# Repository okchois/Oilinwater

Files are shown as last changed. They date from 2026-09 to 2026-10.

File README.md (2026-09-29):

# Oilinwater — 오일 내 수분 트랜스미터

오일(유압유·윤활유·절연유·연료) 속 수분을 온라인으로 측정하는 트랜스미터 개발 프로젝트.

**프로젝트: HMT500(260313)** — 회로·PCB·거버 파일명과 PCB 마킹은 **HMT500(260313A)** (결정 #25).

- [결정 기록](docs/decision-log.md) — 확정 사항과 미결 사항 (MCU, DAC 대체 계획 등)
- [조사 보고서](docs/research-report.md) — 측정 원리, 경쟁 제품, 센서 소자, 회로/기구/펌웨어 설계, 교정, 인증, 로드맵
- [시장 조사 종합](docs/market/00-summary.md) — 세계 시장, 경쟁 제품·가격, 국내 시장, 포지셔닝 제안
- [E+E EE364 원문 요약](docs/reference/ee364-summary.md) — 구조 참고 제품의 치수, 사양, 핀맵, Modbus 맵
- [IST MK33 스터디](docs/reference/ist-mk33-study.md) — 데이터시트·응용노트·백서: 이슬점 95 °C 한계, 온도 보정식, DC 없는 교류 구동, 취급·교정 지침
- [HMT500(260313) 기구 설계 Rev F](hardware/mech/README.md) — 제작 도면 PDF(조립도·부품도 4장), 3D STEP, 렌더 (두텍 SUS 오일 필터 캡 390000-001100 + HTX99R 센서 커넥터 + 교체형 센서 프로브, 피드스루 없이 Ø7 관통 + JST SH 하네스, 나사 M28×1 + O링, PCB 1장)
- [HMT500 기구설계 견적 요청서 (PDF)](docs/mech/HMT500_RFQ.pdf) · [도면 HMT500-M-000](docs/mech/HMT500-M-000.pdf)
- [기구 설계안](docs/mech/mechanical-design.md) — EE364형 일체형 구조도, 압력 격벽, 밀봉, 열, 원가
- [KiCad 회로도 HMT500(260313A)](hardware/kicad/README.md) — 계층 시트 6장, 심볼 라이브러리, BOM, PDF
- [회로도 검토 HMT500(260313A)](docs/hw/schematic-review-260313A.md) — 심볼·데이터시트 대조, 최적화 계획 (승인 대기)
- [회로 설계서 (서지·오결선 보호)](docs/hw/circuit-design.md) — 전원 eFuse, 출력 보호, RS-485 ±70 V, 접지, MCU 핀 할당
- [하드웨어 블록 설계](docs/hw/hardware-block-design.md) — 회로 블록도, 부품 선정, 아날로그 2ch + RS-485
- [MCU 선정 검토](docs/hw/mcu-selection.md) — STM32L431 재검토, 후보 비교, 교차 검토 질문지
- [사내 사용 부품 적용 검토](docs/hw/inhouse-parts.md) — MCU·DAC 구매 이력, DAC8760 → DAC7562 + 출력단 비교
- [습도 센서 선정](docs/hw/humidity-sensor-selection.md) — IST MK33-W mini 선정, P14·HYT 계열 비교
- [온도 센서 선정](docs/hw/temperature-sensor-selection.md) — IST MiniSens Pt1000 F0.1 선정, 2선식 검토
- [RS-485 + 부트로더 설계](docs/rs485-bootloader-design.md) — 기본 출력 RS-485 Modbus RTU, 통신으로 펌웨어 업데이트
- [`firmware/`](firmware/) — MCU 비의존 부트로더 코어 + PC 시뮬레이터
- [`tools/fwupdate.py`](tools/fwupdate.py) — 펌웨어 이미지 생성 및 RS-485 업데이트 도구
- [`tools/moisture_calc.py`](tools/moisture_calc.py) — 수분 활동도(aw) ↔ ppm 환산 참조 구현

```bash
python3 tools/moisture_calc.py --temp 20 --aw 0.5     # aw -> ppm
python3 tools/moisture_calc.py --temp 60 --ppm 20     # ppm -> aw
```

```bash
make -C firmware                               # 부트로더 시뮬레이터 빌드
python3 -m unittest discover -s tests          # 통합 테스트
python3 tools/fwupdate.py mkimage app.bin app.oiw --hw-id 1 --version 1.0.0
python3 tools/fwupdate.py flash app.oiw --port /dev/ttyUSB0 --addr 1   # pyserial 필요
```

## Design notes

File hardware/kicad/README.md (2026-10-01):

# HMT500(260313A) KiCad 회로도 v0.8

DOTECH HMT500(260313) 오일 수분 트랜스미터의 KiCad 회로도입니다.

**파일명·프로젝트 번호 = HMT500(260313A)** (결정 #25): 회로도·심볼·BOM·부품리스트·PDF, PCB 파일, 거버(`HMT500(260313A)-F_Cu.gtl` 등, 묶음 `HMT500(260313A).zip`), PCB 실크 마킹(아랫면 가운데) 모두 같은 이름을 씁니다. 거버 출력: `sh hardware/kicad/export_gerbers.sh`.

**v0.8 (결정 #26):** 모든 IC 핀을 제조사 데이터시트 원문으로 대조하고 반영했습니다 — [검토 문서](../../docs/hw/schematic-review-260313A.md).

설계 내용은 [회로 설계서](../../docs/hw/circuit-design.md)를 따릅니다.

| 파일 | 내용 |
|---|---|
| `HMT500(260313A)/HMT500(260313A).kicad_pro` | 프로젝트 (KiCad 7 형식 — KiCad 8/9에서 열면 자동 변환) |
| `HMT500(260313A)/HMT500(260313A).kicad_sch` | 최상위 시트 (하위 시트 6장) |
| `HMT500(260313A)/HMT500(260313A)_connector.kicad_sch` | 커넥터, 입력 서지 보호(TVS 2단, CM 초크), 하우징 접지(1 MΩ, 4.7 nF, GDT) |
| `HMT500(260313A)/HMT500(260313A)_power.kicad_sch` | eFuse TPS2660 (RTN은 GND와 분리, OVP 32.6 V / 복귀 30.1 V → 전원 12–28 V, v0.9), 벅 LMR36006BRNXR(5 V, L 15 µH·CFF 20 pF), LDO TPS7A2033(3.3 V) (v0.8) |
| `HMT500(260313A)/HMT500(260313A)_mcu.kicad_sch` | STM32G0B1CCT3 (LQFP48, −40~125 °C), SWD(TC2030), 리셋, 내부 온도센서. SPI1 = ADS1220, SPI2 = DAC(모드 3), SPI3 = PCAP04 (v0.8) |
| `HMT500(260313A)/HMT500(260313A)_measurement.kicad_sch` | J3 센서 하네스 커넥터(JST SH 1.0 4핀), PCAP04(QFN24 실제 핀, DC 없는 플로팅 모드) + 기준 C, ADS1220(Pt1000 2선) |
| `HMT500(260313A)/HMT500(260313A)_analog_out.kicad_sch` | DAC8760 ×2 (SCLK 게이트 U14, AVDD 10 Ω, ALARM wired-OR) + OPA197 +VSENSE 버퍼 + 외부 ISET-R + TPS26611DDFR 오결선 보호 + TVS3301 (v0.8) |
| `HMT500(260313A)/HMT500(260313A)_rs485.kicad_sch` | THVD2410 (±70 V), DE 10 k 풀다운 (v0.9) |
| `HMT500(260313A)/HMT500(260313A)_aux.kicad_sch` | v0.9 보조: TPS26611 +Vs 27 V 클램프, VIN 전압 감시, PCB에 넣지 못한 선택 사항 메모 |
| `HMT500(260313A)/HMT500(260313A).kicad_sym`, `sym-lib-table` | 프로젝트 심볼 라이브러리 |
| `HMT500(260313A)/HMT500(260313A)_BOM.csv` | 부품표 (값·풋프린트별 묶음) |
| `HMT500(260313A)/HMT500(260313A)_schematic.pdf` | 회로도 PDF (7쪽) |
| `HMT500(260313A)/HMT500(260313A)_parts_list.xlsx`, `.csv` | **구매용 부품리스트**: 회로도 부품 + 제조사·품번·1k 추정 단가·상태, 분류별 요약(환율 입력 시 원화 자동 계산). `make_parts_list.py`로 생성 |
| `HMT500(260313A)/HMT500(260313A).kicad_pcb` | 보드 외곽(57 × 23, 4층), 고정 구멍 2개, 금지 구역(홀더 홈·지지링 홈), **회로도 v0.9 부품 110개 배치·넷 지정 완료 (배선 전, 승인 대기)**. 설계 규칙: 간격·선폭 0.15, 비아 0.45/0.2, 가장자리 0.3, 넷클래스 CHASSIS 간격 1.0·선폭 0.5, J5 둘레 3.3 mm 부품 금지 |
| `HMT500(260313A)/placement.png`, `placement.json` | 배치 그림(윗면/아랫면, 색 = 기능 블록, 숫자 = 부품 높이)과 배치 표(기구 좌표) — 조립 시뮬레이션 입력 |
| `gen_pcb_outline.py` | 외곽·금지 구역 생성기. 치수는 `hardware/mech/hmt500_params.py`에서 읽습니다 |
| `place_pcb.py` | 부품 배치 (pcbnew). 고정 부품 + 큰 부품 자리표 + 작은 부품은 부모 패드 옆 빈 자리 탐색. 보드·금지 구역·하네스 플러그 통로·높이(보어) 조건 검사. `python3 place_pcb.py` |
| `plot_placement.py` | 배치 그림 (matplotlib) |
| `gen_footprints.py`, `lib/HMT500_260313A.pretty` | 프로젝트 풋프린트 (KiCad 7.0.11 복사본 + 자체 3종) |

## 도면 스타일 (v0.2)

- **흐름:** 신호는 왼쪽(입력) → 오른쪽(출력)으로 그리고, 전원은 위쪽 전원 심볼, GND는 아래쪽 GND 심볼로 표시합니다.
- **연결:** 시트 안은 실제 배선이고, 3선 이상 만나는 곳에는 접합점을 찍었습니다. 시트 사이 신호(SPI, 고장 신호, 커넥터 신호 등)만 전역 라벨로 잇습니다.
- **전원 심볼:** GND, +3V3, +3V3A(아날로그 3.3 V), +5V, VIN_P(보호된 입력), CHASSIS
- **구획:** 기능 블록마다 점선 구획, 제목, 설계 메모(설정 공식, 확인 항목)를 넣었습니다.
- **용지:** 커넥터·RS-485 시트는 A4, 나머지는 A3입니다.

## 생성과 검증

회로도는 `gen_hmt500.py`가 생성합니다. 각 부품에 설계 의도 넷(`nets=`)을 적고 배선은 좌표로 그립니다.
- **생성 단계 검사:** 선 중간에 걸친 핀, 연결 안 된 핀, 용지 밖, 표제란 침범이 있으면 생성이 멈춥니다.
- **연결 검사:** `check_netlist.py`가 KiCad 넷리스트와 설계 의도를 핀 단위로 대조합니다. 현재 74넷, 오류 0입니다.
- **자동 테스트:** `tests/test_kicad_gen.py`에 포함되어 있고, kicad-cli가 있으면 넷리스트 대조까지 수행합니다.

```bash
python3 hardware/kicad/gen_hmt500.py                     # 회로도·라이브러리·BOM 생성
kicad-cli sch export netlist -o hmt500.net hardware/kicad/HMT500(260313A)/HMT500(260313A).kicad_sch
python3 hardware/kicad/check_netlist.py hmt500.net       # 넷리스트 = 설계 의도 검사 (현재 74넷, 오류 0)
kicad-cli sch export pdf -o hardware/kicad/HMT500(260313A)/HMT500(260313A)_schematic.pdf hardware/kicad/HMT500(260313A)/HMT500(260313A).kicad_sch
```

KiCad 8 이상에서는 `kicad-cli sch erc`로 ERC도 실행할 수 있습니다(KiCad 7 CLI에는 ERC가 없음).

## 현재 상태와 주의 사항

- **편집 원본:** 스크립트로 다시 생성하면 KiCad에서 손으로 고친 내용이 덮어써집니다. **KiCad에서 편집을 시작하면 그 뒤로는 KiCad 파일을 원본으로 삼으십시오.**
- **핀 번호 확인 필요 (VERIFY=YES):** TPS2660, LMR36006, PCAP04, DAC8760, TPS26611.
  - 이 환경에서 제조사 데이터시트 사이트가 막혀 있어 **핀 번호를 가번호로** 넣었습니다. 핀 이름과 연결(넷)은 설계서대로입니다.
  - 데이터시트를 보고 심볼 핀 번호만 고치면 됩니다.
  - 확인한 부품: STM32G0B1CCT3(LQFP48, KiCad 공식 심볼 STM32G0B1C_B-C-E_Tx 기준), ADS1220(TSSOP-16), THVD2450(SOIC-8), TPS7A2033(SOT-23-5). 이 넷도 데이터시트로 한 번 더 대조하십시오.
- **풋프린트 TBD:** 공통모드 초크, GDT, 벅 인덕터, 가번호 IC 5종. (J3 `Connector_JST:JST_SH_SM04B-SRSS-TB_1x04-1MP_P1.00mm_Horizontal`, J1 `Connector_JST:JST_GH_SM08B-GHS-TB_1x08-1MP_P1.25mm_Horizontal`은 KiCad 표준. J5 샤시 스프링 접점 TBD)
- **확인할 회로 사항:**
  - DAC8760 VOUT/IOUT 결합과 DVDD-EN 극성
  - TPS26611 전압 모드 통과 여부
  - TPS2660 분압 기준전압(1.2 V 가정: UVLO 약 9 V, OVP 약 33 V)과 ILIM 저항값
  - LMR36006 FB 기준전압(1.0 V 가정 → 5.0 V)
  - PCAP04 플로팅 측정 결선(PC0–PC1 기준 C, PC2–PC3 센서)

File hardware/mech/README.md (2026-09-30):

# HMT500(260313) 기구 설계 (Rev H)

**Rev H (2026-09-30, 결정 #30) — 외형을 E+E EE364와 부위별로 같게:** 노출 프로브 Ø12 × **34** (보호캡 끝 쪽 5.5 연장, 옆 구멍 1줄 추가 → 25개), G½ 14, 육각 AF27 × **10**, 몸통 **Ø30**, 씰면 ~ 엔드캡 끝 **77**, M12 15, 전장 **140**.
- 하우징 Ø30/Ø25, 결합 나사 **M26×1** (앞 오른나사, 뒤 왼나사), O링 자리 Ø27, O링 **24 × 1.5** FKM. 엔드캡 플랜지 4 mm, 맞변 AF27 (바디 육각과 같은 스패너), M16×1.5 커넥터 나사는 x 71–77.
- 안쪽(홀더·PCB·링·하네스)은 모양 그대로 x −2. PCB 폭·길이·부품 배치 변경 없음 (KiCad 좌표 동일). 가장 좁은 곳(하우징 나사 골 Ø24.9)에서도 부품 높이 여유 ≥ 0.5.
- 지지링 바깥 Ø24.5 (홈 바깥 벽 0.65). **M12 커넥터 선정 조건: 앞 나사부 ≤ 6 mm** (PCB 뒤 끝과 틈 2).
- 조립 시뮬레이션 23항목 NG 0. 조립 시방서 `out/assembly_procedure/HMT500-A-001_assembly_procedure.pdf` (`python assembly_procedure.py`, 19단계 3D 그림).
- 금속 가공품 합계 약 242 g (바디 96, 캡 16, 하우징 98, 엔드캡 33).

**Rev G 보호캡 보호 (2026-09-30, 결정 #29):** 바디 앞 Ø14 튜브를 없애고, 앞부분 전체(커넥터·캡·프로브)를 뒤로 19.5 mm 옮겼습니다. 보호캡 뿌리 **3.5 mm가 G½ 앞면의 Ø12.3 자리 안**에 들어가, 캡이 상하좌우로 젖혀지면서 HTX99R 플라스틱 커넥터가 깨지는 것을 막습니다(틈 0.15, 벽 ≥ 3 mm). 전장 158 → **138.5 mm**, 노출 프로브 48 → **28.5 mm**, Ø7 통로 14.5 mm, W-1 40 mm. 아래 Rev F의 48 / 158 mm는 이전 값입니다.

**Rev G (2026-09-30, 결정 #27) — 조립 시뮬레이션 반영:** 홀더(M-105)에 W-1 플러그 창 5.6 × 3.2와 링 단자 자리 Ø5.2 × 2.2를 냈습니다. PCB 폭 23 구간은 x 63.4에서 끝납니다. 샤시는 J5 스프링 접점 대신 **샤시 선 ⑳**(AWG 28 25 mm + M2 링 단자 → 홀더 위 축 나사 → 바디)으로 연결합니다. W-2는 40 mm로 줄였고, 조립 공구 **T-001 밀대**(`out/HMT500-T-001_push_tool.step`, 3D 프린트)를 추가했습니다. 조립 순서는 조립도 주기 5이며, 검증은 `python assembly_sim.py`로 합니다(`out/assembly_sim/`, 23항목 NG 0).

**내부 몰딩·턴버클 (2026-09-29, 결정 #20):**
- 하우징 안 **전체**(바디 Ø22 + 하우징 Ø27 + 엔드캡 Ø22, 약 25 cm³)를 **상온경화 에폭시 1종**으로 몰딩합니다. Ø7 통로 1차 몰딩과 같은 재료입니다.
  - 엔드캡에 M3 구멍 2개(90°·270°)를 두어 한쪽으로 진공 주입하고, 다른 쪽으로 공기를 뺍니다. 경화 후 M3×3 무두나사와 실런트로 막습니다.
  - 몰딩 후에는 전자부를 고칠 수 없습니다. SWD 기록, 기능 검사, 1차 교정은 몰딩 전에 하고, 최종 교정은 몰딩 경화 뒤에 합니다.
- 엔드캡 나사를 **M28×1 왼나사**로 바꿔 **턴버클**로 체결합니다. 바디(AF27)와 엔드캡(AF28)을 잡고 하우징만 돌리면 양쪽이 동시에 당겨지므로, PCB·M12·하네스가 돌지 않습니다.
- J3를 홀더 뒤 12.5 mm(x 30.5–34.5)로 옮겨 플러그를 꽂을 공간을 만들었습니다. PCAP04와 ADS1220도 옮겼습니다.
- 조립 순서는 조립도 주기 5에 있습니다.

**Rev F (2026-09-29, 결정 #17):** 앞쪽 보호캡을 두텍 필터로 바꾸고 피드스루를 없앴습니다.
- **필터 캡 ②:** 두텍 기존품 **SUS PROBE 오일 필터 390000-001100** (`ref/SUS_PROBE_Oil_Filter_20200608.dwg`, SUS304)입니다.
  - Ø12 × 32, 끝 C1, 열린 끝 Ø11 × 1입니다.
  - **M10×1.0 암나사(깊이 8.5)** 로 HTX99R 커넥터 위 나사에 체결합니다. 열린 끝이 커넥터 플랜지 앞면을 눌러 줍니다.
  - 센서실 Ø8입니다. 측면 Ø3 구멍 20개(끝에서 6·11·16·21 mm, 줄마다 5개 72°)와 끝단 Ø3 구멍이 있습니다.
  - 센서 프로브 플러그는 Ø8.5 → **Ø7.6**으로 줄였습니다.
  - 노출 프로브는 34 → **48 mm**, 전장은 144 → **158 mm**입니다.
- **피드스루 삭제:** 커넥터 뒤부터 PCB까지는 **Ø7 관통 통로**이고 센서 하네스 W-1만 지나갑니다.
  - 통로는 pass-through(케이블만)이고, 케이블을 넣은 뒤 **전 길이(Ø7 × 34)를 에폭시로 몰딩(⑤, 1차 격벽)** 합니다.
  - 압력 격벽은 **HTX99R O링 + 몰드 핀 + 에폭시 몰딩**입니다. HTX99R 내압·누설과 에폭시 재료 확인이 필요합니다(미결).
- **센서 하네스 W-1 (결정 #16):** HTX99R 뒤 핀 4개 → **JST SH 1.0 mm 4핀 플러그 → PCB J3 (SM04B-SRSS-TB, 옆 삽입·직각, 입구 앞쪽)**. PTFE AWG30, 60 mm입니다.
  - J3는 PCB 윗면, 앞 끝에서 8 mm 뒤(x 22.5–26.5)에 있는 **옆 삽입(직각) 헤더**입니다. 입구가 앞쪽(센서 쪽)이라 홀더 구멍에서 나온 전선이 굽힘 없이 곧게 플러그로 들어갑니다. 높이 2.95이고, PCAP04는 J3 바로 뒤입니다.
  - 조립 순서는 다음과 같습니다.
    1. W-1 전선을 커넥터 뒤 핀에 납땜하고 O링을 끼웁니다.
    2. 플러그를 바디 앞에서 Ø7 통로로 넣어 뒤로 뺍니다.
    3. 커넥터를 체결합니다. 플러그가 자유로워 하네스가 같이 돌므로 꼬이지 않습니다.
    4. 프로브를 아래로 세우고 뒤에서 에폭시를 주입해 Ø7 통로를 채우고 경화합니다.
    5. 플러그를 홀더 Ø6 구멍에 통과시키고 홀더를 체결합니다.
    6. PCB를 장착하고 플러그를 J3에 꽂습니다.
  - JST SH의 정격은 −25 ~ +85 °C이므로 PCB 앞 끝 온도를 시험으로 확인해야 합니다(미결).
- **M12 하네스 W-2 (결정 #18):** M12 8핀 커넥터도 **JST GH 1.25 mm 8핀 옆 삽입(직각) 헤더 J1 (SM08B-GHS-TB)** 에 하네스로 연결합니다.
  - J1은 PCB 윗면, 뒤 끝에서 12.5 mm 앞(x 52.5–58.5)에 있고 입구가 뒤쪽(커넥터 쪽)입니다.
  - 플러그 GHR-08V-S, PTFE AWG28 60 mm, 핀 n = M12 핀 n입니다.
  - 조립: 엔드캡을 빈 상태로 체결 → W-2(M12 핀에 미리 납땜) 플러그를 엔드캡 M16 구멍으로 넣어 축 방향으로 J1에 꽂음 → M12 체결. 체결 회전(약 4바퀴)만큼 미리 반대로 꼬아 둡니다(미결: 회전 없는 고정형 검토).
  - M12 쉘로 잇던 샤시는 **J5 스프링 접점**(PCB 가장자리 → 하우징 내면)으로 바꿨습니다.
  - 출력부 배치: DAC#1은 뒤 끝(x 67.5)으로, 입력 TVS는 MCU 옆(x 48.5)으로, TPS26611은 아랫면으로 옮겼습니다.
- **나사 규격 (Rev G 확정):** HTX99R 위·아래 나사는 모두 **M10×1.0**입니다(두텍 확인). 바디 암나사는 M10×1.0-6H, 필터 캡은 M10×1.0입니다.

아래 Rev E 이전 설명 중 피드스루, 보호캡 M-102(자체 가공품), 22 mm 하네스에 관한 내용은 Rev F에서 바뀌었습니다.

DOTECH HMT500 오일 수분 트랜스미터의 3D CAD와 2D 제작 도면입니다. 모든 치수는 `hmt500_params.py` 한 곳에서 관리하고, 여기서 3D 모델과 도면을 함께 생성합니다.

**Rev E (2026-09-29):** 두텍 확인 결과, HTX99R 커넥터의 Ø10 두 곳은 **M10×0.75 나사**입니다(아래는 하우징 체결, 위는 보호캡 체결). 이에 맞춰 다음을 바꿨습니다.
- **커넥터 체결:** 바디 앞 **M10×0.75-6H 암나사**(깊이 8)에 돌려 박습니다. 맞변 7로 잡고 조입니다.
  - O링(8 × 1.2)은 나사와 플랜지 사이 홈에서 Ø10 H8 밀봉면(길이 1.5)에 닿습니다.
  - 플랜지는 Ø11.2 × 1 자리에 앉습니다.
- **보호캡:** 커넥터 **위 나사 M10×0.75**에 체결합니다. 캡 외경은 **Ø12**로 돌아왔습니다(EE364와 같음). 바디 앞 튜브는 플랜지 자리 때문에 **Ø14**입니다.
- **배선 꼬임 방지:** 커넥터를 돌려 박으면 뒤쪽 배선도 같이 돕니다. 그래서 순서를 다음과 같이 잡았습니다.
  1. 커넥터 핀에 선 4가닥을 먼저 납땜하고 포팅합니다.
  2. 선 끝이 자유로운 상태에서 커넥터를 체결합니다. 선은 Ø7 통로로 뒤쪽까지 나옵니다.
  3. 뒤쪽에서 피드스루에 납땜합니다.
- **피드스루 위치:** 피드스루는 **바디 뒤쪽 Ø22 카운터보어 바닥의 Ø8 H7 자리**로 옮겼습니다. 뒤에서 넣고 뒤에서 레이저 용접하므로 접근이 쉽습니다.

**Rev D (2026-09-29):** 센서 접속을 두텍 기존 부품 **HTX99R 센서 커넥터**(4핀, `ref/` STEP)로 바꿨습니다.
- 교체형 **센서 프로브**(IST MK33-W mini + Pt1000 MiniSens, 4핀)를 커넥터 소켓에 꽂고, 보호캡을 씌웁니다.
- **커넥터 고정:** 커넥터는 바디 앞 **Ø10 H8 구멍**에 O링(8 × 1.2 FKM, 커넥터 홈 Ø8.2, 압축률 25 %)으로 밀봉합니다.
  - 플랜지 Ø11은 바디 턱(Ø11.2 × 1)에 걸려 오일 압력을 받습니다.
  - 보호캡 안쪽 턱(Ø10.2)이 플랜지 앞면을 눌러 빠지지 않게 잡습니다.
- **압력 격벽:** 커넥터 뒤 핀은 납땜·포팅 공간(Ø9 × 6)에서 피드스루(Ø8 H7, 압력 격벽)와 짧은 선으로 잇습니다. 커넥터 O링이 1차 밀봉이고, 피드스루가 최종 압력 격벽입니다.
- **치수 변경:** 커넥터 플랜지 Ø11 때문에 **노출 프로브와 보호캡을 Ø12 → Ø16**으로 키웠습니다.
  - 노출 길이 34, G1/2, 전장 144는 그대로입니다.
  - 캡 나사는 M10×0.75 → M14×1입니다.
  - G1/2 설치 구멍(골지름 18.6)은 통과하지만, EE364의 Ø12 프로브와는 외경이 다릅니다.

**Rev C (2026-09-26):** 전자부를 원형 PCB 2장에서 **축 방향 긴 PCB 1장(57 × 23, 4층)** 으로 바꿨습니다.
- PCB는 축을 지나는 평면에 세웁니다. 앞 끝은 수지 홀더(M-105)의 홈에 끼우고 M2 나사 2개로 고정합니다. 홀더는 바디 카운터보어 바닥에 M2 나사 2개로 고정합니다.
- 뒤쪽은 수지 지지링(M-106)의 홈이 받쳐 줍니다. 지지링은 엔드캡과 연결하지 않으므로 하우징·엔드캡을 돌려 체결해도 PCB가 같이 돌지 않습니다.
- 배치는 앞쪽 측정부 → 가운데 MCU·전원 → 뒤쪽 출력·보호 순입니다. 보드 간 커넥터가 없습니다.
- PCB 외곽, 금지 구역, 부품 높이 한계는 도면 4쪽과 KiCad 보드 파일(`hardware/kicad/HMT500(260313A)/HMT500(260313A).kicad_pcb`)에 같은 값으로 들어 있습니다.

**Rev B (2026-09-26):** 바디–하우징, 하우징–엔드캡 결합을 레이저 용접에서 **M28×1 나사 + 반경 O링(25×2 FKM)** 으로 바꿨습니다.
- 나사와 O링 자리의 벽 두께를 확보하려고 하우징 외경을 Ø30에서 **Ø32**로 키웠습니다.
- 용접은 피드스루 한 곳만 남아서 분해와 수리가 가능합니다.
- 커넥터는 엔드캡을 체결한 뒤 바깥에서 끼우는 전면 장착형입니다. 그래서 엔드캡을 돌려 체결해도 리드선이 꼬이지 않습니다.

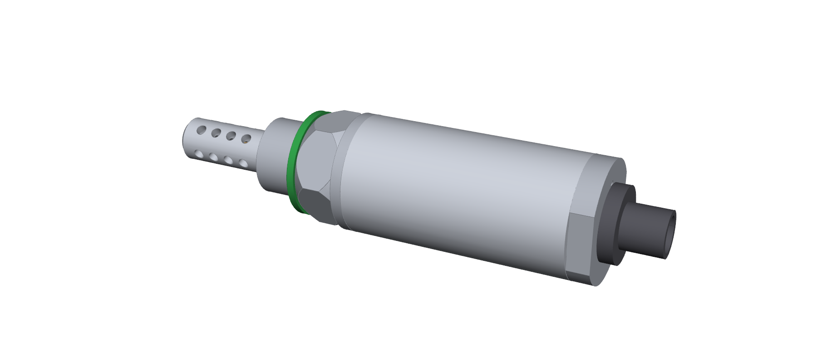
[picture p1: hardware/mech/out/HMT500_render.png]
HMT500 렌더

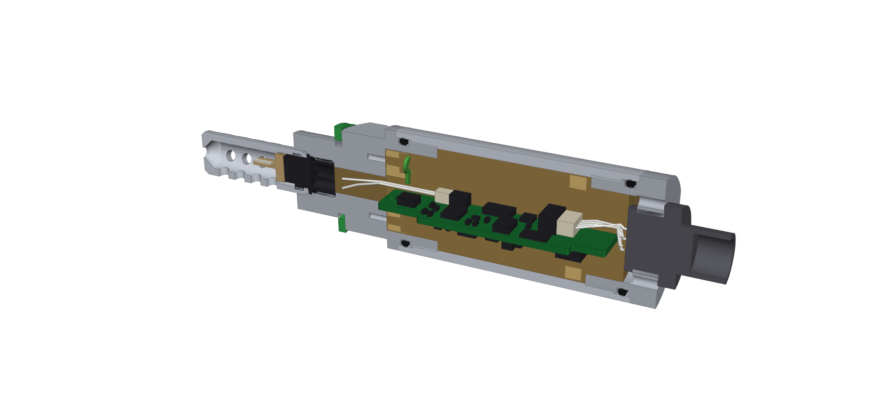
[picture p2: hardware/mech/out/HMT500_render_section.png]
HMT500 단면 렌더


## 제품 시안 (스튜디오 렌더)

`render_studio.py` → `out/studio/HMT500_studio_01~06.png` (외관 시안: 레이저 마킹 문안·커넥터 외형은 가안)

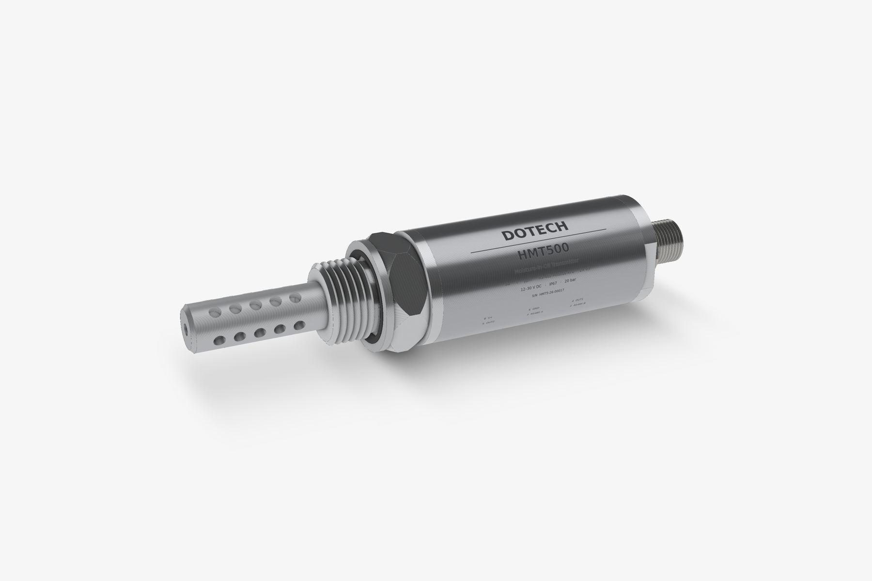
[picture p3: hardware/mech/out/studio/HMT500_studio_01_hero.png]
시안


## 센서 커넥터 HTX99R-SC (두텍 기존 부품)

센서 프로브를 꽂는 커넥터(두텍 HTX99R 모델)의 2D 도면입니다. 원본 STEP은 `ref/HTX99R_Sensor_Probe_Sensor_Connector.STEP`이고, `htx99r_connector_drawing.py`가 모델에서 은선 처리로 투영해 `out/HTX99R-SC_sensor_connector.pdf`를 만듭니다. 도면은 A3 한 장, 5:1이며 정면도·단면 A–A·윗면도·아랫면도·등각도로 되어 있습니다.

- **몸체:** Ø10 × 15, 플랜지 Ø11 × 1, 홈 2개 (Ø8.2 × 1.5, Ø8.1 × 1.5), 양 끝 C0.5.
- **윗면:** 맞변 7 평면 (길이 3). 센서 핀 소켓은 4× Ø1.5, 깊이 7.9, 2.54 격자입니다.
- **아랫면:** Ø7 × 7 오목부가 있고, PCB 핀 4× □0.64가 2.54 격자로 3 mm 돌출합니다.
- **확인 필요:** 재질·공차는 STEP에 없어서 원 도면이나 공급사 사양으로 확인해야 합니다.

## 산출물 (`out/`)

| 파일 | 내용 |
|---|---|
| `HMT500_mechanical_drawings.pdf` | **제작 도면 4장 (A3)**: 조립도 M-000(부품표·주기), 바디 M-101, 보호캡·하우징·엔드캡 M-102~104, PCB 홀더·지지링·PCB 외곽 M-105~106 |
| `HMT500-M-000_assembly.svg` 등 | 도면 원본 SVG |
| `HMT500_assembly.step` | 3D 조립품 (구매품 단순 형상 포함, 색 구분) |
| `HMT500-M-101_body.step` ~ `M-106_ring.step` | 가공 부품별 3D (가공 업체 견적용) |
| `HMT500_render*.png` | 외관 / 절단 렌더 |

## 주요 치수

| 항목 | 값 |
|---|---|
| 전장 | **140 mm** (프로브 끝 ~ 커넥터 끝, Rev H = EE364) |
| 노출 프로브 / 공정 나사 | **34 mm**, 보호캡 **Ø12**만 노출 (캡 뿌리 3.5 mm는 G½ 앞면 Ø12.3 자리 안) / G1/2-A ISO 228-1, 14 mm |
| 육각 / 하우징 | AF27 × 10 / Ø30 × 60 (양끝 M26×1-6H, 뒤 LH, Ø27 H8 O링 보어) |
| 씰면 기준 | 엔드캡 끝 77 mm, 커넥터 끝 92 mm |
| 가공품 질량 (316L) | 바디 96 g, 캡 16 g, 하우징 98 g, 엔드캡 33 g (합계 약 242 g, 전자부·커넥터 제외) |
| 결합부 O링 | 24 × 1.5 FKM 75, 2개. 압축률 20 %, 늘림 2.5 % (Ø27 H8 / 홈 Ø24.6 h9 × 2.1) |

## 구조 요약

1. **바디(M-101):** G½ 앞면의 보호캡 자리 Ø12.3 × 3.5, 센서 커넥터 자리(Ø11.2 / Ø10 H8 / M10×1.0-6H), Ø7 배선 통로, G1/2 나사, 언더컷, 육각 AF27, Ø32 칼라, Ø29 f7 O링 자리, M28×1 수나사까지 한 덩어리로 선삭합니다.
   - Ø7 통로(길이 14.5)는 Ø22 카운터보어까지 관통합니다(Rev F, 피드스루 없음). 센서 하네스만 지나가고, 전 길이를 에폭시로 몰딩합니다(1차 격벽).
2. **보호캡(M-102):** 나사 결합 교체형이며, 측면 Ø2.6 구멍 8개와 끝단 Ø3 구멍이 있습니다.
3. **하우징(M-103):** Ø32/Ø27 튜브이고, 양 끝에 Ø29 H8 O링 보어(깊이 4)와 M28×1-6H 암나사(길이 7)가 있습니다.
   - 바디와 엔드캡을 나사로 체결하고, 중강도 나사 고정제를 씁니다. 토크는 5 N·m로 잡았으며 확정이 필요합니다.
   - 체결할 때는 바디 육각 AF27과 엔드캡 평면 AF28을 잡고 돌립니다.
4. **엔드캡(M-104):** M28×1 수나사, O링 자리, 평면 AF28 플랜지로 되어 있습니다. M Connect 8핀 커넥터는 플랜지의 M16×1.5 구멍에 **바깥에서** 체결합니다.
5. **전자부(E-301):** 57 × 23 PCB 1장입니다. 폭은 바디·엔드캡 안(Ø22)에서 18, 하우징 안(Ø27)에서 23입니다.
   - 한 면의 부품 높이 한계(여유 0.5 포함)는 가장자리 5.0~5.8 mm, 중심 9.7~12.2 mm입니다.
   - HTX99R 뒤 핀 4개에서 하네스 W-1(JST SH 1.0 mm 4핀, 60 mm)을 앞쪽 J3에, M12 커넥터 8핀에서 하네스 W-2(JST GH 1.25 mm 8핀, 60 mm)를 뒤쪽 J1에 꽂습니다.
6. **PCB 홀더(M-105)와 지지링(M-106):** PEEK(또는 PA66-GF30)입니다. 홀더는 Ø21.6 × 5.8이고 Ø6 하네스 구멍과 1.7 홈이 있습니다. 지지링은 Ø26.4 / Ø20 × 4이고 홈 2곳이 있습니다.

## 다시 만들기

```bash
python3 hardware/mech/hmt500_drawings.py && hardware/mech/make_pdf.sh   # 2D 도면 (추가 설치 불필요)
pip install cadquery                                                    # 3D는 CadQuery 필요
python hardware/mech/hmt500_cad.py                                      # STEP
python hardware/mech/render3d.py                                        # 렌더 (OSMesa/EGL 필요)
```

## 확인·확정이 필요한 항목

- **압력 격벽 (Rev F):** 피드스루가 없으므로 HTX99R 커넥터(몰드 핀·O링)와 에폭시 몰딩의 내압·누설·내열을 확인해야 합니다.
- **커넥터:** M Connect 품번(장착 나사 M16×1.5 가정, 돌출 길이, O링)을 확정해야 합니다.
  - 리드가 달린 커넥터를 돌려 체결하면 리드가 약 4바퀴 꼬입니다(M16×1.5, 나사 6 mm). 리드를 반대로 미리 꼬아 두거나, 뒤쪽 너트 고정형 품번을 고르는 방안을 검토해야 합니다.
- **센서 프로브 (Rev D):** HTX99R용 센서 프로브의 STEP(핀 규격·플러그 형상)을 받아 반영해야 합니다. 지금은 Ø1.0 핀 4개와 PEEK 플러그를 가정했습니다.
- **HTX99R 커넥터:** 재질·내열(120 °C)·내유성, 몰드 핀 주위 누설, 체결 토크를 확인해야 합니다. 나사는 위·아래 모두 M10×1.0 (두텍 확인 2026-09-30).
- **체결 토크:** 보호캡 체결 토크, M28×1 결합 토크(5 N·m 가정), G1/2 설치 토크(본디드 씰 규격)를 정해야 합니다.
- **내압 검증:** 200 bar형의 내압 검토(FEA)가 필요하고, 지금 도면은 50 bar 정격 기준입니다.
- **나사 표현:** 3D의 나사는 원통으로만 표현했습니다. 나사 규격은 2D 도면의 표기를 따릅니다.

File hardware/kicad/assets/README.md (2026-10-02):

# DOTECH 전체 실크 로고

사용자 작업 폴더 `Claude/OILWATCH/docs/assets/dotech_logo_navy.png`에서 가져온 두텍 원본.
DOTECH와 SENSING & CONTROL 부제를 함께 사용한다.
`generate_dotech_wordmark.py`는 전체 알파 윤곽을 추출한다(Pillow, numpy, shapely 2.1).
`dotech_wordmark.json`의 외곽/구멍을 KiCad 네이티브 채움 다각형으로 변환하고, `DOTECH full logo` 그룹으로 묶는다. KiCad에서 그룹 이동, 그룹 해제 후 도형 편집이 가능하다. PNG를 PCB에 붙인 것이 아니다.

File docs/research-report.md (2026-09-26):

# 오일 내 수분(Moisture-in-Oil) 트랜스미터 개발 조사 보고서

작성일: 2026-09-26 · 상태: 초기 조사(Discovery)

> 이 문서는 온라인(인라인) 방식의 오일 내 수분 트랜스미터를 개발하기 위해 필요한 기술·시장·규격·설계 정보를 정리한 것입니다.
> 경쟁사 사양은 공개 데이터시트/유통사 페이지 기준이며, 설계 확정 전 최신 데이터시트로 다시 확인해야 합니다.

---

## 목차

1. [요약](#1-요약)
2. [기본 개념: 오일 속 물은 어떤 상태로 존재하나](#2-기본-개념)
3. [적용 시장과 요구 사양](#3-적용-시장과-요구-사양)
4. [측정 원리 비교](#4-측정-원리-비교)
5. [핵심 계산: aw ↔ ppm 환산](#5-핵심-계산-aw--ppm-환산)
6. [경쟁 제품 벤치마크](#6-경쟁-제품-벤치마크)
7. [센서 소자(OEM 부품) 후보](#7-센서-소자-후보)
8. [하드웨어 아키텍처](#8-하드웨어-아키텍처)
9. [기구(프로브) 설계](#9-기구프로브-설계)
10. [펌웨어/알고리즘](#10-펌웨어알고리즘)
11. [교정 및 시험 방법](#11-교정-및-시험-방법)
12. [인증 및 규격](#12-인증-및-규격)
13. [목표 사양(안)](#13-목표-사양안)
14. [개발 로드맵·예산 규모](#14-개발-로드맵예산-규모)
15. [리스크와 대응](#15-리스크와-대응)
16. [차별화 기회](#16-차별화-기회)
17. [참고 자료](#17-참고-자료)

---

## 1. 요약

- **업계 표준 방식은 "박막 고분자 정전용량형 습도 센서로 수분 활동도(aw)를 측정 → 온도 보상 → 용해도 곡선으로 ppm 환산"** 입니다. Vaisala MMT330/MMT162, E+E EE381, HYDAC AS1000 등 주요 제품 모두 이 방식입니다.
- aw(또는 %RS, 상대포화도)는 **오일 종류·열화와 무관하게** "유리수(free water)가 생길 위험"을 직접 알려주므로 1차 측정량으로 쓰고, ppm은 오일별 계수(A, B)가 필요한 **2차 계산값**입니다.
- 개발 난이도의 핵심은 전자회로가 아니라 **①센서 소자의 오일 내 장기 안정성, ②교정/검증 체계(습도 발생기 + 칼피셔 적정), ③고압·고온 프로브 기구 설계, ④현장 인증(EMC, 방폭, HART)** 입니다.
- 추천 전략: **센서 소자는 검증된 OEM 소자를 구매**하고 (→ **확정: IST AG MK 계열을 이미 공급받고 있음**), 자체 역량은 CDC 측정 회로·온도 보상·교정 알고리즘·프로브 기구·통신(4–20 mA/HART/Modbus)에 집중.
- 1차 타깃 시장으로 **유압/윤활유(산업·건설기계)** 는 요구 정확도(±2–3 %RS)와 인증 부담이 낮아 진입이 쉽고, **변압기유**는 ppm 정확도·전력사 인증 요구가 높은 대신 부가가치가 큽니다.
- 참조 코드: [`tools/moisture_calc.py`](../tools/moisture_calc.py) (aw ↔ ppm 환산, 용해도 계수 피팅).

---

## 2. 기본 개념

### 2.1 물의 세 가지 상태

| 상태 | 설명 | 영향 |
|---|---|---|
| **용존수 (dissolved)** | 분자 단위로 오일에 녹아 있음. 포화점 이하 | 눈에 안 보임. 절연유에서는 절연파괴전압(BDV) 저하, 종이 절연 열화 가속 |
| **유화수 (emulsified)** | 포화점을 넘어 미세 물방울로 분산 | 오일 혼탁, 윤활막 파괴, 부식, 첨가제 가수분해 |
| **유리수 (free)** | 분리되어 바닥에 고임 | 부식, 캐비테이션, 미생물 번식, 절연 사고 |

→ 트랜스미터의 1차 목적은 **"포화점(aw = 1)에 얼마나 가까운가"** 를 실시간으로 알려 유화/유리수 발생 전에 경보하는 것입니다.

### 2.2 측정 단위

| 단위 | 정의 | 특징 |
|---|---|---|
| **aw (water activity)** | 0–1. 오일 내 물의 화학 포텐셜을 순수한 물 대비 비율로 표현 | 공기의 상대습도(RH)와 같은 개념. 오일 종류 무관 |
| **%RS (relative saturation)** | aw × 100 | 유압·윤활 업계에서 주로 사용 |
| **ppm (mg/kg, w/w)** | 오일 질량 대비 물의 질량 | 실험실 칼피셔(KF) 결과와 직접 비교. 오일별 용해도 계수 필요 |

**중요:** 같은 20 ppm이라도 20 °C 광유 변압기유에서는 aw≈0.36 이지만 60 °C에서는 aw≈0.08 입니다 (5장 참고). 온도가 떨어지면 ppm이 그대로여도 aw가 올라가 유리수가 생길 수 있습니다.

### 2.3 "Water cut"과의 구분

원유·생산정(油井)의 **water cut (0–100 % 함수율)** 측정은 전혀 다른 제품군입니다 (마이크로파/RF 유전율, 감마선 등; Emerson Roxar, Phase Dynamics, AGAR 등). 이 보고서는 **ppm~포화점 범위의 미량 수분** 측정(윤활유·유압유·절연유·연료)을 대상으로 합니다. 향후 water cut으로 확장하려면 별도 센서 원리가 필요합니다.

---

## 3. 적용 시장과 요구 사양

| 시장 | 대상 오일 | 대표 요구사항 | 비고 |
|---|---|---|---|
| **전력 변압기** | 광유, 합성/천연 에스테르 | ppm 출력, 0–100 ppm 범위에서 ±2~3 ppm급, 동작 −40~+120 °C, 서지/EMC 강함, 드레인 밸브 장착, 활선 교체 | IEC 60422 기준 관리. 신규 >170 kV 급은 통전 전 10 mg/kg 이하 요구. 일반적으로 35 mg/kg 미만 양호, 50 mg/kg 초과 시 건조 권고(IEEE C57.106) |
| **유압 시스템** (산업·건설·해양) | 광유계/합성 유압유 | %RS, ±2–3 %RS, 최대 50 bar 이상, 경보 접점(60 %/80 %) | HYDAC AS1000의 공장 설정값이 SP2 60 %(경고), SP1 80 %(알람) |
| **윤활 (터빈, 기어박스, 풍력, 압축기, 제지)** | 터빈유, 기어유 | %RS, 온도, Modbus/IO-Link | 풍력 기어박스 CMS 연계 수요 |
| **연료 (디젤, 제트유, 선박유)** | 디젤, HVO, 바이오디젤 | aw/ppm, 방폭(Ex) 필수 경우 많음 | FAME 함유 연료는 용해도가 크게 다름 |
| **오일 정제/건조 장비 OEM** | 모든 오일 | 정제기 입·출구 모니터링, 저가·소형 | OEM 모듈 형태 수요 |
| **선박·해양** | 윤활유, 스턴튜브 오일 | 선급 인증(DNV, KR, ABS 등) | |

---

## 4. 측정 원리 비교

| 원리 | 측정량 | 범위/분해능 | 장점 | 단점 | 적합성 |
|---|---|---|---|---|---|
| **박막 고분자 정전용량형 (capacitive polymer)** | aw | 0–1 aw, ±0.01~0.02 | 저가, 소형, 온라인, 오일 종류 무관, 저전력(4–20 mA 루프 전원 가능) | 고온·화학물질에 의한 드리프트, 포화 근처 히스테리시스, ppm 환산에 계수 필요 | ★★★★★ 업계 표준 |
| 산화알루미늄(Al₂O₃) 센서 | 이슬점/aw | 미량 영역 우수 | 저수분 감도 | 드리프트 크고 재교정 잦음, 오염 민감 | ★★ |
| 칼피셔 적정 (KF, 전량/용량법) | ppm | 1 ppm~ | 기준법(ASTM D6304, IEC 60814) | 오프라인·시약·숙련 필요 | 검증용 기준기 |
| 근적외선(NIR) 흡수 (~1.4/1.9 µm O–H 밴드) | ppm/% | 수십 ppm~% | 비접촉, 다성분 분석 가능 | 고가, 오일 매트릭스별 케모메트릭 교정, 창 오염 | ★★ 고가 분석기 |
| 벌크 유전율 / RF·마이크로파 | %(함수율) | 0.1 %~100 % | water cut에 적합 | ppm 미량 영역 감도 부족, 오일 유전율 변동에 민감 | ★ (미량 수분엔 부적합) |
| QCM(수정진동자) + 흡습막 | 질량변화 → aw | 고감도 | 고감도 | 오염·온도 민감, 복잡 | ★ 연구 단계 |
| 광섬유/FBG 코팅 센서 | aw | – | 전기적 절연(변압기 내부) | 상용 성숙도 낮음 | ★ 연구 단계 |

**결론:** 정전용량형 aw 센서 + 정밀 온도센서 조합을 기본 플랫폼으로 채택. 필요 시 향후 모델에서 유전율/전도도 센서를 추가해 오일 열화 지표(산화, 오염)까지 확장.

### 4.1 정전용량형 센서의 동작

- 전극 사이에 흡습성 고분자(폴리이미드 등) 유전막이 있고, 상부 전극은 물 분자가 투과 가능한 다공성 박막.
- 오일 속 물의 활동도와 평형이 되도록 고분자가 수분을 흡수 → 유전율 변화 → 정전용량 변화 (예: 150–300 pF 기저, 0→100 % 범위에서 수십 pF 변화).
- 기체(공기)에서 교정한 RH 곡선이 **오일 내 aw 측정에도 그대로 적용**된다는 것이 이 방식의 핵심 장점 (물의 화학 포텐셜이 평형이므로). 단, 오일 성분이 고분자에 흡착되어 생기는 **오프셋/감도 변화**가 실제 오차의 주원인 → 소자 선택과 오일 내 장기 시험이 중요.

---

## 5. 핵심 계산: aw ↔ ppm 환산

### 5.1 용해도 모델

오일의 포화 수분량(용해도) Ws는 온도에 대해 반 대수 관계:

```
log10( Ws [ppm] ) = A + B / T        (T: 켈빈, B < 0)
ppm = aw × Ws(T)
%RS = aw × 100
```

- 광유계 변압기유 대표값: **A = 7.0895, B = −1567** (log S₀ = 7.0895 − 1567/T)
- 이 계수로 계산한 포화 수분량 (참조 코드 실행 결과):

| 온도 | 20 °C | 40 °C | 60 °C | 80 °C |
|---|---|---|---|---|
| Ws (ppm) | 55.5 | 121.8 | 243.2 | 449.0 |

- 예: 20 ppm 수분 → 20 °C에서 aw 0.361, 60 °C에서 aw 0.082.
- **에스테르유(천연/합성)는 용해도가 광유의 수십 배**(상온에서 약 1,000 ppm 이상 수준)이므로 계수가 완전히 다릅니다. 유압유·윤활유도 첨가제에 따라 크게 달라집니다.
- 오일이 산화·열화되면 극성 물질이 늘어 용해도가 증가 → 같은 오일이라도 **수명 중 계수가 변함**. 그래서 aw를 1차량으로 삼는 것이 안전합니다.

### 5.2 제품에 필요한 기능

1. 오일 라이브러리(광유 변압기유, 에스테르, 대표 유압유 등)의 A, B 계수 내장
2. 사용자 계수 입력 (Modbus/HART/설정 SW)
3. **현장 계수 산출 기능**: 서로 다른 두 온도 이상에서 샘플을 채취해 KF로 ppm 측정 → 트랜스미터의 aw·T와 함께 A, B를 피팅 (`tools/moisture_calc.py`의 `fit_coefficients`)
4. 변압기용: 오일-종이 평형 곡선(Oommen 곡선 등, CIGRE TB 741 참고)을 이용한 **종이 절연 수분(%) 추정**은 부가기능으로 차별화 가능. 단, 온도 과도 상태에서는 평형이 성립하지 않으므로 필터링/평형 판단 로직 필요.

---

## 6. 경쟁 제품 벤치마크

| 제품 | 측정량 | 주요 사양(공개 자료 기준) | 출력/통신 | 비고 |
|---|---|---|---|---|
| **Vaisala MMT330 시리즈** (MMT332/337/338 프로브 변형) | aw, T, ppm | aw 0–1, HUMICAP® 센서, 고온·고압 프로브, 볼밸브 삽입형(MMT338) | 4–20 mA ×2~3, RS-232/485, 디스플레이 옵션 | 업계 레퍼런스. 광유 변압기유 ppm 환산 내장, 기타 오일은 계수 입력 |
| **Vaisala MMT162 / MMP8(Indigo 호환 프로브)** | aw, T, ppm | 소형 일체형 / 교체형 스마트 프로브 | 4–20 mA, Modbus RTU | OEM·소형 시장 |
| **Vaisala MHT410** | 수분+수소+온도 | 변압기 전용 | 4–20 mA, Modbus, DNP3 | 수소(DGA 간이) 결합 |
| **E+E Elektronik EE381** | aw, T, ppm | 오일 온도 최대 120 °C, 압력 20 bar(표준)/100 bar(옵션), G½" ISO 또는 ½" NPT, HC 계열 센서 | 아날로그 출력 2개(자유 설정), LCD·상태 LED 옵션 | 소형 금속 하우징, 설정 SW(EE-PCS) |
| **HYDAC AquaSensor AS1000** | %RS, T | 0–100 %RS, −25~100 °C, −0.5~50 bar, 스위치 포인트 60 %/80 % | 4–20 mA ×2, 스위치 출력 | 유압/모바일 장비 대상 |
| **Parker (Kittiwake 등) / Pall / MP Filtri / Argo-Hytos** | %RS, T | 유압·윤활용 저가형 | 4–20 mA, CAN, IO-Link 등 | 필터 제조사의 콘디션 모니터링 번들 |
| **IST AG Moisture-in-oil probe** | aw, T | 소자 제조사의 모듈 제품 | 디지털 | 소자+모듈 공급 가능성(OEM 파트너 후보) |

**시장 인사이트**
- 고급(변압기·발전) 시장은 Vaisala가 강세 → ppm 정확도, 장기 안정성, 전력사 레퍼런스가 진입장벽.
- 유압/윤활 시장은 필터·유압기기 업체의 번들 판매 구조 → **가격(모듈 원가), IO-Link/CAN 지원, 소형화**가 경쟁 요소.
- 국내에서는 대부분 수입품 사용 → 국산화, 빠른 기술지원, 교정 서비스 번들이 차별점이 될 수 있음.

---

## 7. 센서 소자 후보

| 소자 | 제조사 | 특징 | 비고 |
|---|---|---|---|
| **MK33-W** | IST AG (스위스) | 정전용량형, 기저 약 300 pF, 0–100 %RH, −40~+190 °C, **오일 측정용으로 개발**, 유연/강성 리드 | **채택 (공급 중)**. 오일 내 장기 드리프트·교정 데이터는 자체 시험으로 축적 |
| P14-W / P14 Rapid-W | IST AG | 150 pF ±50 pF, −50~+150 °C, 범용 | 비교 시험용 |
| MK33 mini | IST AG | 200 pF ±40 pF, 소형 | 소형 프로브용 |
| HC 계열 (예: HC1000 등) | E+E Elektronik | 오염 저항성·장기안정성 강조, EE381에 사용 | 소자 단품 판매 조건 문의 필요 |
| HS1101LF 등 | TE Connectivity(구 Humirel) | 저가 범용 | 오일 내 장기 안정성 미검증 → 저가형에서 시험 |
| 디지털 RH 센서 (Sensirion SHT4x/SHT3x 등) | Sensirion 등 | IC 일체형, 교정 내장 | **오일 침지용으로 설계되지 않음**(패키지·보호막). 오일 접촉 적용은 원칙적으로 부적합, 시험 없이 사용 금지 |
| Vaisala HUMICAP® | Vaisala | 최고 수준 성능 | 소자 외판 안 함(자사 제품 전용) |

**소자 평가 항목:** 오일(광유/에스테르/유압유) 150 °C 장기 침지 후 드리프트, 온도 사이클, 고압 내성, 응답시간(오일에서 T63), 히스테리시스, 포화(aw≈1) 복귀 특성, 리드 결선 방식(고온 솔더/용접), 수급 안정성·단종 정책.

---

## 8. 하드웨어 아키텍처

```
 ┌──────────── 프로브 (오일 접액부) ────────────┐        ┌──────────────── 전자부 (하우징) ────────────────────────┐
 │ 소결 필터 → 정전용량 RH 소자 (100~300 pF)     │──차폐──▶│ CDC(정전용량-디지털 변환)                                  │
 │           Pt1000 (Class A/AA) 온도센서        │──4선──▶│ RTD ADC                                                    │
 └───────────────────────────────────────────────┘        │        ▼                                                   │
                                                          │ MCU (저전력, FPU)  ─ 교정 EEPROM/FRAM, 워치독, 진단        │
                                                          │   ├─▶ 4–20 mA 루프 DAC (+ HART 모뎀)  ─┐                   │
                                                          │   ├─▶ RS-485 Modbus RTU (절연)          ├─ 서지/EMC 보호 ──▶ 현장
                                                          │   ├─▶ 릴레이/오픈컬렉터 경보            │                   │
                                                          │   └─▶ LCD/LED, 서비스 포트(USB/UART)   ─┘                   │
                                                          └────────────────────────────────────────────────────────────┘
```

### 8.1 주요 부품 후보

| 블록 | 후보 | 선택 포인트 |
|---|---|---|
| CDC | **ScioSense PCAP04**, ADI AD7745/AD7746, TI FDC1004 | 100–300 pF 기저 + 수십 pF 변화 측정. PCAP04는 기저 용량 대응·저전력·온칩 DSP, AD7746은 24-bit Σ-Δ로 정밀도 높음. 기저 용량 오프셋 보상(CAPDAC) 범위 확인 |
| 온도 | Pt1000 4선 + TI ADS1220/ADS124S08 또는 ADI MAX31865 | 온도 오차 0.1 °C → ppm 환산 오차에 직결 (60 °C 부근에서 1 °C 오차 ≈ 약 3 % ppm 오차) |
| MCU | STM32L4/U5, TI MSP430FR, NXP LPC 등 | 루프 전원(4 mA 미만 전체 소비) 예산 내 동작, FPU로 환산 연산 |
| 4–20 mA | **ADI AD5421/AD5423**, TI DAC161S997, XTR116 | 루프 전원 공급, NAMUR NE43 알람 전류(≤3.6 / ≥21 mA) |
| HART | ADI AD5700/AD5700-1, TI DAC8740H | HART 7 준수, FieldComm 등록 필요 |
| RS-485 | ADI ADM2587E(절연 일체형), TI ISO1410 | 절연 + TVS |
| 전원 | 24 V DC(9–30 V) 절연 DC/DC 또는 루프 전원 | 2선식 루프 전원형 vs 4선식(디스플레이·릴레이 포함) 두 모델 분리 권장 |
| 보호 | TVS, GDT, PTC 퓨즈, 코몬모드 초크 | 변전소 환경: IEC 61000-4-5 서지 강화 |

### 8.2 전력 예산 (2선식 루프 전원형)

- 루프 최소 전류 3.6~3.8 mA 이내에서 전체 회로 동작 필요 → MCU 슬립/주기 측정(1–2 s), CDC·ADC 변환 후 파워다운, LCD는 저전력 반사형.
- HART 모뎀·DAC 소비 포함 **총 3 mA 이하 목표**.

### 8.3 아날로그 설계 유의사항

- 소자-CDC 간 배선은 짧게, 액티브 실드(guard) 사용. 프로브 케이블형(원격 프로브)은 케이블 용량/누설이 오차원 → CDC 채널 차동 측정 또는 케이블 보상.
- 고온 프로브에서 **소자 누설(절연저항 저하)** 이 측정 오차로 나타남 → 여기 주파수/방식 선택.
- 온도센서는 소자와 열적으로 결합(같은 필터 안) → aw와 T의 동일 지점 측정이 ppm 정확도 핵심.

---

## 9. 기구(프로브) 설계

| 항목 | 권장 사항 |
|---|---|
| 접액부 재질 | SUS316L, 소결 스테인리스 필터(오일 흐름 속 오염·와류 보호), 전해연마 |
| 공정 연결 | G½" ISO 228-1, ½" NPT, M18×1.5(유압) / 변압기용 1½" 드레인 밸브 어댑터 |
| 압력 | 기본 20~40 bar, 유압 고압형 100~200 bar (내압 시험: 사용압 1.5배 이상) |
| 온도 | 오일 −40~+120 °C (고온형 180 °C는 전자부 분리 원격 프로브 필요) |
| 씰 | FKM(Viton) 기본, 에스테르/인산에스테르 유압유는 EPDM/FFKM 선택 — 오일 호환성 표 준비 |
| 활선 교체 | **볼밸브 삽입형** 프로브(압력 하에서 인출/삽입) → 변압기·대형 윤활 시스템에서 강력한 요구사항 |
| 설치 위치 | 유속이 있는 곳(정체부 X), 공기 포켓 없는 곳, 가능한 수평 장착. 변압기는 순환 오일이 지나는 배관/밸브 |
| 하우징 | 알루미늄 다이캐스트 또는 SUS, IP66/IP67(IEC 60529), **M 커넥터(M Connect, 원형 M 시리즈) 채택** |
| 열 분리 | 고온 오일에서 전자부 온도 < 85 °C 유지 (넥 길이/방열핀 시뮬레이션) |

---

## 10. 펌웨어/알고리즘

1. **측정 체인**: C_raw → 기저·케이블 보상 → 온도 의존 교정 다항식 `aw = f(C, T)` (2차원 교정 테이블/다항식) → 필터링 → aw, %RS
2. **온도 보상**: 소자의 용량-습도 특성은 온도 의존 → 여러 온도(예: 20/40/60/80 °C)에서 교정해 2D 보정.
3. **ppm 환산**: `ppm = aw × 10^(A + B/T)` + 오일 라이브러리 + 사용자 계수.
4. **포화/응결 처리**: aw ≥ 0.95 근처에서 히스테리시스·복귀 지연 고려, "유리수 위험" 상태 플래그.
5. **평형 판단**: 온도 변화율(dT/dt)이 크면 aw/ppm 값의 신뢰도 낮음 → 이동평균·안정 플래그 제공 (변압기 부하 변화 시 중요).
6. **진단**: 소자 단선/단락, 용량 범위 이탈, 온도센서 이상, 내부 온도 과열, EEPROM CRC → NAMUR **NE43**(전류 알람), **NE107**(상태 분류: Failure/Check/Out of spec/Maintenance).
7. **통신**: Modbus RTU 레지스터 맵(float32, 상태, 계수, 교정일), HART 7 명령(Universal/Common Practice/Device Specific), 향후 IO-Link(유압 시장) 검토.
8. **보안/무결성**: 교정 데이터 서명·CRC, 펌웨어 업데이트 시 교정 보존, 설정 변경 이력.
9. **재교정 지원**: 현장 1점/2점 조정(염포화 용액·기준 프로브 비교), 교정 만료 알림.

---

## 11. 교정 및 시험 방법

### 11.1 1차 교정 (기체 중, aw = RH/100)

- **이압식(two-pressure) 또는 혼합식 습도 발생기** + 냉각식 노점계(기준기, 국가표준 소급) — KRISS(한국표준과학연구원) 또는 KOLAS 인정 교정기관 소급.
- 보조: **포화 염 용액** (25 °C 기준 대략값) — LiCl 약 11 %RH, MgCl₂ 약 33 %RH, NaCl 약 75 %RH, K₂SO₄ 약 97 %RH. 현장/생산 점검용.
- 다온도 교정용 항온조(챔버) 필요.

### 11.2 오일 중 검증

- 오일 순환 루프(히터/칠러, 수분 주입·건조 장치) 구성 → 트랜스미터 aw·T 기록 + 동시 샘플링 KF 적정.
- 기준 시험법: **IEC 60814**(절연유 KF 전량법), **ASTM D6304**(석유제품 KF 전량법), ASTM D1533(절연유).
- 오일별 용해도 계수 결정 실험(여러 온도에서 포화 → KF) → 오일 라이브러리 구축.
- 에스테르·유압유·터빈유 등 대상 오일 확보.

### 11.3 신뢰성·환경 시험

| 시험 | 기준(예) |
|---|---|
| 고온 오일 장기 침지(드리프트) | 사내 기준: 120/150 °C, 1,000–3,000 h |
| 온도 사이클/열충격 | IEC 60068-2-14 |
| 진동/충격 | IEC 60068-2-6/-27 (모바일 유압은 더 강하게) |
| 압력 사이클/내압 | 사용압 1.5배 정적, 수십만 회 압력 사이클(유압) |
| 방진·방수 | IEC 60529 IP66/67 |
| EMC | IEC 61326-1 (산업 환경), 서지/버스트/ESD/RF 내성 |
| 응답시간 | 건조→습윤 오일 스텝, T63/T90 |

---

## 12. 인증 및 규격

| 구분 | 규격/인증 | 적용 |
|---|---|---|
| EMC | IEC/EN 61326-1, IEC 61000-4-2/3/4/5/6/8 | 필수 (CE, KC) |
| 전기 안전 | IEC/EN 61010-1 | 필수(측정기기) |
| 국내 | **KC 적합성평가(전자파, 방송통신기자재)**, 방폭 지역 사용 시 **KCs** | 국내 판매 |
| 유럽 | CE (EMC, RoHS, 필요 시 ATEX/PED 검토) | 수출 |
| 방폭 | IECEx / ATEX / KCs — Ex ia(본질안전) 또는 Ex d(내압방폭) | 연료·석유화학 시장 |
| 기능안전 | IEC 61508 SIL (선택) | 공정 안전 루프에 쓰일 경우 |
| 통신 | FieldComm Group HART 등록, Modbus, IO-Link 적합성 | 해당 시 |
| 선급 | DNV, KR, ABS, LR 등 | 선박 |
| 전력 | IEC 60422(유지관리 지침), IEC 60814, IEEE C57.106, CIGRE TB 741 | 변압기 적용 기술 근거 |
| 품질 | ISO 9001, 교정: ISO/IEC 17025(KOLAS) | 교정 성적서 발행 |

---

## 13. 목표 사양(안)

| 항목 | 표준형 (유압/윤활) | 고급형 (변압기/발전) |
|---|---|---|
| 측정량 | aw(%RS), T | aw, T, ppm, (종이 수분 추정) |
| aw 범위/정확도 | 0–1 / ±0.02 (0–0.9), ±0.03 (0.9–1) | 0–1 / ±0.01 (0–0.9), ±0.02 (0.9–1) |
| 온도 정확도 | ±0.3 °C | ±0.2 °C |
| 오일 온도 | −20~+100 °C | −40~+120 °C (원격형 180 °C) |
| 압력 | 50 bar (옵션 200 bar) | 20 bar, 볼밸브 삽입형 |
| 출력 | **RS-485 Modbus RTU (기본)**, 옵션: 4–20 mA ×2, 스위치 2, IO-Link/CAN | **RS-485 Modbus RTU (기본)**, 옵션: 4–20 mA/HART, 릴레이 2 |
| 펌웨어 업데이트 | RS-485 부트로더 (현장 원격 업데이트) | RS-485 부트로더 |
| 전원 | 9–30 V DC | 루프 전원 또는 24 V DC / 옵션 AC |
| 보호등급 | IP67 | IP66, 서지 강화 |
| 원가 목표 | BOM 약 USD 40–70 | BOM 약 USD 120–250 |

(원가는 개략 추정. 센서 소자·SUS 가공·하우징 수량 견적으로 확정 필요)

---

## 14. 개발 로드맵·예산 규모

| 단계 | 기간(예상) | 주요 산출물 |
|---|---|---|
| 0. 요구사항·시장 검증 | 1–2개월 | 타깃 시장 확정, 고객 인터뷰, 목표 사양서, 소자 샘플 확보 |
| 1. 기술 검증(PoC) | 3–4개월 | CDC+RTD 평가보드, 소자 3~4종 오일 침지 비교, aw↔KF 상관 데이터 |
| 2. 시작품(EVT) | 4–6개월 | 전용 PCB, 프로브 기구 1차, 펌웨어(교정·Modbus/4–20 mA), 교정 설비 구축 |
| 3. 설계검증(DVT) | 4–6개월 | 환경/EMC 사전시험, 장기 드리프트 시험, HART, 현장 파일럿 설치(2~3곳) |
| 4. 인증·양산준비(PVT) | 3–6개월 | KC/CE/(Ex), 생산 교정 지그·자동화, 교정 성적서 체계 |
| **합계** | **약 15–24개월** | 방폭 포함 시 상단 |

**초기 설비 투자 예시:** 습도 발생기·기준 노점계, 항온조, KF 적정기(전량법), 오일 순환 시험 루프, 압력 시험 장비, LCR 미터/정밀 용량 기준, EMC 사전 시험 장비. (KF·습도 교정은 초기에는 외부 기관 활용 가능)

---

## 15. 리스크와 대응

| 리스크 | 영향 | 대응 |
|---|---|---|
| 소자의 오일 내 장기 드리프트 | 정확도 불만, 리콜 | 복수 소자 조기 장기 시험, 공급사 협업, 현장 조정 기능 |
| ppm 환산 오차(오일 열화·종류) | 고객 KF 결과와 불일치 | aw를 1차량으로 교육, 계수 현장 피팅 기능, 오일 라이브러리 |
| 소자 공급 의존(단일 소스) | 단종/리드타임 | 2개 소자 대응 설계(CDC 범위), 장기 공급 계약 |
| 고온·고압 누설 | 안전 사고 | 내압/피로 시험, 용접 인증, 씰 재질 호환성 검증 |
| 변전소 EMC/서지 | 고장 | 서지 강화 설계, 사전 EMC 시험 |
| 인증 기간·비용(방폭, HART) | 일정 지연 | 1차 제품은 비방폭·Modbus/4–20 mA로 출시, 후속 모델에서 확장 |
| 경쟁사 가격/브랜드 | 판매 부진 | 국산화·교정 서비스·IoT 기능 번들, OEM(정제기/필터 업체) 채널 |

---

## 16. 차별화 기회

1. **IoT/클라우드 연계**: Modbus TCP/MQTT 게이트웨이, LoRaWAN/NB-IoT 무선형, 추세 기반 예지정비(드라이어 작동 시점 예측).
2. **변압기 특화 분석**: 오일 aw/온도 → 종이 절연 수분 추정, 기포 발생 온도(bubbling inception) 위험 경고, 동적 평형 판단.
3. **오일 종류 자동 학습**: 여러 온도에서의 aw–T 데이터 + 주기적 KF 입력으로 계수 자동 갱신.
4. **복합 센서**: aw + 유전율/전도도(오일 열화·산화) + 온도를 한 프로브에 → "오일 컨디션 센서"로 확장.
5. **스마트 교체형 프로브**: 교정 데이터를 프로브에 저장(Vaisala Indigo/MMP8 방식) → 현장에서 프로브만 교환·교정 서비스 모델.
6. **IO-Link / CAN(J1939)**: 모바일 유압·건설기계 OEM 대응.

---

## 17. 참고 자료

- Vaisala MMT330 시리즈 데이터시트 — https://docs.vaisala.com/v/u/B210953EN-G/en-US
- Vaisala MMT330 오더폼 — https://www.vaisala.com/sites/default/files/documents/MMT330%20Order%20Form%20Global.pdf
- Vaisala 백서: The Effect of Moisture on the Breakdown Voltage — https://www.vaisala.com/sites/default/files/documents/CEN-TIA-power-whitepaper-Moisture-and-Breakdown-Voltage-B211282EN-A-LOW.pdf
- E+E Elektronik EE381 — https://www.epluse.com/products/moisture-in-oil-instrumentation/oil-measurement-transmitter/ee381/
- E+E EE381 매뉴얼 — https://www.instrumart.com/assets/EE-EE381-moisture-transmitter-manual.pdf
- HYDAC AquaSensor AS1000 — https://www2.hydac.com/_de-en/products/sensors/fluid-monitoring-sensors/as-1000.html
- IST AG MK33-W (오일 측정용 정전용량 소자) — https://www.ist-ag.com/en/products/capacitive-humidity-sensor-mk33-w
- IST AG P14-W — https://www.ist-ag.com/en/products/capacitive-humidity-sensor-p14-w
- IST AG Moisture-in-oil probe — https://www.ist-ag.com/en/products/rht-sensor-module-moisture-oil-monitoring
- Moisture Solubility for Differently Conditioned Transformer Oils (U. Wisconsin) — https://minds.wisconsin.edu/bitstream/handle/1793/10272/file_1.pdf
- Moisture Equilibrium in Transformer Paper-Oil Systems — https://minds.wisconsin.edu/bitstream/handle/1793/10276/file_1.pdf
- Analysis of water solubility in transformer oil using least square fitting (IEEE) — https://ieeexplore.ieee.org/iel5/5624685/5640703/05640858.pdf
- IEC 60422:2024 (광유 절연유 관리 지침) — https://standards.iteh.ai/catalog/standards/iec/3d40aa70-83c0-4000-82e3-61486cb21885/iec-60422-2024
- CIGRE TB 741: Moisture measurement and assessment in transformer insulation
- 변압기 절연 수분 관련 한계값 정리 — https://industrialmonitordirect.com/blogs/knowledgebase/transformer-paper-insulation-moisture-content-specifications
- 표준 시험법: IEC 60814, ASTM D6304, ASTM D1533, IEEE C57.106, IEC 61326-1, IEC 61010-1, IEC 60529, NAMUR NE43/NE107

---

> **결정 (2026-09-26):** RS-485 Modbus RTU를 기본 출력으로 하고, 부트로더로 RS-485 통신을 통해 펌웨어를 업데이트한다. 상세 설계: [rs485-bootloader-design.md](rs485-bootloader-design.md)

## 다음 단계 제안

1. 1차 타깃 시장 결정 (유압/윤활 vs 변압기) 및 목표 가격 확정
2. IST AG, E+E 등에 소자 샘플·데이터시트·OEM 조건 문의
3. CDC(PCAP04 / AD7746) 평가보드로 PoC 회로 구성
4. 소형 오일 시험 루프 + 외부 KF 분석 의뢰로 aw–ppm 상관 데이터 확보
5. 국내 교정기관(KOLAS) 및 인증기관(KC/KCs) 사전 상담

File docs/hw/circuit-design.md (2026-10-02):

# HMT500(260313) 회로 설계서 (서지·오결선 보호 포함) — 회로도 v0.10

> **최신 결정 #57 / 회로 v0.11:** R3=845k, R5=35.7k, R6=82k; UVLO8.734V, OVP32.610V/복귀30.144V, 명목ILIM146.34mA. R1/R4도 재고품 교체. [BOM R2 계산·제약](procurement-bom-r2-261003.md)이 이전 값보다 우선.

> **조달 변경 #56 (2026-10-03):** C41/C51=C153291, R5=C23029로 동일 값·패키지 대체. 회로 값과 PCB A5-R3 유지, BOM R1. [검토 기록](procurement-bom-r1-261003.md).

> **PCB A5 (#47, 2026-10-02):** 6층·신호 비아 0.30/0.15 mm. **미연결 0, DRC 오류 0, 배선 가지 경고 0**. In1 GND 전용, In4 GND 동박/제한된 신호·전원 혼용. 회로 v0.10·기구 Rev I·배치 유지. 거버/BOM/CPL은 제조 검토용이며 DFM·부품 확인 전 발주 보류. [A5 아트워크 결과](artwork-a5-261002.md).

> **회로 최신 결정 #41 (2026-10-01, v0.10):** AO D30/D40 = TVS1401DRBR(±14 V)로 변경. 입력 D2·RS-485 D60/D61은 TVS3301 유지. VAO 16.1 V 유지. AO ±28/30 V 지속 오결선 보장은 제외한다. 아래 과거의 모든 핀 ±30 V 무손상 요구·출력 TVS3301 유지 설명보다 이 결정이 우선한다. [변경 검토](ao-tvs1401-261001.md).

> **v0.9 (2026-09-30, 결정 #32):** 3중 검토([final-review-260313A.md](final-review-260313A.md)) 반영. OVP 32.6 V(R5 36.5 k, 복귀 30.1 V) + TPS26611 +Vs 27 V 제너 클램프, D2 → TVS3301, eFuse 입력 C2 2.2 µF, 벅 입력 220 nF × 2 + C5 벌크를 U2 옆에, U2 핀 3 = SW, RS485_DE 10 k 풀다운, THVD2410, X7R만 사용, R2 고전압 1206, SGOOD → PA0/PA4, CS_CDC → PA15, VIN_SENSE → PB0, LATCH·CS 풀업, OPA197 V+ = DAC AVDD, R31/R41 100 k, 보조 시트(Aux). **입력 절대 최대 33 V DC 연속** (TVS). 아래 본문의 v0.8 이전 값은 이 줄이 우선합니다.
>
> **v0.9 외부 검수 반영 (2026-09-30, 결정 #35, [external-review-response-260930.md](external-review-response-260930.md)):** D2 뒤·U1 앞 **직렬 쇼트키 D3 PMEG10010ELR (100 V)** — 음(−) 서지·역극성은 D3가 받아 eFuse IN–OUT 역전압 없음, U1 입력 넷 = VIN_D. **RS-485 버스 TVS D60/D61 = TVS3301** (A·B–GND). U11 → **THVD2410DGKR (VSSOP-8, 같은 핀)**. +Vs 제너 **BZX84C24** (27 → 24 V, +Vs 최악 ≤ 26.4 V). **C7 삭제** (D3로 VIN_P 유지 필요 없음, 벌크 C5·C43 유지). ADS1220 **IDAC = 250 µA 고정**.
>
> **결정 #37 (2026-10-01, DAC 부분 확정 — VibrationSensor IVS320 AO rev 1.0 방식):** AO 전용 전원 **VAO 16.1 V** (벅 U15 LMR51606YFDBVR + L3 22 µH + C64/C65) → DAC AVDD(10 Ω)·TPS26611 +Vs·OPA197 V+. 제너 폴로워(Q1·R50·D50·C53)·C43 삭제. DAC CMP 보상 4.7 nF(VOUT–CMP) + 100 pF(CMP–GND), DAC 출력 클램프 BAS70-04 (D41/D51). 출력 TVS3301·SGOOD→ADC는 유지. DAC 손실 28 V 단락 0.66 → 0.39 W/채널.
>
> **결정 #38 (2026-10-01, JLC 부품 우선):** 5 V 벅 U2 = **LMR51606YFDBVR** (1.1 MHz, L2 10 µH, C6 22 µF, R8/R9 118k/22.1k → 5.07 V; 아래 본문의 LMR36006 값은 이 줄이 우선). R19 = ERA-3AEB4021V (0.1 %·25 ppm), R1·R30·R40 = CRCW2512 일반형.

작성일: 2026-09-26 · 상태: 상세 회로 설계안 (회로도 CAD 입력 전). 부품값은 초기값이며, 평가보드와 EMC 사전시험으로 확정합니다.

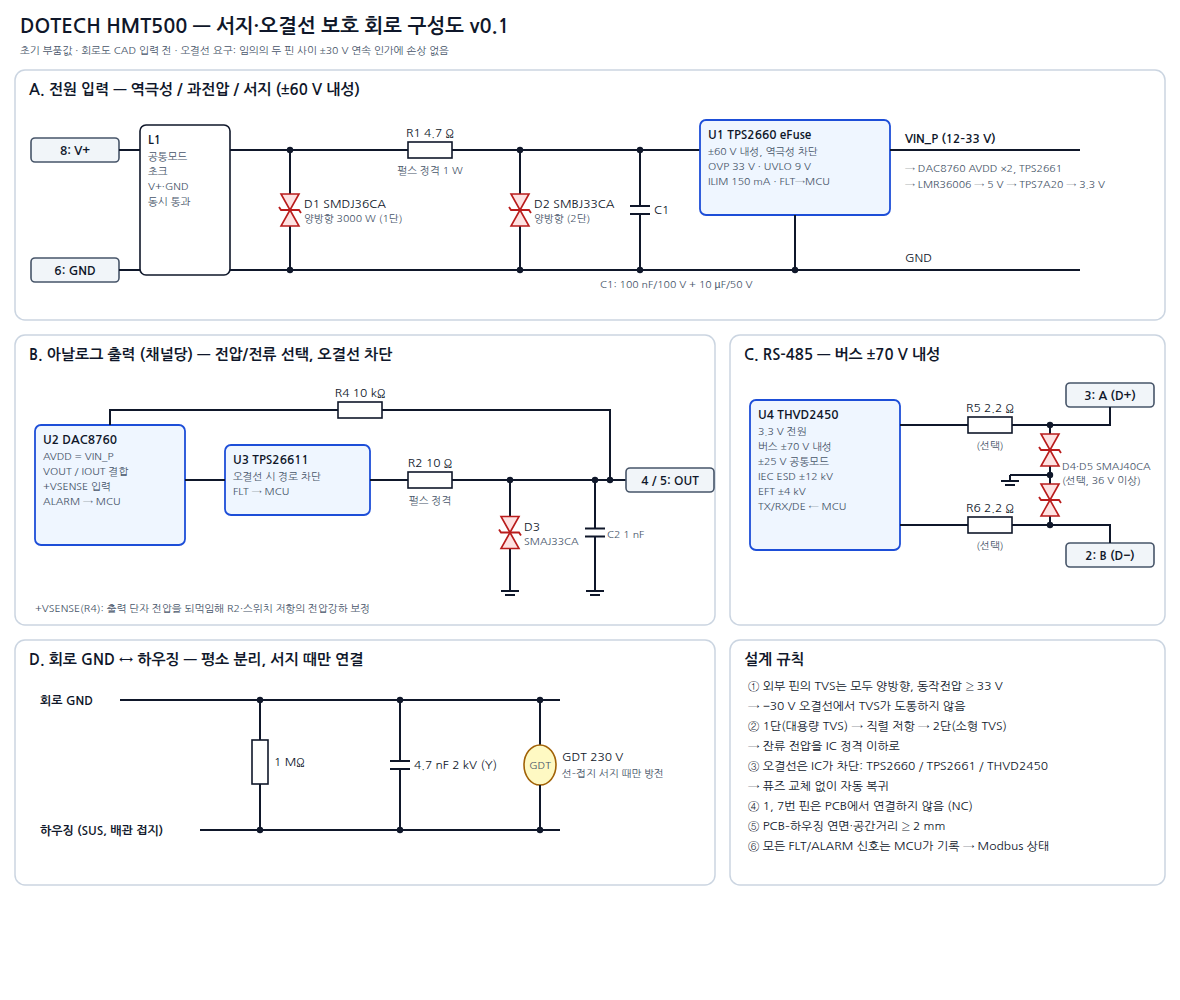
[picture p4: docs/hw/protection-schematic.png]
보호 회로 구성도


원본: [protection-schematic.svg](protection-schematic.svg) · 블록도: [block-diagram.png](block-diagram.png) · 블록 설계: [hardware-block-design.md](hardware-block-design.md)

---

## 1. 보호 요구사항

### 1.1 오결선 (Miswiring)

> **요구:** 커넥터의 **어떤 두 핀 사이에 −30 ~ +30 V DC를 연속으로 걸어도 손상이 없어야** 합니다. 결선을 바로잡으면 자동으로 정상 복귀해야 합니다(퓨즈 교체 없음).

| 오결선 상황 | 보호 수단 | 결과 |
|---|---|---|
| 전원 역극성 (V+ ↔ GND 바뀜) | eFuse **TPS2660** (±60 V, 역극성 차단 내장) + **양방향** TVS | 차단, 복귀 후 정상 |
| 전원 과전압 (연속 최대 33 V — TVS 정격) | TPS2660 과전압 차단 (OVP 32.6 V, 복귀 30.1 V, v0.9) | 차단, 복귀 후 정상. 33 V 초과 연속 인가는 TVS 손상 (60 V 내성 아님) |
| 전원이 아날로그 출력 핀에 연결됨 (±30 V) | 출력 보호 스위치 **TPS2661** (50 V) + 양방향 TVS + 직렬 저항 | DAC와 분리됨, FLT 신호 발생 |
| 아날로그 출력 단락 (GND, 다른 출력) | DAC8760 내장 전류 제한 + 단락/단선 감지 | 출력 제한, ALARM |
| 전원이 RS-485 A/B에 연결됨 (±30 V) | **THVD2410** 버스 ±70 V 내성 (v0.9, 이전 THVD2450) | 통신만 중단, 손상 없음 |
| RS-485와 아날로그 출력이 서로 바뀜 | 위 두 보호의 조합 | 손상 없음 |
| 1, 7번 핀 (예비)에 무엇이 연결되든 | PCB에서 **연결하지 않음(NC)** | 영향 없음 |

> **변경 제안:** 앞서 7번 핀을 아날로그 GND로 쓰자고 했지만, 오결선 요구를 고려해 **7번은 NC로 되돌립니다**. 7번이 GND에 직결되어 있으면 V+를 7번에 잘못 물렸을 때 전원이 단락됩니다. 대신 전압 출력은 DAC8760의 +VSENSE로 PCB 출력단 전압을 보정하고, 케이블 GND 전압강하(3선식)는 오차 예산에 포함합니다(6.1절).

### 1.2 서지·과도 (설계 목표)

IEC 61326-1 산업 환경 요구보다 여유 있게 잡은 설계 목표입니다. 규격의 정확한 적용 레벨은 시험소와 확인이 필요합니다.

| 시험 | 규격 | 전원 포트 | 신호 포트 (RS-485, 아날로그) |
|---|---|---|---|
| 서지 | IEC 61000-4-5 | **±1 kV 선–접지, ±1 kV 선–선** | **±1 kV 선–접지** |
| 버스트(EFT) | IEC 61000-4-4 | ±2 kV | ±2 kV |
| 정전기(ESD) | IEC 61000-4-2 | 접촉 ±8 kV, 기중 ±15 kV (커넥터, 하우징) | 같음 |
| 전도 RF | IEC 61000-4-6 | 10 Vrms | 10 Vrms |

**판정 기준:** 시험 중에는 일시적인 성능 저하를 허용하고, 시험 후에는 자동으로 복귀해야 합니다(기준 B). 손상이나 설정값 손실은 허용하지 않습니다.

## 2. 전원 입력부

```
커넥터 8 (V+) ─┬─[FB1]─┬─[R1 4.7Ω 펄스]─┬──────────── TPS2660 IN ──► VIN_P (≤29 V)
               │       │                │
             [D1]    [C1]             [D2]            TPS2660: OVP 29 V, UVLO 8.6 V, ILIM 149 mA
             양방향   100nF           양방향                    FLT → MCU
               │     100V               │
커넥터 6 (GND) ┴───────┴────────────────┴──────────── GND
```

| 기호 | 부품 | 값 / 품번(안) | 역할 |
|---|---|---|---|
| L1 | 공통모드 초크 | 2×1 mH급, 정격 0.3 A 이상 (예: Würth WE-SL 계열) | EFT, 전도 RF 저감. V+와 GND 동시 통과 |
| D1 | TVS 양방향 (1단) | **SMDJ36CA** (3000 W, Vbr 약 40 V) | 서지 주 흡수. **양방향이어야** 역극성 −30 V에서 도통하지 않음 |
| R1 | 펄스 내성 저항 | 4.7 Ω, 1 W, 펄스 정격 (MELF 또는 CRCW-HP) | 1단·2단 사이 전류 분담. 정상 전류 55 mA에서 전압강하 약 0.26 V |
| D2 | TVS 양방향 (2단) | **TVS3301DRBR** (v0.9, 이전 SMBJ33CA) | 평탄 클램프 약 42.5 V → 음(−) 서지에서 eFuse IN–OUT이 정격(−70 V / 10 ms 이하 펄스) 안에 머묾. U1 옆. **입력 DC 절대 최대 33 V** (TVS3301은 DC 약 34.5 V 이상에서 손상) |
| C1 | 세라믹 | 100 nF / 100 V + 10 µF / 50 V | 입력 안정, EFT |
| U1 | eFuse | **TI TPS26600PWPR** | 역극성(−60 V) 차단, OVP 32.6 V (복귀 30.1 V), UVLO 8.9 V, 전류 제한 149 mA, 돌입 전류 제어. 입력 C2 2.2 µF 100 V (v0.9) |
| FB1 | 페라이트 비드 | 600 Ω @100 MHz | 고주파 |

- **TPS2660 설정:**
  - **v0.9:** R5 **36.5 k** → OVP 상승 **32.6 V** (31.5–34.2), 하강(복귀) **30.1 V** (29.2–31.4), UVLO 8.9 V. v0.8(29 V)은 복귀가 약 27 V라 26–28 V 전원에서 한 번 차단되면 켜지지 않는 문제가 있었습니다(검토 A1). TPS26611 +Vs·DAC AVDD·OPA197 V+ = **VAO 16.1 V 벅** (U15 LMR51606, 결정 #37 — 이전 결정 #35의 24 V 제너 폴로워 대체).
  - 전류 제한 I_OL = 12 / R6[kΩ] → R6 **80.6 k** = 149 mA (12 V 입력 최대 부하 약 90 mA의 약 1.6배, 검토 계산).
  - **RTN (EF_RTN):** 데이터시트 9.3.5.5 — "RTN을 GND에 연결하면 역극성 보호가 꺼지고 역극성 때 영구 손상". R5·R6·C4·MODE와 방열 패드는 **RTN에 연결하고 GND와는 연결하지 않습니다** (v0.7의 R22 0 Ω 링크 삭제). GND 핀(9)만 시스템 GND. IMON은 쓰지 않아 개방(데이터시트 허용, R7 삭제). SHDN 개방 = 켜짐(내부 2.7 V).
  - FLT 출력은 MCU로 연결해 전원 이상 이력을 기록합니다.
- **동작 전원 범위:** **12–28 V DC, 최대 28 V** (v0.8 결정 #26, 확정 #36 — 이전 12–30 V). 전류 출력 부하 RL ≤ 500 Ω (V+ ≥ 18 V), 18 V 미만 RL ≤ (V+ − 6 V)/24 mA. EE364 전원(10–28 V)과 상한이 같습니다.
  - 전류 출력 최대 부하 = (V+ − 3 V) / 24 mA − 25 Ω (DAC 여유 AVDD − 2 V, R34 10 Ω·R1·eFuse 강하 약 1 V, TPS26611 RON 최대 12.5 Ω, R30 10 Ω) → **12 V: 약 350 Ω, 24 V: 약 850 Ω**. 사용 설명서 사양에 기재.
- **VIN_P 레일:** DAC8760 AVDD ×2와 LMR36006 입력에 공급합니다.

### 2.1 내부 전원

| 레일 | 부품 | 부하 |
|---|---|---|
| VIN_P (12–28 V, 최대 29 V) | TPS2660 출력 | DAC8760 AVDD ×2 (각 10 Ω 직렬), TPS26611 +Vs, OPA197, 벅 입력 |
| 5 V | **LMR36006** 벅 (4.2–60 V 입력), 인덕터 15 µH, 입력 220 nF × 2 (핀 옆) + C5 10 µF | LDO 입력 |
| 3.3 V | **TPS7A2033** 저잡음 LDO (입력 C26 1 µF) | MCU, PCAP04, ADS1220, THVD2410, DAC8760 DVDD(외부 공급 모드) |
| 3.3 V_A | 3.3 V + 페라이트 + 10 µF | PCAP04, ADS1220 아날로그 전원 분리 |

## 3. 아날로그 출력부 (채널당, 2채널 동일) — 회로도 v0.8 (결정 #24, #26)

```
               ┌─────────────── +VSENSE ◄── U12 OPA197 (이득 1) ◄── R31 10k ◄───┐
DAC8760  VOUT ─┤                                                                 │
(AVDD=VIN_P    ├── U9 TPS26611 ── R30 10Ω ──┬────┬──────────────────────────────┴──► 커넥터 4 (OUT1) / 5 (OUT2)
  via R34 10Ω) ─┘   (오결선 차단)   펄스     D30  C41
         IOUT ──(VOUT와 합침)                TVS3301
         ISET-R ── R32 15k 0.1% ── GND     TVS  1nF
         ALARM ──► MCU                      │    │
         SPI2: DIN·SDO 공유, SCLK = SCK OR LATCHn (U14)   GND  GND
```

| 기호 (회로도) | 부품 | 값 / 품번(안) | 역할 |
|---|---|---|---|
| U7, U8 | 출력 DAC | **TI DAC8760IPWP** (16-bit, 4–20/0–20/0–24 mA, 0–5/0–10 V), HTSSOP-24 | 출력 생성. 내장 기준전압, 영점·이득 교정 레지스터. 단선·단락·과열 → ALARM. **핀 번호는 데이터시트(SBAS528D) 기준으로 확정** (v0.7, VibrationSensor IVS320과 같은 심볼) |
| U9, U10 | 오결선 보호 스위치 | **TI TPS26611DDFR** (SOT-23-8) | 단자 전압 > +Vs + 0.05–0.3 V 또는 < −0.2–−0.4 V면 5 µs 안에 차단, 정상화 후 21 µs에 자동 복귀. 전류 제한 32 mA(25–40), 65 mA 넘는 급한 과전류는 5 µs 차단. MODE = GND: 100 ms 제한 후 차단, 0.8 s 재시도. RON 7.5 Ω. −Vs = GND, EN 개방(내부 풀업). **SGOOD: Low = 정상** → MCU PC6/PC7 (보호 방식 통일 검토는 보류 — #24) |
| R30, R40 | 펄스 저항 | 10 Ω, 2512, 펄스 정격 | 서지 전류 제한 (전압 모드 오차는 +VSENSE로 보정) |
| D30, D40 | 평탄 클램프 TVS 양방향 | **TI TVS3301DRBR** (SON-8 3×3, 패드 개방) | TPS2661 데이터시트 Fig. 9-14 권장품. 33 V 스탠드오프, **40 V @ 27 A** 클램프 → TPS26611 IN/OUT 절대최대 ±55 V에 여유 (SMAJ33CA는 약 53 V). 누설 ≤ 450 nA(85 °C) |
| C41, C51 | C0G/X7R | 1 nF / 100 V | EFT, RF |
| U12, U13 | **+VSENSE 버퍼** | **TI OPA197IDBVR** (36 V, 레일투레일), SOT-23-5, V+ = VIN_P | 단자 전압(R30 뒤)을 +VSENSE로 전달. 전류 모드에서 +VSENSE 내부 약 60 kΩ로 새는 전류(250 Ω 부하에서 약 0.4 % 오차)를 없앰 (데이터시트 Figure 9-2) |
| R31, R41 | 저항 | 10 kΩ | 버퍼 + 입력 보호 (단자 서지 전류 제한) |
| R32, R42 | **외부 ISET-R** | **15 kΩ 0.1 % 25 ppm/K** | 전류 출력 기준. 내부 저항보다 온도 드리프트가 작음 (펌웨어에서 외부 ISET 선택 비트 설정) |
| C45, C55 | 바이패스 | 100 nF / 50 V | OPA197 V+ |
| R34, R44 | 저항 | 10 Ω | DAC8760 AVDD 직렬 — 데이터시트 10장 CAUTION (전원 상승 1 V/ns 이하). C42·C52 100 nF가 10 Ω 뒤 AVDD 바이패스 |
| C43 | 벌크 | 4.7 µF / 50 V | VIN_P 벌크, 두 채널 공용 (C53 삭제) |

- **DAC8760 미사용 핀 처리:** DVDD-EN = GND (내부 DVDD 레귤레이터 끔, DVDD = +3V3), CLR·CLR-SEL = GND, −VSENSE = GND, BOOST·CMP·HART-IN = 연결 안 함, 방열 패드(EP) = GND.
- **VOUT와 IOUT 결합:** 데이터시트 9.1.1.3처럼 VOUT와 IOUT를 한 출력 단자로 모읍니다 (VibrationSensor IVS320과 같음).
  - 전환 순서: 출력 끄기 → 범위 변경 → 출력 켜기.
- **OPA197 안정도:** 버퍼 출력이 +VSENSE(고임피던스)만 구동하므로 이득 1 안정. 배치 때 +VSENSE 선을 짧게 하고, 필요하면 출력에 작은 직렬 저항 자리를 둡니다 (보드 시험 항목).
- **TPS26611 전압 출력:** 데이터시트 9.1 — TPS26611/12는 전압 출력 보호에도 쓸 수 있음 (확인 완료). RON은 +VSENSE 되먹임 안에 있어 전압 오차로 남지 않음.
- **TPS26611 한계 (시험 항목):** 차단 기준이 "+Vs보다 높은가"이므로, 우리 전원과 같거나 낮은 전압(예: 24 V 전원에 현장 24 V)이 단자에 물리면 차단 대신 32 mA 제한 → 100 ms 뒤 차단 → 0.8 s 재시도로 보호. 그동안 DAC VOUT에 전류가 흐름 → 오결선 매트릭스 시험에서 DAC 온도·복귀 확인.
- **발열 (2채널):** 전류 모드에서 DAC 전원과 부하 전압의 차이가 DAC 안에서 열이 됩니다. 보통(24 V, 20 mA, 250 Ω) 채널당 약 0.38 W, 최악(28 V, 24 mA, 부하 ≈ 0) 채널당 약 0.66 W, 두 채널 약 1.3 W (DAC RθJA 32.9 °C/W → 칩 약 +22 °C). 대책: ① 사양에 최소 부하 250 Ω 권장, ② 쓰지 않는 채널은 출력 끔(OUTEN = 0, 전원 켤 때 기본값), ③ PCB에서 두 DAC를 떨어뜨리고 방열 패드를 바디 쪽 금속으로 방열. 외장 트랜지스터(BOOST)는 시작품 온도 시험 후 판단.

## 4. RS-485부

```
MCU USART2 TX/RX/DE ── THVD2410 (3.3 V, DE 10k 풀다운 R60) ──┬──┬── 커넥터 3 (A, D+)
                        버스 ±70 V 내성                  │  │
                        IEC ESD ±12 kV                 [D4][D5]  양방향 TVS SMAJ40CA ×2 (선택)
                                                         │  │
                                                  ──────┴──┴── 커넥터 2 (B, D−)
```

| 기호 | 부품 | 값 / 품번(안) | 역할 |
|---|---|---|---|
| U11 | RS-485 트랜시버 | **TI THVD2410** (v0.9, THVD2450과 같은 핀·보호, 500 kbps 느린 에지) (±70 V 버스 내성, ±25 V 공통모드, IEC ESD ±12 kV, EFT ±4 kV, 50 Mbps) | 오결선 ±30 V에 손상 없음 |
| D4, D5 | TVS 양방향 (선택) | **SMAJ40CA** (Vc 약 65 V) | 서지 1 kV 대응 보강. **동작 전압이 36 V 이상**이어야 ±30 V 오결선 내성을 해치지 않음 (SM712 같은 저전압 TVS는 쓰지 않음) |
| R5, R6 | 펄스 저항 | 2.2 Ω (선택) | TVS와 트랜시버 사이 전류 분담 |

- 서지 사전시험에서 트랜시버 단독으로 통과하면 D4, D5, R5, R6는 미실장(DNP)으로 원가를 줄입니다.
- 종단 120 Ω은 내장하지 않고, 페일세이프는 트랜시버 내장 기능을 씁니다.
- 기본 통신 설정: 19200 bps 8E1, 주소 1. EE364 호환 모드에서는 9600 8E1, 주소 243.

## 5. 접지와 하우징 (서지 경로)

```
회로 GND ──┬── 1 MΩ ───────┬── 하우징(SUS, 배관을 통해 대지)
           ├── 4.7 nF 2kV ─┤
           └── GDT 230 V ──┘
```

- 하우징은 공정 배관을 통해 대지에 연결됩니다. 회로 GND를 하우징에 직결하면 4–20 mA 수신기와의 접지 루프 문제가 생기므로 **평소에는 분리(플로팅)** 합니다.
- **4.7 nF (2 kV, Y 등급)**: 고주파(EFT, RF)를 하우징으로 흘립니다.
- **1 MΩ**: 정전기 전하를 천천히 방전합니다.
- **GDT 250 V (Bourns 2035-25-SM, 2전극 — LCSC 품번, 이전 2035-23 230 V)**: 선–접지 서지(1 kV) 때만 방전해 회로 전체를 하우징 전위로 묶습니다. 그러면 각 핀의 TVS가 선–선 에너지만 처리합니다.
- **절연 거리:** PCB와 하우징 사이의 연면·공간 거리는 2 mm 이상을 목표로 합니다(GDT 방전 전 1 kV를 견뎌야 함).
- 커넥터 쉘은 하우징에 연결하고, 차폐 케이블 사용을 권장합니다.

## 6. 측정부·MCU (요약)

블록 설계서와 같습니다. 핀 할당(안)은 아래와 같습니다. STM32G0B1CCT3(LQFP48) 기준이며 CubeMX로 확정합니다. 핀 번호는 KiCad 공식 심볼 기준입니다.

| 기능 | MCU 핀 (안) | 상대 부품 |
|---|---|---|
| SPI1 SCK / MISO / MOSI (모드 1) | PA5 / PA6 / PA7 (16/17/18) | ADS1220 |
| **SPI3 SCK / MISO / MOSI** (모드 1) | **PB3 / PB4 / PB5 (42/43/44)** | **PCAP04 전용** (v0.8 — PCAP04 MISO는 PG1 겸용 핀이라 SSN High 때 Hi-Z 보장이 데이터시트에 없음) |
| CS: PCAP04 / ADS1220 | PB0 / PB1 (19/20) | |
| **SPI2 SCK / MISO / MOSI** (AF0, **모드 3**) | **PB13 / PB14 / PB15 (25/26/27)** | DAC8760 ×2 — DIN·SDO 공유, SCLK는 U14 OR 게이트로 DAC별 게이트 (v0.8) |
| **DAC1_LATCH / DAC2_LATCH** | **PB10 / PB11 (22/23)** | U7 / U8 LATCH + U14 SCLK 게이트 |
| ADS1220 DRDY | PB2 (21, EXTI) | |
| PCAP04 INTN | PB12 (24, EXTI) | |
| USART2 TX / RX / DE | PA2 / PA3 / PA1 (13/14/12) | THVD2410 D / R / DE+/RE, DE 10 k 풀다운 (자체 부트로더, 결정 #31) |
| DAC_ALARM (두 채널 wired-OR, R33 10 k 풀업) | PB6 (45) | DAC8760 오픈 드레인 — 채널은 상태 레지스터로 구분 |
| TPS26611 SGOOD ×2 (Low = 정상) | **PA0 / PA4 (11/15)** (v0.9) | High 2.0–3.0 V라 ADC로도 판정 가능, EXTI 0·4 (충돌 없음) |
| PCAP04 CS | **PA15 (37)** (v0.9, 이전 PB0) | 100 k 풀업 R13 |
| VIN_SENSE (VIN_P / 11) | **PB0 (19, ADC_IN8)** (v0.9) | 32.6 V → 2.96 V |
| DAC LATCH 풀업 · ADS1220 CS 풀업 | R10/R11 10 k, R12 100 k | 리셋 중 입력 고정 |
| TPS2660 FLT | PB7 (46, 내부 풀업) | |
| (상태 LED 삭제) | PB5 (44) 미사용 | 몰딩 후 보이지 않아 삭제 (#22). 상태는 Modbus로 |
| SWD | PA13 / PA14 (35/36), NRST = PF2 (10) | 생산 기록용 패드. M0+라 SWO 없음 |
| BOOT0 | PA14와 공유, 풀다운 없음 | 옵션 바이트 nBOOT_SEL=1, nBOOT0=1 → 플래시 부팅 |

### DAC SPI — SCLK 게이트 방식 (결정 #26, 회로도 v0.8)

v0.7의 데이지 체인은 **DAC8760 데이터시트 Rev D(2021-12)에서 기능이 삭제**되어(DCEN 비트 → Reserved) 쓰지 않습니다. 데이터시트 8.5.1.5: "LATCH가 통신을 게이트하지 않으므로 SCLK를 게이트하지 않고 여러 개를 병렬 연결하지 말 것" (Fig. 8-9).

- 배선: DAC_MOSI → U7·U8 DIN (공유), U7·U8 SDO → DAC_MISO (공유 — SDO는 LATCH 상승 뒤 3-state, t20 35 ns), **DACn_SCLK = DAC_SCK OR DACn_LATCH** (U14 SN74LVC2G32).
- **SPI2 모드 3** (CPOL = 1, CPHA = 1): SCK가 High로 쉬므로 LATCH가 내려가고 올라갈 때 OR 출력에 여분의 클록 에지가 생기지 않음. DAC는 SCLK 상승에서 DIN을 읽고, SDO는 하강에서 바뀌어 상승에서 유효 → 모드 3와 맞음.
- 쓰기: LATCHn Low → 24비트 → LATCHn High (그 DAC만 갱신). 두 채널을 거의 동시에 바꾸려면 연달아 두 번 씀.
- ALARM: 오픈 드레인 두 개를 한 선(DAC_ALARM)으로 묶고 R33 10 kΩ 풀업(데이터시트: 외부 10 kΩ 필요). 어느 채널인지는 상태 레지스터를 읽어 확인.
- 펌웨어: 제어 레지스터 REXT = 1 (외부 ISET-R R32/R42 사용), 쓰지 않는 채널 OUTEN = 0.

### 5A. 부품 정리 (결정 #22, 회로도 v0.6) — 91 → 75개

| 삭제 | 이유 |
|---|---|
| R11–R15 풀업 10k ×5 | v0.8: PWR_FLT만 MCU 내부 풀업(PB7). TPS26611 SGOOD는 푸시풀이라 풀업 불필요. DAC ALARM은 데이터시트대로 외부 10 k 1개(R33) |
| D3 LED + R16 | 전체 몰딩 후 보이지 않음. 상태는 Modbus 레지스터 |
| R60·R61, D60·D61 (RS-485) | THVD2450 자체 ±70 V·IEC ESD 보호. 몰딩 후 선택 장착 불가 |
| FB2 + C19 (VREF+ 필터) | MCU ADC는 측정에 안 씀 (내부 온도센서·진단만). VREF+ = +3V3, C20 100 nF |
| C11 (LDO 입력) | 바로 옆 벅 출력 C10 22 µF가 겸함 |
| C2 (eFuse 앞 10 µF), C6 (eFuse 뒤 100 nF) | C1(앞), C5·C7(뒤)과 역할 겹침 |

v0.8 처리: R7 삭제(IMON 개방 허용), R22 삭제(RTN–GND 연결 금지), C53 삭제(C43 공용), C26 삭제(PCAP04 VDD18 1핀), R33 용도 변경(ALARM 풀업). 남은 후보: D2+R1 (서지 시험), R31·R41 (전류 전용 출력 확정 시), 지지링 M-106 (몰딩 전 취급).

### 5B. PCB 내부 온도 측정 (결정 #23) — 부품 추가 없음

| 측정점 | 방법 | 위치 | 용도 |
|---|---|---|---|
| **앞쪽 (측정부)** | **ADS1220 내부 온도센서** (TS 모드, 14비트, 0.03125 °C/LSB, 정확도 데이터시트 확인) | J3·PCAP04·기준저항 R19·기준 C22 옆 | 측정 회로 드리프트 보상: R19(5 ppm/°C), C22(C0G), PCAP04 내부 오프셋, 하네스·커넥터 리드 저항 온도 변화 |
| **가운데 (MCU·전원·출력)** | **STM32G0 내부 온도센서** (ADC TS 채널, 공장 교정값 TS_CAL1/TS_CAL2, 주소는 RM0444 확인) | MCU (x 41) — 벅·DAC 사이 | DAC 출력 드리프트 보상, 전자부 과열 경보 (예: 85 °C 경고, 105 °C 알람), 수명 기록 |

- **측정 순서 (펌웨어):** ADS1220은 Pt1000 변환 사이에 1초마다 한 번 TS 모드로 바꿔 읽습니다. MCU 온도는 ADC로 1초마다 읽고 이동 평균합니다.
- **보상 방법:** 교정 때 전자부만 온도 챔버에서 2~3점(예: 25·60·85 °C)으로 돌려, "보드 온도 → aw·온도·출력 오차" 계수를 구해 EEPROM(플래시)에 저장합니다. 몰딩 경화 후에 교정합니다.
- **Modbus:** 보드 온도 2개를 입력 레지스터로 공개하고, 과열 상태 비트를 둡니다.
- 정밀도가 더 필요하면(±0.1 °C) 디지털 센서(예: TMP117) 1개를 추가할 수 있습니다. 지금은 부품 추가 없이 두 내부 센서로 충분하다고 판단합니다.

### 6.0 센서 접속 J3 (결정 #16)

| J3 핀 | 넷 | 상대 | 비고 |
|---|---|---|---|
| 1 | SENS_C1 | PCAP04 PC2 | MK33 전극 |
| 2 | SENS_C2 | PCAP04 PC3 | MK33 전극 |
| 3 | PT_P | ADS1220 AIN0 (IDAC) + R17 → AIN1 | Pt1000 +, 힘/감지 분기점 = J3 패드 |
| 4 | PT_N | R18 → AIN2 + 기준저항 R19 (REFP0) | Pt1000 −, 전류 귀환 |

- 커넥터: **JST SH 1.0 mm 4핀 SM04B-SRSS-TB** (옆 삽입·직각 SMD, 입구 앞쪽), 하네스 W-1 (SHR-04V-S, PTFE AWG30 60 mm)로 HTX99R 커넥터 뒤 핀 4개와 직결 (기구 Rev F: 피드스루 없음, Ø7 관통 통로).
- 배치: J3는 PCB 앞 끝(홀더 뒤, 앞 끝에서 5 mm), **PCAP04는 J3 바로 뒤**에 두어 정전용량 선을 최단으로 합니다. SENS_C1/C2 좌우는 GND 가드 배선.
- 온도 정격: JST SH는 −25 ~ +85 °C → PCB 앞 끝 온도 시험으로 확인 (미결 사항).

### 6.0B 측정부 데이터시트 확인 (결정 #26, v0.8)

- **PCAP04 (ScioSense DS-6):** 실제 QFN24 핀으로 교체. 단일 플로팅 모드(기준 C22 = PC0/PC1, MK33 = PC2/PC3)는 **DC 없는 구동** ("other modes are DC free", 7.2) → MK33 DC 없는 구동 미결 해소. 전원 버퍼 VDD18 **≥ 4.7 µF** (C25), VDD33 **≥ 10 µF** (C24), IIC_EN = GND(SPI), INTN은 레지스터로 PG5(11번)에 연결 → CDC_INT. 미사용 PC4·PC5·PCAUX·PT·PG2–4 개방. 중앙 패드는 GND만(권장: 솔더 적게). **전용 SPI3** (모드 1, 최대 17 MHz @3.0 V).
- **ADS1220 설정 한계:** IDAC 여유 = AVDD − 0.9 V (2.4 V) → **IDAC ≤ 250 µA** (AIN0 노드 = R20 0.25 V + R19 1.005 V + Pt1000 120 °C 0.365 V ≈ 1.62 V). 기준 = 250 µA × R19 4.02 k = 1.005 V (최소 0.75 V 이상). **PGA 이득 ≤ 2** (120 °C Pt1000 0.365 V × 2 = 0.73 V < 1.005 V). SPI 모드 1.

### 6.0A 현장 커넥터 J1 · 샤시 J5 (결정 #18)

- **J1 = JST GH 1.25 mm 8핀 옆 삽입(직각) SM08B-GHS-TB.** 하네스 W-2(GHR-08V-S, PTFE AWG28 60 mm)로 M12 8핀 커넥터와 연결합니다. **J1 핀 n = M12 핀 n**이라 EE364 호환 핀맵(8 V+, 6 GND, 4 OUT1, 5 OUT2, 3 A, 2 B, 1·7 NC)을 그대로 씁니다.
- **J5 샤시 접점:** 전에는 M12 쉘 핀으로 CHASSIS를 받았습니다. 이제 PCB 가장자리 SMD 스프링 접점이 하우징 Ø27 내면에 닿습니다. R2 1 MΩ ∥ C3 4.7 nF Y2 ∥ GDT1은 그대로입니다.
- GH 정격도 −25 ~ +85 °C입니다(SH와 같음). 전자부 온도 확인 항목에 포함합니다.

### 6.1 전압 출력 오차 예산 (3선식, 참고)

| 오차원 | 크기 (0–10 V 기준) |
|---|---|
| DAC8760 총 오차 | 약 0.1 % FS (데이터시트 확인) |
| 보호 소자 직렬 저항 | +VSENSE로 보정 → 무시 |
| 케이블 GND 전압강하 (공급전류 약 20 mA, 10 m, 0.25 mm² 왕복 GND 약 0.7 Ω) | 약 14 mV = 0.14 % FS |
| **다른 채널 부하 전류의 GND 공유분** (전압 모드 10 V / 1 kΩ = 10 mA × 0.7 Ω; 다른 채널이 전류 모드면 최대 24 mA × 0.7 Ω) | 약 7–17 mV = 0.07–0.17 % FS |
| **합계** | **약 0.3–0.4 % FS** (aw 0–1 스케일에서 약 0.004 aw — 센서 정확도 ±0.02 대비 충분히 작음). 전류 모드는 GND 강하 영향 없음 |

## 7. 서지·오결선 시험 계획 (사전시험)

| 시험 | 방법 | 합격 기준 |
|---|---|---|
| 오결선 매트릭스 | 8핀 중 모든 핀 쌍(28조합)에 +30 V와 −30 V를 각각 10분 인가 | 손상 없음, 결선을 바로잡은 뒤 정상 측정·통신·출력 |
| 역극성 | V+ ↔ GND −30 V, 1시간 | 손상 없음 |
| 과전압 | V+ 33 V, 1분 (TVS 정격 이내) | 차단 후 정상 복귀 (OVP 32.6 V 부근 개체는 동작 유지 가능) |
| 서지 | 전원 ±1 kV 선–선·선–접지, 신호 ±1 kV 선–접지, 각 5회 | 기준 B |
| EFT / ESD | ±2 kV / 접촉 ±8 kV | 기준 B |
| 출력 단락·단선 | 각 출력 GND 단락, 개방 | ALARM, 복귀 |

## 8. 보호 부품 추가에 따른 원가 변화 (1k, 추정)

| 항목 | 이전 (블록 설계) | 변경 | 증가분 |
|---|---|---|---|
| 전원 보호 | TVS, P-FET, PTC 약 $0.5–1 | TVS 2단 + CM 초크 + TPS2660 | +$2–4 |
| 아날로그 출력 보호 | TVS, PTC | TPS26611 ×2 + TVS + 펄스 저항 | +$2.5–5 |
| RS-485 | THVD1450 $0.6–1.2 | THVD2450 (+ 선택 TVS) | +$1–2 |
| 접지 | RC | + GDT | +$0.3–0.8 |
| **합계** | | | **약 +$6–12** |

→ 전자부 합계는 **약 $36–64**로 올라갑니다([bom-cost.md](bom-cost.md) 갱신).

## 9. 남은 확인 사항

1. ~~TPS26611이 0–10 V 전압 출력을 통과시키는지~~ → 데이터시트 9.1로 확인 (v0.8). DAC8760 VOUT/IOUT 결합은 데이터시트 9.1.1.3으로 확정 (v0.7)
2. TPS2660의 정확한 절대최대정격과 SMBJ33CA 클램프 전압 사이의 여유 (서지 시뮬레이션)
3. THVD2450 단독 서지 내성 → 외부 TVS(D4, D5) 실장 여부
4. 7번 핀을 NC로 되돌리는 것 (위 1.1절 제안)
5. ~~회로도 CAD 도구~~ → **KiCad로 결정**, [hardware/kicad](../../hardware/kicad/README.md)에 v0.1 회로도 작성

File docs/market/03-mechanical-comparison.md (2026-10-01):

# 외형·장착 방식 비교 — HMT500(260313) vs Vaisala · E+E

작성 2026-09-30 · 우리 제품 = 기구 Rev H (`hardware/mech/hmt500_params.py`에서 계산)

> **자료 출처와 신뢰도:** E+E EE364는 사용자가 준 원문 데이터시트 v1.13(`docs/reference/ee364-summary.md`)입니다. Vaisala MMT162·MMP8과 E+E EE381은 웹 검색으로 본 데이터시트 요약이며, 제조사 PDF 원문은 이 작업 환경에서 열리지 않았습니다. **(확인 필요)** 값은 원문으로 다시 확인해야 합니다. 찾지 못한 값은 "–"로 두었습니다.

## 0. 외형 비교 도면

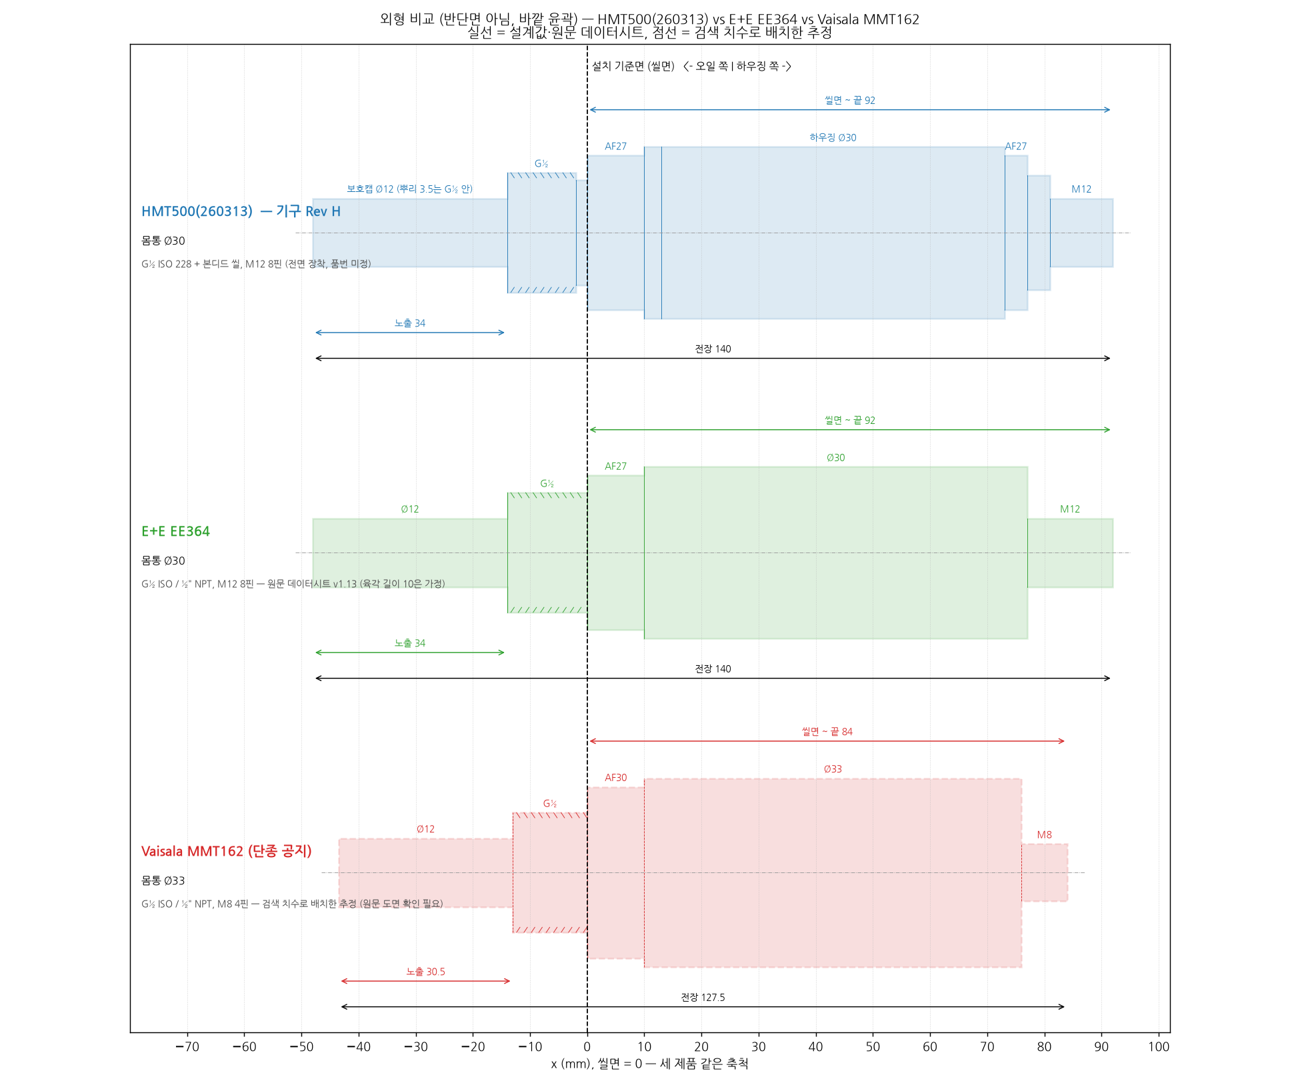
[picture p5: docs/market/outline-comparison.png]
외형 비교


같은 축척, 설치 기준면(씰면) 정렬. 실선은 설계값·원문 데이터시트, 점선(MMT162)은 검색 치수로 배치한 추정입니다. EE364·MMT162의 육각 길이는 10으로 가정했습니다. 생성: `python docs/market/make_outline_comparison.py`

## 1. 한 줄 비교

| | **HMT500(260313)** | E+E **EE364** | Vaisala **MMT162** | Vaisala **MMP8** | E+E **EE381** |
|---|---|---|---|---|---|
| 형태 | 일체형 봉 모양 트랜스미터 | 일체형 봉 모양 트랜스미터 | 일체형 소형 트랜스미터 (OEM) | 삽입 깊이 조절형 프로브 + 케이블 | 다이캐스트 하우징 트랜스미터 |
| 상태 | 개발 중 | 판매 중 | **단종 공지** (확인 필요) | 판매 중 (MMT162 후속 계열) | 판매 중 |

## 2. 외형 치수 (mm)

| 항목 | **HMT500** | **EE364** (G½) | **MMT162** (G½) | **MMP8** | **EE381** |
|---|---|---|---|---|---|
| 전장 | **140** | 140 | 127.5 (확인 필요) | 프로브 262 / 448 + 케이블 | – |
| 몸통 외경 | **Ø30** (하우징) | Ø30 | Ø33 (확인 필요) | Ø12 프로브 | 사각 다이캐스트 |
| 프로브 외경 | **Ø12** (보호캡, 뿌리 3.5 mm는 G½ 안에 묻힘) | Ø12 | – | Ø12 | Ø12 |
| 노출 프로브 (끝 ~ 나사 시작) | **34** | 34 | – | 삽입 깊이 35–193 / 35–379 조절 | – |
| 씰면 ~ 커넥터 끝 | **92** (엔드캡 끝 77 + 커넥터 15) | 92 (하우징 끝 77 + 커넥터 15) | – | – (케이블) | – |
| 설치 육각 | **AF27 × 10** (+ 엔드캡 맞변 AF27) | AF27 | AF30 (확인 필요) | 피팅 바디 | AF27 또는 AF24 |
| 무게 | 약 **285 g** 추정 (금속 242 g + 몰딩·전자부) | – | 200 g | 510 g / 610 g (케이블 2 m 포함) | – |

## 3. 장착·연결

| 항목 | **HMT500** | **EE364** | **MMT162** | **MMP8** | **EE381** |
|---|---|---|---|---|---|
| 공정 연결 | **G½-A (ISO 228-1)** + 본디드 씰 | G½ ISO / ½" NPT | G½ ISO / ½" NPT | ISO ½" / NPT ½" 피팅 (볼밸브 설치 가능) | G½ ISO / ½" NPT |
| 장착 방식 | 나사 체결, 육각 AF27로 조임. 프로브 고정 깊이 | 나사 체결, 고정 깊이 | 나사 체결, 고정 깊이 | 피팅에서 **삽입 깊이 조절**. 공정 중 탈착 가능 (볼밸브) | 나사 체결, **앞부분 회전** 가능 |
| 전기 연결 | **M12 8핀** (수컷, 전면 장착 — 품번 확정 전) | M12×1 8핀 | **M8 4핀** | M12 5핀 A-코딩 (케이블 일체) | 케이블 글랜드 / 단자 (확인 필요) |
| 커넥터 방향 | 축 방향 (뒤) | 축 방향 (뒤) | 축 방향 (뒤) | 케이블 끝 | 하우징 측면 |
| 하우징 재질 | **SUS316L** (시제품 SUS304) | SUS 1.4404 (316L) | 316L (금속형) / 플라스틱형 있음 | 316L, 케이블 FEP | 알루미늄 다이캐스트 |
| 보호 등급 | IP67 목표 (내부 전체 에폭시 몰딩, 시험 전) | IP65 | IP66 | IP66 | IP65 |
| 센서 교체 | **센서 프로브 교체형** (HTX99R 소켓에 꽂음, 필터 캡만 풀면 됨) | 교체 불가 (필터만 교체) | 교체 불가 | 프로브 단위 교체 | 교체 불가 |

## 4. 사용 조건·전기

| 항목 | **HMT500** | **EE364** | **MMT162** | **MMP8** | **EE381** |
|---|---|---|---|---|---|
| 압력 | 정격 **50 bar** (시험 75 bar), 200 bar형 별도 검토 | 0–20 bar | 최대 200 bar (금속형) | 0–40 bar abs | 20 bar / 100 bar |
| 오일 온도 | −40~120 °C 목표 (JST 커넥터 온도 시험 필요) | −40~80 °C (옵션 100) | −40~80 °C | 헤드 −40~180 °C, 몸체 −40~80 °C | −40~120 °C |
| 전원 | **12–28 V DC (최대 28 V)** | 10–28 V DC | 14–28 V (RS-485), 22–28 V (전류 출력) | 15–30 V DC | – |
| 출력 | **4–20 mA × 2 + RS-485 Modbus RTU**, RL ≤ 500 Ω (V+ ≥ 18 V) | 4–20 mA × 2 (3선) + RS-485 Modbus RTU | 아날로그 × 2 + RS-485 | RS-485 Modbus RTU만 (아날로그는 Indigo 변환기로) | 아날로그 × 2, 스위치, LCD 옵션 |
| 측정량 | aw, T, ppm | aw, T, ppm | aw, T, ppm (변압기유) | aw, %RS, T, ppm | aw, T, ppm |

## 5. 차이 요약

1. **설치 호환성:** 공정 연결(G½)과 육각(AF27), 프로브 Ø12는 EE364와 같습니다. 같은 자리에 그대로 달 수 있습니다. MMT162와도 G½로 호환되지만, MMT162는 M8 4핀이라 배선을 바꿔야 합니다.
2. **크기 (기구 Rev H):** 부위별로 EE364와 **같은 치수**입니다 — 노출 프로브 Ø12 × 34, G½ 14, 육각 AF27 × 10, 몸통 Ø30, 씰면 ~ 하우징 끝 77, M12 15, 전장 140. 보호캡 뿌리 3.5 mm는 G½ 앞면 안에 묻혀 캡이 옆으로 젖혀져도 HTX99R 커넥터가 깨지지 않습니다.
3. **내압·온도:** 50 bar, 120 °C는 EE364(20 bar, 80 °C)보다 높고, MMT162(200 bar)와 MMP8(180 °C 헤드)보다는 낮습니다.
4. **차별점:** 센서 프로브를 현장에서 교체할 수 있습니다(필터 캡 → 프로브). 턴버클 구조라 조립할 때 커넥터 방향이 돌아가지 않고, 내부 전체를 몰딩해 진동·습기에 강합니다.
5. **약점·확인할 것:** 무게(추정), IP67은 시험 전, M12 커넥터 품번 미정.

## 출처

- E+E EE364 원문 데이터시트 v1.13 요약: `docs/reference/ee364-summary.md`
- Vaisala MMT162: [datasheet (Vaisala docs)](https://docs.vaisala.com/api/khub/documents/YSymU_tZFpXIeT7iCO4lPQ/content), [datasheet B210755EN](https://www.enr.com/ext/resources/custom-content/Infocenter/2017/Vaisala/CEN-G-MMT162-Datasheet-B210755EN-1.pdf), [iag.co.at MMT162 2022](https://www.iag.co.at/fileadmin/user_upload/MMT162.en_2022.pdf)
- Vaisala MMP8: [datasheet B211795EN-E](https://docs.vaisala.com/api/khub/documents/xqzpNv8Ulq2jC17re2vk1Q/content), [product page](https://www.vaisala.com/en/products/instruments-sensors-and-other-measurement-devices/instruments-industrial-measurements/mmp8), [spec sheet (Kenelec)](https://www.kenelec.com.au/wp-content/uploads/2022/05/Vaisala-MMP8-Moisture-in-Oil-Probe-SpecSheet-revB-2021.pdf)
- E+E EE381: [datasheet](https://www.epluse.com/fileadmin/data/product/ee381/datasheet_EE381.pdf), [DirectIndustry](https://www.directindustry.com/prod/e-e-elektronik/product-13965-1251115.html)
- 경쟁 제품 조사: `docs/market/02-competitors.md`

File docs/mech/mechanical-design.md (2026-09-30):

# 기구 설계안 v0.2 — HMT500 (EE364형 일체형)

작성일: 2026-09-26 · 상태: 개념 설계 (시제품 전, 치수는 설계안)

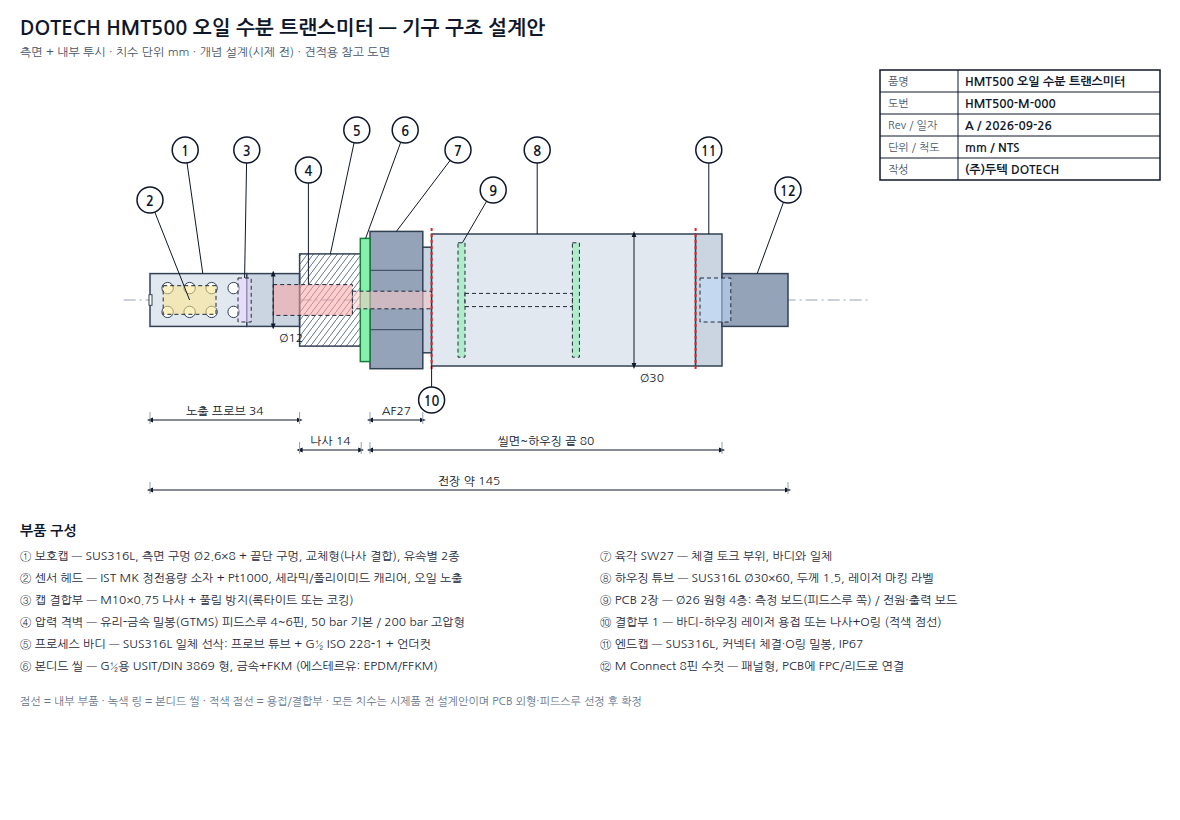
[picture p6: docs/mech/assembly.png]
기구 구조도


> **Rev E 제작 도면·3D CAD (2026-09-29):** [hardware/mech](../../hardware/mech/README.md)
> — 조립도·부품도 PDF(A3 4장), STEP(조립품·가공부품 6종), 렌더.
> 이 개념안(v0.2)에서 달라진 점:
> - 바디–하우징, 하우징–엔드캡은 **M28×1 나사 + 반경 O링(25×2 FKM)** 으로 결합합니다. 4.6절의 "양산 레이저 용접"은 쓰지 않고, 용접은 피드스루 한 곳만 남깁니다.
> - 하우징 외경은 **Ø32**입니다. Ø30이면 나사와 O링 자리의 벽 두께가 부족합니다.
> - 전장 144 mm로, 씰면에서 엔드캡 끝까지 81 mm, 커넥터 끝까지 96 mm입니다.
> - 커넥터는 엔드캡 M16×1.5 구멍에 **바깥에서** 장착해 리드선이 꼬이지 않게 합니다. 엔드캡은 평면 AF28로 잡고 체결합니다.
> - 보호캡 나사는 M10×0.75입니다.
> - **Rev D/E:** 센서 접속은 두텍 HTX99R 센서 커넥터(4핀, M10×0.75 나사 2곳)입니다. 교체형 센서 프로브를 꽂고, 커넥터는 바디 암나사에 체결합니다. 보호캡(**Ø12**)은 커넥터 위 나사에 체결하고, 바디 튜브는 Ø14입니다. 피드스루는 바디 뒤쪽으로 옮겼습니다.
> - **센서–PCB 연결:** HTX99R 뒤 핀에서 PCB까지 **하네스 W-1 + JST SH 1.0 mm 4핀**(J3 SM04B-SRSS-TB, 옆 삽입)으로 직결합니다. PCB를 플러그만 뽑아 분리할 수 있습니다(결정 #16).
> - **내부 몰딩·턴버클 (결정 #20):** 하우징 안 전체를 상온경화 에폭시 1종으로 몰딩하고(엔드캡 M3 주입·공기 구멍), 엔드캡은 M28×1 왼나사로 바꿔 하우징만 돌려 체결합니다(턴버클). 하네스가 꼬이지 않습니다.
> - **Rev F (결정 #17):** 보호캡은 두텍 **SUS 오일 필터 390000-001100**(Ø12 × 32, M10×1.0)을 씁니다. **피드스루를 없앴습니다.** 바디 Ø7 통로는 관통이고 하네스만 지나가며, 통로(pass-through)는 케이블을 넣은 뒤 에폭시로 몰딩(1차 격벽)하고, 압력 격벽은 HTX99R 커넥터(O링 + 몰드 핀) + 에폭시입니다. M12 커넥터도 하네스 W-2 + JST GH 8핀(J1)으로 PCB에 연결합니다(결정 #18). 노출 프로브 48 mm, 전장 158 mm. 아래 3~5절의 피드스루 관련 내용은 초기 검토안입니다.
> - 전자부는 원형 PCB 2장 대신 **축 방향 긴 PCB 1장(57 × 23)** 입니다. 앞쪽은 바디에 나사로 고정한 수지 홀더에, 뒤쪽은 지지링에 끼웁니다(Rev C).

**견적용 자료:** [HMT500 기구설계 견적 요청서 (PDF)](HMT500_RFQ.pdf) · [도면 HMT500-M-000 (PDF)](HMT500-M-000.pdf)

원본: [assembly.svg](assembly.svg) · 생성 스크립트: [make_drawing.py](make_drawing.py) (치수를 바꾸면 다시 실행)

---

## 1. 목표와 전제

| 항목 | 목표 | 근거 |
|---|---|---|
| 형태 | 보호캡 → 프로브 → G½ 나사 → 본디드 씰 → 육각 → 원통 하우징 → 커넥터 일체형 | 구조 참고: E+E EE364 (두텍 제품 아님) |
| 공정 연결 | **G½ ISO 228-1** + 본디드 씰 (옵션: ½" NPT) | EE364, 경쟁 제품 공통 |
| 압력 | **50 bar 기본 / 200 bar 고압형** | 경쟁 조사: EE364 20 bar는 약함, HYDAC·ifm 50 bar, Vaisala 200 bar |
| 오일 온도 | **−40 ~ +120 °C** | EE364 80 °C보다 높게 |
| 보호 등급 | IP67 (커넥터 체결 상태) | |
| 접액부 재질 | SUS316L | |
| 센서 | IST MK 계열 + Pt1000 | 공급 중 |
| 커넥터 | M Connect 8핀 | 결정 사항 |
| 전자부 | 원형 PCB 2장(Ø26) | [하드웨어 설계](../hw/hardware-block-design.md) |

## 2. EE364 원문 치수 (데이터시트 v1.13)

사용자가 제공한 데이터시트 원문 치수입니다. 상세 내용은 [EE364 원문 요약](../reference/ee364-summary.md)에 있습니다.

| 부위 | EE364 (G½ ISO형) | 우리 설계안 v0.2 | 비고 |
|---|---|---|---|
| 노출 프로브 (끝 ~ 나사 시작) | 34, Ø12 | **34, Ø12** | 같은 삽입 깊이로 교체 설치 가능 |
| 나사 | G½, 14 | **G½ ISO 228-1, 14** | |
| 육각 | AF27 | **AF27 × 12** | 같은 공구 |
| 씰면 ~ 하우징 끝 | 77 | **80** | 압력 격벽(GTMS)과 PCB 2장 공간 확보 |
| 씰면 ~ 커넥터 끝 | 92 | **95** | |
| 하우징 외경 | Ø30 | **Ø30** | |
| 전장 | 140 | **약 145** | |
| 압력 / 오일 온도 / IP | 20 bar / 100 °C(옵션) / IP65 | **50·200 bar / 120 °C / IP67** | 사양 우위 |
| 재질 | 316L (1.4404) | 316L | |

→ **설치 치수(삽입 깊이, 나사, 육각, 외경)를 EE364와 같게** 두어 기존 설치 위치에 그대로 교체할 수 있게 했습니다. 뒤쪽 길이는 약 3 mm 더 깁니다.

## 3. 설계안 치수 (구조도 기준)

| 번호 | 부품 | 치수 / 사양 |
|---|---|---|
| ① | 보호캡 | Ø12 × 22, 측면 구멍 Ø2.6 × 8 + 끝단 구멍. **나사로 결합하는 교체형**. EE364처럼 유속별 2종(< 1 m/s, > 1 m/s), 옵션으로 소결 필터 |
| ② | 센서 헤드 | MK 소자 + Pt1000을 한 캐리어에 실장 (약 12 × Ø6.5 공간). 오일에 직접 노출 |
| ③ | 캡 결합부 | M10×1.0 (가는 나사) + 풀림 방지 — Rev G 확정 |
| ④ | 압력 격벽 | 프로브 튜브에서 나사 구간까지. 4~6핀 피드스루 |
| ⑤ | 프로세스 바디 | SUS316L 일체 선삭: 프로브 튜브(Ø12) + G½ 나사(14) + 언더컷 |
| ⑥ | 본디드 씰 | G½용 (내경 약 21.5, 외경 약 28.7) |
| ⑦ | 육각 | AF27 × 12, 바디와 일체 |
| ⑧ | 하우징 | Ø30 × 60, 두께 1.5 → 내경 27. PCB Ø26 수납 |
| ⑨ | PCB | Ø26 원형 4층 2장, 간격 약 25 |
| ⑩ | 바디–하우징 결합 | 4.6절 참고 |
| ⑪ | 엔드캡 | Ø30 × 6, 커넥터 체결, O링 |
| ⑫ | M Connect 8핀 | 패널형 수컷, 돌출 약 15. 핀맵은 EE364와 동일(원문 확인) |
| | **전장** | **약 145** |

## 4. 핵심 설계 이슈

### 4.1 압력 격벽 — 가장 중요

오일 압력(50~200 bar)을 받는 쪽(센서 헤드)과 전자부를 **완전히 분리하는 격벽**이 있어야 합니다. 격벽이 새면 오일이 하우징 안으로 들어가 전자부가 고장 납니다.

| 방식 | 장점 | 단점 | 판단 |
|---|---|---|---|
| **유리-금속 밀봉(GTMS) 피드스루** | 200 bar 이상, 고온, 헬륨 리크 수준 기밀. 산업 표준 | 부품 단가가 높고(수~십수 달러), 리드타임과 용접이 필요 | **기본안** (특히 200 bar형) |
| 에폭시 포팅 + 백업 링 | 저렴하고 공정이 단순 | 온도 사이클에서 박리 위험, 장기 기밀 불확실 | 50 bar 저가형에 한해 검토, 반드시 시험 검증 |
| 세라믹 기판 브레이징 | 소형, 고신뢰 | 전문 협력사 필요 | 대안 |

- 피드스루는 바디에 **레이저 용접 또는 압입 + 용접**으로 고정합니다.
- 핀 수: MK 소자 2 + Pt1000 4선 = 6핀. 3선으로 줄이면 5핀. 가드 차폐를 쓰면 +1핀.
- 피드스루 바로 뒤에 측정 보드(PCAP04)를 두어 배선을 최단으로 합니다.

### 4.2 센서 헤드 고정

- MK 소자와 Pt1000을 작은 캐리어(세라믹 또는 폴리이미드 FPC)에 붙이고, 피드스루 핀에 용접이나 납땜으로 연결합니다.
- 오일 흐름과 진동에 견디도록 캐리어를 고정합니다. 소자 표면(감지막)은 막지 않습니다.
- 소자 사이의 열결합을 위해 Pt1000을 MK 소자 바로 옆에 둡니다(ppm 환산 정확도).
- **필요 자료: 공급받는 MK 소자의 외형 도면과 리드 형태.**

### 4.3 보호캡

- 역할: 유속과 이물질로부터 소자를 보호하되, 오일은 원활하게 교환되게 합니다(응답시간).
- 구멍 총면적과 응답시간 T63을 시험해서 정합니다. 기본안은 Ø2.6 × 8개 + 끝단 구멍입니다.
- 교체형 캡 옵션: 소결 필터(40 µm급)를 넣은 캡은 오염이 심한 유압유용입니다.

### 4.4 밀봉과 씰 재질

| 위치 | 씰 | 재질 |
|---|---|---|
| 공정 연결 (G½) | 본디드 씰 | 금속 + **FKM** (기본), 에스테르유·인산에스테르 유압유는 EPDM 또는 FFKM |
| 하우징 결합부 (나사식일 때) | O링 | FKM 또는 NBR (오일 비접촉) |
| 엔드캡 / 커넥터 | O링, 커넥터 자체 씰 | FKM 또는 NBR |

- 씰 재질은 **대상 오일과의 호환성 표**를 만들어 주문 옵션으로 둡니다.

### 4.5 열 관리

- 오일 120 °C에서 전자부는 85 °C 이하로 유지해야 합니다(부품 정격).
- 열 경로: 오일 → 바디(나사, 육각) → 넥 → 하우징 → 주위 공기.
- 넥(육각과 하우징 사이 얇은 부분)과 하우징 표면적으로 열을 뺍니다. 필요하면 **확장 넥 옵션**(+30~50 mm)을 둡니다.
- 전자부 발열(아날로그 출력 최대 약 1.4 W)도 더해지므로 **열해석 또는 열시험이 필요**합니다.

### 4.6 바디–하우징 결합 (⑩)

| 방식 | 장점 | 단점 |
|---|---|---|
| 나사 + O링 | 분해·수리가 가능하고 시제에 유리 | 풀림 방지 필요, 부피 약간 증가 |
| **레이저 용접** | 밀봉·강성 우수, 외관이 깔끔(EE364와 비슷) | 분해 불가, 용접 설비·협력사 필요 |

→ ~~시제품은 나사 + O링, 양산은 레이저 용접~~ → **Rev B: 시제품과 양산 모두 나사(M28×1) + 반경 O링**으로 확정했습니다. 수리할 수 있고 용접 설비가 필요 없습니다.

### 4.7 EMC와 접지

- 하우징(SUS)을 커넥터 쉘과 연결하고, 차폐 케이블로 현장 접지에 연결합니다.
- PCB GND와 하우징은 RC(1 MΩ ∥ 4.7 nF)로 결합합니다(하드웨어 설계 1.7절).

## 5. 조립 순서 (안)

1. 바디(⑤)에 피드스루(④)를 레이저 용접한 뒤, **헬륨 리크 시험과 내압 시험**을 합니다.
2. 센서 헤드(②)를 피드스루 핀에 연결하고 고정합니다.
3. 보호캡(①)을 체결합니다(나사, 풀림 방지).
4. (Rev F) W-1 플러그를 PCB 홀더 Ø6 구멍에 통과시키고 홀더를 바디에 고정합니다. PCB(⑨)를 홀더에 끼워 고정하고 W-1 플러그를 J3(JST SH 4핀)에 꽂습니다. 뒤쪽에 지지링을 끼웁니다.
5. 하우징(⑧)을 나사로 결합합니다(M28×1 + O링, 나사 고정제).
6. 리드선을 엔드캡(⑪) 구멍에 통과시켜 엔드캡을 체결하고, 커넥터(⑫)를 바깥에서 체결합니다.
7. RS-485로 펌웨어를 기록하고 교정합니다(습도 교정 → 아날로그 출력 교정).
8. 기능 시험, IP67 시험(샘플), 라벨 레이저 마킹을 합니다.

## 6. 시험 항목 (기구)

| 시험 | 조건 (안) |
|---|---|
| 내압 | 정격의 1.5배: 50 bar형 75 bar, 200 bar형 300 bar, 유지 후 누설 없음 |
| 파열 | 정격의 4배 이상 목표 (샘플) |
| 기밀 | 피드스루 헬륨 리크 ≤ 1×10⁻⁸ mbar·l/s (GTMS 기준, 협력사 사양 확인) |
| 압력 사이클 | 유압용: 0 ↔ 정격, 10⁵~10⁶ 회 |
| 방진·방수 | IP67 (IEC 60529) |
| 진동·충격 | IEC 60068-2-6 / -27 |
| 열충격·온도 사이클 | 오일 −40 ↔ 120 °C, 전자부 온도 측정 포함 |
| 체결 | G½ 체결 토크 시험, 씰 재사용성 |

## 7. 기구 원가 개략 (1,000대, 추정)

| 부품 | 추정 단가 |
|---|---|
| 프로세스 바디 (SUS316L 선삭, 나사, 육각) | $8 ~ 15 |
| 하우징 튜브 | $3 ~ 6 |
| 엔드캡 | $2 ~ 4 |
| 보호캡 | $2 ~ 4 |
| 피드스루 (GTMS 5~6핀) | $5 ~ 15 |
| 본디드 씰, O링 | $0.5 ~ 1.5 |
| 레이저 용접, 마킹, 리크 시험 공수 | $3 ~ 8 |
| **기구 합계** | **약 $24 ~ 54** |

전자부(약 $36~64, [bom-cost.md](../hw/bom-cost.md))와 합하면, 센서와 커넥터를 뺀 재료·가공비는 **약 $60~118**입니다. 모두 추정이며, 가공 협력사 견적으로 확정해야 합니다.

## 8. 주의: 지식재산권

- 외형을 EE364와 똑같이 만들면 **디자인권 침해 위험**이 있습니다. E+E의 한국·유럽 디자인 등록 여부를 확인해야 합니다(KIPRIS, EUIPO).
- 설계안에는 차별 요소를 넣었습니다: 교체형 보호캡, 50/200 bar, 120 °C, 하우징 비율과 표면 처리. 하우징에 평면 가공(렌치 면이나 라벨 면)이나 두텍 고유의 외관 요소를 추가하는 것을 권장합니다.
- 기능이 같은 구조(G½, 육각, 원통 하우징, M12)는 업계 공통 형태라 문제가 되지 않을 가능성이 높습니다. 다만 최종 판단은 변리사 확인이 필요합니다.

## 9. 확정에 필요한 자료

1. **IST MK 소자 외형 도면**(리드 형태, 치수, 권장 실장 방법)
2. **M Connect 8핀 품번**(패널 체결 나사, 설치 깊이, PCB 연결 방식)
3. 압력 등급: 50 bar 한 가지로 할지, 50/200 bar 두 가지로 할지
4. 최대 오일 온도: 120 °C로 확정할지, 확장 넥 옵션을 둘지
5. 프로브 길이 옵션: 표준형만 할지, 긴 프로브(예: 100/200 mm, 변압기·탱크용)도 둘지
6. 가능하면 EE364 실물 1대(분해해서 내부 격벽·센서 고정 방식 확인용)

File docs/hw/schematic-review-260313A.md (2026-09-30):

# HMT500(260313A) 회로도 검토 — 데이터시트 대조 · 최적화 계획

**상태: A–O 전부 실시 완료 (2026-09-30, 회로도 v0.8, 결정 #26).** 전원 범위 12–28 V 승인.

작성 2026-09-30 · 대상 회로도 v0.7 (82 부품, 70 넷)

## 1. 대조 자료

제조사 데이터시트 원문 (다운로드해 대조, 저장소에는 넣지 않음):

| 부품 | 문서 |
|---|---|
| LMR36006 | TI SNVSB48C (2019-10) |
| TPS2660 | TI SLVSDG2G (2019-12) |
| TPS2661x | TI SLVSFE3C (2021-12) |
| DAC8760 | TI SBAS528D (2021-12) |
| ADS1220 | TI SBAS501D |
| THVD2450 | TI SLLSF20B |
| TPS7A20 | TI 데이터시트 |
| OPA197 | TI SBOS737C |
| PCAP04 | ScioSense SC-001050-DS-6 (2023-09) |
| STM32G0B1 | st.com 접속 불가 → KiCad 공식 심볼 STM32G0B1C_B-C-E_Tx로 대조 |

## 2. 핀 대조 결과

| 부품 | 결과 |
|---|---|
| STM32G0B1CCT3, ADS1220, TPS7A2033, OPA197, THVD2450, DAC8760 | ✅ 일치 |
| TPS2660 | ⚠ 핀 번호 일치. 17번 = PowerPAD → **RTN 면에 연결** (이름 EP → RTN) |
| LMR36006 | ❌ 임시 핀 → 실제 VQFN-HR 12핀: 1 PGND, 2 VIN, 3 NC, 4 BOOT, 5 VCC, 6 AGND, 7 FB, 8 PG, 9 EN, 10 VIN, 11 PGND, 12 SW |
| TPS26611 | ❌ 임시 핀 → 실제 SOT-23-8: 1 GND, 2 MODE, 3 −Vs, 4 IN, 5 OUT, 6 +Vs, 7 EN, 8 SGOOD |
| PCAP04 | ❌ 임시 핀 → 실제 QFN24: 1 PC3, 2 GND, 3 VDD18, 4 VDD33, 5 PT1, 6 PT0REF, 7 PTOUT, 8 GND, 9 SSN, 10 MISO, 11 PG5, 12 PG2, 13 IIC_EN, 14 VDD33, 15 MOSI, 16 SCK, 17 PG3, 18 PG4, 19 PCAUX, 20 PC4, 21 PC5, 22 PC0, 23 PC1, 24 PC2 |

## 3. 데이터시트로 새로 드러난 문제

| # | 부품 | 데이터시트 내용 | 현재 회로 | 판정 |
|---|---|---|---|---|
| 1 | **TPS2660** | "RTN을 GND에 연결하면 역극성 보호가 꺼지고, 역극성 때 **영구 손상**" (9.3.5.5). R3–R5·ILIM·dVdT·IMON·MODE는 **RTN 기준** | R22 0 Ω으로 RTN–GND 연결. R5·R6·R7·C4·MODE를 GND에 연결 | **치명** |
| 2 | **TPS26611** | +Vs 권장 **최대 30 V**, 절대최대 32 V | +Vs = VIN_P. OVP 32.6 V(기준 1.19 V로 재계산)까지 올라감 | **정격 초과** |
| 3 | **DAC8760** | Rev D에서 **데이지 체인 기능 삭제**. 여러 개를 한 버스에 쓰려면 **SCLK 게이트** 필요 (8.5.1.5, Fig. 8-9) | v0.7 데이지 체인 | **지원 안 됨** |
| 4 | DAC8760 | AVDD 상승 속도 1 V/ns 이하 → **AVDD에 10 Ω 직렬** 권장 (10장 CAUTION) | 없음 | 추가 |
| 5 | DAC8760 | ALARM은 오픈 드레인, **외부 10 kΩ 풀업 필요** | MCU 내부 풀업 | 추가 |
| 6 | PCAP04 | VDD18 **≥ 4.7 µF**, VDD33 **≥ 10 µF**. VDD18은 1핀 | 1 µF 두 개 (VDD18_D/A 가정) | 수정 |
| 7 | LMR36006 | 5 V·1 MHz 권장값: L = **15 µH**, COUT = 2 × 15 µF, CFF = **20 pF** | L2 22 µH, C10 22 µF 0805 1개, CFF 없음 | 수정 |
| 8 | TPS2660 | I_OL = 12 / R_ILIM(kΩ) → 150 mA = **80.6 kΩ**. IMON은 쓰지 않으면 개방 가능 | R6 값 미정, R7 10 k | 확정·삭제 |
| 9 | PCAP04 | 단일 플로팅·접지 모드는 **DC 없음** ("other modes are DC free") | — | MK33 DC 없는 구동 **미결 해소** |

## 4. 최적화 계획

| # | 내용 | 부품 수 |
|---|---|---|
| A | LMR36006·TPS26611·PCAP04 실제 핀·풋프린트로 교체. LMR36006 = **LMR36006BRNXR** (1 MHz, 조정형 — 고정 출력형 없음). TPS2660 17번 = RTN | 0 |
| B | **TPS2660 RTN 정정:** R22 삭제, R5·R6·C4·MODE → RTN, R7 삭제(IMON 개방), R6 = 80.6 k 1 % (150 mA) | −2 |
| C | **전원 범위 12–28 V로 조정:** R5 36.5 k → 41.2 k → OVP 29.0 V (28.5–29.9 V), UVLO 8.6 V. TPS26611 +Vs 30 V 이내, EE364 전원(10–28 V)과도 맞음 | 0 |
| D | **DAC SPI를 SCLK 게이트 방식으로** (TI Fig. 8-9, IVS320과 같음): 74LVC2G32 1개 + 100 nF, LATCH1 = PB10, LATCH2 = PB11, DIN·SDO 공유(SDO는 LATCH 뒤 3-state). R33·DCEN 삭제 | +1 |
| E | DAC AVDD 10 Ω 직렬 ×2 | +2 |
| F | ALARM 두 개를 한 선으로 묶고 10 kΩ 풀업 1개 → PB3. 어느 채널인지는 상태 레지스터로 확인 | +1 |
| G | TPS26611: −Vs = GND, EN 개방(내부 풀업), MODE = GND (32 mA 제한, 100 ms 후 차단, 800 ms 재시도), SGOOD(0–3 V 출력, **Low = 정상**) → MCU. 넷 이름 OUTn_SGOOD | 0 |
| H | PCAP04: VDD18 4.7 µF 1개 (C26 삭제), VDD33 10 µF, IIC_EN = GND, INTN → PG5(11번, 레지스터로 설정), PTOUT·PT·PCAUX 미사용 개방. 중앙 패드는 GND 외 연결 금지 | −1 |
| I | 벅: L2 15 µH, C10 → 22 µF ×2 (1206 25 V), CFF 20 pF 추가 | +2 |
| J | VIN_P 벌크 4.7 µF 두 개(C43·C53) → 하나 | −1 |
| K | 문서: 전압 모드 오차 예산에 채널 간 GND 공유분 추가, 발열 대책(최소 부하 250 Ω 권장, 미사용 채널 출력 끔, DAC 간격·방열) | 0 |
| L | **출력 TVS 교체:** D30·D40 SMAJ33CA → **TI TVS3301** (TPS2661 데이터시트 Fig. 9-14 권장품). 클램프 40 V(27 A) vs SMAJ33CA 약 53 V — TPS2661 IN/OUT 절대최대 ±55 V에 여유. 누설 450 nA(85 °C)로 4–20 mA 오차도 작음, SON-8 3×3 | 0 |
| M | **PCAP04 전용 SPI3 (PB3/PB4/PB5):** PCAP04 MISO는 PG1 겸용 핀이고, SSN High일 때 Hi-Z라는 기재가 데이터시트에 없음 → ADS1220과 SPI1 공유 시 충돌 위험. ALARM → PB6, PWR_FLT → PB7로 이동. (두 칩 모두 SPI 모드 1이라 공유 자체는 가능하나, 확인 전에는 분리가 안전) | 0 |
| N | 문서: ADS1220 설정 한계 — IDAC ≤ 250 µA (IDAC 여유 AVDD − 0.9 V), R19 4.02 k로 기준 1.005 V (최소 0.75 V 이상), PGA 이득 ≤ 2 (120 °C Pt1000 0.365 V) | 0 |
| O | 문서: 전류 출력 최대 부하 = (전원 − 3 V) / 24 mA − 25 Ω (DAC 여유 AVDD − 2 V, TPS2661 RON 최대 12.5 Ω, R30 10 Ω) → 12 V: 약 350 Ω, 24 V: 약 850 Ω | 0 |

합계 (L–O 포함): 82 → 84개 (안전·정격 문제 수정으로 부품이 약간 늘어남).

유지: 입력 2단 TVS, ADS1220 (Pt1000 정확도), TPS26611 보호 방식 (#24 ⑤ 보류).

데이터시트로 문제없음을 확인한 것: TPS2660 SHDN 개방 가능(내부 2.7 V), dVdT 22 nF → 상승 4.2 ms, OVP 기준 1.19 V; LMR36006 EN–VIN 직결·PG 개방 허용, VCC 1 µF·BOOT 100 nF; TPS7A20 EN–IN 직결(내부 500 k 풀다운이라 필수); THVD2450 DE·/RE 묶음; DAC8760 방열 패드 GND, AVDD 10–36 V, REXT 비트로 외부 ISET 선택; OPA197 36 V·입력 레일투레일; ADS1220·PCAP04 모두 SPI 모드 1.

남은 확인:
- HART-IN 미사용 처리: 데이터시트에 지시 없음. 내부 35 kΩ이고 AC 결합 입력이라 개방 유지 (IVS320과 같음).
- STM32 데이터시트 원문 대조 (st.com 허용 필요. KiCad 심볼로는 확인됨).

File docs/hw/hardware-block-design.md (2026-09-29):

# 하드웨어 블록 설계 v0.2

> **상세 회로(서지·오결선 보호 포함)는 [회로 설계서 v0.1](circuit-design.md)** 에 있습니다. 보호 설계로 RS-485는 THVD2450, 전원 입력은 TPS2660 eFuse, 아날로그 출력은 TPS2661 보호 스위치로 바뀌었고, 전원 범위는 12–30 V입니다.

작성일: 2026-09-26 · 상태: 1차 부품 선정안 (평가보드 검증 전)

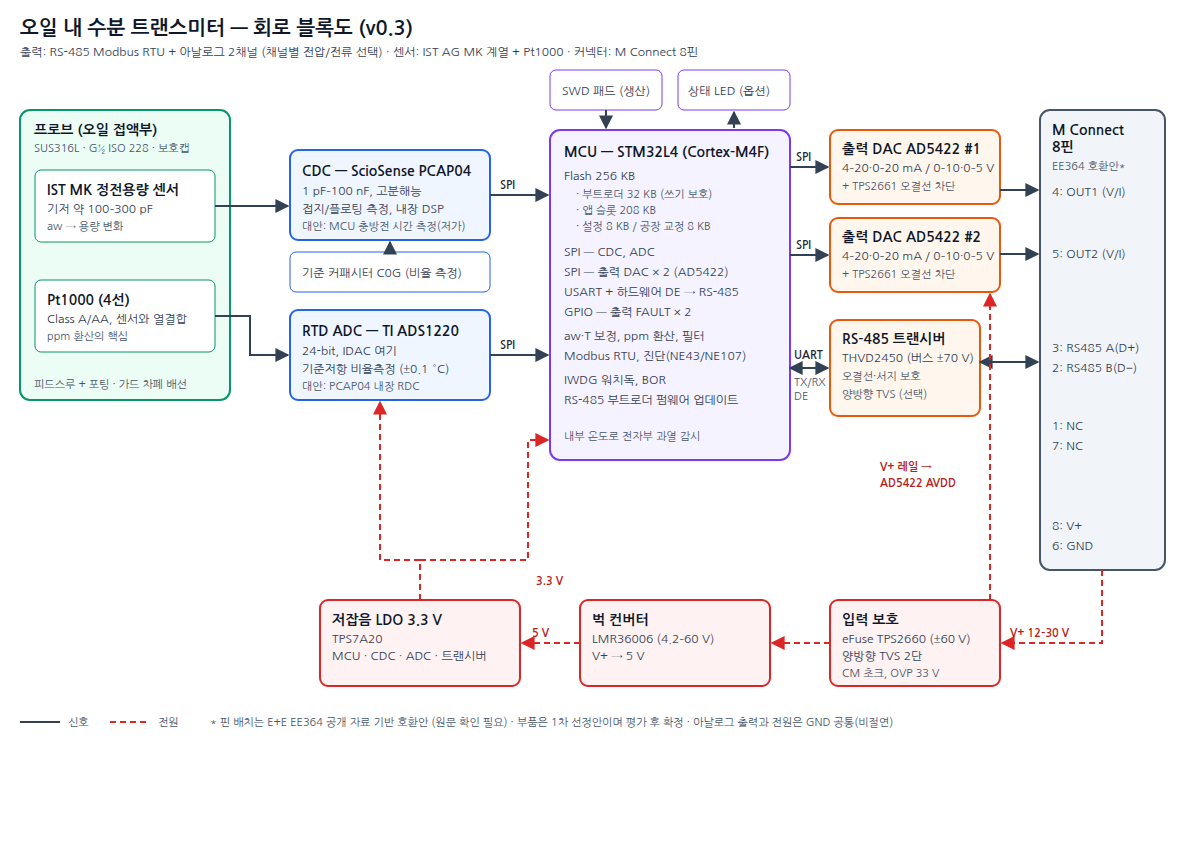
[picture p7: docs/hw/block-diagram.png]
회로 블록도


원본: [block-diagram.svg](block-diagram.svg)

## 0. 확정 사항

| 항목 | 내용 |
|---|---|
| 출력 | **RS-485 Modbus RTU + 아날로그 2채널** (둘 다 기본 탑재). **채널마다 전압/전류를 설정으로 선택** (2026-09-26 확정) |
| 센서 | IST AG MK 계열 정전용량 소자 (공급 중) + Pt1000 |
| 커넥터 | M Connect 8핀 (핀 배치는 EE364 호환안, 3절) |
| 펌웨어 업데이트 | RS-485 부트로더 ([설계 문서](../rs485-bootloader-design.md)) |
| 전원 | 15–30 V DC, 4선식(전원과 출력 GND 공통, 비절연) |

## 1. 블록별 설계

### 1.1 센서 측정 — 정전용량

| 후보 | 판단 |
|---|---|
| **ScioSense PCAP04 (1순위)** | 1 pF–100 nF 범위를 직접 측정하므로 기저 100–300 pF 소자에 그대로 연결됩니다. 여러 포트가 있어 **C0G 기준 커패시터와 비율 측정**을 할 수 있고, 이 방식으로 온도·전원 드리프트를 제거합니다. 내장 DSP와 저전력도 장점입니다 |
| ADI AD7745/AD7746 | **부적합.** 입력 범위가 ±4 pF이고 오프셋 보상(CAPDAC)도 약 17 pF까지라 수백 pF 소자를 직접 잴 수 없습니다 |
| TI FDC1004/FDC2214 | FDC1004는 오프셋 보상 한계가 있고, FDC2214는 LC 공진 방식이라 인덕터와 온도 특성 관리가 추가로 필요합니다 |
| MCU 충방전 시간 측정 | 원가는 가장 낮지만 분해능과 온도 안정성 확보에 개발 공수가 큽니다. 저가 파생 모델용으로 검토합니다 |

- 배선: 소자 → HTX99R → 하네스 W-1 (Ø7 관통 통로, 피드스루 없음) → PCB J3(JST SH 1.0 mm 4핀)로 연결하고 가드(차폐) 배선을 씁니다. PCAP04는 J3 바로 옆에 둡니다(결정 #16).
- 기준 커패시터: C0G/NP0 계열, 소자 기저 용량과 비슷한 값(예: 220 pF, 1%)을 씁니다.

### 1.2 온도 측정 — Pt1000

- **TI ADS1220**: 24-bit ADC이고, 내장 IDAC로 여기 전류를 흘립니다. 기준저항에 대한 비율로 측정하는 4선 결선입니다.
- 목표 정확도는 ±0.1 °C입니다. 60 °C에서 1 °C 오차가 나면 ppm 환산이 약 3% 틀어지므로, **ppm 정확도를 좌우하는 부분**입니다.
- 기준저항은 0.01% / 5 ppm/K 급 정밀 저항을 씁니다.
- 원가 절감안: PCAP04에 내장된 저항 측정 기능(RDC)으로 Pt1000도 측정하면 ADS1220을 뺄 수 있습니다. 정확도를 평가한 뒤 결정합니다.

### 1.3 MCU

- **STM32G0B1CCT3** (Cortex-M0+ 64 MHz, Flash 256 KB, RAM 144 KB, LQFP48, −40~125 °C). 선정 근거는 [MCU 선정 검토](mcu-selection.md)에 있습니다.
  - 두텍이 DP2000에 쓰는 G0B1CCT6과 같은 칩의 고온 등급이라, 개발 도구·드라이버·생산 지그를 함께 씁니다.
  - ppm 환산(지수 연산)은 1 Hz라서 FPU 없이 소프트웨어 실수 연산으로 충분합니다.
  - SPI로 CDC, RTD ADC, 출력 DAC(AD5422) 2개를 칩 선택(CS)만 달리해 한 버스에서 제어합니다.
  - USART의 하드웨어 DE 출력으로 RS-485 송수신 전환을 정확하게 처리합니다.
- 플래시 구성: 부트로더 32 KB, 앱 208 KB, 설정 8 KB, 교정 8 KB (부트로더 설계 문서와 동일).
- 워치독(IWDG), 저전압 리셋(BOR)을 쓰고, 내장 온도센서로 전자부 과열을 감시합니다.
- 생산용 SWD 패드를 둡니다. 교정과 펌웨어 기록은 RS-485로도 할 수 있습니다.

### 1.4 아날로그 출력 2채널 (전압/전류 선택형)

**목표:** 채널마다 Modbus 설정으로 전류 또는 전압 범위를 고릅니다. 커넥터 핀은 채널당 1개입니다.

| 모드 | 범위 | 구현 |
|---|---|---|
| 전류 | **4–20 mA**, 0–20 mA | DAC 전류 범위 (알람용으로 0–24 mA 범위를 내부 사용) |
| 전압 | **0–10 V**, 0–5 V | DAC 전압 범위 (10% 초과 범위 지원) |
| 전압 (파생) | 2–10 V, 1–5 V, 0–1 V | 0–10 V / 0–5 V 범위에서 디지털 스케일링 (16-bit라 분해능 충분) |

**부품 선정**

| 후보 | 내용 | 판단 |
|---|---|---|
| **ADI AD5422 (1순위)** / AD5412(12-bit판) | 16-bit 단일 채널. 전류 4–20/0–20/0–24 mA, 전압 0–5/0–10/±5/±10 V(10% 초과 범위). 내장 기준전압 5 ppm/°C, 총 오차(TUE) 0.1% 수준. 단일 전원 동작. **AN-1313에 전압·전류 출력을 한 핀으로 합치는 방법이 문서화**되어 있음 | 8핀 커넥터에서 채널당 핀 1개로 V/I 겸용이 가능하므로 채택 |
| TI DAC8760 / DAC7760 | 16/12-bit 단일 채널, 같은 범위, 단일 10–36 V 전원, 영점·이득 교정 레지스터 내장 | **2nd source.** 단일 핀 결합 방법은 데이터시트로 확인 필요 |
| MCU DAC + TI XTR300 | 핀으로 V/I 선택하는 출력 드라이버(최대 40 V), 전류 제한과 열 보호 내장 | 원가 절감안. 외장 저항 정밀도와 교정 부담이 큼 |

※ AD5422 공급전압 범위(검색 자료에는 12–48 V로 나옴)는 데이터시트로 확인해야 합니다. 입력 서지 시 AVDD 절대최대정격을 넘지 않도록 입력 보호(1.6절)를 설계합니다.

**설계 포인트**

- **단일 핀 결합:** AD5422의 VOUT와 IOUT를 AN-1313 방식으로 한 단자에 연결합니다. 모드를 바꿀 때는 출력을 먼저 끄고, 범위를 바꾼 다음 다시 켭니다(글리치 방지).
- **부하 조건 (데이터시트 확인 필요)**
  - 전류 모드: 전원 15 V 이상에서 **≤500 Ω**
  - 전압 모드: **≥1 kΩ**, 단락 시 전류 제한
- **알람 출력**
  - 전류 모드: NAMUR NE43 기준으로 센서 이상 시 ≤3.6 mA 또는 ≥21 mA
  - 전압 모드: 이상 시 0 V 또는 +10% 초과(예: 11 V) 중 설정
- **진단:** AD5422의 FAULT 출력과 상태 레지스터로 전류 모드 단선, 과열, 전압 모드 과부하를 감지하고 Modbus 상태로 보고합니다.
- **전압 모드 정확도와 GND:** 전원 전류가 흐르는 GND 선의 전압강하가 전압 출력 오차가 됩니다(예: 케이블 10 m, 50 mA에서 수 mV). 이를 피하려고 **7번 핀을 아날로그 전용 GND(AGND)로 쓰는 것을 제안**합니다.
  - EE364에서 7번 핀은 NC이므로, 7번이 연결되지 않은 기존 케이블에서도 동작합니다. 내부에서 GND와 한 점으로 연결하기 때문입니다.
- **교정:** 생산 공정에서 채널마다 **4–20 mA와 0–10 V 두 범위를 각각 2점 교정**하고, 교정 영역에 저장합니다. 나머지 범위는 같은 하드웨어 범위의 교정값을 씁니다.
- **보호:** 오결선으로 30 V가 들어오는 경우에 대비해 출력마다 TVS, 직렬 PTC, 역전류 차단을 둡니다. 보호 소자의 누설과 직렬저항은 전압 모드 정확도 예산에 포함합니다.
- 출력 설정용 Modbus 레지스터는 [부트로더 설계 문서](../rs485-bootloader-design.md) 7절에 있습니다.

### 1.5 RS-485

- 기본: **TI THVD1450** (3.3 V, ±12 kV ESD, 페일세이프 내장). 버스 TVS는 SM712(비대칭 −7/+12 V용), 직렬로 PTC를 둡니다.
- 옵션: 절연형 **ISO1410** + 절연 DC/DC. 접지 전위차가 큰 현장(변전소 등)용입니다.
- 종단저항 120 Ω은 **내장하지 않습니다**. 버스 끝단에 외부로 설치합니다.
- 방향 전환은 USART의 하드웨어 DE 출력으로 합니다. 기본값 19200 bps 8E1, 주소 1.

### 1.6 전원

```
V+ (15–30 V) → 입력 보호 → ┬→ V+ 레일 → AD5422 ×2 AVDD (출력 전원)
                           └→ 벅 컨버터 LMR36006 → 5 V → 저잡음 LDO TPS7A20 → 3.3 V
```

- 입력 보호: 역극성 차단 P-MOSFET, TVS SMBJ33A, PTC, EMI 필터(코몬모드 초크 + 커패시터).
- 벅 컨버터를 거쳐 LDO를 쓰는 이유: 스위칭 잡음이 CDC와 ADC로 들어가지 않게 하기 위해서입니다.
- 측정하는 순간에는 벅 컨버터를 PFM 모드로 두거나, 측정 타이밍을 동기화하는 방안을 검토합니다.

**소비전력 추정 (24 V 기준, 평가 전 추정)**

| 부분 | 전류 |
|---|---|
| 3.3 V 계통 (MCU, CDC, ADC, 트랜시버 대기, REF) | 약 10 mA → 24 V 환산 약 2 mA |
| RS-485 송신 중 (54 Ω 버스) | 순간 약 60 mA @3.3 V (짧은 구간) |
| 아날로그 출력 2채널 | 최대 2 × 24 mA + AD5422 대기 전류 (데이터시트 확인) |
| **합계** | **최대 약 55 mA @24 V (약 1.3 W)** |

### 1.7 보호와 EMC

- 모든 외부 핀에 TVS와 직렬 PTC 또는 저항을 둡니다.
- 커넥터 쉘과 하우징(SUS)은 차폐 케이블을 거쳐 접지합니다. 하우징과 회로 GND 사이에는 RC(1 MΩ ∥ 4.7 nF) 결합을 둡니다.
- 목표 규격: IEC 61326-1 산업 환경. ESD ±8 kV 접촉, 서지 ±1 kV(라인-접지), 버스트 ±2 kV.

## 2. PCB 구성 (원통 하우징)

- **축 방향 긴 보드 1장(57 × 23 mm, 4층)** 을 씁니다(기구 Rev C). 처음 안이었던 원형 2장은 쓰지 않습니다.
  - 외곽선, 금지 구역, 부품 높이 한계는 [기구 도면 HMT500-M-105~106](../../hardware/mech/README.md)과 `hardware/kicad/HMT500(260313A)/HMT500(260313A).kicad_pcb`에 있습니다.
  - 앞쪽(피드스루 쪽): 측정부(PCAP04, ADS1220, 기준소자). 피드스루까지 선이 짧아야 합니다.
  - 가운데: MCU, eFuse, 벅, LDO.
  - 뒤쪽(커넥터 쪽): 아날로그 출력(DAC ×2, TPS26611), RS-485, TVS 등 입력 보호.
  - 서지가 들어오는 커넥터와 민감한 측정부가 보드 양 끝으로 가장 멀리 떨어지고, 보드 간 커넥터가 필요 없습니다.
- 아날로그 GND와 출력 전류 경로를 분리하고 한 점에서 연결합니다. 출력 전류가 측정 GND를 흐르지 않게 하기 위해서입니다.
- 열: 전류 모드에서 부하가 작을 때 AD5422 발열이 커집니다(최대 약 30 V × 24 mA ≈ 0.7 W/채널). 측정부에 전달되지 않게 보드 뒤쪽에 두고, 필요하면 갭필러로 하우징에 열을 뺍니다. 필요하면 외장 방열 트랜지스터 구성(데이터시트 참고)을 씁니다.

## 3. 커넥터 핀 배치 (EE364 호환안)

| 핀 | 신호 | 비고 |
|---|---|---|
| 1 | NC | |
| 2 | RS485 B (D−) | E+E 표기 기준 |
| 3 | RS485 A (D+) | E+E 표기 기준 |
| 4 | OUT1 (전압/전류 선택) | |
| 5 | OUT2 (전압/전류 선택) | |
| 6 | GND | 전원, 아날로그 출력, RS-485 공통 |
| 7 | NC | 오결선 보호를 위해 PCB에서 연결하지 않음 (AGND 제안 철회, [회로 설계서](circuit-design.md) 1.1절) |
| 8 | V+ (15–30 V DC) | |

> EE364 핀맵은 Quick Guide 원문으로 **일치를 확인**했습니다([요약](../reference/ee364-summary.md)). 남은 확인 사항은 M Connect 품번(코딩, 핀 번호 규칙)입니다. 참고로 EE364 전원은 10–28 V이므로, 교체 호환을 위해 최소 전원 전압을 12 V 수준으로 낮출 수 있는지 검토합니다. **RS-485의 A/B는 이름이 아니라 +/− 극성으로 표기**합니다.

## 4. 전자부 BOM 원가

유통사 가격 조사 결과는 [bom-cost.md](bom-cost.md)에 정리했습니다. 1k 기준 전자부 합계는 **약 $36~64**(보호 회로 포함, 커넥터·센서·조립 제외)입니다.

## 5. 다음 단계

1. 평가보드 제작: PCAP04와 ADS1220 평가 킷에 MK 센서와 Pt1000을 연결해 분해능과 온도 드리프트를 확인하고, aw 교정 곡선을 확보합니다.
2. AD5422 평가보드(EVAL-AD5422)로 V/I 단일 핀 결합, 모드 전환 글리치, 부하 범위, 알람 출력, 단선 검출을 검증합니다. 원가가 중요하면 DAC7760(12-bit)이나 XTR300 방식과 비교합니다.
3. M Connect 품번과 핀 배치를 확정하고, EE364 호환 여부를 결정합니다.
4. 1차 회로도를 작성하고, 원형 PCB 외형과 하우징 치수를 기구 설계와 맞춥니다.
5. EMC 사전 시험 계획을 세웁니다(IEC 61326-1).

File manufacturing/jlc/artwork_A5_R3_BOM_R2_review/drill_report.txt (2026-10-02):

Drill report for HMT500(ED260313A).kicad_pcb
Created on 2026-10-03T08:50:13

Copper Layer Stackup:
    =============================================================
    L1 :  F.Cu                      front
    L2 :  In1.Cu                    in1
    L3 :  In2.Cu                    in2
    L4 :  In3.Cu                    in3
    L5 :  In4.Cu                    in4
    L6 :  B.Cu                      back

Drill file 'HMT500(ED260313A)-PTH.drl' contains
    plated through holes:
    =============================================================
    T1  0.150mm  0.0059"  (82 holes))
    T2  0.200mm  0.0079"  (153 holes))
    T3  0.200mm  0.0079"  (6 holes))
    T4  0.400mm  0.0157"  (2 holes))
    T5  0.600mm  0.0236"  (1 hole)

    Total plated holes count 244

Drill file 'HMT500(ED260313A)-NPTH.drl' contains
    unplated through holes:
    =============================================================
    T1  0.991mm  0.0390"  (3 holes))

    Total unplated holes count 3

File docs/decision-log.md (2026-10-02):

# HMT500(260313) 결정 기록

개발 대화에서 확정한 사항을 날짜순으로 적습니다. 새 결정이 이전 결정을 바꾸면 이전 항목에 "→ 변경"을 표시합니다.

| # | 날짜 | 항목 | 결정 | 근거·비고 | 반영 위치 |
|---|---|---|---|---|---|
| 1 | 2026-09-26 | 통신·업데이트 | RS-485 Modbus RTU 기본, 같은 버스로 부트로더 펌웨어 업데이트 | 현장 교체 없이 업데이트 | `docs/rs485-bootloader-design.md`, `firmware/` |
| 2 | 2026-09-26 | 센서·커넥터 | 습도 소자 IST MK (사내 공급), 커넥터 M Connect 8핀 | 사내 공급·사용품 | 회로도 J1, 기구 P-204 |
| 3 | 2026-09-26 | 출력 구성 | 아날로그 2채널 + RS-485, 핀맵 EE364 호환 (8 V+, 6 GND, 4 OUT1, 5 OUT2, 3 A, 2 B) | EE364 교체 호환 | `docs/reference/ee364-summary.md` |
| 4 | 2026-09-26 | 보호 | 서지·오결선 보호 필수 (입력 TVS 2단·eFuse, 출력 TPS26611, RS-485 ±70 V) | 현장 오결선 대응 | `docs/hw/circuit-design.md` |
| 5 | 2026-09-26 | 기구 모델명 | 두텍 HMT500 | 견적용 도면 | `hardware/mech/` |
| 6 | 2026-09-26 | 기구 결합 | 바디–하우징–엔드캡 **M28×1 나사 + 반경 O링** (Rev B), 하우징 Ø32 | 분해·수리 가능, 용접은 피드스루만 | 기구 Rev B |
| 7 | 2026-09-26 | PCB 구성 | 원형 2장 → **축 방향 긴 PCB 1장 57×23** (Rev C), 홀더·지지링 고정 | 면적 증가, 보드 간 커넥터 없음 | 기구 Rev C, `HMT500(260313A).kicad_pcb` |
| 8 | 2026-09-26 | 부품 방침 | **사내에서 구매·사용 중인 부품을 우선 사용** | 개발 도구·재고·구매 경로 공유 | `docs/hw/inhouse-parts.md` |
| 9 | 2026-09-26 | MCU | **STM32G0B1CCT3** (LQFP48, −40~125 °C) → 샘플은 CCT6 (#39) — DP2000 사용 G0B1CCT6과 같은 칩 | 사내 사용품, 부트로더 맵 그대로. T3 국내 견적 확인 필요 (85 °C 이하 확정 시 T6 가능) | 회로도 U4, `docs/hw/mcu-selection.md` |
| 10 | 2026-09-26 | **아날로그 출력 DAC** | **현재 DAC8760 ×2 장착 유지.** 출력 사양 확정 후 같은 핀 계열로 교체: **DAC7760** (12-bit, 전압+전류), **DAC8750** (16-bit, 전류 전용), **DAC7750** (12-bit, 전류 전용) | EE364는 4–20 mA 전류 전용(3선식, 2 µA 분해능). 전압 출력 유지 여부는 영업 판단. 기판 변경 없이 교체 가능 (전류 전용 칩의 전압 관련 핀 처리는 데이터시트 확인) | 회로도 아날로그 출력 시트 "DAC SELECTION", 부품리스트 U7/U8 |
| 11 | 2026-09-29 | 센서 접속 | 센서 프로브는 두텍 기존 부품 **HTX99R 센서 커넥터**(4핀, 2.54 격자 소켓)에 꽂는 방식으로 우선 검토 | 사내 부품 우선 방침. 도면 HTX99R-SC 작성 | `hardware/mech/ref/`, `out/HTX99R-SC_sensor_connector.pdf` |
| 12 | 2026-09-29 | 습도 센서 | **IST MK33-W mini (200 pF, −40~190 °C, 5.0×3.81 mm)** 1순위. 대안: HYT 271 MK33 디지털 모듈 (오일 ≤ 100 °C일 때 원가 절감안) | IST 오일용 권장 센서, 캐리어 크기·PCAP04 기준 C(220 pF)와 맞음 | `docs/hw/humidity-sensor-selection.md` |
| 13 | 2026-09-29 | 온도 센서 | **IST MiniSens Pt1000 class F0.1 (1.6×1.2 mm, 선 10 mm)** — 원가 절감 시 같은 크기 F0.15. HTX99R 4핀이면 Pt1000 **2선식** (리드 오차 0.026 °C/0.1 Ω, 교정으로 제거) | Pt1000 선호(두텍), 캐리어에 MK33-W mini와 함께 배치 | `docs/hw/temperature-sensor-selection.md` |
| 14 | 2026-09-29 | 기구 Rev D | **HTX99R 센서 커넥터를 센서 연결부로 사용.** 교체형 센서 프로브(4핀)를 꽂고, 커넥터는 바디 Ø10 H8에 O링 밀봉·플랜지 턱 지지·보호캡 턱 고정. 피드스루는 압력 격벽으로 유지. 노출 프로브 Ø12 → **Ø16** | 사내 부품 우선(#8, #11). 플랜지 Ø11 수용 | 기구 Rev D 도면·STEP |
| 15 | 2026-09-29 | 기구 Rev E | HTX99R 커넥터 Ø10 두 곳 = **M10×0.75** (두텍 확인). 아래 나사 → 바디 암나사 체결 (O링 Ø10 H8 면), 위 나사 → **보호캡 체결 (Ø12 복귀)**. 바디 튜브 Ø14. 피드스루는 **바디 뒤쪽**에서 삽입·용접 (배선 꼬임 방지 순서) | #14 보완 | 기구 Rev E, HTX99R-SC 도면 |
| 16 | 2026-09-29 | **센서–PCB 연결** (경로 → #17, 헤더 → #19에서 변경) | 센서 커넥터 쪽과 PCB를 **와이어 하네스 W-1 + JST SH 1.0 mm 4핀**으로 연결. PCB J3 = **BM04B-SRSS-TB** (윗면 삽입 SMD), 플러그 **SHR-04V-S + SSH-003T-P0.2-H ×4**, 전선 PTFE AWG30 22 mm. 경로: HTX99R 핀 → 선 → 피드스루(압력 격벽 유지) 앞 핀 / **뒤 핀 1–4 → W-1 → J3**. 핀: 1·2 MK33, 3·4 Pt1000 (**2선식**, J3 패드에서 켈빈 분기). 피드스루 핀 5·6 예비 | 요청은 "JST 1.27 또는 1.0 mm". JST에는 1.27 mm 전선-기판 계열이 없음 (GH가 1.25 mm) → **SH 1.0 mm** 선택, GH 1.25 mm는 더 튼튼한 대안(같은 4핀 배정). 윗면 삽입형: 하우징 조립 전 PCB가 드러난 상태에서 위에서 꽂기 쉬움. 헤더 높이 4.25 < 한계 9.7 | 회로도 J3 (측정 시트), 부품리스트, 기구 params·도면 ⑰, `HMT500(260313A).kicad_pcb` |
| 17 | 2026-09-29 | **기구 Rev F** | ① 프로브 앞쪽 보호캡 → 두텍 기존품 **SUS PROBE 오일 필터 390000-001100** (도면 2020-06-08, SUS304, Ø12 × 32, **M10×1.0** 암나사 8.5, 측면 Ø3 × 20 = 4줄 × 5개, 끝 Ø3). 노출 프로브 34 → **48**, 전장 144 → **158**. ② **피드스루 삭제:** 커넥터 뒤 ~ PCB 구간은 Ø7 **관통**, 센서 하네스 W-1만 지나감 (HTX99R 뒤 핀 → J3 직결, 60 mm). 통로는 pass-through(케이블만)이고, 케이블을 넣은 뒤 **전 길이(Ø7 × 34)를 에폭시로 몰딩 = 1차 격벽** (⑤ P-209, 두텍 지시). 압력 격벽 = HTX99R O링 + 몰드 핀 + 에폭시 몰딩 | 두텍 지시 (필터 DWG 제공, 관통 구간 표시 사진). 사내 부품 우선(#8). 조립: W-1 납땜 → 플러그를 Ø7 통로로 빼고 커넥터 체결 (플러그 자유 → 꼬임 없음) → 에폭시 몰딩 → J3 | 기구 Rev F 도면·STEP, `ref/SUS_PROBE_Oil_Filter_20200608.dwg`, 부품리스트 |
| 18 | 2026-09-29 | **M12–PCB 연결** | M12 8핀 커넥터(P-204)도 **와이어 하네스 W-2 + JST GH 1.25 mm 8핀 옆 삽입(직각)** 으로 연결. PCB J1 = **SM08B-GHS-TB** (윗면, 입구 뒤쪽 +x, PCB 뒤에서 12.5 mm 앞), 플러그 GHR-08V-S + SSHL-002T-P0.2 ×8, PTFE AWG28 60 mm, 핀 n = M12 핀 n. M12 쉘 핀(샤시)은 **J5 스프링 접점**(PCB 가장자리 → 하우징 Ø27 내면)으로 대체 | 두텍 지시. 조립: 엔드캡을 빈 상태로 체결 → W-2 플러그를 엔드캡 M16 구멍으로 넣어 J1에 꽂음 → M12 체결. 출력부 부품 재배치 (DAC#1 뒤로, TVS MCU 옆, TPS26611 아랫면) | 회로도 v0.5 J1·J5, 부품리스트, 기구 ⑱·주기 10 |
| 19 | 2026-09-29 | **J3 헤더 형식** | 센서 J3도 **옆 삽입(직각) 타입 JST SH SM04B-SRSS-TB**로 변경 (윗면 삽입 BM04B → 옆 삽입). 입구 = 앞쪽(-x, 센서 쪽), PCB x 22.5–26.5, 높이 2.95. 플러그는 x 18.5–22.5 (홀더 바로 뒤) | 두텍 지시 (J1과 같은 직각 형식). 홀더 Ø6 구멍에서 나온 W-1 전선이 굽힘 없이 곧게 들어감, 헤더 높이 4.25 → 2.95. PCAP04 x 29, ADS1220 x 30.5 / y −6으로 재배치 | 회로도 J3, 부품리스트, 기구 params·도면·3D |
| 20 | 2026-09-29 | **내부 몰딩·턴버클 체결** | ① 하우징 안 **전체**(바디 Ø22 + 하우징 Ø27 + 엔드캡 Ø22, M12 뒤면까지, 약 25 cm³)를 **상온경화 에폭시 1종**으로 몰딩 (통로 1차 몰딩과 같은 재료). 엔드캡에 주입·공기 빠짐 M3 구멍 2개 → 경화 후 M3×3 무두나사로 막음 (⑲). ② 엔드캡 나사를 **M28×1 왼나사**로 바꿔 **턴버클** 체결: 하우징만 돌리면 바디·엔드캡(과 PCB·M12·하네스)은 돌지 않음 → W-1/W-2 꼬임 없음. ③ J3를 홀더 뒤 12.5 mm(x 30.5–34.5)로 옮겨 꽂을 공간 확보, PCAP04·ADS1220 재배치 | 두텍 결정 (몰딩 범위 = 하우징 안 전체, 재료 1종). 유니언 너트는 하우징 벽(1.5 mm) 때문에 불가 → 부품 추가 없는 왼나사 턴버클 선택. 몰딩 후 전자부 수리 불가 (센서 프로브·필터만 교체) | 기구 도면 1·3쪽, 3D, 부품표 ⑤·⑲ |
| 21 | 2026-09-29 | **회로도 작도 규칙** | 부품번호·부품값 글자는 생성기가 몸체·핀·선·라벨·메모·박스와 겹치지 않는 자리에 자동 배치, 겹치면 생성 실패. 부품번호 = 굵게, 부품값 = 보통, 전원 네트 = 기울임, 신호 네트 = 테두리 라벨. 네트 이름은 부품번호·부품명·심볼명과 겹치지 않게 (LED → STAT_LED 등). 한글은 NanumGothic 트루타입 (KiCad 기본 글꼴에 한글 없음) | 두텍 지시 | `gen_hmt500.py`, `tests/test_kicad_gen.py`, `HMT500(260313A)_schematic.pdf` |
| 22 | 2026-09-29 | **부품 정리 1단계** | 회로도 v0.6: 91 → 75개. 삭제: R11–R15(→ MCU 내부 풀업), D3·R16(몰딩 후 LED 안 보임), R60·R61·D60·D61(THVD2450 자체 보호), FB2·C19(MCU ADC 측정 미사용, VREF+ = +3V3), C11·C2·C6(다른 콘덴서와 역할 겹침) | 두텍 제안 "겹치거나 꼭 필요하지 않은 부품 정리". 2단계 후보는 확인 후 삭제 (`docs/hw/circuit-design.md` 5A) | 회로도, 부품리스트 |
| 23 | 2026-09-29 | **PCB 내부 온도 측정** | 부품 추가 없이 2점: 앞쪽 = ADS1220 내부 온도센서(측정부), 가운데 = STM32G0 내부 온도센서(MCU·출력부). 측정 회로·DAC 드리프트 온도 보상, 과열 경보, Modbus 공개 | 두텍 요청 (온도 보상용). 더 정밀하게 필요하면 TMP117 추가 가능 | 회로도 메모, `docs/hw/circuit-design.md` 5B |
| 24 | 2026-09-29 | **아날로그 출력 정비** (VibrationSensor IVS320 비교) | 회로도 v0.7: ① DAC8760 **데이터시트 핀 번호**(SBAS528D, HTSSOP-24 PWP, IVS320과 같은 심볼)로 교체 — 없는 CAP1/CAP2 핀 삭제, EP 추가. ② **+VSENSE = OPA197 버퍼(U12/U13, 이득 1)** 로 단자 전압 감지 (R31/R41 10k는 버퍼 입력 보호로 유지). ③ **외부 ISET-R 15 kΩ 0.1 %** (R32/R42). ④ DAC는 **전용 SPI2(PB13/14/15) 데이지 체인** + **공통 DAC_LATCH(PB10)**, R33 100k 풀다운(DAC_DAISY). ALARM → PB11/PB3, PWR_FLT → PB4. ⑤ 출력 보호를 IVS320식 수동 보호로 통일하는 안은 **보류** (TPS26611 유지) | ② 전류 모드에서 +VSENSE 내부 약 60 kΩ 누설로 250 Ω 부하 약 0.4 % 오차 → 버퍼로 0. ③ 온도 드리프트 감소. ④ SPI1 공유 시 DAC가 LATCH와 무관하게 SCLK를 세는 문제(8.5.1.5)를 게이트 IC 없이 해결, 두 채널 동시 갱신. 부품 +8 (82개) | `docs/hw/circuit-design.md` 3절·6절, 회로도 analog_out·mcu |
| 25 | 2026-09-29 | **프로젝트 명칭·번호** | 제품(프로젝트) 이름 **HMT500 → HMT500(260313)**. 회로 관련 파일명·프로젝트 번호, PCB 마킹, 거버 파일명 = **HMT500(260313A)** (A = 회로·PCB 판). KiCad 폴더·파일 `hardware/kicad/HMT500(260313A)/HMT500(260313A).*`, 하위 시트 `HMT500(260313A)_<시트>.kicad_sch`, 심볼 라이브러리 별칭 `HMT500_260313A`(lib_id에 괄호 회피), PCB 아랫면 실크 `HMT500(260313A)`, 거버 `HMT500(260313A)-<층>.g*` + `HMT500(260313A).zip`. 기구 도면 번호(HMT500-M-xxx)·코드 파일명은 유지 | 사내 프로젝트 번호 체계 | `hardware/kicad/`, `export_gerbers.sh` |
| 26 | 2026-09-30 | **회로도 v0.8 — 데이터시트 대조 반영** | TI·ScioSense 데이터시트 원문 대조(`docs/hw/schematic-review-260313A.md`), A–O 전부 실시: ① LMR36006(BRNXR, RNX-12)·TPS26611(DDFR, SOT-23-8)·PCAP04(QFN24) 실제 핀. ② **TPS2660 RTN을 GND와 분리** (R22·R7 삭제, R5·R6·C4·MODE·방열 패드 → EF_RTN), R6 80.6 k = 149 mA. ③ **전원 12–28 V**, R5 41.2 k → OVP 29 V (TPS26611 +Vs ≤ 30 V). ④ **DAC SPI = SCLK 게이트** (U14 74LVC2G32, SPI2 모드 3, LATCH1/2 = PB10/PB11; 데이지 체인은 DAC8760 Rev D에서 삭제됨). ⑤ DAC AVDD 10 Ω (R34/R44), ALARM wired-OR + R33 10 k → PB6. ⑥ 출력 TVS → TVS3301. ⑦ PCAP04 전용 SPI3 (PB3/4/5), VDD18 4.7 µF·VDD33 10 µF. ⑧ 벅 L 15 µH, COUT 22 µF × 2, CFF 20 pF. ⑨ C53·C26 삭제. PWR_FLT → PB7, SGOOD(Low = 정상) → PC6/PC7 | 데이터시트 원문에서 치명(RTN)·정격 초과(+Vs)·지원 중단(데이지 체인) 발견. 82 → 84 부품, 넷리스트 74 / 74 일치 | 회로도 v0.8, `docs/hw/circuit-design.md` |
| 27 | 2026-09-30 | **조립 시뮬레이션 반영 (개선안 A–F)** | 실제 형상·PCB 배치로 조립 순서를 따라 간 결과(NG 6) 반영: **A** 홀더 창 5.6 × 3.2 — 홀더+PCB 벤치 조립(가로 나사) 후 W-1 플러그를 창으로 꿰고 축 나사는 뒤에서. **B** PCB 폭 23 구간 끝 x 64 → 63.4 (엔드캡과 틈 0.6). **C** 링 뒤(x ≥ 59) 부품 높이 한계 Ø20. **D** J5 스프링 접점(하우징까지 3.6 mm 모자람) 삭제 → **샤시 선** AWG 28 25 mm + M2 링 단자 → 홀더 위 축 나사(M2×8, 카운터보어 Ø5.2 × 2.2) → 금속 바디. J5 = 납땜 구멍. **E** W-2 60 → 40 mm, J1 뒤 윗면 부품 금지. **F** 조립 공구 T-001 밀대(3D 프린트) | 조립 불가(나사 공구·플러그 통로 상충), 턴버클 끝 간섭(틈 0), 샤시 미접촉을 형상 계산으로 확인. 재시뮬레이션 23항목 NG 0. 기구 도면 Rev G | `docs/hw/assembly-simulation-260313.md`, `hardware/mech/assembly_sim.py` |
| 28 | 2026-09-30 | **HTX99R 나사 = 위·아래 M10×1.0** | 두텍 확인: 센서 커넥터 두 나사 모두 M10×1.0. 바디 암나사 M10×0.75-6H → **M10×1.0-6H** (골지름 9.188 → 8.917, 나사 길이 5.5 유지). 필터 캡 M10×1.0 그대로. 센서 보호캡 M-102를 JLCCNC 가공품에 포함 (SUS304) | #15의 M10×0.75 기록 정정 | 기구 Rev G, `manufacturing/jlc/jlccnc/` |
| 29 | 2026-09-30 | **보호캡 뿌리를 G½ 안에 묻음 (Ø14 튜브 삭제)** | 바디 앞 Ø14 튜브 삭제, 커넥터·캡·프로브를 19.5 mm 뒤로. G½ 앞면에 Ø12.3 (+0.1/0) × 3.5 자리를 파서 캡 뿌리 3.5 mm를 덮음 (캡 Ø12와 틈 0.15, G½ 골지름까지 벽 ≥ 3). 커넥터 자리(Ø11.2 × 1 / Ø10 H8 × 1.5 / M10×1.0-6H × 5.5)는 그 뒤, Ø7 통로 14.5 mm, W-1 40 mm. 전장 158 → 138.5 mm, 노출 프로브 48 → 28.5 mm | 두텍 요청: 보호캡이 옆으로 젖혀지면 HTX99R 플라스틱 커넥터가 깨짐 → 약 3 mm 덮기, Ø14 부분 없애기. EE364(140 / 34)보다 짧아짐. 바디 금속 113 g | 기구 Rev G, JLCCNC M-101·M-102 STEP 교체 |
| 30 | 2026-09-30 | **기구 Rev H — 외형을 EE364와 부위별로 같게 + 조립 시방서** | 노출 프로브 Ø12 × 34 (보호캡 끝 쪽 5.5 연장), G½ 14, 육각 AF27 × 10, 몸통 Ø30, 씰면 ~ 엔드캡 끝 77, M12 15, 전장 140. 하우징 Ø30/Ø25 + M26×1 (R/LH 턴버클), O링 24 × 1.5 (Ø27), 엔드캡 플랜지 4 mm·맞변 AF27, M16 나사 x 71–77. 안쪽은 x −2 (PCB 모양·배치 그대로). 조립 시방서 HMT500-A-001 (19단계, 3D 그림) | 두텍 요청 (EE364와 동일 치수로 기존 설치 자리·액세서리 호환). 부품 높이는 가장 좁은 Ø24.9에서도 여유 ≥ 0.5, 조립 시뮬레이션 23항목 NG 0. M12 커넥터는 앞 나사부 ≤ 6 mm 품번으로 선정 | 기구 Rev H 전체, JLCCNC M-101~106 다시 견적, `hardware/mech/assembly_procedure.py` |
| 31 | 2026-09-30 | **펌웨어 업데이트 = 자체 상주 부트로더 (RS-485 Modbus)** | 플래시 앞 32 KB 자체 부트로더(`firmware/bootloader/`, `docs/rs485-bootloader-design.md` v0.2). ST 내장(ROM) 부트로더·OpenBLT·MCUboot는 쓰지 않음. 회로: RS485_DE 10 kΩ 풀다운(v0.9). 펌웨어 필수: 전원 투입 복구 창 약 1 s, 부팅 확인 카운터(3회), 하드웨어 워치독(IWDG_SW = 0), 업데이트 중 4–20 mA 고장 전류, 옵션 바이트(플래시 부팅·WRP 부트로더·RDP 1) | 몰딩 후 접근은 M12(전원 + RS-485)뿐. ROM 부트로더는 DE를 켜지 못해 응답 불가·BOOT0 진입 불가·RDP 1과 충돌(교정값 소실). 자체 부트로더는 같은 Modbus 주소로 버스 공유 업데이트, 전원 재투입으로 항상 복구, 교정값 보존 (`docs/hw/final-review-260313A.md` F) | 회로 v0.9 (A5), 부트로더 STM32G0B1 포팅, PC 도구 |
| 32 | 2026-09-30 | **회로도 v0.9 + 배치 rev 4 — 3중 검토 반영** | A1 OVP 32.6 V (R5 36.5 k, 복귀 30.1 V) + TPS26611 +Vs 이미터 폴로워 클램프 (Q1 MMBTA06 + R50 10 k + D50 27 V 제너, ≈ 26.3 V 이하; C53·C46·C56). A2 D2 → TVS3301. A3 eFuse 입력 C2 2.2 µF. A4 벅 입력 220 nF × 2 + C5를 U2 옆, U2 핀 3 = SW. A5 RS485_DE 10 k (R60). A6 R2 고전압 1206. A7 X5R 전부 X7R. A9 SWD no-connect 제거 + 검사기 강화. B1 SGOOD → PA0/PA4, CS_CDC → PA15. B2 LATCH·CS 풀업. B3 THVD2410. B4 R31/R41 100 k. B5 OPA197 V+ = DAC AVDD. B6 국부 C. B7 C25 10 µ / C24 22 µ. B8 C27 C0G. B9 VIN_SENSE (PB0). 배치: J5 금지 3.3 mm, CHASSIS 간격·샤시 부품 앞 구역, DAC를 측정부에서 떼어냄, 디커플링 핀 지정 배치 (MCU C는 U4 아래 아랫면). **넣지 않은 것: DAC 부스트(A8)·HSE(B10)·센서선 ESD(B11) 자리** | 두텍 결정: 전원 12–28 V 유지, DAC 발열은 자리 추가 + 재배치, A·B 전부. 그러나 57 × 23 기판에서 부스트·크리스털·ESD 자리를 DAC·MCU·J3 옆에 두면 ISET-R·REF C·디커플링이 10–20 mm 밀려나 더 나빠짐 → 넣지 않고 대안: DAC 발열은 몰딩 시제품 시험 후 사양 제한 또는 다음 PCB, 클럭은 HSI 공장 트림 + 펌웨어 보정, ESD는 프로브 시험 후. A10 JST −40 °C는 JST 확인 대기. 입력 DC 절대 최대 33 V (TVS3301). 부품 84 → 102, 넷 77/77, 조립 시뮬레이션 23항목 NG 0 | 회로도 v0.9, 배치 rev 4, `docs/hw/final-review-260313A.md`, 부품리스트 |
| 33 | 2026-09-30 | **배선 전 확정 사항** | ① 출력 보호 = **TPS26611 유지** (IVS320식 수동 보호로 바꾸지 않음). ② 하네스 커넥터 = **JST SH/GH로 진행** (−40 °C 확인은 시제품 시험으로). ③ 습도 센서 = **IST MK33-W (300 pF)** → C22 = 330 pF C0G 1%. ④ 부품 = **JLCPCB(LCSC)에서 구할 수 있는 품번으로 전부 맞춤** (같은 사양 대체품, 수동 부품은 Basic 우선). ⑤ 에폭시는 나중에 | 두텍 결정 | 회로도 v0.9 (C22), 부품리스트, `manufacturing/jlc/jlcpcb/jlc_parts_map.csv` |
| 34 | 2026-09-30 | **JLCPCB 부품 매핑** | 부품리스트 55줄 중 50줄 LCSC 번호 지정 (Basic 11줄). **핵심 4종은 원래 부품 유지 → JLC 글로벌 소싱**: MCU STM32G0B1CCT3 (125 °C), 벅 LMR36006BRNXR, 기준저항 R19 PLTT 0.02 %·5 ppm, 펄스 저항 R1·R30·R40 CRCW-HP. **크기 바뀌는 대체품 적용 + 재배치**: C6·C10 → 1210, C16·C17 → 0805, R1 MELF → 2512, L2 XGL4040 (높이 4.0), L1 Bourns SRF0905-102Y (WE-SL2 풋프린트, 대조 필요), C3 2 kV X7R 1812, GDT 2035-25 (250 V), D1 5.0SMDJ36CA, R2 KTR18 500 V, C22 ±2 % | 두텍 결정 (핵심 부품 = 원래 부품 유지, 크기 변경 = 대체품 + 재배치). LCSC·JLC 사이트는 이 환경에서 막혀 웹 검색 결과로 대조 → 재고·Basic 여부는 주문 화면에서 최종 확인. 102개 전부 재배치, 넷 77/77, 조립 시뮬레이션 NG 0 | `make_parts_list.py` LCSC 표, `manufacturing/jlc/`, 부품리스트 |
| 35 | 2026-09-30 | **외부 회로 검수(H01–H11) 반영** | 동의 항목 반영: H01 직렬 쇼트키 **D3 PMEG10010ELR** (eFuse 앞, 음 서지·역극성 차단, U1 입력 = VIN_D). H02 RS-485 버스 **TVS3301 D60/D61**, U11 → **THVD2410DGKR** (VSSOP-8, 같은 핀). H04 제너 **27 → 24 V** (BZX84C24LT1G). H08 IDAC = 250 µA 고정. **C7 삭제** (자리 확보, D3로 VIN_P 유지 불필요). **자리 확보: 저전압 R·C 37개 0603 → 0402** (3.3·5 V 디커플링 100 nF, 1 µF, 풀업·분압 저항 등, 모두 LCSC Basic/Extended — 50 V 이상 넷 부품과 정밀 부품은 0603 유지). 104개 전부 배치, 넷 78/78, pcbnew DRC 간격 오류 0. H03·H06·H07·H09–H11은 사양 표·전류 예산·펌웨어 요구 F1–F6·시험 T1–T7로 | 두텍: "맞는 것·동의하는 것을 업데이트". 검수 대응 문서 `docs/hw/external-review-response-260930.md`. 남은 결정: 제품 온도 사양(GDT 85 °C 등급) | 회로도 v0.9, 배치, 부품리스트 |
| 36 | 2026-10-01 | **전원·출력 부하 사양 확정** | 전원 **12–28 V DC, 최대 28 V** (입력 DC 절대 최대 33 V는 손상 한계로 유지). 전류 출력 부하 **RL ≤ 500 Ω** (전원 ≥ 18 V), 18 V 미만 RL ≤ (V+ − 6 V)/24 mA | 두텍 결정 — 경쟁사(EE364 RL < 500 Ω·10–28 V, MMT162 500 Ω·22–28 V, MMT330 RL < 500 Ω)와 같은 표기. 계산 한계(24 V 약 790 Ω) 대비 여유 | 제품 사양, `docs/hw/external-review-response-260930.md` 2절 |
| 37 | 2026-10-01 | **DAC 부분 확정 — IVS320 AO rev 1.0 방식** | ① **AO 전용 전원 VAO 16.1 V**: 벅 U15 LMR51606YFDBVR (4–65 V, 1.1 MHz FPWM, SOT-23-6) + L3 22 µH + C64/C65 10 µF 50 V, 422k/22.1k → 16.08 V. DAC AVDD(R34/R44 10 Ω 경유)·TPS26611 +Vs·OPA197 V+ 공용. ② **+Vs 제너 폴로워(Q1·R50·D50·C53)와 C43 삭제** (H04 해소). ③ **DAC CMP 보상** VOUT–CMP 4.7 nF + CMP–GND 100 pF (C47/C48, C57/C58, SBAS528D 8.3.2). ④ **DAC 출력 클램프** BAS70-04 (D41/D51, H03). ⑤ 출력 TVS는 TVS3301 유지 (±30 V 오결선 요구 — IVS320은 TVS1401 ±14 V로 ±28 V 지속 오결선을 보장하지 않음). ⑥ SGOOD는 MCU ADC 유지 (IVS320은 BSS138 → ALARM) | DAC 발열 미결(A8) 해소: 28 V·24 mA 단락 때 DAC 손실 약 0.66 → 0.39 W/채널. +Vs가 16.1 V로 고정돼 공차 문제 없음. 같은 회사 VibrationSensor(IVS320 AO rev 1.0, 2026-10-01 회로 확정)와 같은 회로라 부품·검증 공유. 대가: 부품 +10 (104 → 114), 12 V 입력에서 AVDD ≈ 10.5 V (0–10 V 전압 출력은 전원 ≥ 13 V 권장) | 회로도 v0.9 (Aux·Analog), 배치, 부품리스트, `docs/hw/external-review-response-260930.md` |
| 38 | 2026-10-01 | **부품 = JLCPCB(LCSC) 품번 우선** | 원칙: JLC에서 구할 수 있는 부품을 먼저 적용. 이번 변경: ① **U2 5 V 벅 LMR36006BRNXR → LMR51606YFDBVR** (LCSC C22439294, U15와 같은 IC) — SLUSEY1B 표 8-1: L2 10 µH (SMNR4020-10UH C135263), C6 22 µF 25 V, R8/R9 118k/22.1k → 5.07 V. C9(VCC)·C10·C11(CFF)·C17 삭제. ② **R19 → ERA-3AEB4021V** (0.1 %·25 ppm, C491130; 이전 PLTT 0.02 %·5 ppm). ③ **R1·R30·R40 → CRCW2512 일반형** (C242563, C844885; 이전 HP 펄스 내성형). ④ 422k → RC0402FR-07422KL (C477738), 118k AC0402FR-07118KL (C144804). MCU는 보류 (질문 중) | 두텍 지시. 대가: R19 온도 드리프트 약 5배 (Pt1000 정확도 → ADS1220 내부 온도로 보정 검토), R1·R30·R40 서지 에너지는 시험 T1·T3로 확인. 부품 114 → 110, 넷 81/81, JLC BOM 60줄 중 57줄 LCSC | 회로도 v0.9, 부품리스트, 배치 |
| 39 | 2026-10-01 | **샘플 단계 = JLCPCB 부품 우선 (MCU 포함)** | 샘플(시제품)은 JLC에서 구할 수 있는 부품을 우선. **MCU U4 → STM32G0B1CCT6** (LCSC C5270241, −40~85 °C; 사내 DP2000과 같은 품번, CCT3와 같은 칩·핀이라 회로·펌웨어 변경 없음). **양산 전 재검토:** 전자부(몰딩 안) 최고 온도 사양 확정 후 85 °C를 넘으면 CCT3(125 °C)로 — 같은 판단 대상: GDT1(85 °C), JST 커넥터(85 °C), R19 정밀도, R1·R30·R40 펄스 내성 | 두텍 지시: 샘플 단계에서는 JLC 부품 우선. 남은 비LCSC: 2.2 µF 50 V 0805 (C61), 22.1k 0402 (R9·R52) — 흔한 값, JLC 화면에서 선택 | 회로도 v0.9, 부품리스트, JLC BOM 60줄 중 58줄 LCSC |

| 40 | 2026-10-01 | **기구 Rev I — 검토 지적 직접 반영** | 설치 외형 140 / Ø30 / Ø12×34 유지. 300 pF Au/Cu 센서 외형 10.8×3.81×0.8 기준 캐리어 13.5 mm, PCB 홈 최소 1.9 mm. M3 몰딩 입구 r11.8, 축에서 안쪽으로 20° 경사(탭 깊이 4, Ø2.5 관통)로 M12 공구 접근과 O링 홈 분리. JLC STEP 임의 치수 보정 삭제, 도면과 공통 파라미터 사용. | 두텍 지시 “너가 직접 해줘.”에 따른 기구 개선. #36–39 전기 사양 불변. 실제 센서/M12 품번·노즐·가공성·에폭시·압력·온도는 확인 필요, 주문 승인 아님. | `docs/mech/rev-i-implementation-261001.md`, 기구 생성기·도면·STEP·조립 시방서 |

| 41 | 2026-10-01 | **AO TVS 14 V로 변경** | D30/D40만 TVS1401DRBR로 변경. D2/D60/D61 TVS3301 유지. VAO 16.1 V·TPS26611·24 mA/RL≤500 Ω 유지. AO에 외부 ±28/30 V를 지속 인가하는 무손상 보장은 제외하며, #37의 출력 TVS3301 유지 결정을 대체. | 두텍 지시: IVS320처럼 14 V로 낮춤. 14 V는 스탠드오프, 최대 클램프 23.55 V(30 A, 8/20 µs, 125°C). 펄스·배선 오버슈트·출력 개방 발열은 시험 필요. | 회로도 v0.10, D30/D40 BOM, `docs/hw/ao-tvs1401-261001.md` |

| 42 | 2026-10-01 | **인덕터 랜드·정격 표기 수정** | L2/L3 SMNR4020 전용 풋프린트: 패드 0.95×3.3 mm, 패드 안쪽 간격 2.1 mm, 중심 ±1.525 mm. 최대 높이 2.2 mm. 10 µH 정격 DC 전류 1.60 A·DCR 0.165 Ω ±30%, 22 µH 1.05 A·0.350 Ω ±30%로 정정. 포화 전류 정의는 확인 필요. | 제조사 SMNR 시리즈 치수표/전기 특성 대조. 이전 Taiyo NR-40xx 랜드와 다름. 회로 값/선정 품번은 유지. | `gen_artwork_footprints.py`, `make_parts_list.py`, `place_pcb.py` |

| 43 | 2026-10-01 | **PCB A1 배선 초안** | 4층·기구 Rev I·회로 v0.10 유지. In1은 GND 기준면, F/In2/B에 배선. U1 RTN 전용 구리와 내층 분리 영역, GND 간격 0.3 mm. MCU/DAC 반대면 배치의 비아 접근 문제로 미연결이 남아 제작 미승인. 거버/제작 주문 ZIP은 만들지 않음. | 두텍의 직접 아트워크 요청. 원본 생성기 + 배선 스냅샷으로 재현. 배선 완료 및 전원/측정 경로 재검토 전 주문 불가. | `docs/hw/artwork-a1-261001.md`, `rebuild_artwork.sh` |

| 44 | 2026-10-02 | **PCB A2 재배치·배선 초안 — 제작 미승인** | 4층·기구 Rev I·회로 v0.10 유지. CREF, 벅 SW/FB, DAC CMP 경로를 줄이고 CHASSIS 전용 연결을 확보. 배치 원본 `placement/artwork_A2.json`과 A2 배선 스냅샷으로 재현한다. DAC 방열 비아 12개 추가. 미연결이 남아 거버·제작 주문 패키지는 발행하지 않는다. | 두텍의 직접 처리 요청. 일반 DRC 오류 0과 배선 완료를 구분한다. 별도 6층 비교 실험은 미채택이며 확정 사양 변경이 아니다. 수치·남은 문제는 A2 보고서에 기록. | `docs/hw/artwork-a2-261002.md`, `placement_a2.py`, `rebuild_artwork.sh` |

| 45 | 2026-10-02 | **PCB A3 — 6층·신호 비아 축소 승인** | 두텍 지시 “6층. 비아홀 축소.”를 반영. F/In2/In3/B 배선, In1/In4 GND 기준면. nominal 1.6 mm·기구 Rev I·회로 v0.10 유지. 신호 비아 패드 0.30/홀 0.15 mm, 혼잡 디지털 선폭·간격 0.10 mm. 전원·서지·방열 비아는 유지. #44의 6층 미채택 결정을 대체. | 미연결 해소와 제조 DFM은 별도이며 제작 승인 아님. JLC06161H-2116A 적층을 기준으로 작성하되 실제 두께·공정 확인 필요. | `docs/hw/artwork-a3-261002.md`, `artwork_a3.py`, A3 배치·배선 스냅샷 |

| 46 | 2026-10-02 | **PCB A4 — 6층 후속 배선** | 두텍 “실시!!!”에 따라 A3를 보존하고 후속 배선. R42 및 C6를 재배치하고 eFuse UV/OV·RTN, GND, 3.3 V 및 ADC 인출을 수정했다. 회로 v0.10, 기구 Rev I 및 6층/신호 비아 0.30/0.15 mm 유지. A4 입력은 별도 배치·배선 스냅샷. | 미연결이 남아 제작/주문 불가. 검사 수치·구체적인 배치 변경·POFV 조건은 A4 보고서 참조. | `docs/hw/artwork-a4-261002.md`, `placement/artwork_A4.json`, `routing/artwork_A4_draft.json` |

| 47 | 2026-10-02 | **PCB A5 — 배선 연결 완료, 제조 검토** | 두텍 “더 진행하여 주세요”에 따라 6층/0.15 mm 신호 드릴을 유지하고 남은 5건을 연결했다. In1은 GND 전용으로 유지, In4는 GND 동박과 7개 넷을 혼용하도록 배선층 구성을 조정했다. 부품·배치·기구·전기 사양은 유지. GND 연결/귀환 비아 보완과 가지 배선 정리. | 전체 재생성 후 DRC 오류 0, 미연결 0, dangling 경고 0, 테스트 33개 통과. C44/D1 라이브러리 차이 경고 2개는 명시. 거버·드릴·BOM/CPL은 제조 검토용으로 생성하며 DFM/미확정 부품/온도·EMC 검증 전 발주 보류. | `docs/hw/artwork-a5-261002.md`, A5 스냅샷, `manufacturing/jlc/artwork_A5_review/` |

| 48 | 2026-10-02 | **A5-R1 실제 거버 실크 수정** | PDF 덧글 방식 대신 PCB 생성기의 실크 레퍼런스를 수정. 글자 폭/높이 0.6/0.8 mm, 선폭 0.12 mm. 근접 배치와 90° 회전, 공간이 허용되는 경우 짧은 지시선 적용. 배선·부품·회로·기구 사양 유지. | 두텍 지시 “거버에서 수정해야죠”. 인쇄 공간이 없는 번호는 숨김 목록으로 명시. 제조 인쇄성은 DFM 확인 필요. | `docs/hw/artwork-a5-r1-silk-261002.md`, `artwork_finish.py`, A5-R1 거버 |

| 49 | 2026-10-02 | **기구도면 발행 시 하네스 길이 반영** | W-1(센서–J3), W-2(M12–J1), W-3(J5–샤시 링 단자)의 길이를 실제 조립 경로와 여유선 수납에 맞춰 검토하고 기구 조립도·하네스 제작도·조립 시방서·구매 목록에 일치시킨다. 현 설계값 W-1 40±2 mm, W-2 40±2 mm, W-3 25 mm는 유지하며 최종 제조 길이 확정은 아니다. | 두텍 요청. 길이 측정 기준(절단/완성 길이), 공차, 탈피·압착·납땜 길이, 핀맵·선색, 굽힘/수납 경로와 조립 여유를 명시. 실제 M12 단자 형상 확인 후 확정. | AGENTS.md 하네스 도면 발행 인계, hmt500_params.py 공통 파라미터 |

| 50 | 2026-10-02 | **하네스 검토도 Rev A 발행** | W-1/W-2/W-3 A3 3장. 공통 파라미터의 현재 길이와 PCB 핀맵을 반영. 핀 위치도 대신 전기 연결 개략도로 명시. 실제 구매품 방향·길이 기준·탈피·압착 조건은 확인 필요이며 제조 승인 아님. | 두텍 “하네스 도면” 요청. 전기/기구 형상 변경 없음. | `hardware/mech/harness_drawings.py`, `hardware/mech/out/harness/` |

| 51 | 2026-10-02 | **M12 외형 포함 선정 사양서 Rev A** | HMT500-P-204 접속부 M12×1 A-coded 8핀 Male, 장착부 M16×1.5, 어깨 Ø20 이하·안쪽 나사부 6 mm 이하의 현 모델 조건을 외형도와 핀표에 정리. 실제 구매품 품번·씰·단자 돌출·외부 치수는 미확정. | 두텍 사양서 요청. 제조사 참고품과 프로젝트 외형 조건을 구분; 품번 채택·기구 변경 없음. | `hardware/mech/m12_specification.py`, `hardware/mech/out/m12/` |

| 52 | 2026-10-02 | **M12 외형도 Rev B 작도 형식 변경** | 사용자 TURCK 그림을 참고하여 흑백 외형선·누적 치수선·나사 호칭·8심 리드선 형식으로 다시 작성. 치수와 핀 수는 HMT500 모델을 유지하고 구매품 미확정 조건을 명시. | 두텍 “이런 스타일로 도면”. TURCK 4핀 T코딩 제품의 치수·탈피 길이를 채택한 것이 아님. 기구 형상 변경 없음. | `hardware/mech/m12_outline_drawing.py`, `hardware/mech/out/m12/HMT500_M12_외형도_RevB.pdf` |

| 53 | 2026-10-03 | **LCSC–BOM 매칭 보완** | C4 삼성 CL05B223KO5NNNC의 번호를 C1532(FH 다른 품번)에서 C318579로 정정. R9/R52=C43473. C61을 같은 2.2 µF/50 V/X7R/±10%/0805인 YAGEO CC0805KKX7R9BB225=C125847로 선정; 최대 높이 1.45 mm 반영, 현재 배치 허용 3.58 mm. C22 ±2%, R19 0.1%·25ppm 표시를 기결정 #34/#38에 동기화. | 두텍 LCSC/BOM 매칭 요청, #33 동일 사양 대체와 #38/#39 JLC 우선 지시. 카탈로그 61행/108개 대조; DC 바이어스·JLC 재고/실장 확인은 남음. 배선/배치 유지, DRC 오류/미연결 0, 33 tests 통과. | `docs/hw/lcsc-bom-match-261003.md`, `manufacturing/jlc/bom_match_20261003/` |

| 54 | 2026-10-03 | **A5-R2 실크 레퍼런스 재배치·두텍 로고** | 레퍼런스 기본 0.5×0.8 mm, 혼잡 구역 0.4×0.6 mm, 선폭 0.1 mm. 몸체 밖의 가까운 위치와 짧은 지시선으로 배치. 탑면 J1 뒤 빈 공간에 원본 DOTECH 워드마크 폭 8 mm. | 두텍 요청. 0.6 mm 글자의 인쇄성은 제조사 확인 필요. 공간 없는 번호는 누락 목록으로 공개. 회로·배선·부품 위치 불변, 제조 승인 아님. | `silk_layout.py`, `docs/hw/artwork-a5-r2-silk-logo-261003.md`, A5-R2 제조 검토 패키지 |

| 55 | 2026-10-03 | **정식 PCB 명칭·전체 두텍 로고** | 사용자 확인: HMT500(ED260313A). 현재 KiCad 프로젝트/회로도 표제/PCB 실크 및 새 거버·BOM/CPL 파일명 통일. DOTECH + SENSING & CONTROL 전체 로고를 탑면 11.5×3.20 mm로 배치하고 네이티브 벡터 그룹으로 묶음. 레퍼런스/PCB 명칭은 네이티브 텍스트. | 두텍 지시와 ED26의 중간 번호 0313 확인. 회로·배치·배선 유지. 과거 릴리스 파일명과 기술용 라이브러리 별칭은 이력/호환성 때문에 보존. | `docs/hw/artwork-a5-r3-identity-logo-261003.md`, `manufacturing/jlc/artwork_A5_R3_review/` |

| 56 | 2026-10-03 | **BOM R1 구매 불가 부품 교체** | C41/C51 → 삼성 CL10B102KC8NNNC(C153291), R5 → UNI-ROYAL 0603WAF3652T5E(C23029). 동일 값·공차·패키지 재고품, PCB A5-R3/회로 유지. | 두텍 구매 가능/JLC 보유 부품 전환 요청. 근사 저항값 변경 불필요. 사전 구매 필요 부품의 재고 배정과 DFM은 미완료. | `docs/hw/procurement-bom-r1-261003.md` |

| 57 | 2026-10-03 | **프리오더 회피 저항 BOM R2** | R1=C878295(4.7Ω5%), R3=C246013(845k), R4=C861608(97.6k0.1%), R5=C23027(35.7k), R6=C23254(82k). 회로v0.11, PCB A5-R3 유지. | 두텍 근사값 조정 승인. UVLO8.734V/OVP32.610V/복귀30.144V, 명목ILIM146.34mA. 공차·누설·TCR 계산, 서지/기동 시험은 필요. | `docs/hw/procurement-bom-r2-261003.md` |

| 58 | 2026-10-03 | **기구 Rev J 시제품 1세트** | 사용자1세트/내부3D 지시. M-101~104 SUS304 CNC 각1, M-105/106 MJF PA12-HP 각1, T-001 공구1. 명목형상 유지; 출력 후 치수검사·다듬기·M2 탭 필요. | 도면/주문표 재질 통일. 출력±0.3mm가 지정 끼워맞춤을 보장하지 않으므로 미달품 재출력. M12 실물·업체DFM·온도/몰딩/압력 검증은 남음. | `manufacturing/jlc/jlccnc/`, `jlc3d/PRINT_AND_FINISH.txt` |

## 미결 사항

| 항목 | 필요한 것 |
|---|---|
| ~~TPS2660 RTN 연결 (R22)~~ | #26에서 해결 — RTN은 GND와 분리 (데이터시트 9.3.5.5) |
| ~~임시 핀 번호 IC~~ | #26에서 해결 — 전 IC 데이터시트 원문으로 핀 대조. 남은 것: LMR36006 RNX0012A 풋프린트(KiCad 라이브러리에 없음) 작성 |
| 출력 사양 | 전압/전류 선택 유지 또는 전류 전용 → DAC 품번 확정 (#10) |
| ~~출력 보호 방식 통일~~ | #33에서 결정 — TPS26611 유지 |
| **JST SH/GH −40 °C (A10)** | #33: JST로 진행. 시제품 −40 °C 시험에서 확인, 안 되면 −40 °C 정격 1.0/1.25 mm 커넥터 (같은 핀 배정) |
| **DAC 발열 (A8)** | #37 VAO 16.1 V로 손실 0.39 W/채널로 감소 — 몰딩 시제품 온도 시험으로 확인만 |
| **제품 온도 사양 (H11)** | 주위 온도 범위와 몰딩 안 전자부 최고 온도 결정 — GDT1(−55~+85 °C)·JST(−25~+85 °C) 등급 판단 |
| **클럭 (B10)** | HSI16 온도 정확도·USART 허용 오차 원문 확인 (RM0444, DS13560), 펌웨어 HSI 보정 구현 |
| M Connect 품번 | 커넥터 장착 나사 M16×1.5, **앞 나사부 ≤ 6 mm, 어깨 Ø20 이하** (Rev I); 입구 r11.8의 경사 노즐 Ø2.5 이하 접근 확인, 리드 꼬임 대책 (뒤 너트 고정형 여부) |
| HTX99R 커넥터 | 재질·내열(120 °C)·내유성, 몰드 핀 누설, 두 번째 홈(Ø8.1) 용도. **HTX99R 센서 프로브 STEP**(핀 규격) 요청. 보호캡 Ø12 설치 호환성(볼밸브 등), 커넥터 체결 토크 |
| ~~습도 센서 구동~~ | #26에서 해결 — PCAP04 데이터시트 7.2: 단일 플로팅·접지 모드는 DC 없음 |
| 습도 센서 | #33: MK33-W (300 pF) — IST 품번·치수 확인 (mini보다 크면 프로브 캐리어 확인), PTFE 절연 + 글롭탑 사양 문의, 오일 최고 온도(HYT 271안 판단), HTX99R 4핀일 때 Pt1000 2선식 허용 여부 |
| 온도 센서 | 캐리어 접합 방식(용접/납땜 → 리드선 사양 또는 SMD 0805), F0.1/F0.15 견적, ADS1220 2선식 회로 변경 |
| ~~필터 캡 나사 규격~~ | #28에서 해결 — HTX99R 위·아래 모두 M10×1.0 |
| **몰딩 에폭시 선정 (1종)** | 한 재료로 통로(오일 쪽 120 °C, 압력)와 전자부(−40~85 °C)를 모두 맞춰야 함 → **연속 사용 온도 ≥ 120 °C (Tg 확인), 내유성, SUS·PEEK·FR-4 접착력, 낮은 수축·응력** 조건으로 상온경화 품목 선정. 정밀부품(R19 0.01 %, C22 C0G, PCAP04 입력) 몰딩 전후 값 변화 시험, 최종 교정은 몰딩 경화 후. 채움 부피는 실제 부품 체적을 빼고 시제품으로 확인 필요 (현 Ø7×12.5 통로 총체적 약 0.481 cm³, 전선 제외 전) |
| **압력 격벽 (Rev F)** | 피드스루가 없어 HTX99R O링·몰드 핀과 Ø7 에폭시 몰딩(1차 격벽)이 오일 압력을 받음 → HTX99R 정격 압력·온도(120 °C), 핀 누설, 에폭시 재료(내유·≥150 °C·SUS 접착력·열팽창) 선정, 내압 75 bar·누설 시험 |
| **필터 재질** | 390000-001100은 SUS304, 나머지 접액부는 316L → 오일 용도는 304로 충분한지, 316L 통일 여부 |
| ~~M12 체결 시 W-2 꼬임~~ | #20 턴버클로 해결 (M12는 하네스 끝이 자유로운 상태에서 엔드캡에 먼저 체결) |
| **센서 하네스 커넥터 온도** | JST SH/GH 정격 **−25 ~ +85 °C** (JST 카탈로그, 확인 필요). 오일 120 °C·주위 −40 °C에서 J3(PCB 앞 끝) 온도 시험 필요. 넘으면 −40 ~ +105 °C급 1.0 mm 커넥터(예: Molex Pico-Clasp 계열, 정격 확인)로 교체 — 같은 4핀 배정이라 풋프린트만 변경 |
| 기타 | IST MK 센서 도면, 압력 등급(50 / 200 bar), EE364 레지스터 호환 모드 여부 |

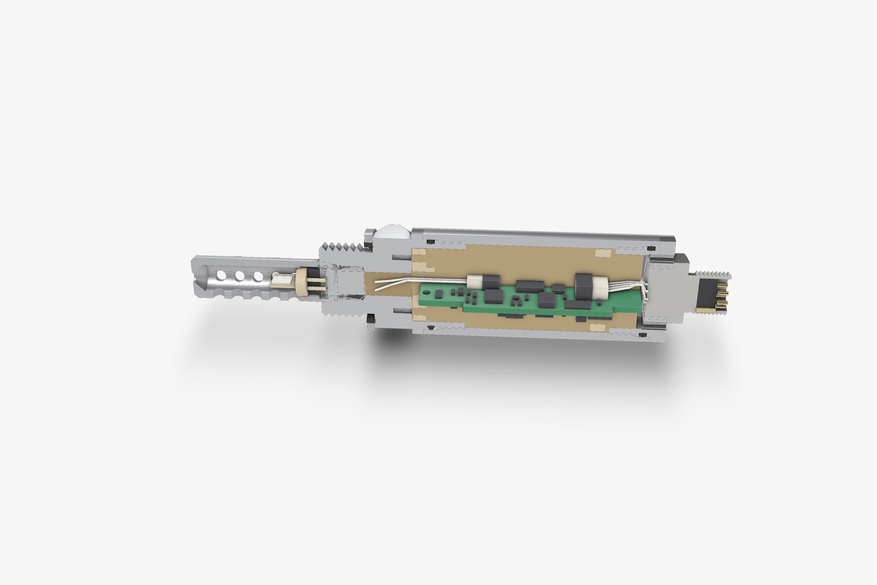
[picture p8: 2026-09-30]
hardware/mech/out/studio/HMT500_studio_06_cutaway.png

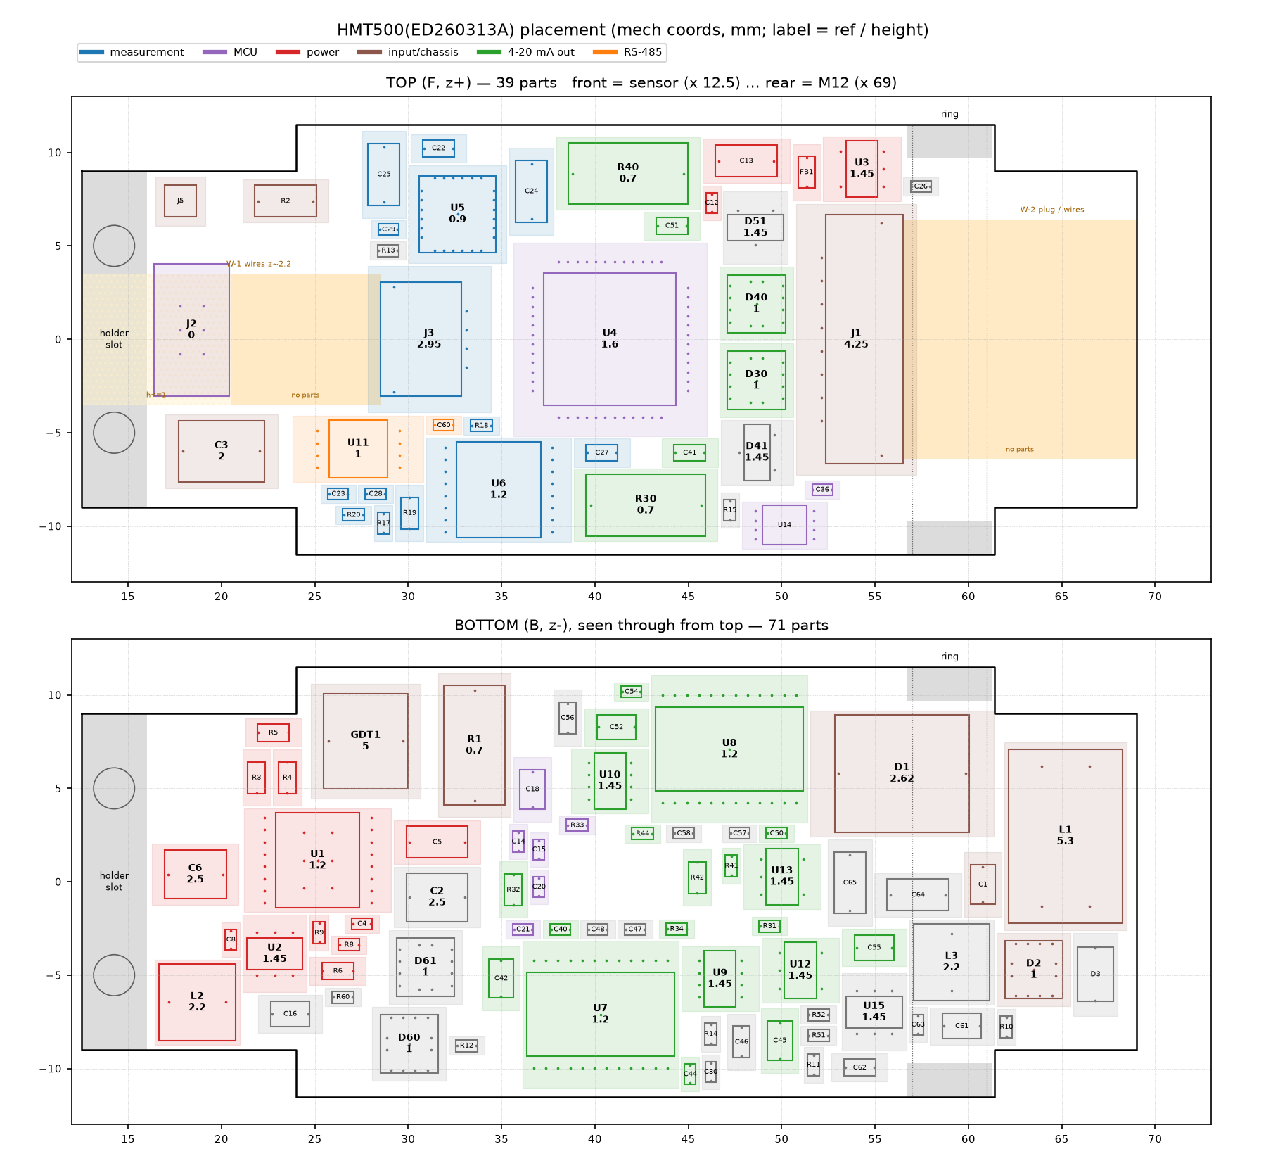
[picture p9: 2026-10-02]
hardware/kicad/HMT500(ED260313A)/placement.png

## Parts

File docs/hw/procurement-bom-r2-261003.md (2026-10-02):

# HMT500 회로 v0.11 / PCB A5-R3 / BOM R2

2026-10-03. 두텍 요청: 가능한 부품은 프리오더 없이 JLC 재고품으로 전환. 생성기에서 변경 후 전체 재생성한다. PCB 동박·배치·패키지는 유지, 회로도는 v0.11로 올린다.

| 위치 | 이전 | 변경 | LCSC |
|---|---|---|---|
| R1 | Vishay 4.7Ω 1% 1W | YAGEO RC2512JK-074R7L, 4.7Ω 5% 1W 2512 | C878295 |
| R3 | 866kΩ 1% | YAGEO RC0603FR-07845KL, 845kΩ 1% 0603 | C246013 |
| R4 | Panasonic 97.6kΩ 0.1% 25ppm | YAGEO RT0603BRD0797K6L, 같은 값·공차·TCR | C861608 |
| R5 | 36.5kΩ 1% | UNI-ROYAL 0603WAF3572T5E, 35.7kΩ 1% 0603 | C23027 |
| R6 | 80.6kΩ 1% | UNI-ROYAL 0603WAF8202T5E, 82kΩ 1% 0603 | C23254 |

R5는 BOM R1에서 확보한 값도 재고가 있지만, R3 변경에 맞춰 OVP 복귀 여유를 유지하려고 함께 조정했다. R19/R32/R42 정밀 저항과 나머지 저항값은 유지했다. C41/C51의 BOM R1 변경은 유지한다.

## 데이터시트 및 계산

YAGEO RC_L series V11(2020), RT series V16(2025), UNI-ROYAL Thick Film Chip Resistors V3(2019), TI TPS2660 SLVSDG2G 원문 대조. PDF는 저장소에 넣지 않았다. 원문 링크는 해당 JLC 품목 페이지와 https://www.ti.com/lit/ds/symlink/tps2660.pdf 에서 제공한다.

- R3/R5/R6: 0603, 0.1W, 75V, ±100ppm/°C. R4: 0603, 0.1W, 75V, ±25ppm/°C. 기존 랜드 및 높이 제한 유지.
- UVLO 상승 명목 8.734V, OVP 상승 32.610V, OVP 복귀 30.144V. R3=845k/R4=97.6k/R5=35.7k.
- 초기 공차, IC 문턱 최솟값/최댓값, 양 입력 ±100nA 누설, 25°C 기준 ΔT=100°C의 독립 TCR 최악 조합 포함: UVLO 상승 8.312–9.318V, OVP 상승 30.727–35.015V, 복귀 28.482–32.172V. 계산 기준은 VIN_D–EF_RTN이며 단자 전압과 D3/R1 강하를 구분한다. 28V 정상 동작·복귀 조건을 유지한다. 제품 온도 등급 확정은 아니다.
- OVP가 모든 공차에서 33V 이전에 차단하는 설계는 아니다. 최대 정상 입력 28V 조건을 유지한다. 입력 TVS3301의 33V DC 한계 및 기존 과전압/서지 검증 제한을 이 변경으로 해소했다고 주장하지 않는다.
- R6: IOL=12/R(kΩ) → 146.34mA, 기존148.88mA 대비 −1.71%. 기존 예산 약84mA보다 여유가 있으나 82kΩ 지점의 보장 최소/최대가 TI 표에 직접 제시되지는 않는다. −20%를 설계 가정으로 적용하면 약117mA이며 보장치가 아니다. 실제 전류 제한·최저 입력 기동·출력 두 채널/RS485 동시 부하 시험 필요.
- R1은 기존부터 HP형이 아닌 일반형이었다(#38). 이번에도 일반형이며 전용 서지 저항으로 격상한 것이 아니다. 4.7Ω±5%=4.465–4.935Ω. 84mA에서 최대 강하0.415V/발열0.035W, 176mA 가정에서0.869V/0.153W. 정격1W는70°C 기준이며 고온 감쇠 적용 필요.
- YAGEO 원문 단시간 과부하 조건은 정격전압의2.5배 또는 최대과부하전압 중 작은 값,5초. 이 시험을 IEC 서지 파형 합격으로 대체할 수 없다. 원문에 실제 회로의 서지 에너지 허용치가 없어 **T1 서지 성적 확인 필요**. 외형2512·높이0.6mm max는 기존0.7mm 가정 이내.

재현 계산: manufacturing/jlc/resistor_bom_r2_20261003/calculate.py 및 calculations.json.

## 조달·검증 상태

JLC 공개 주문 가능 수량은 stock_evidence.json에 조회 시각과 함께 저장한다. 재고 예약이나 최종 PCBA 배정 확인이 아니다. 모든 저항의 재고 여부를 대조하되, 전체 보드는 MCU/U9·U10/GDT1/J1 등 비저항 부족 부품이 남아 있어 프리오더 없는 PCBA 주문 완료 상태가 아니다.

전체 재생성: 넷리스트81/81 오류0, DRC 오류0/미연결0, 테스트33개 통과. 기존 경고24개(소형 실크22, 라이브러리 차이2) 유지. 배선·비아·부품위치·패드넷 불변 대조. DFM 및 CPL 방향/기구·몰딩/제품 시험 미결은 유지한다.

최신 묶음: manufacturing/jlc/artwork_A5_R3_BOM_R2_review/. 이전 BOM R1과 혼용하지 않는다. 발주 미실행.

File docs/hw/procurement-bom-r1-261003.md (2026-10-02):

# HMT500(ED260313A) PCB A5-R3 / BOM R1 조달 변경

2026-10-03. 구매 불가 부품은 JLC 재고품으로 바꾸라는 두텍 지시에 따라 생성기의 MAP/LCSC를 변경했다. 회로 값·풋프린트·PCB 판 번호는 유지하며 BOM만 R1로 구분한다.

| 위치 | 이전 | 대체 | JLC 표시 재고 / 주문 가능 수량 |
|---|---|---|---|
| C41,C51 | Murata GRM188R72A102KA01D / C97897 | Samsung CL10B102KC8NNNC / C153291 | 171,211 / 163,721 |
| R5 | CAL-CHIP RM06F3652CT / C4027587 | UNI-ROYAL 0603WAF3652T5E / C23029 | 117,320 / 108,890 |

공개 페이지 2026-10-03 08:22 KST 조회. 재고 예약이나 주문 완료가 아니며, 최종 PCBA 주문에서 배정 확인이 필요하다. Global Sourcing·Consign 주문은 실행하지 않았다.

## 전기·기구 대조

- C41/C51: 같은 1 nF, ±10%, 100 V, X7R, 0603. 삼성 공식 원문 크기 1.60±0.10 × 0.80±0.10 × 0.80±0.10 mm. 최대 높이 0.90 mm는 기존 생성기의 0603 높이 0.95 mm 안에 든다. 기존 랜드 유지.
- R5: UNI-ROYAL Thick Film Chip Resistors, Feb.12,2019 V.3 원문 p2·4·5·6 확인. 0603 / WA=0.1 W / F=±1% / 3652=36.5 kΩ / 75 V / ±100 ppm/°C. 몸체 1.60±0.10 × 0.80±0.10 × 0.45±0.10 mm. 일반 OVP 분압용이며 펄스 전력 저항 대체가 아니다.
- R3/R4/R5의 저항값과 연결을 바꾸지 않아 UVLO/OVP 명목값은 변하지 않는다. R6 전류 제한과 VAO 16.1 V도 유지한다. 온도 포함 최종 차단값은 기존 시제품 검증 대상이다.
- 가까운 표준값으로 바꾸는 것도 가능하지만, 현재 구매 불가 R5는 동일 값 재고품으로 해결되므로 문턱 전압 변경이 불필요하다. 정밀 측정용 R19/R32/R42 등은 임의 근사값으로 바꾸지 않는다.

## 남은 조달

기존 공개 페이지에서 사전 구매 가능한 GDT1, J1, R1, R3, R4, R6, U9/U10(TPS26611), U4(MCU)는 유지한다. 이는 즉시 SMT 재고 확보 완료를 뜻하지 않는다. 일부 최소 구매수량이 크고 납기는 확인 필요하다. MCU는 CCT6 LQFP48 유지; CCU7 UFQFPN48은 그대로 실장할 수 없다.

전체 SMT 108개 / BOM 61행. J2는 Tag-Connect 접점, J5는 샤시 선 납땜 구멍으로 구매 부품이 아니다. 실제 PCBA 생산 수량·예비분·손실분 및 사전 구매 완료 여부를 확인해야 전량 SMT 가능 여부가 확정된다.

## 근거

- 삼성 공식 사양: https://product.samsungsem.com/mlcc/CL10B102KC8NNN.do
- JLC C153291: https://jlcpcb.com/partdetail/C153291
- JLC C23029 및 제조사 데이터시트 링크: https://jlcpcb.com/partdetail/C23029
- 제조사 데이터시트는 저장소에 넣지 않았다. 재고 원문에서 필요한 필드만 stock_evidence.json에 보존한다.

## 검증 및 발주 상태

전체 생성·검사 결과는 validation.txt에 기록한다. 최소 0.15 mm 비아와 POFV 혼용 DFM, CPL 방향, 소형 실크 인쇄성, 제품 온도 및 시제품 시험은 기존 미결 사항이다. 본 변경은 부품 조달 수정이며 제조 승인이나 발주 완료가 아니다.

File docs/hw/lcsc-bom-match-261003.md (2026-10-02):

# HMT500 LCSC–BOM 매칭 (2026-10-03)

실장 BOM **61행 / 108개 / LCSC 59종** 모두 번호를 기입하고 공식 LCSC 카탈로그의 제조사 품번·값·패키지와 대조했다. 하네스 하우징/단자 4종도 별도 시트에 포함했다. 회로 v0.10 / PCB A5-R1 / 기구 Rev I 기준이다.

## 바뀐 것

| 대상 | 반영 |
|---|---|
| C4 | 기존 C1532는 FH 0402B223K500NT로 삼성 품번과 불일치. 삼성 CL05B223KO5NNNC에 맞는 **C318579**로 정정. 22nF 16V X7R 0402. |
| C61 | 기존 CL21B225KBFNNNE의 등록을 찾지 못해, 기결정 #33/#38/#39의 같은 사양 대체 원칙으로 YAGEO **CC0805KKX7R9BB225 / C125847** 채택. 2.2µF 50V X7R ±10% 0805. 제조사 최대 높이 1.45 mm를 배치 검사에 반영(현재 위치 허용 높이 3.58 mm). |
| R9/R52 | UNI-ROYAL **0402WGF2212TCE / C43473**. 22.1kΩ ±1% 0402, 50V, 62.5mW. |
| C22 | 기존 결정 #34로 이미 선정된 Vishay C3898227의 실제 공차 **±2%**로 회로도/BOM 표시 정정. |
| R19 | 기존 결정 #38로 이미 선정된 Panasonic C491130의 **±0.1%·25ppm**으로 회로도/BOM 표시 정정. |
| 구매 목록 | PCB 6층/Rev I와 현재 하네스 40±2mm 설계값을 반영. 하네스 절단/완성 길이는 미확정으로 표시. |

Panasonic C491130/C473244는 LCSC에서 ERA3AEB4021V/ERA3AEB153V로 하이픈 없이 표시한다. PCAP04는 LCSC 제조사 표기가 ams이고 현재 BOM은 ScioSense다. 제조 라벨/로트는 구매 시 확인한다.

## 검증

- 생성기에서 수정 후 전체 재생성: 작도·넷리스트 81/81 일치, DRC 오류 0, 미연결 0, 테스트 33개 통과.
- 기존 C44/D1 풋프린트 라이브러리 경고 2개는 유지.
- 배선/비아 형상, 부품 위치·면·회전·풋프린트 동일 대조.
- BOM/CPL 참조번호 집합 108개 일치, 중복/누락 없음. XLSX 재열기 확인.
- 카탈로그 사실과 링크는 `manufacturing/jlc/bom_match_20261003/catalog_evidence.json` 및 엑셀에 저장. 모든 부품 데이터시트를 새로 검증한 결과는 아니다.

## 남은 위험 / 결정할 것

- **C61의 28V DC 바이어스 실효 용량** 및 입력 리플 적합성은 확인 필요. 명목값과 온도특성만으로 실효 용량을 보증하지 않는다.
- LCSC 등록과 JLC 실장 가능/재고 확보는 별개. 특히 C4와 TVS1401의 JLC 등급은 확인 필요. 다른 Basic/Extended 표기도 주문 시 확인.
- 기존 0.15mm 비아/POFV DFM, CPL 방향, 온도·EMC 시험 등 발주 조건은 유지.
- M12/센서/전선/링 단자/에폭시 등 미확정 별도 구매품은 LCSC 번호를 임의로 배정하지 않았다.
- 이번 매칭에 추가 사용자 결정은 없으며, 기존 제품 온도·실제 M12 등 미결 사항은 그대로다.

## 자료와 사용 방법

`manufacturing/jlc/bom_match_20261003/`의 엑셀/CSV 및 JLC BOM/CPL을 사용한다. **이전 A5-R1 ZIP에 들어 있는 BOM은 과거 판**이다. PCB 형상은 유지됐지만 이번 수정 BOM으로 교체해서 검토해야 한다. 주문 실행/제작 승인 아님.

근거:
- [C4 삼성 LCSC](https://www.lcsc.com/product-detail/C318579.html), [잘못 연결됐던 C1532](https://www.lcsc.com/product-detail/C1532.html)
- [C61 JLC](https://jlcpcb.com/partdetail/YAGEO-CC0805KKX7R9BB225/C125847), [YAGEO 개별 사양서](https://www.yageogroup.com/download/specsheet/CC0805KKX7R9BB225)
- [R9/R52 JLC](https://jlcpcb.com/partdetail/44464-0402WGF2212TCE/C43473)
- [C22](https://www.lcsc.com/product-detail/C3898227.html), [R19](https://www.lcsc.com/product-detail/C491130.html)

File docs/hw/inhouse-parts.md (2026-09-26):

# 사내 사용 부품과 HMT500 적용 검토

작성일: 2026-09-26 · 방침: **두텍이 이미 구매·사용하는 부품을 우선 쓴다** (2026-09-26 결정)

자료: 두텍 구매현황 2건 (MCU 2023-09 ~ 2026-09, DAC 2021-09 ~ 2026-09). 담당자 이름과 발주 번호는 옮기지 않았습니다. 단가는 VAT 별도 공급가 기준입니다.

## 1. MCU (STM32) — 적용 완료

| 구입일 | 품번 | 수량 | 단가 (원) | 구매처 | 사용 제품 |
|---|---|---|---|---|---|
| 2026-09-21 | STM32F412RET6 | 30 | 9,937 | Mouser | HPX3000 |
| 2026-07-15 | STM32F412RET6 | 10 | 9,196 | Mouser | HPX3000 |
| 2026-02-12 | STM32G071CBT6 | 20 | 3,285 | Mouser | PSU750 |
| 2025-11-04 | STM32G0B1CCT6 | 100 | 2,060 | 국내 대리점 | DP2000 |
| 2025-08-25 | STM32L011F4U6 | 100 | 1,253 | DigiKey | HTP1100W |
| 2025-06-27 | STM32L011F3U6 | 100 | 1,186 | DigiKey | HTP1100W |
| 2025-06-16 | STM32G0B1CC | 20 | 5,702 | Mouser | DP2000 |
| 2024-02-14 | STM32G071CBT6 | 100 | 3,606 | Mouser | GTX500 |
| 2023-10-11 | STM32G031K6T6 | 200 | 2,600 | Mouser | GTX30P |

→ HMT500은 **STM32G0B1CCT3** (DP2000과 같은 칩의 125 °C 등급)로 확정했습니다. 근거는 [MCU 선정 검토](mcu-selection.md)에 있습니다.

## 2. DAC — 검토 중

| 구입일 | 품번 | 종류 | 수량 | 단가 (원) | 구매처 | 사용 제품 |
|---|---|---|---|---|---|---|
| 2025-06-27 | **DAC60502DRXR** | 12-bit 2채널, WSON 3×3 | 20 | 5,888 | DigiKey | HTP1100W |
| 2024-07-09 | **DAC7562SDSCR** | 12-bit 2채널, WSON 3×3, 내장 2.5 V 기준 | 200 | 5,310 | Mouser | IMX200L, AX7243 |
| 2023-08-24 | DAC60501ZDGST | 12-bit 1채널, VSSOP-10 | 20 | 3,189 | DigiKey | (재고 확보용) |
| 2022-09-19 | DAC7563SDSCT | 12-bit 2채널, WSON 3×3 | 120 | 8,155 | DigiKey | IMX200 |
| 2022-04-11 | DAC8562SDSCR | 16-bit 2채널, WSON 3×3 | 10 | 12,189 | DigiKey | IMX200L |
| 2022-03-30 | DAC8562SDSCR | 16-bit 2채널, WSON 3×3 | 10 | 11,999 | DigiKey | IMX200L |

(구매현황 제목에 EVM-DAC161S가 있습니다. DAC161S997은 루프 전원 4–20 mA 전용이라 전압/전류 선택형인 HMT500에는 맞지 않습니다.)

**정리:** 두텍은 **전압 출력 2채널 SPI DAC(DAC7562 / DAC8562 / DAC60502)** 를 쓰고 있습니다. 전압·전류 출력 단은 제품마다 따로 구성한 것으로 보입니다. 지금 HMT500 회로의 **DAC8760 ×2(전압/전류 출력 일체형)** 는 사내에서 쓴 적이 없습니다.

### 2.1 비교

| 항목 | 현재: DAC8760 ×2 | 사내안: DAC7562 (2채널) + 채널별 V/I 출력단 |
|---|---|---|
| 분해능 | 16-bit | 12-bit — 0–24 mA에서 약 6 µA/step (0.025 % FS). 센서 정확도(±0.02 aw ≈ ±2 % FS)보다 100배 이상 세밀 → **충분** |
| 부품 수 | IC 2개 + 수동소자 | DAC 1개 + 채널당 연산증폭기·트랜지스터·정밀저항·모드 전환 스위치 |
| 출력 모드 전환 | 레지스터로 V/I 선택 (한 핀) | 아날로그 스위치로 V/I 경로 전환 (한 핀) |
| 진단 | 개방·과열 알람 내장 | 전류 모드 개방 감지를 따로 만들어야 함 (비교기 또는 MCU ADC로 되읽기) |
| 교정 | 이득·오프셋 레지스터 내장 | MCU 펌웨어에서 교정 (사내 제품과 같은 방식일 것) |
| 전원 | 24 V 단일 전원에서 직접 구동 | 출력단만 24 V(VIN_P), DAC는 3.3 V |
| 1대분 부품가 (추정) | **$15.7 ~ 24.7** | **약 $7 ~ 9** (DAC 약 $3.8 + 출력단 2채널 약 $3 ~ 5) |
| 사내 이력 | 없음 | DAC 있음 (IMX200L, AX7243, HTP1100W). 출력단은 사내 회로 확인 필요 |

→ **사내안이 1대당 약 $8 ~ 15 (1.1 ~ 2.1만 원) 쌉니다.** 전자부 원가에서 가장 큰 항목이라 효과가 큽니다.

### 2.1A DAC 칩 비교표 (DAC8760 / DAC7760 vs 사내 사용 칩)

사양은 TI 데이터시트 기준으로 정리했습니다. "(확인)"이 붙은 값은 원문 대조가 필요합니다. 가격은 사내 구매가(공급가)를 쓰고, 없으면 유통가를 추정했습니다(1,400원/USD).

| 항목 | **DAC8760** (현재 회로) | **DAC7760** | **DAC7562** (사내) | **DAC7563** (사내) | **DAC8562** (사내) | **DAC60502** (사내) | **DAC60501** (사내) |
|---|---|---|---|---|---|---|---|
| 채널 | 1 | 1 | 2 | 2 | 2 | 2 | 1 |
| 분해능 | 16-bit | 12-bit | 12-bit | 12-bit | 16-bit | 12-bit | 12-bit |
| 출력 | **전류 + 전압 (산업용 출력단 내장)** | 전류 + 전압 (내장) | 전압만 | 전압만 | 전압만 | 전압만 | 전압만 |
| 출력 범위 | 4–20 / 0–20 / 0–24 mA, 0–5 / 0–10 / ±5 / ±10 V | DAC8760과 같음 | 0–2.5 V 또는 0–5 V | 같음 | 같음 | 0–2.5 / 0–5 V (확인) | 같음 |
| 전원 | 10–36 V 단일 (또는 ±) | 같음 | 2.7–5.5 V | 같음 | 같음 | 2.7–5.5 V (확인) | 같음 |
| 기준전압 | 내장 5 V | 내장 5 V | 내장 2.5 V | 내장 2.5 V | 내장 2.5 V | 내장 2.5 V 정밀형 | 같음 |
| 정확도 | TUE ±0.1 % FSR 수준 | 같은 수준 | INL ±0.5 LSB 수준 (확인) | 같음 | INL ±4 LSB 수준 (확인) | INL ±1 LSB (확인) | 같음 |
| 전원 투입 시 출력 | 0 (출력 꺼짐) | 같음 | 0 | 중간값 (확인) | 0 | 0 (확인) | 0 (확인) |
| 진단·보호 | 전류 개방 알람, 과열, SPI 워치독·CRC, HART 입력 | 같음 | 없음 | 없음 | 없음 | 없음 | 없음 |
| 인터페이스 | SPI | SPI | SPI | SPI | SPI | SPI (확인) | SPI/I²C (확인) |
| 패키지 | HTSSOP-24 / VQFN-40 | 같음 | WSON-10 3×3 | WSON-10 3×3 | WSON-10 3×3 | WSON-10 3×3 | VSSOP-10 |
| 동작 온도 | −40~125 °C | 같음 | −40~125 °C | 같음 | 같음 | 같음 | 같음 |
| 단가 | 약 $7.8~12.4 (유통) | 약 $5~8 (추정, 확인) | **5,310원** (200개) | 8,155원 (120개) | 12,189원 (10개) | 5,888원 (20개) | 3,189원 (20개) |
| 사내 사용 제품 | 없음 | 없음 | IMX200L, AX7243 | IMX200 | IMX200L | HTP1100W | 재고 확보 |
| HMT500에 추가로 필요한 것 | 없음 (보호만) | 없음 (보호만) | 채널당 V/I 출력단 + 개방 감지 | 같음 | 같음 | 같음 | 칩 2개 + 채널당 출력단 |
| **2채널 1대분 추정** | **$15.7 ~ 24.7** | $10 ~ 16 (확인) | **$7 ~ 9** | $9 ~ 11 | $12 ~ 14 | $7 ~ 9 | $8 ~ 10 |

(출력단 2채널 추정: 연산증폭기·트랜지스터·정밀저항·모드 전환 스위치 약 $3~5)

**읽는 법**
- **DAC8760/7760:** 출력단이 칩 안에 있어서 회로가 가장 간단하고 진단 기능도 갖췄습니다. 대신 비싸고, 사내에서 쓴 적이 없습니다. 7760은 8760의 12-bit판이라 핀과 레지스터가 같습니다. 12-bit로 충분하니, 이 방식을 유지하더라도 **DAC7760이 원가상 낫습니다.**
- **사내 칩(전압 출력 DAC):** 칩값은 싸지만 전압/전류 출력단을 따로 만들어야 합니다. 그중 **DAC7562(12-bit 2채널, 사내 최다 구매)** 가 가장 쌉니다. DAC60502는 비슷한 가격대의 대안입니다.
- **16-bit(DAC8762 계열, DAC8562)는 필요 없습니다.** 센서 정확도(±2 % FS 수준)에 비해 12-bit(0.025 % FS/step)로도 충분합니다.

### 2.2 권고

1. **DAC는 DAC7562SDSCR로 바꿉니다.** 사내 구매 수량이 가장 많고(200개), 12-bit로 충분합니다. 16-bit가 꼭 필요하면 핀이 같은 DAC8562로 바꿀 수 있습니다.
2. **V/I 출력단은 사내 제품(IMX200L 또는 AX7243)에서 검증된 회로를 그대로 가져오는 것이 가장 안전합니다.** 사내 회로가 전압/전류 선택형이 아니라면, 채널당 "연산증폭기 + 트랜지스터 전류 출력 / 전압 버퍼 + 아날로그 스위치" 구성으로 새로 설계합니다.
3. **출력 오결선 보호(TPS26611)와 TVS·직렬 저항은 그대로 둡니다.** 출력단이 바뀌어도 커넥터 쪽 보호 구조는 같습니다.

**필요한 자료:** IMX200L 또는 AX7243의 아날로그 출력 회로도 (DAC7562 이후 V/I 변환부).

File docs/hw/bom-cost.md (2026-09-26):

# 전자부 부품 가격 (BOM 원가) v0.2

조사일: 2026-09-26 · 기준: 블록도 v0.3 + [회로 설계서 v0.1](circuit-design.md) (서지·오결선 보호 포함) · 수량 1,000대 기준 · 기구(하우징, 프로브, 보호캡) 제외

> **가격 출처와 한계**
> - 유통사 사이트(DigiKey, Mouser, LCSC 등)가 이 환경에서 직접 열리지 않았습니다. 그래서 **검색 결과에 노출된 가격**을 썼습니다.
> - 수량 구간(1개 / 1,000개)이 명확하지 않은 값이 섞여 있습니다.
> - **(추정)** 표시 값은 검색 가격이 없어 유사 부품을 기준으로 추정한 것입니다.
> - 실제 원가는 공식 대리점 견적(1k, 5k)으로 확정해야 합니다.
> - 원화는 **1 USD = 1,400원 가정**으로 환산했습니다.

## 1. 부품별 단가 (1대분)

| # | 블록 | 부품 | 수량 | 단가 USD (저가 ~ 정규 유통) | 1대분 USD | 가격 근거 |
|---|---|---|---|---|---|---|
| 1 | MCU | STM32G0B1CCT3 (LQFP48, 125 °C) | 1 | 1.5 ~ 2.5 | 1.5 ~ 2.5 | 두텍 구매 이력: G0B1CCT6 국내 2,060원(100개) ≈ $1.5. T3는 견적 필요 |
| 2 | 정전용량 측정 | ScioSense PCAP04-AQFM-24 | 1 | 6.5 ~ 7.1 | 6.5 ~ 7.1 | DigiKey $6.47~7.11 |
| 3 | 온도 측정 | TI ADS1220IPWR | 1 | 1.9 ~ 3.5 | 1.9 ~ 3.5 | LCSC $1.91~1.95, 정규 유통 1k (추정) |
| 4 | **아날로그 출력** | **TI DAC8760IPWP** (기준안) | **2** | 7.8 ~ 12.4 | **15.7 ~ 24.7** | DigiKey/Mouser 1k $12.09~12.37, 1ku $7.84 |
| 4' | (대안) | ADI AD5422BREZ | 2 | 5.8 ~ 19.3 | 11.6 ~ 38.5 | LCSC $5.78, DigiKey $19.25. 편차가 커서 견적 필요 |
| 5 | RS-485 | TI THVD2450 (버스 ±70 V 내성) | 1 | 1.5 ~ 3 | 1.5 ~ 3 | (추정). 참고: 이전 THVD1450은 LCSC $0.58 |
| 6 | 전원 | TI LMR36006 + 인덕터 | 1 | 1.1 ~ 1.8 | 1.1 ~ 1.8 | LCSC $1.02 (Q1판), 인덕터 (추정) |
| 7 | 전원 | TI TPS7A2033PDBVR (LDO) | 1 | 0.07 ~ 0.3 | 0.1 ~ 0.3 | LCSC $0.07~0.14 |
| 8 | 보호 | 양방향 TVS 2단, 출력·RS-485 TVS, 펄스 저항, CM 초크, GDT | 1식 | – | 1.5 ~ 4 | (추정) |
| 8a | 보호 | TI TPS2660 eFuse (±60 V, 역극성·OVP) | 1 | 1.5 ~ 3 | 1.5 ~ 3 | (추정) |
| 8b | 보호 | TI TPS26611 출력 오결선 보호 | 2 | 1.2 ~ 2.5 | 2.4 ~ 5 | (추정) |
| 9 | 온도센서 | Pt1000 박막 Class A | 1 | 0.5 ~ 3 | 0.5 ~ 3 | 대량 단가 (추정). 참고로 RS 소량가는 Heraeus $31/개 |
| 10 | 정밀 기준소자 | C0G 기준 커패시터 1%, 정밀 저항 0.01% 5 ppm/K | 1식 | – | 0.6 ~ 2 | (추정) |
| 11 | 수동소자 | 저항, 커패시터 약 80~120개, 크리스털 | 1식 | – | 0.5 ~ 1.5 | (추정) |
| 12 | PCB | 4층 57×23 1장 (기구 Rev C) | 1장 | – | 0.8 ~ 2 | (추정) |
| 13 | 표시 | 상태 LED (옵션) | 1 | – | 0.05 | (추정) |
| | | **전자부 합계 (기준안: DAC8760, 보호 포함)** | | | **약 $36 ~ 64** | **약 51,000 ~ 90,000원** |

## 2. 별도 항목

| 항목 | 1대분 | 비고 |
|---|---|---|
| M Connect 8핀 커넥터 | 약 $2 ~ 10 (추정) | 유럽 브랜드 M12 8핀 패널형 $5~10, 중국산 $1.5~3 수준. 사용 중인 M Connect 품번 단가로 대체 필요 |
| IST MK 센서 | 공급가 | 사내 구매 단가로 대체 |
| SMT 조립 | 약 $2 ~ 4 (추정) | 양면 실장, 1k 기준 |
| 절연형 RS-485 옵션 | +$3 ~ 5 (추정) | ISO1410(LCSC 표기 $0.66은 이상치 가능, 정규 유통 수 달러 추정) + 절연 DC/DC |

## 3. 원가 구조 해석

- **아날로그 출력 DAC 2개가 전자부 원가의 약 절반(50%)** 입니다. 그다음은 PCAP04(약 15~20%)입니다.
- 원가 절감안(출력부 비교):

| 출력 방식 | 출력부 원가 (2채널) | 전압/전류 선택 | 비고 |
|---|---|---|---|
| DAC8760 ×2 (기준안) | $15.7 ~ 24.7 | O | 16-bit, 진단·교정 레지스터 내장 |
| AD5422 ×2 | $11.6 ~ 38.5 | O | 단일 핀 결합 앱노트 있음. 견적 편차가 큼 |
| DAC7760 ×2 (12-bit판) | DAC8760보다 저렴 (추정) | O | 가격 확인 필요 |
| MCU 내장 DAC + XTR300 ×2 | 약 $6 ~ 10 (추정) | O | 외장 정밀저항과 교정 부담 증가 |
| MCU 내장 DAC + XTR111 ×2 | 약 $6 ~ 7 (추정) | **X (전류만)** | v0.1 구성 |

- 목표 판매가 약 $500(시장 조사 기준)에 비하면 전자부 원가 $36~64(보호 포함)는 **판매가의 약 7~13%** 입니다. 원가를 가장 크게 좌우하는 것은 기구(SUS 가공), 센서, 교정 공수일 가능성이 큽니다.

## 4. 다음 단계

1. 국내 공식 대리점(TI·ADI·ST 대리점, 디바이스마트 등)에 1k/5k 견적을 요청합니다. 대상은 DAC8760, AD5422, PCAP04, ADS1220, STM32G0B1CCT3, M Connect입니다.
2. 출력부 방식을 결정합니다: DAC8760 / AD5422 / XTR300.
3. 회로도 작성 후 전체 BOM(수동소자 포함)을 확정하고 [bom.csv](bom.csv)를 갱신합니다.

## 출처

- AD5422BREZ: https://www.lcsc.com/product-detail/Others_Analog-Devices_AD5422BREZ-REEL_Analog-Devices-ADI-AD5422BREZ-REEL_C192062.html , https://www.digikey.com/en/products/detail/analog-devices-inc/AD5422BREZ/2077063
- DAC8760IPWP: https://octopart.com/dac8760ipwp-texas+instruments-29661991 , https://www.digikey.com/en/products/detail/texas-instruments/DAC8760IPWP/5176207
- PCAP04: https://www.digikey.com/en/products/detail/sciosense/PCAP04-AQFM-24/10324311
- ADS1220IPWR: https://www.lcsc.com/product-detail/C48263.html
- STM32G0B1CC: 두텍 구매 이력(DP2000용 G0B1CCT6), 데이터시트 https://www.st.com/resource/en/datasheet/stm32g0b1cc.pdf
- THVD1450DR: https://www.lcsc.com/product-detail/C2671361.html
- LMR36006: https://www.lcsc.com/product-detail/C2869760.html
- TPS7A2033PDBVR: https://www.lcsc.com/product-detail/C2862740.html
- ISO1410BDWR: https://lcsc.com/product-detail/Isolated-RS-485-422-Transceivers_Texas-Instruments-ISO1410BDWR_C2671027.html
- SM712 / SMBJ33A: https://www.lcsc.com/product-detail/C12067.html , https://www.lcsc.com/product-detail/C499719.html
- Pt1000 (Heraeus): https://nz.rs-online.com/web/p/rtd-sensors/4538105
- M12 8핀 패널 커넥터: https://www.binder-usa.com/us-en/products/automation-technology/m12-a/99-3481-458-08-m12-a-male-panel-mount-connector-8-shieldable-thr-ip68-ul-for-pcb-assembly

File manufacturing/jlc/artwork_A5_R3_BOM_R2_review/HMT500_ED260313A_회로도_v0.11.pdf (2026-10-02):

1 | 2 | 3 | 4 | 5 | 6 | 7 | 8

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
Size: A3 | Rev: 0.11 | F Date: 2026-10-03
KiCad E.D.A. 10.0.6 | Id: 1/8

# Title: HMT500(ED260313A) Top

### File: HMT500(ED260313A).kicad_sch

### Sheet: /

DOTECH Co., Ltd.

### Project No. HMT500(ED260313A) - HMT500(ED260313A) oil moisture transmitter

### Design notes: docs/hw/circuit-design.md

### Pinouts checked vs manufacturer datasheets 2026-09-30 (STM32: KiCad lib)

## 1. Connector & input protection

파일: HMT500(ED260313A)_connector.kicad_sch

## 5. Analog outputs

파일: HMT500(ED260313A)_analog_out.kicad_sch

## 3. MCU

파일: HMT500(ED260313A)_mcu.kicad_sch

## 4. Measurement

파일: HMT500(ED260313A)_measurement.kicad_sch

## 7. Aux

파일: HMT500(ED260313A)_aux.kicad_sch

## 2. Power

파일: HMT500(ED260313A)_power.kicad_sch

6. RS-485

파일: HMT500(ED260313A)_rs485.kicad_sch

Field connector, 2-stage bidirectional TVS surge protection, chassis

isolation

LDO 3.3V 2x DAC8760 V/I output with TPS26611 miswiring protection

Capacitive humidity sensor (PCAP04) and Pt1000 2-wire (ADS1220)

STM32G0B1CCT6, SWD, reset, internal temperature sensor AO supply VAO 16.1 V (buck), supply monitor eFuse (reverse/OV/UV), 60V buck to 5V,

THVD2410 +/-70V fault-protected
transceiver DOTECH HMT500(ED260313A) - Oil Moisture Transmitter - Schematic v0.9 - Project No. HMT500(ED260313A)

Signal flow: J1 field connector -> protection -> eFuse -> 5 V buck -> 3.3 V LDO; sensor head J3 -> PCAP04 / ADS1220 -> MCU -> DAC8760 x2 / THVD2410 -> J1

v0.9: 3-pass review (docs/hw/final-review-260313A.md): OVP 32.6 V (R5 36.5k); AO supply VAO 16.1 V buck U15 (DAC AVDD, TPS26611 +Vs; dec. #37, IVS320 AO); D3 series Schottky; RS-485 TVS D60/D61; D2 -> TVS3301; eFuse IN C2; buck CIN;

RS485_DE 10k pull-down (in-house bootloader, dec. #31); THVD2410; X7R only; R2 HV 1206; SGOOD -> PA0/PA4; CS_CDC -> PA15; VIN_SENSE PB0;

LATCH/CS pull-ups; OPA197 V+ = DAC AVDD; R31/R41 100k; SWD no-connect flags removed; sheet Aux: +Vs clamp, VIN monitor (DAC boost / HSE / sensor ESD: no room, dec. #32). File names (schematic, PCB, Gerber) = HMT500(ED260313A).* PCB silkscreen marking = HMT500(ED260313A)

Outputs: RS-485 Modbus RTU + 2x analog (4-20 mA / 0-20 mA / 0-10 V / 0-5 V selectable). Supply 12-28 V DC. v0.11: stocked resistors R1/R3/R4/R5/R6; R3 845k, R5 35.7k, R6 82k; see decision #57. v0.10: AO D30/D40 TVS1401 +/-14 V. AO +/-28/30 V continuous miswiring is NOT guaranteed (#41). Power symbols: GND, +3V3, +3V3A (analog 3.3 V), +5V, VIN_P (protected input), CHASSIS. Inter-sheet signals: global labels. History v0.3-v0.8 (MCU G0B1, JST harness, DAC8760/TPS26611 datasheet pinouts, RTN isolation, gated DAC SCLK ...): docs/decision-log.md #9-#26.

Footprints: KiCad 7.0.11 library + project library HMT500_260313A (GDT Bourns 2035-xx-SM, TVS3301 pad floating).

라벨 모양 = 신호 방향: 뾰족한 쪽이 밖 = 이 시트에서 내보냄(출력), 안 = 받음(입력), 양쪽 = 양방향, 네모 = 아날로그·수동

표기 규칙: 부품번호 = 굵은 글자 (R1, U4) / 부품값 = 보통 글자 (10k, DAC8760) / 전원 네트 = 기울인 글자 (+3V3, VIN_P)

신호 네트 = 테두리 있는 라벨 (SPI_SCK, OUT1_EXT) - 네트 이름은 부품번호·부품명과 겹치지 않게 지음

글자 겹침: 생성기가 부품 몸체·핀·선·라벨·메모와 겹치지 않는 자리에 자동 배치하고, 겹치면 생성 실패로 처리

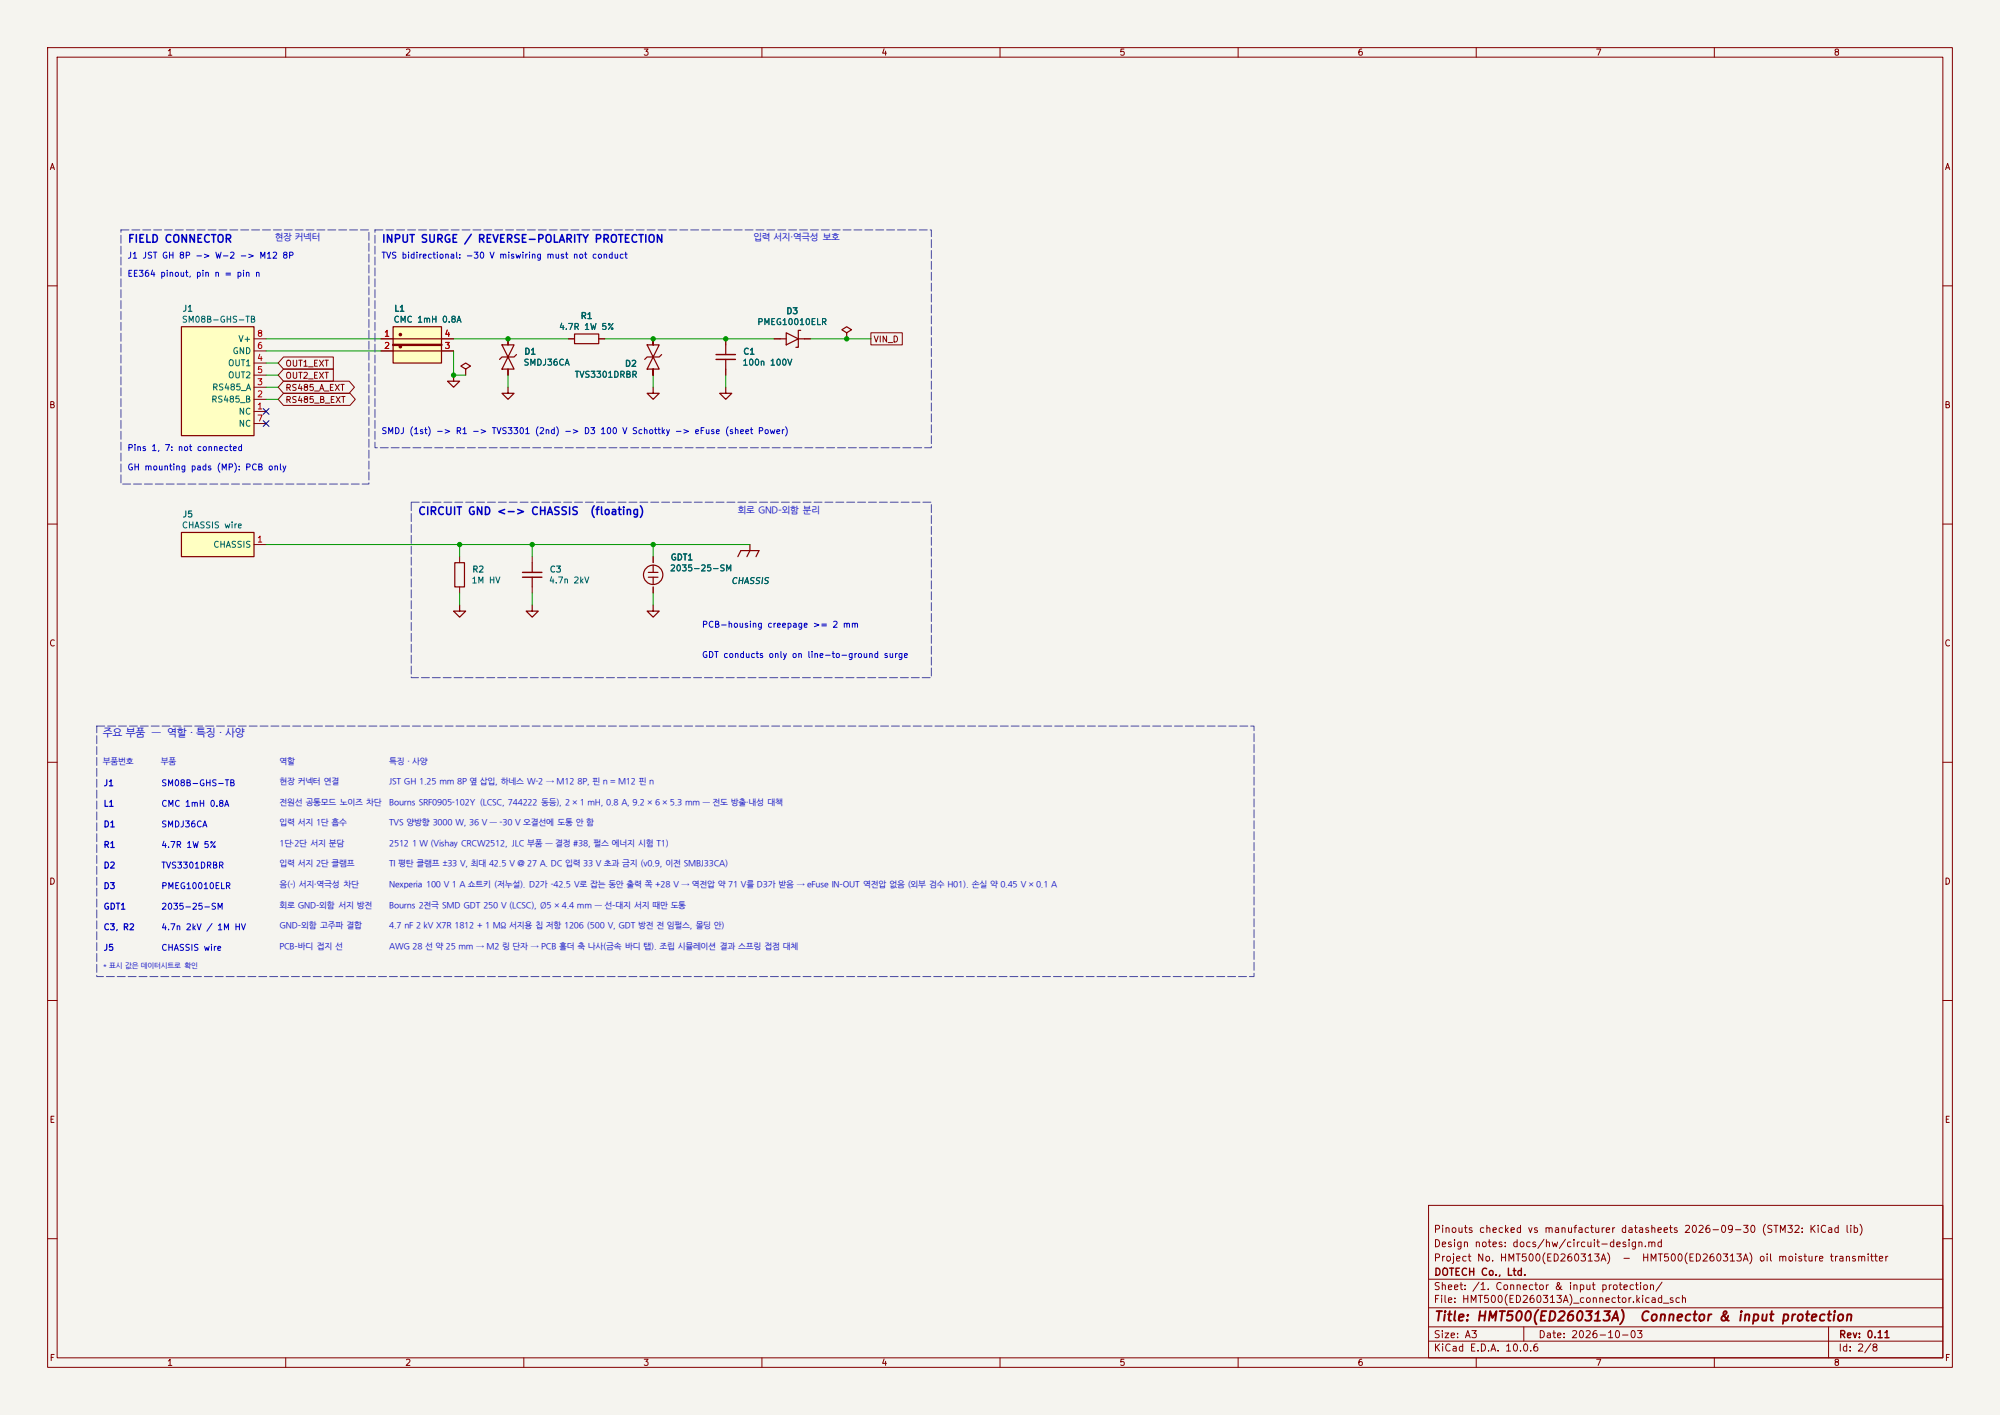
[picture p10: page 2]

INPUT SURGE / REVERSE-POLARITY PROTECTION

입력 서지·역극성 보호

TVS bidirectional: -30 V miswiring must not conduct 부품번호

Pins 1, 7: not connected GH mounting pads (MP): PCB only EE364 pinout, pin n = pin n

SMDJ (1st) -> R1 -> TVS3301 (2nd) -> D3 100 V Schottky -> eFuse (sheet Power)

CIRCUIT GND <-> CHASSIS (floating)

GDT conducts only on line-to-ground surge PCB-housing creepage >= 2 mm

* 표시 값은 데이터시트로 확인 주요 부품 — 역할 · 특징 · 사양

JST GH 1.25 mm 8P 옆 삽입, 하네스 W-2 → M12 8P, 핀 n = M12 핀 n

전원선 공통모드 노이즈 차단

Bourns SRF0905-102Y (LCSC, 744222 동등), 2 × 1 mH, 0.8 A, 9.2 × 6 × 5.3 mm — 전도 방출·내성 대책

TVS 양방향 3000 W, 36 V — -30 V 오결선에 도통 안 함

2512 1 W (Vishay CRCW2512, JLC 부품 — 결정 #38, 펄스 에너지 시험 T1)

Nexperia 100 V 1 A 쇼트키 (저누설). D2가 -42.5 V로 잡는 동안 출력 쪽 +28 V → 역전압 약 71 V를 D3가 받음 → eFuse IN–OUT 역전압 없음 (외부 검수 H01). 손실 약 0.45 V × 0.1 A

회로 GND–외함 서지 방전

Bourns 2전극 SMD GDT 250 V (LCSC), Ø5 × 4.4 mm — 선–대지 서지 때만 도통

GND–외함 고주파 결합

4.7 nF 2 kV X7R 1812 + 1 MΩ 서지용 칩 저항 1206 (500 V, GDT 방전 전 임펄스, 몰딩 안)

Pinouts checked vs manufacturer datasheets 2026-09-30 (STM32: KiCad lib)
Design notes: docs/hw/circuit-design.md
Project No. HMT500(ED260313A) - HMT500(ED260313A) oil moisture transmitter
DOTECH Co., Ltd.
Sheet: /1. Connector & input protection/
File: HMT500(ED260313A)_connector.kicad_sch
Title: HMT500(ED260313A) Connector & input protection

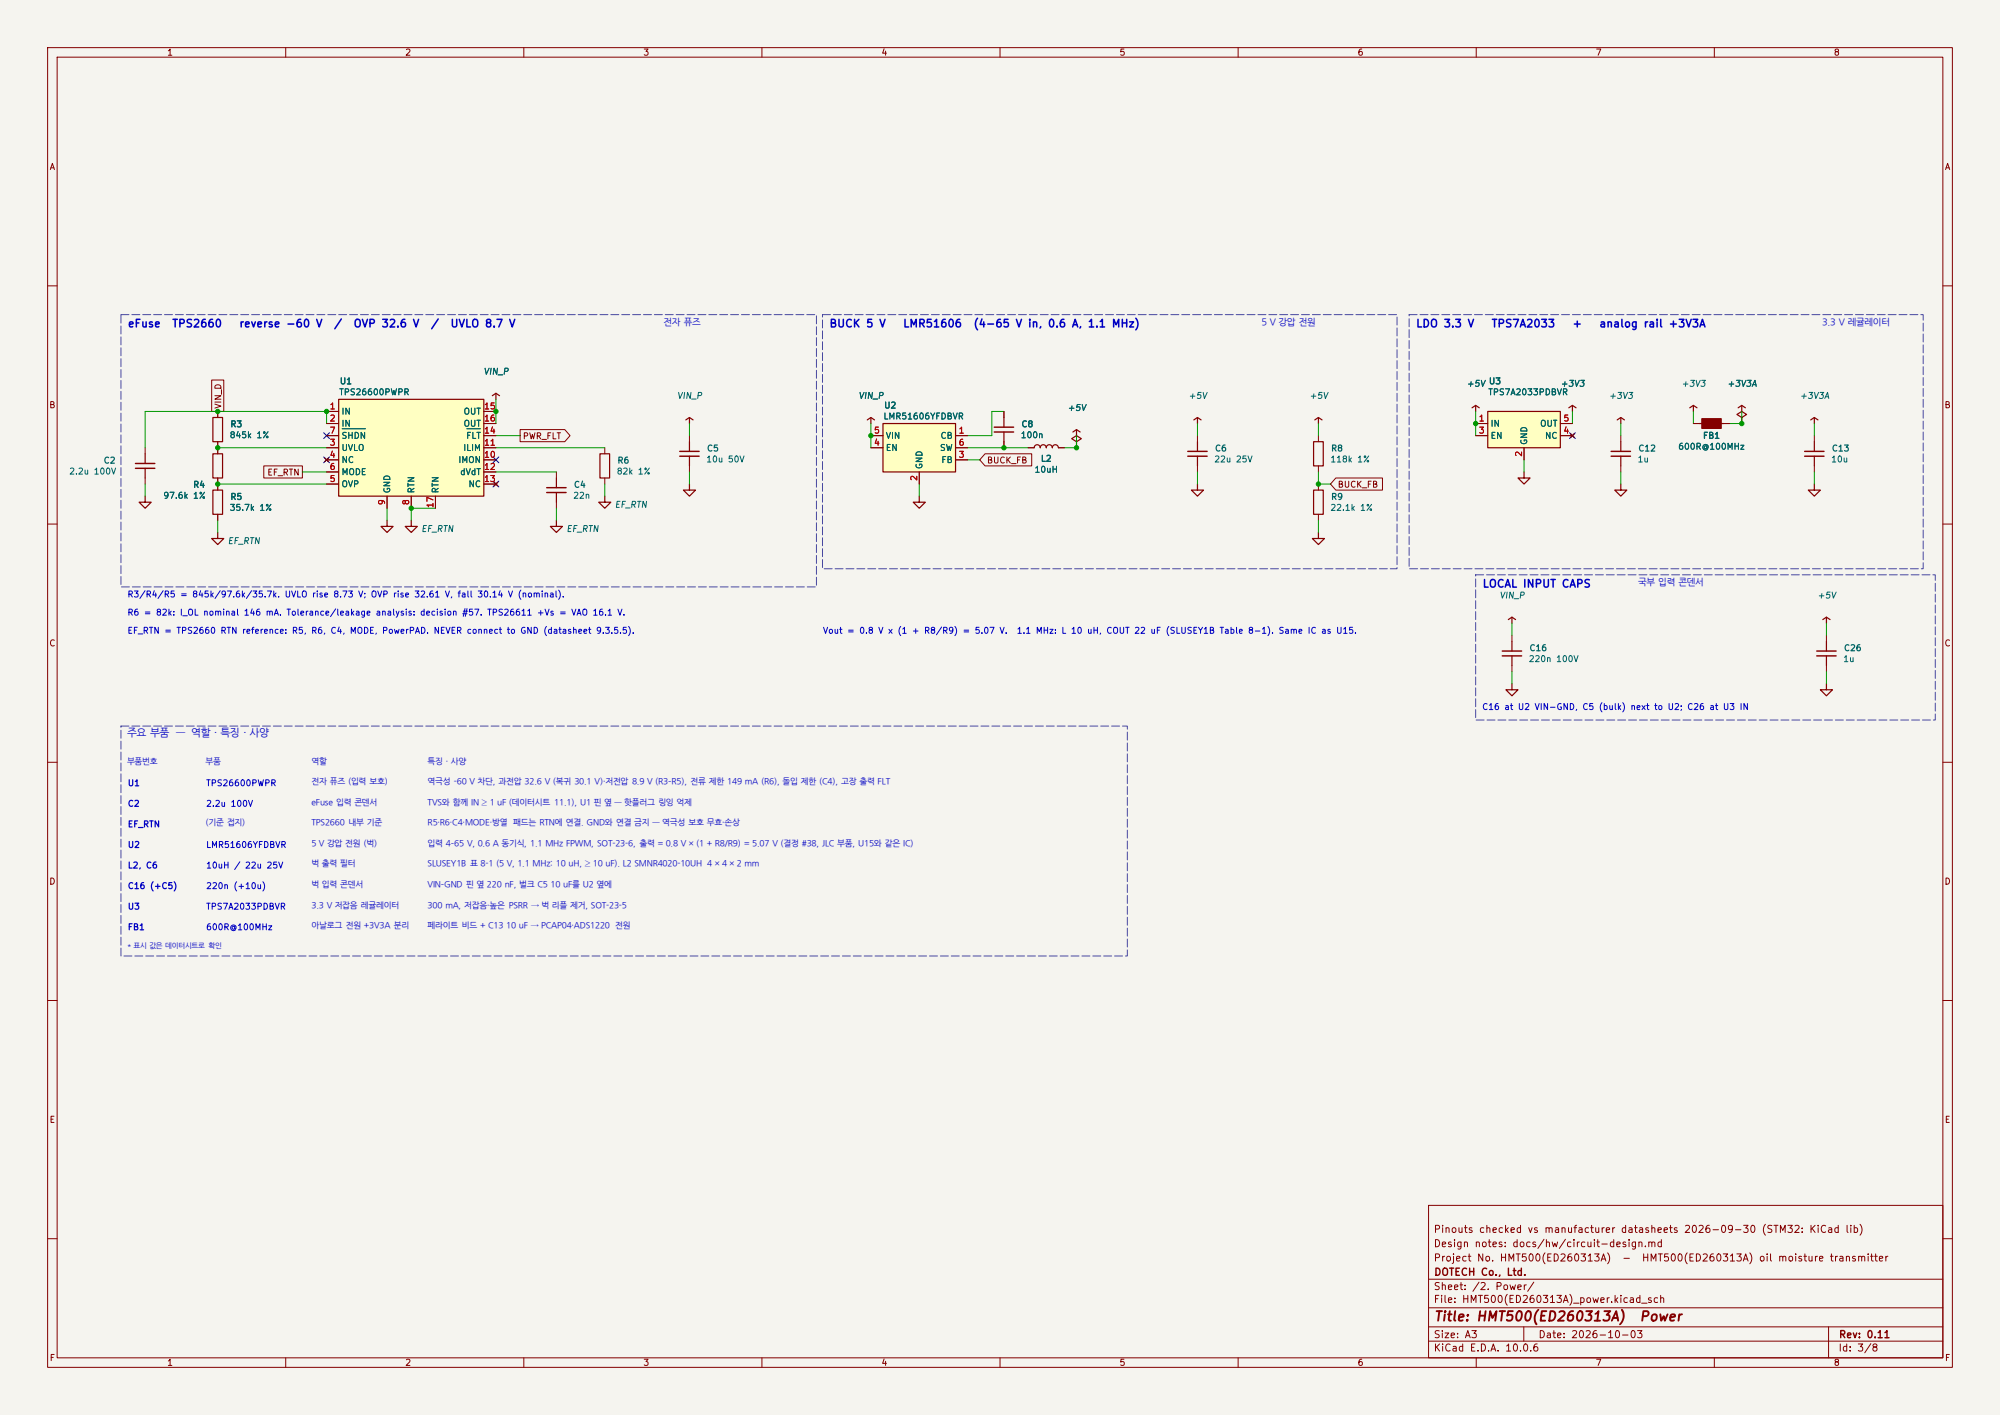
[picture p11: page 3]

C16 at U2 VIN-GND, C5 (bulk) next to U2; C26 at U3 IN

입력 4–65 V, 0.6 A 동기식, 1.1 MHz FPWM, SOT-23-6, 출력 = 0.8 V × (1 + R8/R9) = 5.07 V (결정 #38, JLC 부품, U15와 같은 IC) SLUSEY1B 표 8-1 (5 V, 1.1 MHz: 10 uH, ≥ 10 uF). L2 SMNR4020-10UH 4 × 4 × 2 mm 특징 · 사양

역극성 -60 V 차단, 과전압 32.6 V (복귀 30.1 V)·저전압 8.9 V (R3–R5), 전류 제한 149 mA (R6), 돌입 제한 (C4), 고장 출력 FLT

TVS와 함께 IN ≥ 1 uF (데이터시트 11.1), U1 핀 옆 — 핫플러그 링잉 억제

R5·R6·C4·MODE·방열 패드는 RTN에 연결. GND와 연결 금지 — 역극성 보호 무효·손상

VIN–GND 핀 옆 220 nF, 벌크 C5 10 uF를 U2 옆에

Pinouts checked vs manufacturer datasheets 2026-09-30 (STM32: KiCad lib)
Design notes: docs/hw/circuit-design.md
Project No. HMT500(ED260313A) - HMT500(ED260313A) oil moisture transmitter
DOTECH Co., Ltd.
Sheet: /2. Power/
File: HMT500(ED260313A)_power.kicad_sch
Title: HMT500(ED260313A) Power

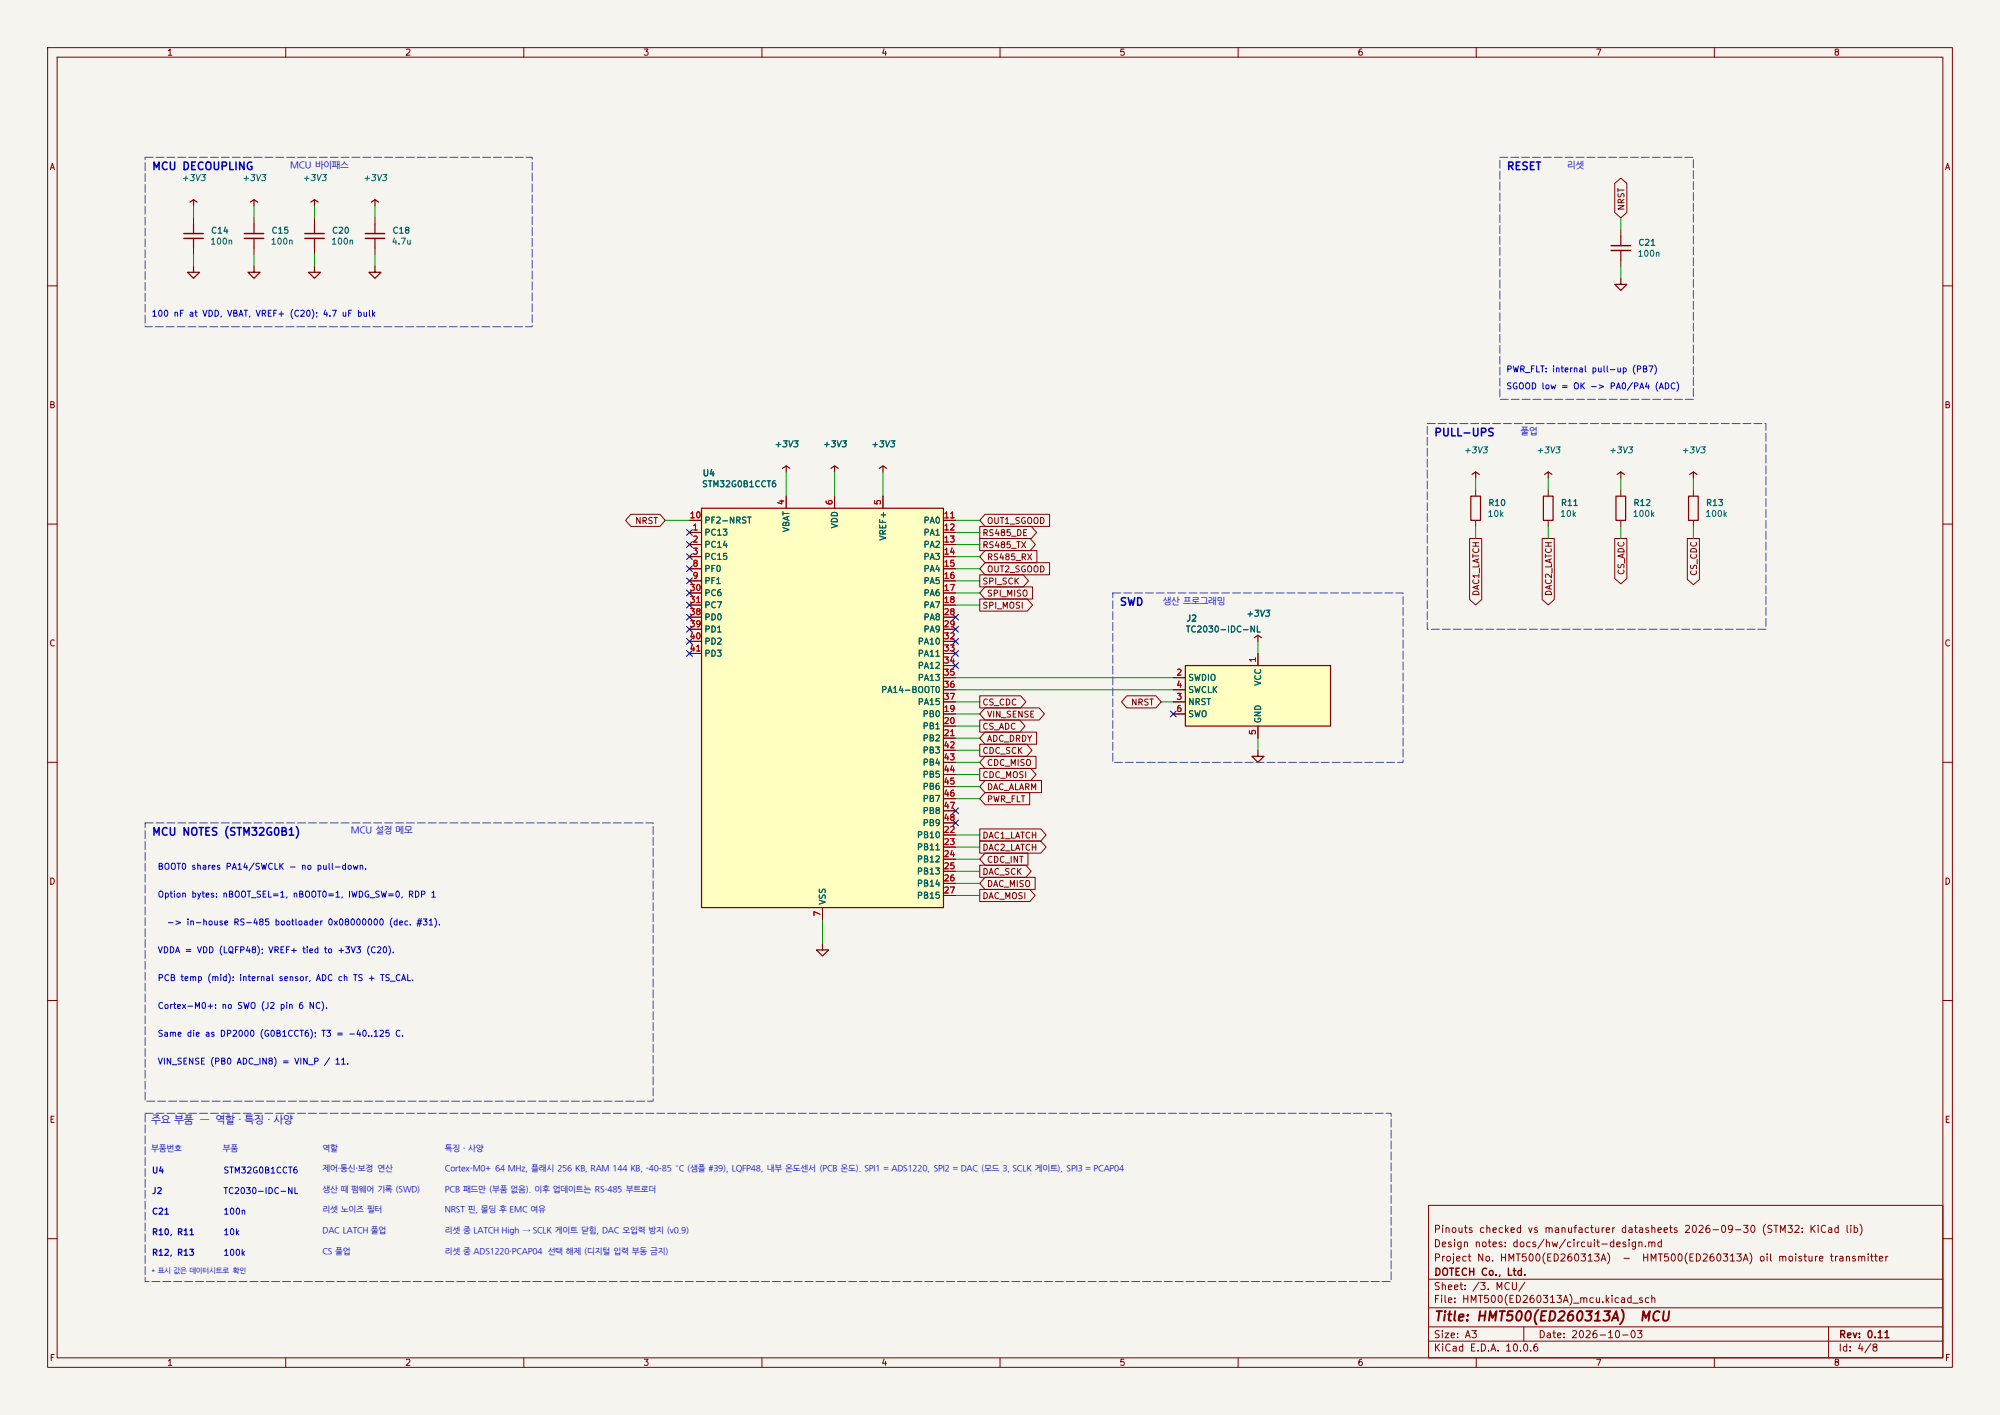
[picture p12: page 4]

100 nF at VDD, VBAT, VREF+ (C20); 4.7 uF bulk

PWR_FLT: internal pull-up (PB7) SGOOD low = OK -> PA0/PA4 (ADC)

* 표시 값은 데이터시트로 확인 -> in-house RS-485 bootloader 0x08000000 (dec. #31).

VDDA = VDD (LQFP48); VREF+ tied to +3V3 (C20). Cortex-M0+: no SWO (J2 pin 6 NC).

PCB temp (mid): internal sensor, ADC ch TS + TS_CAL. Same die as DP2000 (G0B1CCT6); T3 = -40..125 C.

생산 때 펌웨어 기록 (SWD)

PCB 패드만 (부품 없음). 이후 업데이트는 RS-485 부트로더

NRST 핀, 몰딩 후 EMC 여유

Pinouts checked vs manufacturer datasheets 2026-09-30 (STM32: KiCad lib)
Design notes: docs/hw/circuit-design.md
Project No. HMT500(ED260313A) - HMT500(ED260313A) oil moisture transmitter
DOTECH Co., Ltd.
Sheet: /3. MCU/
File: HMT500(ED260313A)_mcu.kicad_sch
Title: HMT500(ED260313A) MCU

리셋 중 ADS1220·PCAP04 선택 해제 (디지털 입력 부동 금지)

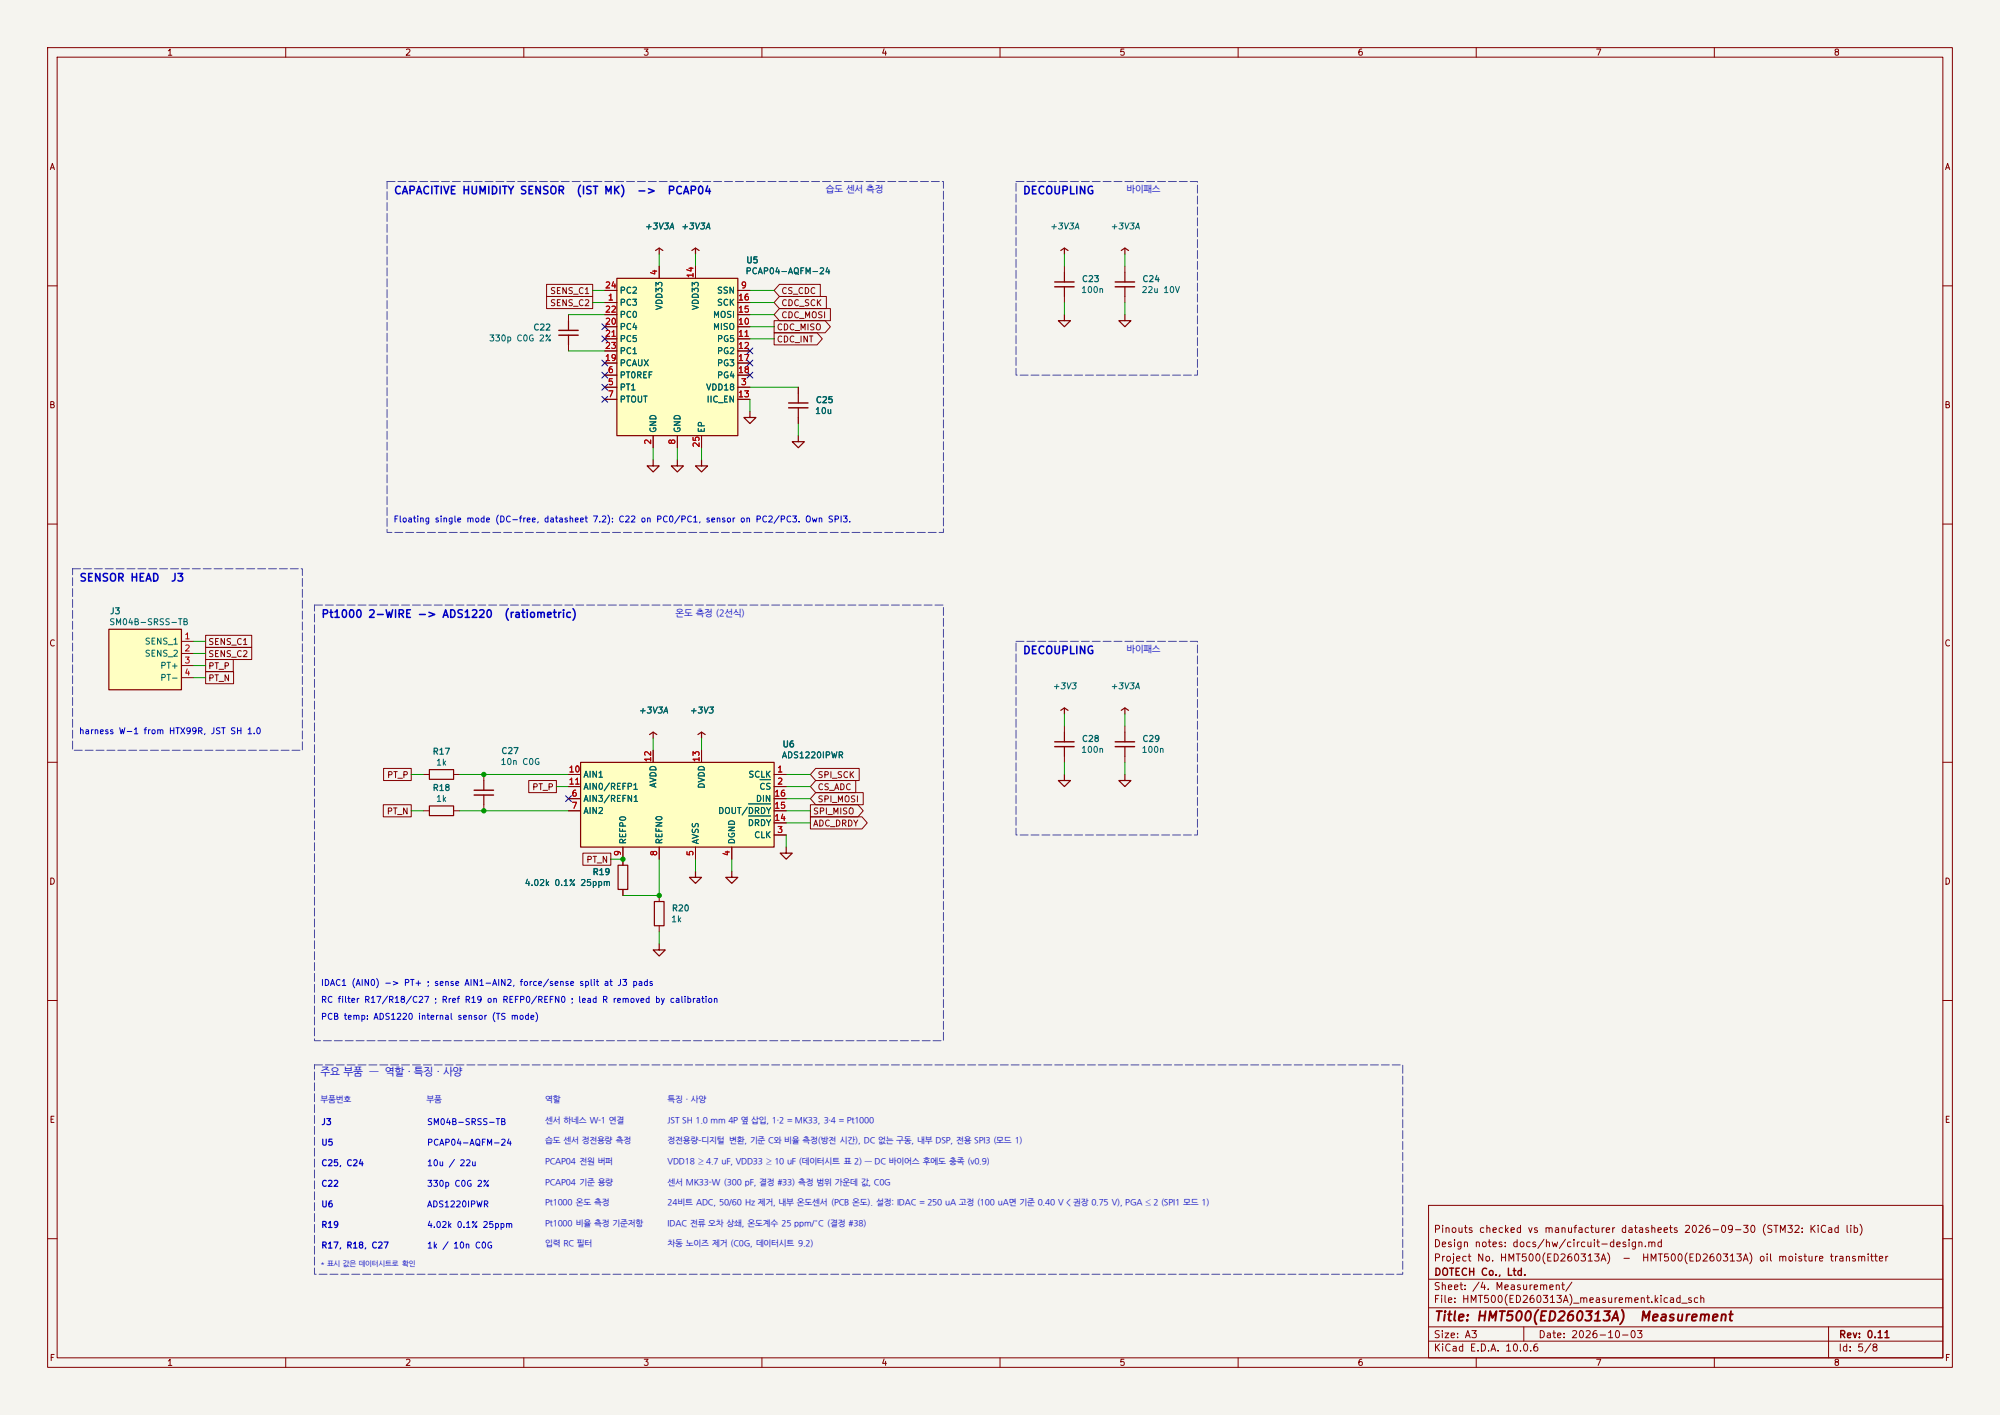
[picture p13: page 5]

CAPACITIVE HUMIDITY SENSOR (IST MK) -> PCAP04

Floating single mode (DC-free, datasheet 7.2): C22 on PC0/PC1, sensor on PC2/PC3. Own SPI3.

PCB temp: ADS1220 internal sensor (TS mode) harness W-1 from HTX99R, JST SH 1.0

IDAC1 (AIN0) -> PT+ ; sense AIN1-AIN2, force/sense split at J3 pads
RC filter R17/R18/C27 ; Rref R19 on REFP0/REFN0 ; lead R removed by calibration 역할

JST SH 1.0 mm 4P 옆 삽입, 1·2 = MK33, 3·4 = Pt1000 습도 센서 정전용량 측정

정전용량–디지털 변환, 기준 C와 비율 측정(방전 시간), DC 없는 구동, 내부 DSP, 전용 SPI3 (모드 1)

IDAC 전류 오차 상쇄, 온도계수 25 ppm/°C (결정 #38) VDD18 ≥ 4.7 uF, VDD33 ≥ 10 uF (데이터시트 표 2) — DC 바이어스 후에도 충족 (v0.9)

센서 MK33-W (300 pF, 결정 #33) 측정 범위 가운데 값, C0G

24비트 ADC, 50/60 Hz 제거, 내부 온도센서 (PCB 온도). 설정: IDAC = 250 uA 고정 (100 uA면 기준 0.40 V < 권장 0.75 V), PGA ≤ 2 (SPI1 모드 1)

Pinouts checked vs manufacturer datasheets 2026-09-30 (STM32: KiCad lib)
Design notes: docs/hw/circuit-design.md
Project No. HMT500(ED260313A) - HMT500(ED260313A) oil moisture transmitter
DOTECH Co., Ltd.
Sheet: /4. Measurement/
File: HMT500(ED260313A)_measurement.kicad_sch
Title: HMT500(ED260313A) Measurement

차동 노이즈 제거 (C0G, 데이터시트 9.2)

* 표시 값은 데이터시트로 확인

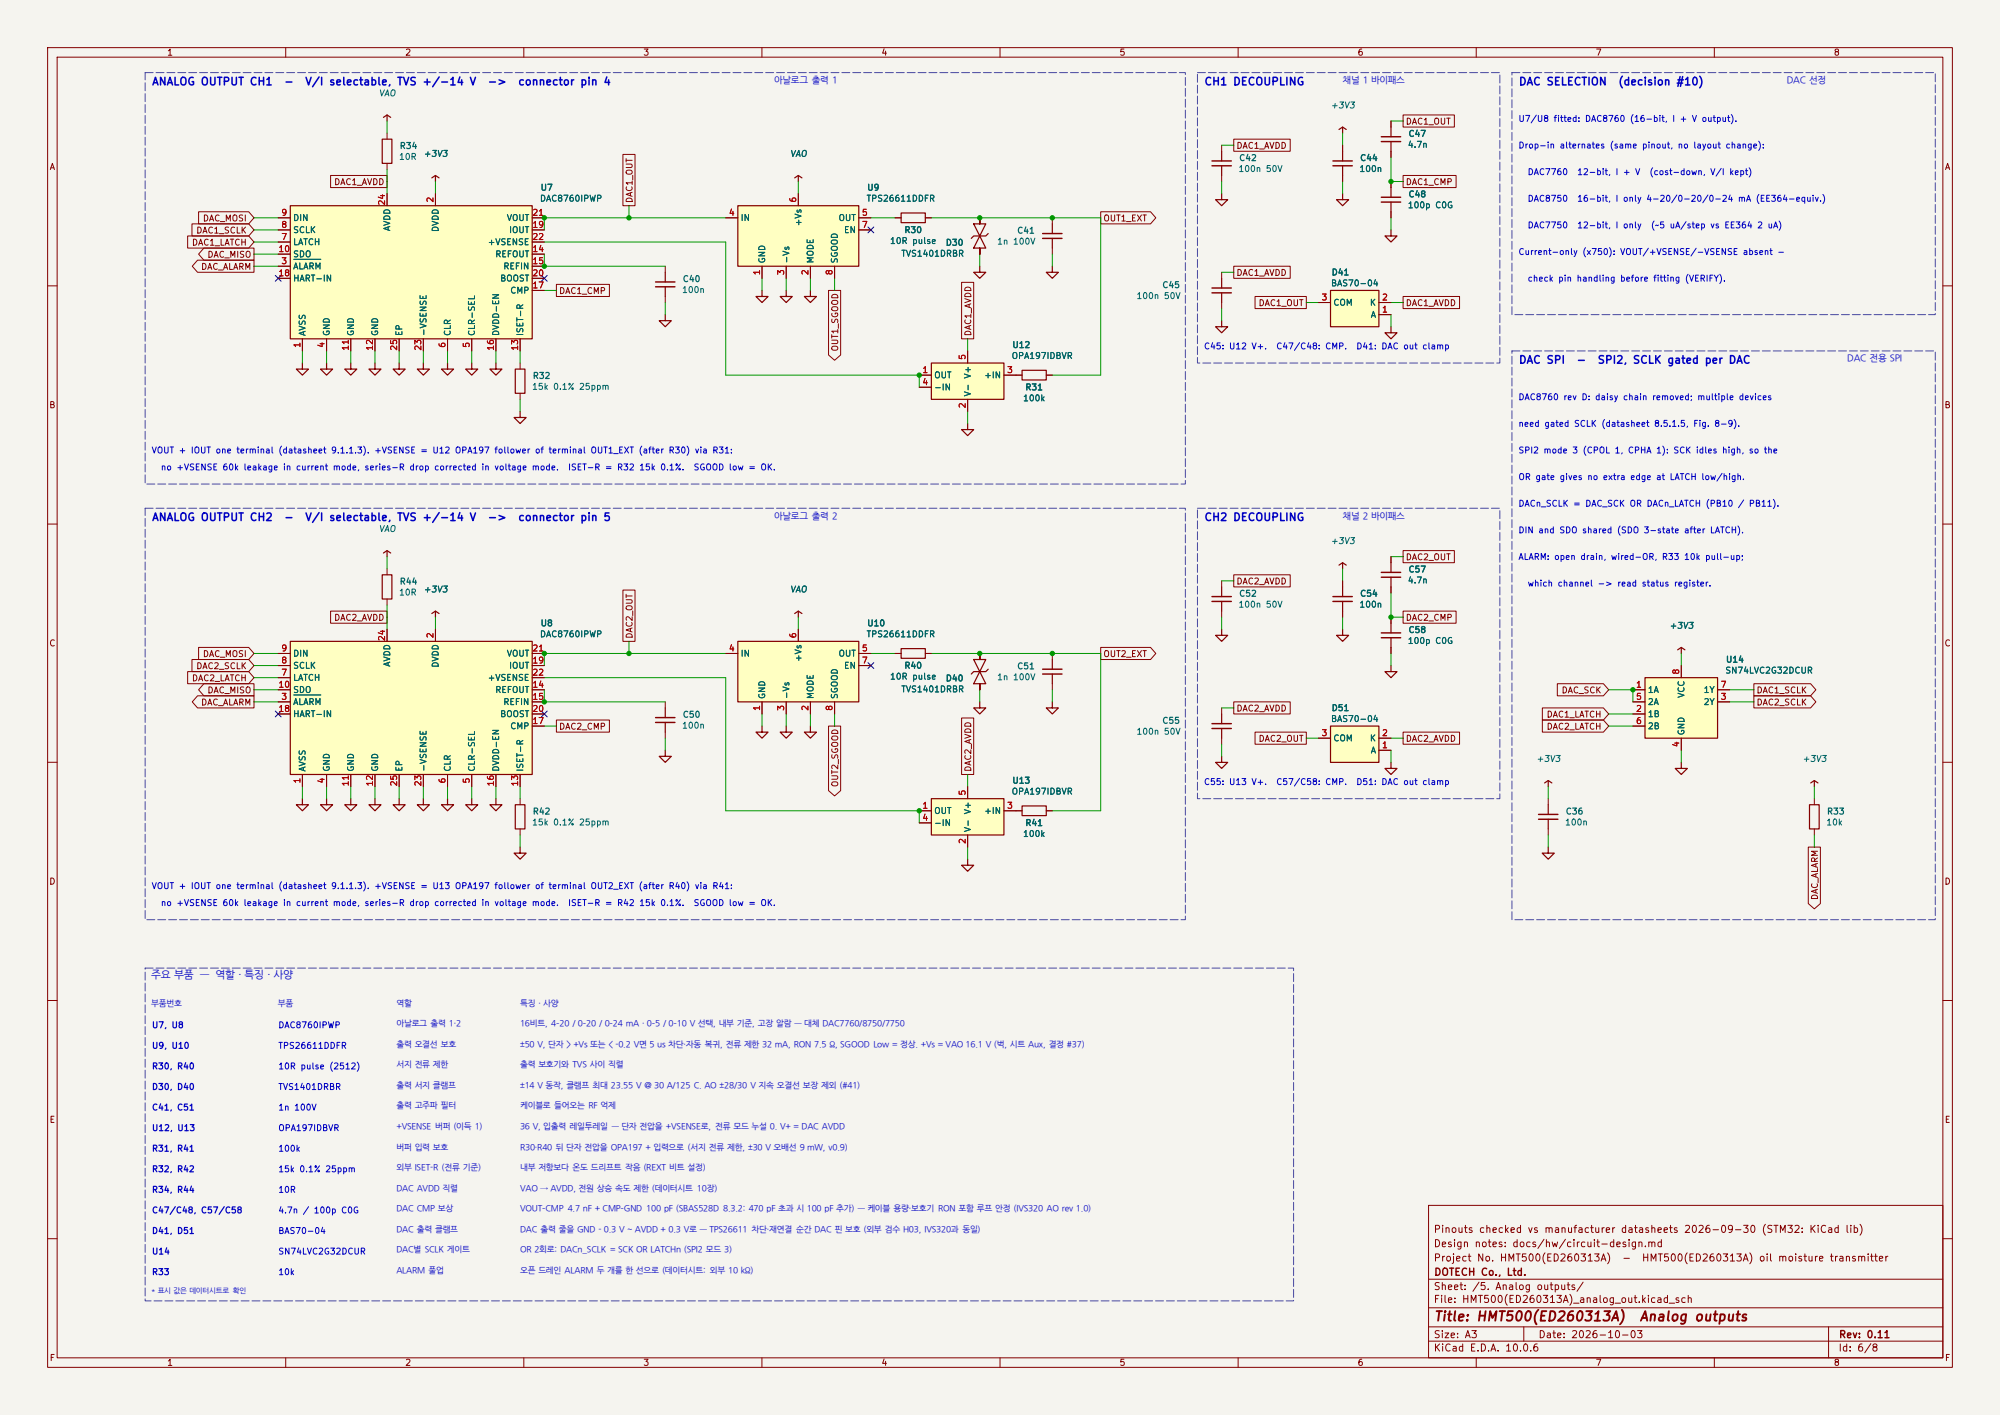
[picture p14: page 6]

아날로그 출력 1 ANALOG OUTPUT CH1 - V/I selectable, TVS +/-14 V -> connector pin 4
VAO AVSS

DAC7750 12-bit, I only (~5 uA/step vs EE364 2 uA) DAC8750 16-bit, I only 4-20/0-20/0-24 mA (EE364-equiv.)

Current-only (x750): VOUT/+VSENSE/-VSENSE absent -

check pin handling before fitting (VERIFY).

C45: U12 V+. C47/C48: CMP. D41: DAC out clamp

DAC SPI - SPI2, SCLK gated per DAC

DAC8760 rev D: daisy chain removed; multiple devices need gated SCLK (datasheet 8.5.1.5, Fig. 8-9). SPI2 mode 3 (CPOL 1, CPHA 1): SCK idles high, so the OR gate gives no extra edge at LATCH low/high.

VOUT + IOUT one terminal (datasheet 9.1.1.3). +VSENSE = U12 OPA197 follower of terminal OUT1_EXT (after R30) via R31:

no +VSENSE 60k leakage in current mode, series-R drop corrected in voltage mode. ISET-R = R32 15k 0.1%. SGOOD low = OK.

DIN and SDO shared (SDO 3-state after LATCH). ALARM: open drain, wired-OR, R33 10k pull-up; which channel -> read status register. DACn_SCLK = DAC_SCK OR DACn_LATCH (PB10 / PB11).

ANALOG OUTPUT CH2 - V/I selectable, TVS +/-14 V -> connector pin 5

VOUT + IOUT one terminal (datasheet 9.1.1.3). +VSENSE = U13 OPA197 follower of terminal OUT2_EXT (after R40) via R41: SN74LVC2G32DCUR
no +VSENSE 60k leakage in current mode, series-R drop corrected in voltage mode. ISET-R = R42 15k 0.1%. SGOOD low = OK.

16비트, 4–20 / 0–20 / 0–24 mA · 0–5 / 0–10 V 선택, 내부 기준, 고장 알람 — 대체 DAC7760/8750/7750

R30·R40 뒤 단자 전압을 OPA197 + 입력으로 (서지 전류 제한, ±30 V 오배선 9 mW, v0.9) ±14 V 동작, 클램프 최대 23.55 V @ 30 A/125 C. AO ±28/30 V 지속 오결선 보장 제외 (#41) ±50 V, 단자 > +Vs 또는 < -0.2 V면 5 us 차단·자동 복귀, 전류 제한 32 mA, RON 7.5 Ω, SGOOD Low = 정상. +Vs = VAO 16.1 V (벅, 시트 Aux, 결정 #37)

출력 보호기와 TVS 사이 직렬

케이블로 들어오는 RF 억제

36 V, 입출력 레일투레일 — 단자 전압을 +VSENSE로, 전류 모드 누설 0. V+ = DAC AVDD

내부 저항보다 온도 드리프트 작음 (REXT 비트 설정)

VOUT–CMP 4.7 nF + CMP–GND 100 pF (SBAS528D 8.3.2: 470 pF 초과 시 100 pF 추가) — 케이블 용량·보호기 RON 포함 루프 안정 (IVS320 AO rev 1.0) DAC 출력 줄을 GND - 0.3 V ~ AVDD + 0.3 V로 — TPS26611 차단·재연결 순간 DAC 핀 보호 (외부 검수 H03, IVS320과 동일) OR 2회로: DACn_SCLK = SCK OR LATCHn (SPI2 모드 3) 오픈 드레인 ALARM 두 개를 한 선으로 (데이터시트: 외부 10 kΩ) VAO → AVDD, 전원 상승 속도 제한 (데이터시트 10장) DAC CMP 보상

Pinouts checked vs manufacturer datasheets 2026-09-30 (STM32: KiCad lib)
Design notes: docs/hw/circuit-design.md
Project No. HMT500(ED260313A) - HMT500(ED260313A) oil moisture transmitter
DOTECH Co., Ltd.
Sheet: /5. Analog outputs/
File: HMT500(ED260313A)_analog_out.kicad_sch
Title: HMT500(ED260313A) Analog outputs

* 표시 값은 데이터시트로 확인

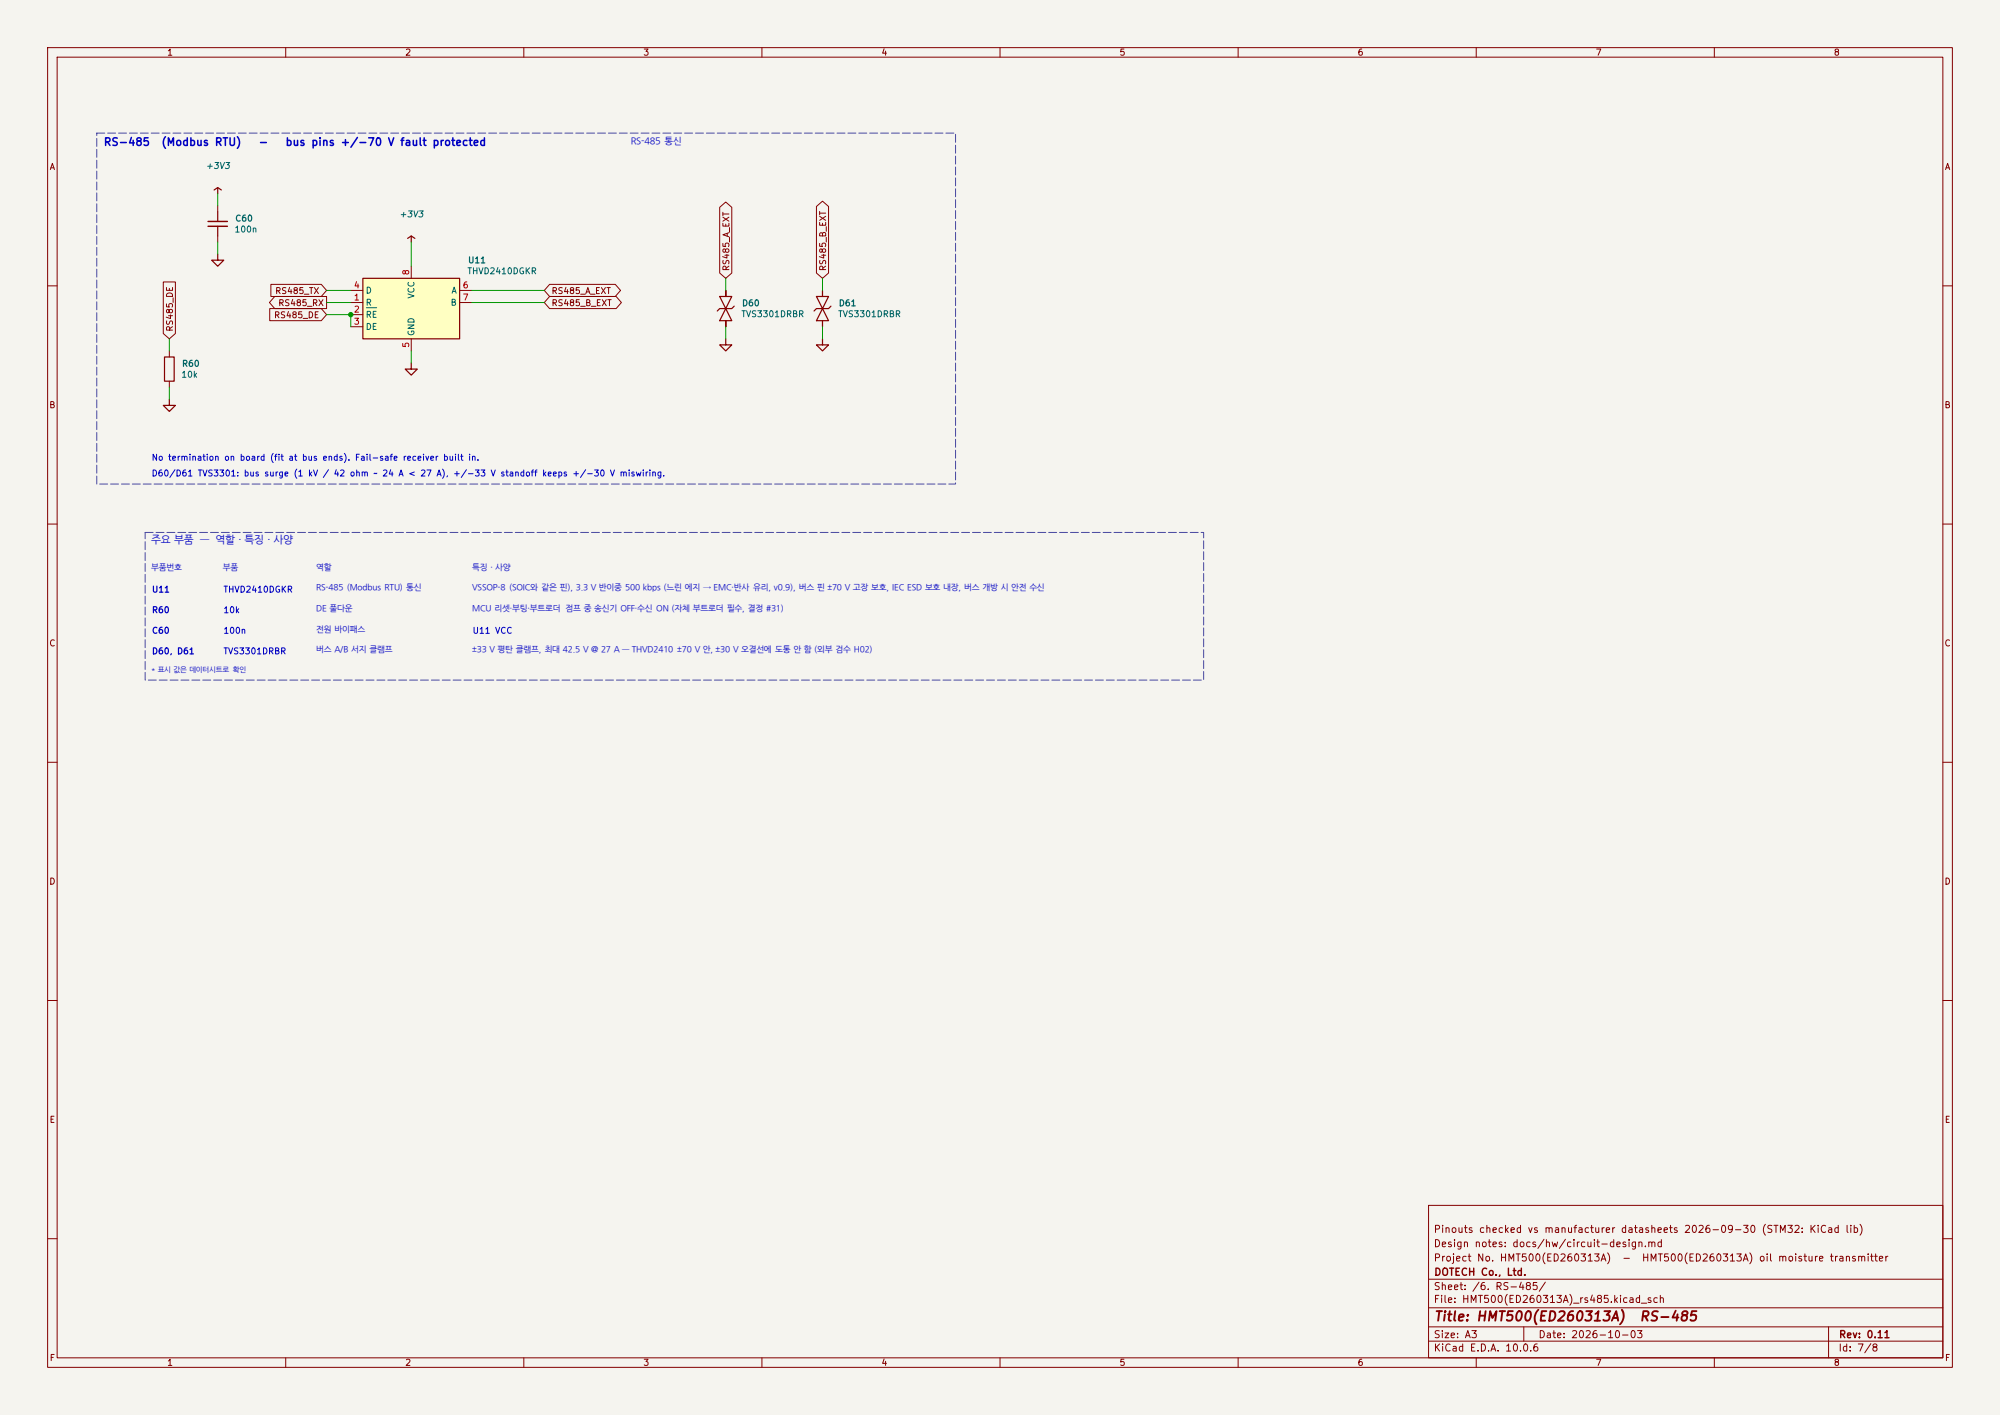
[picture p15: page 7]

D60/D61 TVS3301: bus surge (1 kV / 42 ohm ~ 24 A < 27 A), +/-33 V standoff keeps +/-30 V miswiring. RS-485 통신

VSSOP-8 (SOIC와 같은 핀), 3.3 V 반이중 500 kbps (느린 에지 → EMC·반사 유리, v0.9), 버스 핀 ±70 V 고장 보호, IEC ESD 보호 내장, 버스 개방 시 안전 수신

Pinouts checked vs manufacturer datasheets 2026-09-30 (STM32: KiCad lib)
Design notes: docs/hw/circuit-design.md
Project No. HMT500(ED260313A) - HMT500(ED260313A) oil moisture transmitter
DOTECH Co., Ltd.
Sheet: /6. RS-485/
File: HMT500(ED260313A)_rs485.kicad_sch
Title: HMT500(ED260313A) RS-485

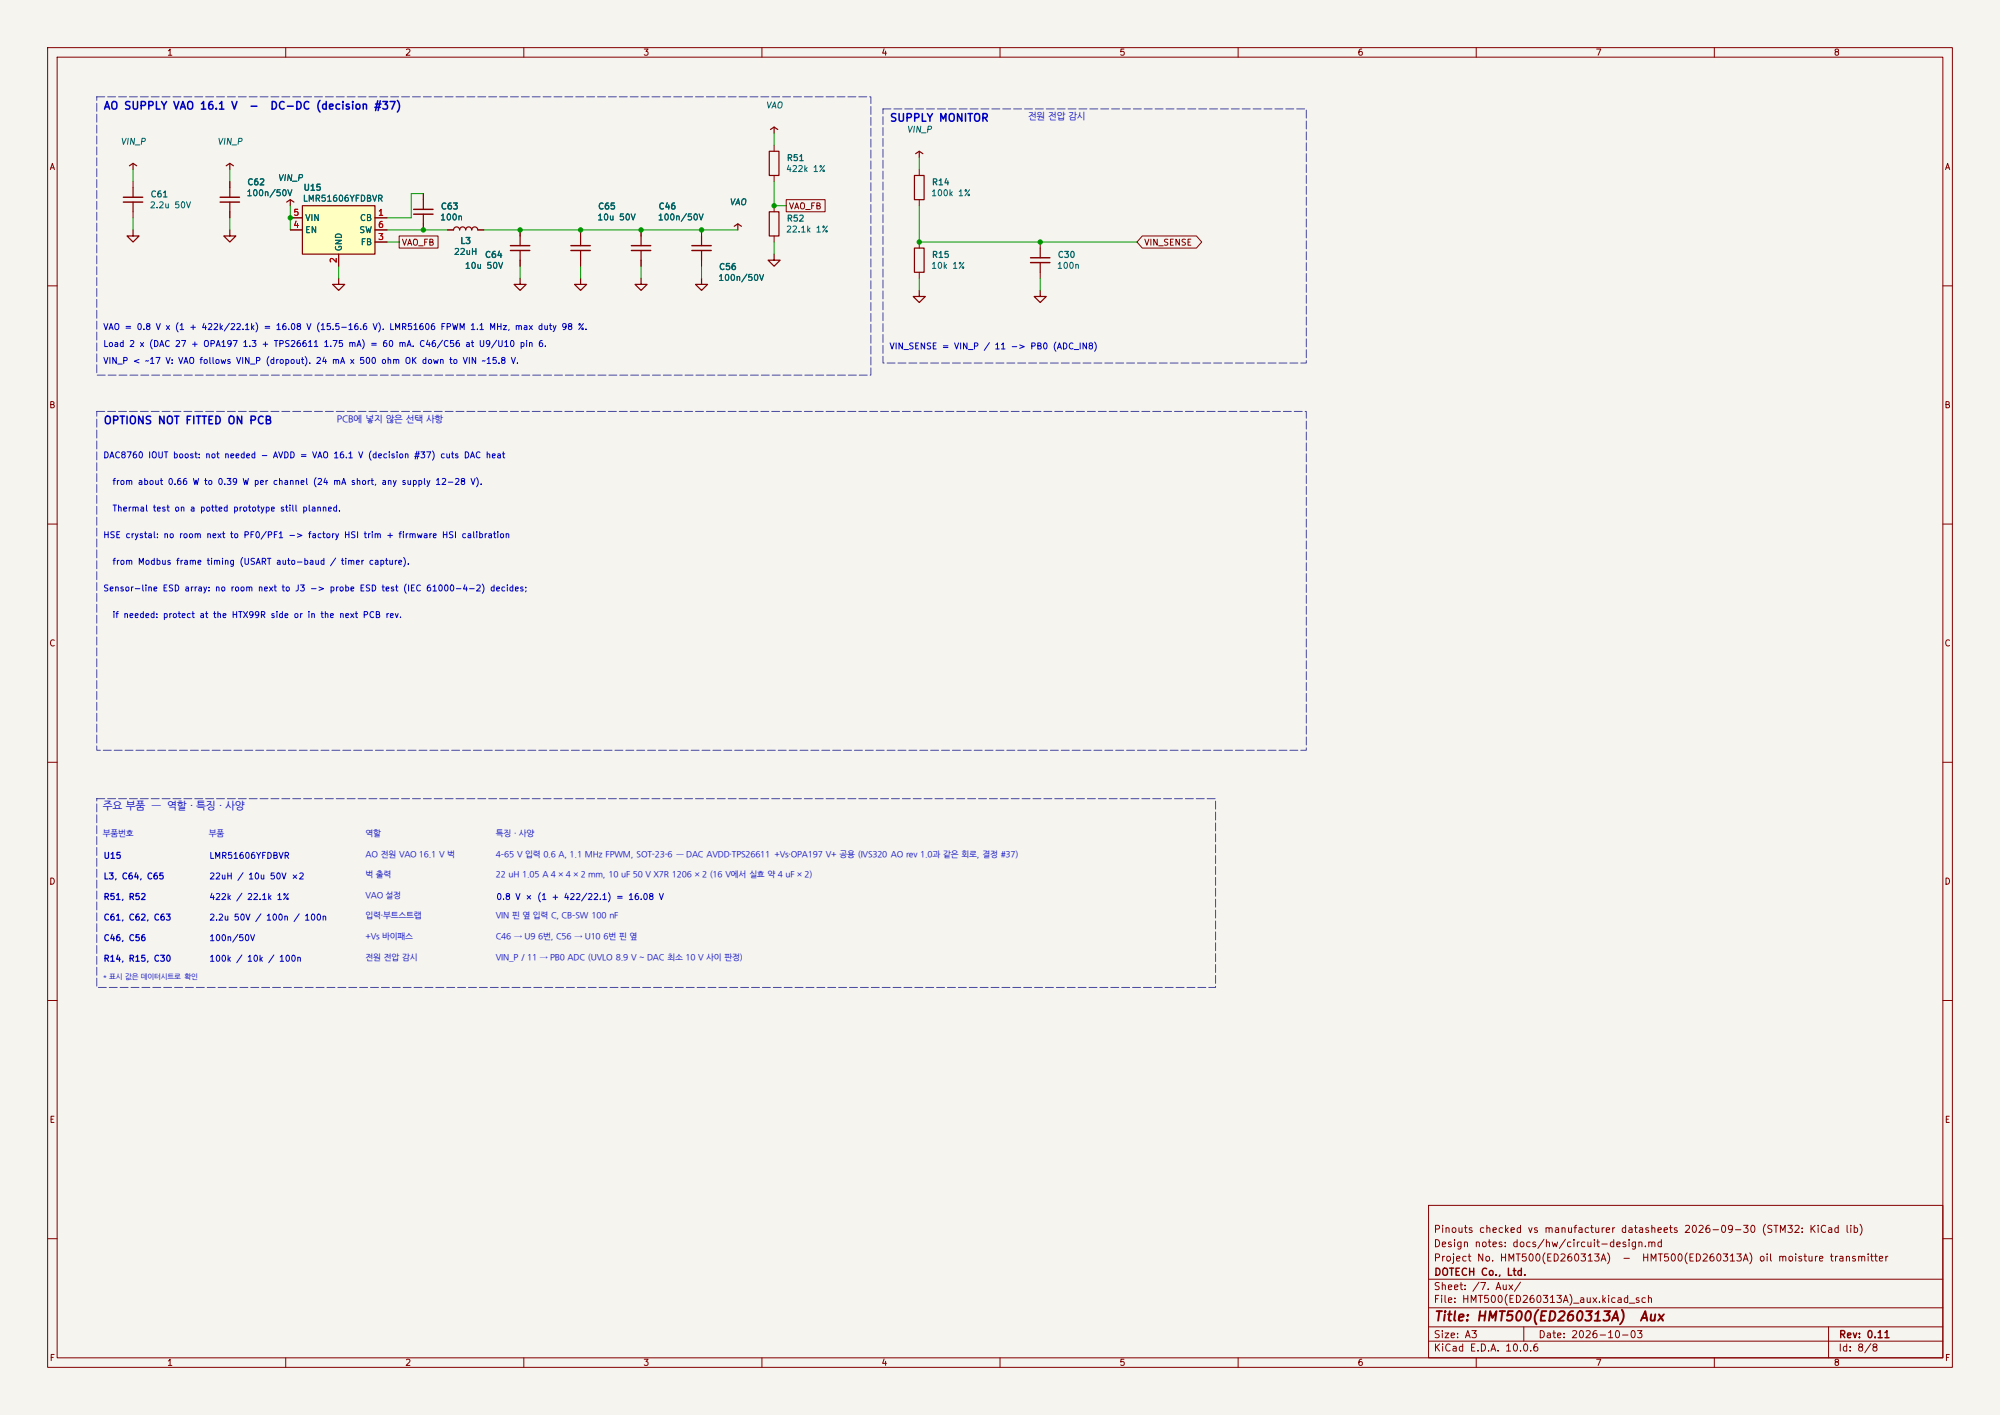
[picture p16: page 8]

VAO = 0.8 V x (1 + 422k/22.1k) = 16.08 V (15.5-16.6 V). LMR51606 FPWM 1.1 MHz, max duty 98 %. Load 2 x (DAC 27 + OPA197 1.3 + TPS26611 1.75 mA) = 60 mA. C46/C56 at U9/U10 pin 6. VIN_P < ~17 V: VAO follows VIN_P (dropout). 24 mA x 500 ohm OK down to VIN ~15.8 V. AO SUPPLY VAO 16.1 V - DC-DC (decision #37)

from about 0.66 W to 0.39 W per channel (24 mA short, any supply 12-28 V). Thermal test on a potted prototype still planned. HSE crystal: no room next to PF0/PF1 -> factory HSI trim + firmware HSI calibration 0.8 V × (1 + 422/22.1) = 16.08 V OPTIONS NOT FITTED ON PCB

PCB에 넣지 않은 선택 사항

DAC8760 IOUT boost: not needed - AVDD = VAO 16.1 V (decision #37) cuts DAC heat

from Modbus frame timing (USART auto-baud / timer capture).

22 uH 1.05 A 4 × 4 × 2 mm, 10 uF 50 V X7R 1206 × 2 (16 V에서 실효 약 4 uF × 2) 4–65 V 입력 0.6 A, 1.1 MHz FPWM, SOT-23-6 — DAC AVDD·TPS26611 +Vs·OPA197 V+ 공용 (IVS320 AO rev 1.0과 같은 회로, 결정 #37) VIN_P / 11 → PB0 ADC (UVLO 8.9 V ~ DAC 최소 10 V 사이 판정)

* 표시 값은 데이터시트로 확인

Pinouts checked vs manufacturer datasheets 2026-09-30 (STM32: KiCad lib)
Design notes: docs/hw/circuit-design.md
Project No. HMT500(ED260313A) - HMT500(ED260313A) oil moisture transmitter
DOTECH Co., Ltd.
Sheet: /7. Aux/
File: HMT500(ED260313A)_aux.kicad_sch
Title: HMT500(ED260313A) Aux

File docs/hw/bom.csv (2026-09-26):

no | block | part | qty | unit_usd_low | unit_usd_high | ext_usd_low | ext_usd_high | basis
1 | MCU | STM32G0B1CCT3 | 1 | 1.5 | 2.5 | 1.5 | 2.5 | domestic distributor (G0B1CCT6 in use for DP2000)
2 | Capacitance | PCAP04-AQFM-24 | 1 | 6.5 | 7.1 | 6.5 | 7.1 | DigiKey
3 | RTD ADC | ADS1220IPWR | 1 | 1.9 | 3.5 | 1.9 | 3.5 | LCSC / estimate
4 | Analog out | DAC8760IPWP | 2 | 7.8 | 12.4 | 15.7 | 24.7 | DigiKey/Mouser 1k
5 | RS-485 | THVD2450DR (70V fault protected) | 1 | 1.5 | 3 | 1.5 | 3 | estimate
6 | Power | LMR36006 + inductor | 1 | 1.1 | 1.8 | 1.1 | 1.8 | LCSC / estimate
7 | Power | TPS7A2033PDBVR | 1 | 0.07 | 0.3 | 0.1 | 0.3 | LCSC
8 | Protection | TVS 2-stage/CM choke/pulse R/GDT set | 1 | 1.5 | 4 | 1.5 | 4 | estimate
14 | Protection | TPS2660 eFuse | 1 | 1.5 | 3 | 1.5 | 3 | estimate
15 | Protection | TPS26611 output protector | 2 | 1.2 | 2.5 | 2.4 | 5 | estimate
9 | Temperature | Pt1000 thin film Class A | 1 | 0.5 | 3 | 0.5 | 3 | estimate
10 | Reference | C0G ref cap + 0.01% resistor | 1 | 0.6 | 2 | 0.6 | 2 | estimate
11 | Passives | R/C/crystal set | 1 | 0.5 | 1.5 | 0.5 | 1.5 | estimate
12 | PCB | round 4-layer x2 | 1 | 0.8 | 2 | 0.8 | 2 | estimate
13 | Indicator | status LED (option) | 1 | 0.05 | 0.05 | 0.05 | 0.05 | estimate
 |  | TOTAL (excl. connector/sensor/assembly) |  |  |  | 36.35 | 64.05

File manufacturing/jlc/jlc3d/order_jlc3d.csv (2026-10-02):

Part | Name | File | Material | Qty | Note
HMT500-T-001 | W-2 plug push bar (assembly tool) | HMT500-T-001_W-2_plug_push_bar_assembly_tool.stl | MJF PA12-HP Nylon | 1 | 조립 공구 (제품 아님). 끝 두께 3.0, 가운데 홈 10.4
HMT500-M-105 | PCB holder — prototype | HMT500-M-105_PCB_holder.stl | MJF PA12-HP Nylon | 1 | 제품 시제품. 출력 후 홈/외경 검사·다듬기 및 M2 탭 필요; 부족 치수 재출력
HMT500-M-106 | Support ring — prototype | HMT500-M-106_Support_ring.stl | MJF PA12-HP Nylon | 1 | 제품 시제품. 출력 후 홈/외경 검사·다듬기 필요; 부족 치수 재출력

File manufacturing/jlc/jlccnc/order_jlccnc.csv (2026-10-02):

Part | Name | 3D (STEP) | 2D (PDF) | Material | Alternative | Finish | Threads | Tolerance | Qty | Note
HMT500-M-101 | Process body | HMT500-M-101_body_SUS304.step | HMT500-M-101_drawing_revJ_SUS304.pdf | SUS304 (이번 시제품, JLCCNC 온라인 선택지) | 양산: SUS316L (1.4404) — 접액부 | As machined + 부동태화 (ASTM A967), 버 제거 | G1/2-A (ISO 228-1) 수나사 (x −14~−2); M26x1-6g 수나사; M10x1.0-6H 암나사 깊이 5.5; 2×M2-6H 깊이 5 (카운터보어 바닥, PCD 16) | O링 자리 Ø27 f7, 커넥터 밀봉면 Ø10 H8, 캡 칼라 Ø12.3 (+0.1/0), 나머지 ISO 2768-mK, 밀봉면 Ra 0.8 | 1 | Rev H: 칼라 Ø30, 육각 AF27 × 10. G½ 앞면에 캡 칼라 Ø12.3 × 3.5. Ø7 관통 통로 길이 12.5. 1개/세트
HMT500-M-102 | Sensor protection cap (oil filter) | HMT500-M-102_cap_SUS304.step | HMT500-M-102_drawing_revJ_SUS304.pdf | SUS304 (두텍 원도면 390000-001100 재질) | SUS316L (접액부 통일 시) | As machined + 부동태화, 버 제거 (구멍 안쪽 포함) | M10x1.0 암나사 깊이 8.5 (HTX99R 위 나사, 두텍 확인) | 외경 Ø12, 센서실 Ø8, 측면 25×Ø3 (5줄 × 5개, 72°), 끝 Ø3, 끝 C1, 열린 끝 Ø11 × 1, 나머지 ISO 2768-mK | 1 | 두텍 390000-001100 (도면 2020-06-08) 기반, Rev H: 끝 쪽 5.5 연장 (전장 37.5) + 옆 구멍 1줄. 1개/세트
HMT500-M-103 | Housing tube | HMT500-M-103_housing_SUS304.step | HMT500-M-103_drawing_revJ_SUS304.pdf | SUS304 (이번 시제품) | 양산: SUS316L 또는 SUS304 (비접액부) | As machined + 부동태화, 외면 레이저 마킹 (문안 별도) | 앞 M26x1-6H (오른나사) 암나사 길이 7; 뒤 M26x1-LH-6H (왼나사 LH) 암나사 길이 7 | Ø30 / 안 Ø25, O링 자리 Ø27 H8 양 끝 (길이 4), 나머지 ISO 2768-mK | 1 | 턴버클: 앞 오른나사 / 뒤 왼나사 — 주문 메모에 반드시 표기. 1개/세트
HMT500-M-104 | End cap | HMT500-M-104_endcap_SUS304.step | HMT500-M-104_drawing_revJ_SUS304.pdf | SUS304 (이번 시제품) | 양산: SUS316L 또는 SUS304 | As machined + 부동태화 | M26x1-LH-6g (왼나사 LH) 수나사; M16x1.5-6H 암나사 (M12 커넥터); 2×M3 깊이 4 / Ø2.5 관통 (입구 r 11.8, 90°·270°, 안쪽 경사 20°) | O링 자리 Ø27 f7 + 홈, 플랜지 Ø30 맞변 AF27, 나머지 ISO 2768-mK | 1 | 왼나사 표기 필수. 1개/세트

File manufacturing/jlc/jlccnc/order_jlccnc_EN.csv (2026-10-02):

Part | Name | 3D (STEP) | 2D (PDF) | Material | Finish | Threads | Tolerance | Qty | Note
HMT500-M-101 | Process body | HMT500-M-101_body_SUS304.step | HMT500-M-101_drawing_revJ_SUS304.pdf | Stainless steel SUS304 for this prototype lot (316L for production) | As machined, deburr, passivation (ASTM A967) | G1/2-A (ISO 228-1) external; M26x1-6g external (right hand); M10x1.0-6H internal, thread length 5.5 (ends 8.0 behind the connector seat face, after dia 11.2 x 1 counterbore and dia 10 H8 x 1.5 seal bore); 2x M2-6H tapped, depth 5, on counterbore bottom, PCD 16 | O-ring seat dia 27 f7; connector seal bore dia 10 H8; sealing faces Ra 0.8; others ISO 2768-mK | 1 | No front tube: the part starts with the G1/2 thread. Front sleeve bore dia 12.3 (+0.1/0) x 3.5 deep, machined into the G1/2 front face (holds the cap root against side load; connector seat face at its bottom). Through channel dia 7 x 12.5 long. Hex AF27 x 10 long with 30 deg chamfer; collar dia 30.
HMT500-M-102 | Sensor protection cap | HMT500-M-102_cap_SUS304.step | HMT500-M-102_drawing_revJ_SUS304.pdf | Stainless steel SUS304 (wetted, oil) | As machined, deburr inside and outside of all holes, passivation | M10x1.0-6H internal (fine pitch 1.0), depth 8.5 from the open end | OD 12; bore dia 8; 25x dia 3 radial holes (5 rows at 6.5/11.5/16.5/21.5/26.5 mm from the tip x 5 holes at 72 deg, same angles each row); tip hole dia 3; tip chamfer C1; open-end relief dia 11 x 1; others ISO 2768-mK | 1 | Filter cap screwed onto the sensor connector, overall length 37.5. Drawing sheet M-102~104 (cap at top).
HMT500-M-103 | Housing tube | HMT500-M-103_housing_SUS304.step | HMT500-M-103_drawing_revJ_SUS304.pdf | Stainless steel SUS304 | As machined, deburr, passivation; outer laser marking if available (text supplied later) | Front: M26x1-6H internal, RIGHT hand, length 7; Rear: M26x1-LH-6H internal, LEFT hand, length 7 | OD 30, ID 25, length 60; O-ring bores dia 27 H8 at both ends (length 4), Ra 0.8, C0.5 lead-in chamfers; others ISO 2768-mK | 1 | Turnbuckle tube: front thread RIGHT hand, rear thread LEFT hand. Please confirm.
HMT500-M-104 | End cap | HMT500-M-104_endcap_SUS304.step | HMT500-M-104_drawing_revJ_SUS304.pdf | Stainless steel SUS304 | As machined, deburr, passivation | M26x1-LH-6g external, LEFT hand; M16x1.5-6H internal, length 6 (connector, TENTATIVE - will be confirmed with the connector part number; please quote as M16x1.5); 2x M3 depth 4 mm, pilot dia 2.5 through, inclined 20 deg inward from axial direction (fill/vent ports, entry r11.8 at 90/270 deg) | O-ring seat dia 27 f7 with groove, Ra 0.8; flange dia 30 x 4 with wrench flats AF27; others ISO 2768-mK | 1 | LEFT hand external thread. Fill/vent access assumes connector shoulder OD <=20 and axial tool/nozzle OD <=2.5. Actual connector P/N must be confirmed before manufacture.

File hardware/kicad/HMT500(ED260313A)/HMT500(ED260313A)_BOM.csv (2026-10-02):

Qty | References | Symbol | Value | Footprint | Verify
1 | C1 | C | 100n 100V | Capacitor_SMD:C_0805_2012Metric
1 | C2 | C | 2.2u 100V | Capacitor_SMD:C_1210_3225Metric
1 | C3 | C | 4.7n 2kV | Capacitor_SMD:C_1812_4532Metric
1 | C4 | C | 22n | Capacitor_SMD:C_0402_1005Metric
3 | C5 C64 C65 | C | 10u 50V | Capacitor_SMD:C_1206_3216Metric
1 | C6 | C | 22u 25V | Capacitor_SMD:C_1210_3225Metric
16 | C8 C14 C15 C20 C21 C23 C28 C29 C30 C36 C40 C44 C50 C54 C60 C63 | C | 100n | Capacitor_SMD:C_0402_1005Metric
2 | C12 C26 | C | 1u | Capacitor_SMD:C_0402_1005Metric
2 | C13 C25 | C | 10u | Capacitor_SMD:C_1206_3216Metric
1 | C16 | C | 220n 100V | Capacitor_SMD:C_0805_2012Metric
1 | C18 | C | 4.7u | Capacitor_SMD:C_0805_2012Metric
1 | C22 | C | 330p C0G 2% | Capacitor_SMD:C_0603_1608Metric
1 | C24 | C | 22u 10V | Capacitor_SMD:C_1206_3216Metric
1 | C27 | C | 10n C0G | Capacitor_SMD:C_0603_1608Metric
2 | C41 C51 | C | 1n 100V | Capacitor_SMD:C_0603_1608Metric
4 | C42 C45 C52 C55 | C | 100n 50V | Capacitor_SMD:C_0805_2012Metric
3 | C46 C56 C62 | C | 100n/50V | Capacitor_SMD:C_0603_1608Metric
2 | C47 C57 | C | 4.7n | Capacitor_SMD:C_0402_1005Metric
2 | C48 C58 | C | 100p C0G | Capacitor_SMD:C_0402_1005Metric
1 | C61 | C | 2.2u 50V | Capacitor_SMD:C_0805_2012Metric
1 | D1 | TVS_BI | SMDJ36CA | Diode_SMD:D_SMC
3 | D2 D60 D61 | TVS3301 | TVS3301DRBR | HMT500_260313A:Texas_DRB0008A_PadFloat
1 | D3 | SCHOTTKY | PMEG10010ELR | Diode_SMD:D_SOD-123F
2 | D30 D40 | TVS1401 | TVS1401DRBR | HMT500_260313A:Texas_DRB0008A_PadFloat
2 | D41 D51 | BAS70-04 | BAS70-04 | Package_TO_SOT_SMD:SOT-23
1 | FB1 | FB | 600R@100MHz | Inductor_SMD:L_0603_1608Metric
1 | GDT1 | GDT | 2035-25-SM | HMT500_260313A:GDT_Bourns_2035-xx-SM
1 | J1 | CONN_GH8 | SM08B-GHS-TB | Connector_JST:JST_GH_SM08B-GHS-TB_1x08-1MP_P1.25mm_Horizontal
1 | J2 | CONN_SWD | TC2030-IDC-NL | Connector:Tag-Connect_TC2030-IDC-NL_2x03_P1.27mm_Vertical
1 | J3 | CONN_SH4 | SM04B-SRSS-TB | Connector_JST:JST_SH_SM04B-SRSS-TB_1x04-1MP_P1.00mm_Horizontal
1 | J5 | CONN_CH | CHASSIS wire | HMT500_260313A:SolderWire_Chassis_D0.6mm
1 | L1 | CMC | CMC 1mH 0.8A | Inductor_SMD:L_CommonMode_Wuerth_WE-SL2
1 | L2 | L | 10uH | HMT500_260313A:L_SXN_SMNR4020
1 | L3 | L | 22uH | HMT500_260313A:L_SXN_SMNR4020
1 | R1 | R | 4.7R 1W 5% | Resistor_SMD:R_2512_6332Metric
1 | R2 | R | 1M HV | Resistor_SMD:R_1206_3216Metric
1 | R3 | R | 845k 1% | Resistor_SMD:R_0603_1608Metric
1 | R4 | R | 97.6k 1% | Resistor_SMD:R_0603_1608Metric
1 | R5 | R | 35.7k 1% | Resistor_SMD:R_0603_1608Metric
1 | R6 | R | 82k 1% | Resistor_SMD:R_0603_1608Metric
1 | R8 | R | 118k 1% | Resistor_SMD:R_0402_1005Metric
2 | R9 R52 | R | 22.1k 1% | Resistor_SMD:R_0402_1005Metric
4 | R10 R11 R33 R60 | R | 10k | Resistor_SMD:R_0402_1005Metric
4 | R12 R13 R31 R41 | R | 100k | Resistor_SMD:R_0402_1005Metric
1 | R14 | R | 100k 1% | Resistor_SMD:R_0402_1005Metric
1 | R15 | R | 10k 1% | Resistor_SMD:R_0402_1005Metric
3 | R17 R18 R20 | R | 1k | Resistor_SMD:R_0402_1005Metric
1 | R19 | R | 4.02k 0.1% 25ppm | Resistor_SMD:R_0603_1608Metric
2 | R30 R40 | R | 10R pulse | Resistor_SMD:R_2512_6332Metric
2 | R32 R42 | R | 15k 0.1% 25ppm | Resistor_SMD:R_0603_1608Metric
2 | R34 R44 | R | 10R | Resistor_SMD:R_0402_1005Metric
1 | R51 | R | 422k 1% | Resistor_SMD:R_0402_1005Metric
1 | U1 | TPS2660 | TPS26600PWPR | Package_SO:HTSSOP-16-1EP_4.4x5mm_P0.65mm_EP3.4x5mm_Mask2.46x2.31mm_ThermalVias
2 | U2 U15 | LMR51606 | LMR51606YFDBVR | Package_TO_SOT_SMD:SOT-23-6
1 | U3 | TPS7A2033 | TPS7A2033PDBVR | Package_TO_SOT_SMD:SOT-23-5
1 | U4 | STM32G0B1CxTx | STM32G0B1CCT6 | Package_QFP:LQFP-48_7x7mm_P0.5mm
1 | U5 | PCAP04 | PCAP04-AQFM-24 | Package_DFN_QFN:QFN-24-1EP_4x4mm_P0.5mm_EP2.6x2.6mm
1 | U6 | ADS1220 | ADS1220IPWR | Package_SO:TSSOP-16_4.4x5mm_P0.65mm
2 | U7 U8 | DAC8760 | DAC8760IPWP | Package_SO:HTSSOP-24-1EP_4.4x7.8mm_P0.65mm_EP3.2x5mm
2 | U9 U10 | TPS26611 | TPS26611DDFR | Package_TO_SOT_SMD:SOT-23-8
1 | U11 | THVD2450 | THVD2410DGKR | Package_SO:VSSOP-8_3.0x3.0mm_P0.65mm
2 | U12 U13 | OPA197 | OPA197IDBVR | Package_TO_SOT_SMD:SOT-23-5
1 | U14 | 74LVC2G32 | SN74LVC2G32DCUR | Package_SO:VSSOP-8_2.3x2mm_P0.5mm

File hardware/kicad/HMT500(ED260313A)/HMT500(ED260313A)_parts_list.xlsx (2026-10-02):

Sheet: 요약
HMT500(ED260313A) 전자부 부품리스트 — 요약
회로도 v0.3 (KiCad) 기준 · 1대분 · 단가는 1k 추정 (파란 글씨 = 입력값)
환율 (원/USD) | 1400 | 가정 — bom-cost.md 와 동일
분류 | 품목 수 | 금액 하한 (USD) | 금액 상한 (USD) | 금액 하한 (원) | 금액 상한 (원)
수동
보호
전원
측정
출력
커넥터
생산
MCU
통신
기판
센서
하네스
조립
합계
읽는 법
· 부품리스트 시트의 참조번호·수량·값·풋프린트는 KiCad 회로도에서 자동 생성 (make_parts_list.py).
· 상태: 확정 = 회로도·품번 확정 / 제안 = 동등품 대체 가능 / 확인 필요 = 데이터시트·견적 확인 후 확정 / TBD = 미정.
· 제외: 기구 부품(바디·하우징·캡·엔드캡·홀더·O링·나사), 피드스루(HMT500-P-201)는 기구 부품표에 있음.
· 핀 번호 확인 대상 IC: 없음 — 전 IC 제조사 데이터시트로 핀 대조 완료 (회로도 v0.8, STM32는 KiCad 공식 심볼). TPS2660 RTN은 GND와 분리 (R22 삭제).

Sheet: 부품리스트
No | 분류 | 참조번호 | 수량/대 | 값 | 풋프린트 | 제조사 | 품번 | 설명 | 단가 하한 (USD) | 단가 상한 (USD) | 금액 하한 (USD) | 금액 상한 (USD) | 상태 | LCSC | JLC 구분
1 | 수동 | C1 | 1 | 100n 100V | C_0805_2012Metric | Samsung | CL21B104KCFNNNE | MLCC 100 nF 100 V X7R 0805 | $0.020 | $0.050 |  |  | 제안 | C28233 | Basic
2 | 수동 | C2 | 1 | 2.2u 100V | C_1210_3225Metric | Murata | GRM32ER72A225KA35L | MLCC 2.2 uF 100 V X7R 1210 | $0.150 | $0.350 |  |  | 제안 | C86054 | Extended
3 | 보호 | C3 | 1 | 4.7n 2kV | C_1812_4532Metric | YAGEO | CC1812KKX7RDBB472 | MLCC 4.7 nF 2 kV X7R 1812 (GND–외함. LCSC에 Y2 1812 없음 — DC 기기라 Y2 불필요) | $0.100 | $0.200 |  |  | LCSC | C309511 | Extended
4 | 수동 | C4 | 1 | 22n | C_0402_1005Metric | Samsung | CL05B223KO5NNNC | MLCC 22 nF 16 V X7R 0402 (eFuse dV/dt, RTN 기준 저전압) [LCSC: 2026-10-03 LCSC 품번 대조: C1532는 FH 제품이므로 정정; JLC 등급/재고 확인 필요] | $0.002 | $0.005 |  |  | LCSC | C318579 | 확인 필요
5 | 수동 | C5 C64 C65 | 3 | 10u 50V | C_1206_3216Metric | Samsung | CL31B106KBHNNNE | MLCC 10 uF 50 V X7R 1206 (벅 입력 C5, VAO 출력 C64·C65) | $0.100 | $0.250 |  |  | LCSC | C89632 | Extended
6 | 전원 | C6 | 1 | 22u 25V | C_1210_3225Metric | Murata | GRM32ER71E226ME15L | MLCC 22 uF 25 V X7R 1210 (벅 출력 2개, LMR36006 X7R 요구. LCSC에 1206 X7R 없음 → 1210) | $0.150 | $0.400 |  |  | LCSC | C424136 | Extended
7 | 수동 | C8 C14 C15 C20 C21 C23 C28 C29 C30 C36 C40 C44 C50 C54 C60 C63 | 16 | 100n | C_0402_1005Metric | Samsung | CL05B104KO5NNNC | MLCC 100 nF 16 V X7R 0402 (3.3·5 V 디커플링 — 결정 #35 0402로 자리 확보) | $0.002 | $0.005 |  |  | LCSC | C1525 | Basic
8 | 수동 | C12 C26 | 2 | 1u | C_0402_1005Metric | Murata | GRM155Z71A105KE01D | MLCC 1 uF 10 V X7R 0402 (5 V 이하 넷: 벅 VCC, LDO 입·출력. LCSC 표기 X7R — 데이터시트 확인) [LCSC: X7R 1 µF 0402 16 V는 LCSC에서 못 찾음 → 10 V (5 V 이하 넷)] | $0.006 | $0.020 |  |  | LCSC | C528974 | Extended
9 | 수동 | C13 C25 | 2 | 10u | C_1206_3216Metric | Murata | GRM31CR71E106KA12L | MLCC 10 uF 25 V X7R 1206 (v0.9: 0805 X5R → 1206 X7R, DC 바이어스 여유) | $0.050 | $0.120 |  |  | 제안 | C77093 | Extended
10 | 전원 | C16 | 1 | 220n 100V | C_0805_2012Metric | Samsung | CL21B224KCFSFNE | MLCC 220 nF 100 V X7R 0805 (LMR36006 VIN–PGND 핀마다. LCSC에 0603 없음 → 0805) | $0.020 | $0.060 |  |  | LCSC | C307542 | Extended
11 | 수동 | C18 | 1 | 4.7u | C_0805_2012Metric | Murata | GRM21BR71E475KA73L | MLCC 4.7 uF 25 V X7R 0805 (품번 확인 필요) | $0.030 | $0.080 |  |  | 확인 필요 | C162427 | Extended
12 | 측정 | C22 | 1 | 330p C0G 2% | C_0603_1608Metric | Vishay | VJ0603A331GXACW1BC | MLCC 330 pF 50 V C0G ±2% 0603 (결정 #34, PCAP04 기준 C) [LCSC: ±2 % (LCSC에 ±1 % 없음) — 기준 C 절대값은 교정으로 제거, C0G라 온도 안정] | $0.010 | $0.040 |  |  | 제안 | C3898227 | Extended
13 | 측정 | C24 | 1 | 22u 10V | C_1206_3216Metric | Murata | GRM31CR71A226KE15L | MLCC 22 uF 10 V X7R 1206 (PCAP04 VDD33 ≥ 10 µF 실효, 품번 확인 필요) | $0.080 | $0.200 |  |  | 확인 필요 | C91604 | Extended
14 | 측정 | C27 | 1 | 10n C0G | C_0603_1608Metric | Murata | GRM1885C1H103JA01D | MLCC 10 nF 50 V C0G 0603 (ADS1220 차동 필터) | $0.010 | $0.030 |  |  | 제안 | C85973 | Extended
15 | 보호 | C41 C51 | 2 | 1n 100V | C_0603_1608Metric | Samsung | CL10B102KC8NNNC | MLCC 1 nF 100 V X7R 0603 | $0.004 | $0.010 |  |  | 제안 | C153291 | Extended
16 | 수동 | C42 C45 C52 C55 | 4 | 100n 50V | C_0805_2012Metric | YAGEO | CC0805KRX7R9BB104 | MLCC 100 nF 50 V X7R 0805 | $0.010 | $0.030 |  |  | 제안 | C49678 | Basic
17 | 출력 | C46 C56 C62 | 3 | 100n/50V | C_0603_1608Metric | YAGEO | CC0603KRX7R9BB104 | MLCC 100 nF 50 V X7R 0603 (VS_CLAMP 약 24 V) | $0.004 | $0.010 |  |  | LCSC | C14663 | Basic
18 | 출력 | C47 C57 | 2 | 4.7n | C_0402_1005Metric | Samsung | CL05B472KB5NNNC | MLCC 4.7 nF 50 V X7R 0402 (DAC VOUT–CMP 보상) | $0.002 | $0.005 |  |  | LCSC | C84705 | Extended
19 | 출력 | C48 C58 | 2 | 100p C0G | C_0402_1005Metric | Samsung | CL05C101JB5NNNC | MLCC 100 pF 50 V C0G 0402 (DAC CMP–GND) | $0.002 | $0.005 |  |  | LCSC | C26409 | Extended
20 | 출력 | C61 | 1 | 2.2u 50V | C_0805_2012Metric | YAGEO | CC0805KKX7R9BB225 | MLCC 2.2 uF 50 V X7R ±10% 0805, 최대 높이 1.45 mm (VAO 벅 입력) [LCSC: 결정 #53: 2.2 µF 50 V X7R ±10% 0805; 최대 높이 1.45 mm; DC 바이어스 실효 용량 확인 필요] | $0.020 | $0.150 |  |  | LCSC | C125847 | Extended
21 | 보호 | D1 | 1 | SMDJ36CA | D_SMC | Littelfuse | 5.0SMDJ36CA | TVS 5000 W 36 V 양방향 SMC (입력 1단. LCSC — 같은 36 V·SMC, 3 kW → 5 kW) | $0.300 | $0.700 |  |  | LCSC | C141713 | Extended
22 | 보호 | D2 D60 D61 | 3 | TVS3301DRBR | Texas_DRB0008A_PadFloat | TI | TVS3301DRBR | 평탄 클램프 TVS 33 V 양방향, 40 V @ 27 A, SON-8 3×3 (아날로그 출력, TPS2661 데이터시트 권장) [LCSC: D2/D60/D61 3개 유지; 재고 확인 필요] | $0.350 | $0.600 |  |  | 제안 | C2864392 | Extended
23 | 보호 | D3 | 1 | PMEG10010ELR | D_SOD-123F | Nexperia | PMEG10010ELR-QX | 쇼트키 100 V 1 A 저누설 SOD-123W (SOD-123F 풋프린트) — eFuse 앞 직렬, 음(−) 서지·역극성 차단 (외부 검수 H01) | $0.050 | $0.120 |  |  | LCSC | C5361358 | Extended
24 | 보호 | D30 D40 | 2 | TVS1401DRBR | Texas_DRB0008A_PadFloat | TI | TVS1401DRBR | 평탄 클램프 TVS 14 V 양방향, 최대 23.55 V @ 30 A/125 C, SON-8 3×3 (AO 전용, 지속 ±28/30 V 오결선 보장 제외) [LCSC: D30/D40; LCSC 품번 확인, JLC 등급/재고 확인 필요] | $0.350 | $0.600 |  |  | 제안 | C1849891
25 | 출력 | D41 D51 | 2 | BAS70-04 | SOT-23 | Nexperia | BAS70-04,215 | 쇼트키 2개 직렬 70 V SOT-23 — DAC 출력 클램프 (1 A, 2 K, 3 공통) | $0.020 | $0.050 |  |  | LCSC | C389351 | Extended
26 | 수동 | FB1 | 1 | 600R@100MHz | L_0603_1608Metric | Murata | BLM18KG601SN1D | 페라이트 비드 600 Ω@100 MHz 0603 [LCSC: Basic 비드 C1002는 200 mA라 쓰지 않음] | $0.010 | $0.030 |  |  | 제안 | C85833 | Extended
27 | 보호 | GDT1 | 1 | 2035-25-SM | GDT_Bourns_2035-xx-SM | Bourns | 2035-25-SM-RPLF | 2전극 SMD GDT 250 V, Ø5 × 4.4 mm (회로 GND–외함. LCSC — 230 V형은 LCSC에 없음) | $0.400 | $1.000 |  |  | LCSC | C3660127 | Extended
28 | 커넥터 | J1 | 1 | SM08B-GHS-TB | JST_GH_SM08B-GHS-TB_1x08-1MP_P1.25mm_Horizontal | JST | SM08B-GHS-TB(LF)(SN) | GH 1.25 mm 8핀 헤더, 옆 삽입(직각) SMD (M12 하네스 W-2, 정격 −25~+85 °C) | $0.350 | $0.800 |  |  | 제안 | C265111 | Extended
29 | 생산 | J2 | 1 | TC2030-IDC-NL | Tag-Connect_TC2030-IDC-NL_2x03_P1.27mm_Vertical | Tag-Connect | (PCB 패드만) | SWD 기록용 패드 — 부품 실장 없음 | $0.000 | $0.000 |  |  | 확정
30 | 커넥터 | J3 | 1 | SM04B-SRSS-TB | JST_SH_SM04B-SRSS-TB_1x04-1MP_P1.00mm_Horizontal | JST | SM04B-SRSS-TB(LF)(SN) | SH 1.0 mm 4핀 헤더, 옆 삽입(직각) SMD (센서 하네스 W-1, 정격 −25~+85 °C) | $0.300 | $0.600 |  |  | 제안 | C160404 | Extended
31 | 커넥터 | J5 | 1 | CHASSIS wire | SolderWire_Chassis_D0.6mm | - | PCB 납땜 구멍 (부품 없음) | 샤시 선 AWG 28 PTFE 약 25 mm + M2 링 단자 → 홀더 축 나사. 선·단자는 기구 부품표(JLCMC) | $0.000 | $0.000 |  |  | 확정
32 | 보호 | L1 | 1 | CMC 1mH 0.8A | L_CommonMode_Wuerth_WE-SL2 | Bourns | SRF0905-102Y | 공통모드 초크 2 × 1 mH, 0.8 A, 0.31 Ω, 9.2 × 6 × 5.3 mm (LCSC, Würth 744222 동등). WE-SL2 랜드 일치: 패드 2×1.2, 중심 ±3.75/±1.27 mm; SRF0905 원문 권선 1–4/2–3 대조 완료 [LCSC: SRF0905 권장 랜드와 WE-SL2 패드 치수·핀 배정 대조 완료 (2026-10-01); 주문 시 재고 확인] | $0.500 | $1.200 |  |  | 확인 필요 | C2651138 | Extended
33 | 전원 | L2 | 1 | 10uH | L_SXN_SMNR4020 | SXN | SMNR4020-10UH | 파워 인덕터 10 µH ±20 %, 원문 정격 DC 1.60 A, DCR 0.165 Ω ±30 %, 4 × 4 × 2.2 mm max (전용 랜드; 포화 기준 확인 필요) — 5 V 벅 (부하 약 60 mA) [LCSC: SXN 원문 F=.95/G=2.1/H=3.3 mm 전용 랜드 반영; Isat 정의 확인 필요] | $0.050 | $0.120 |  |  | 확인 필요 | C135263 | Extended
34 | 출력 | L3 | 1 | 22uH | L_SXN_SMNR4020 | SXN | SMNR4020-22UH | 파워 인덕터 22 µH ±20 %, 원문 정격 DC 1.05 A, DCR 0.350 Ω ±30 %, 4 × 4 × 2.2 mm max (전용 랜드; 포화 기준 확인 필요) — VAO 벅 [LCSC: SXN 원문 F=.95/G=2.1/H=3.3 mm 전용 랜드 반영; Isat 정의 확인 필요] | $0.050 | $0.150 |  |  | 확인 필요 | C135264 | Extended
35 | 보호 | R1 | 1 | 4.7R 1W 5% | R_2512_6332Metric | YAGEO | RC2512JK-074R7L | YAGEO RC 2512 4.7 Ω 5% 1 W (일반형; 단시간 과부하 원문 확인, 실제 서지 T1 확인 필요) [LCSC: 결정 #57: 일반형 5%; 서지 시험 필요] | $0.050 | $0.150 |  |  | LCSC | C878295 | Extended
36 | 보호 | R2 | 1 | 1M HV | R_1206_3216Metric | ROHM | KTR18EZPF1004 | 서지용 칩 저항 1 MΩ 1% 1206, 최고 사용 전압 500 V (GDT 방전 전 임펄스. LCSC — 1 kV 1206은 LCSC에 없음) [LCSC: 500 V (1 kV 1206은 LCSC에 없음)] | $0.020 | $0.060 |  |  | LCSC | C253347 | Extended
37 | 전원 | R3 | 1 | 845k 1% | R_0603_1608Metric | YAGEO | RC0603FR-07845KL | 저항 845 kΩ 1% 0603 (UVLO) | $0.002 | $0.005 |  |  | 제안 | C246013 | Extended
38 | 전원 | R4 | 1 | 97.6k 1% | R_0603_1608Metric | YAGEO | RT0603BRD0797K6L | 저항 97.6 kΩ 0.1% 25ppm 0603 (UVLO/OVP) [LCSC: 0.1 % 25 ppm (1 %형 LCSC에 없음, 더 좋음)] | $0.002 | $0.005 |  |  | 제안 | C861608 | Extended
39 | 전원 | R5 | 1 | 35.7k 1% | R_0603_1608Metric | UNI-ROYAL | 0603WAF3572T5E | 저항 35.7 kΩ 1% 0603 (OVP 32.61 V, 복귀 30.14 V — v0.11) | $0.002 | $0.005 |  |  | 제안 | C23027 | Extended
40 | 전원 | R6 | 1 | 82k 1% | R_0603_1608Metric | UNI-ROYAL | 0603WAF8202T5E | 저항 82 kΩ 1% 0603 (TPS2660 전류제한 명목 146 mA = 12/R) | $0.002 | $0.005 |  |  | 제안 | C23254 | Extended
41 | 전원 | R8 | 1 | 118k 1% | R_0402_1005Metric | YAGEO | AC0402FR-07118KL | 저항 118 kΩ 1% 0402 (5 V 벅 FB 상단) | $0.001 | $0.003 |  |  | LCSC | C144804 | Extended
42 | 출력 | R9 R52 | 2 | 22.1k 1% | R_0402_1005Metric | UNI-ROYAL | 0402WGF2212TCE | 저항 22.1 kΩ 1% 0402 (VAO 분압 하단) [LCSC: 2026-10-03 LCSC/JLC 품번·22.1 kΩ ±1%·0402 대조] | $0.001 | $0.003 |  |  | 확인 필요 | C43473 | Extended
43 | 수동 | R10 R11 R33 R60 | 4 | 10k | R_0402_1005Metric | UNI-ROYAL | 0402WGF1002TCE | 저항 10 kΩ 1% 0402 (50 V) | $0.001 | $0.003 |  |  | LCSC | C25744 | Basic
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

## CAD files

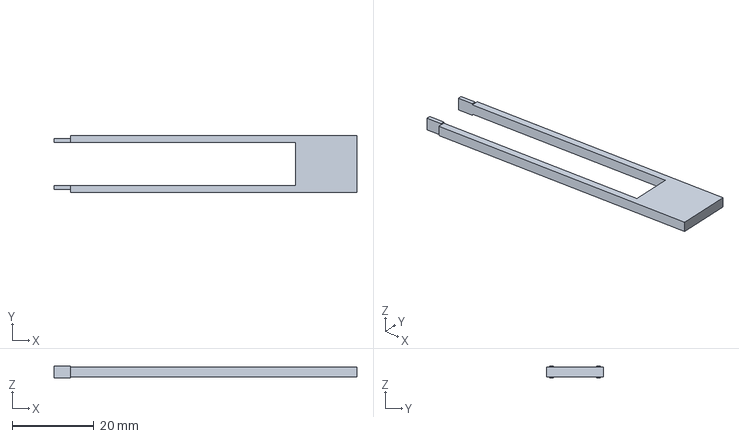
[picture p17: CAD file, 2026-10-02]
manufacturing/jlc/jlc3d/HMT500-T-001_W-2_plug_push_bar_assembly_tool.step
74.0 x 14.0 x 3.00 mm

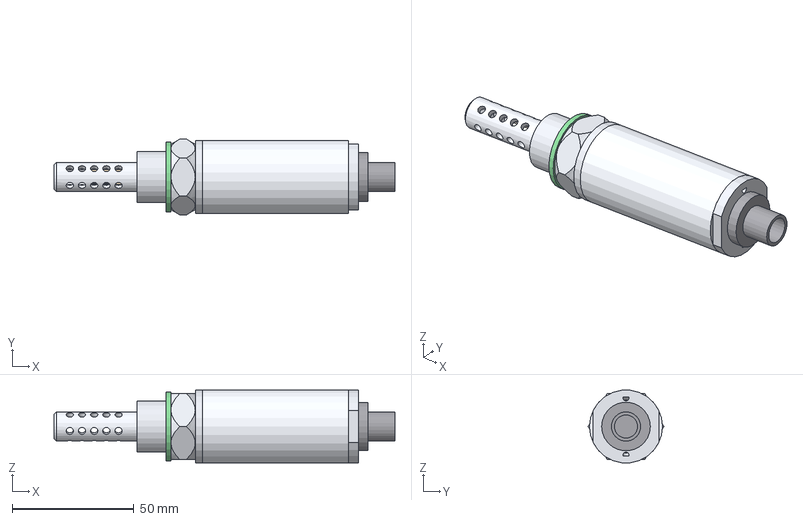
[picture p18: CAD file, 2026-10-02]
hardware/mech/out/HMT500_assembly.step
140.0 x 31.2 x 29.8 mm
M-101_body
M-102_cap
M-103_housing
M-104_endcap
P-209_epoxy
P-209_potting
P-202_sensor_probe
P-202_elements
HTX99R-SC_connector
P-208_conn_oring
P-203_seal
P-205_orings
E-301_pcb
E-301_parts
W-1_harness
W-1_plug
W-2_harness
W-2_plug
M-105_holder
M-106_ring
W-3_chassis_wire
P-204_connector

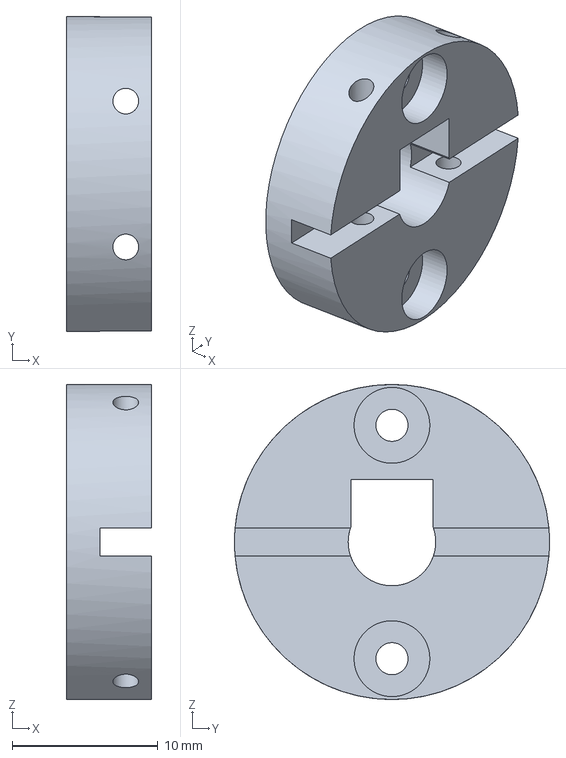
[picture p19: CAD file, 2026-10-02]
hardware/mech/out/HMT500-M-105_holder.step
5.80 x 21.6 x 21.6 mm

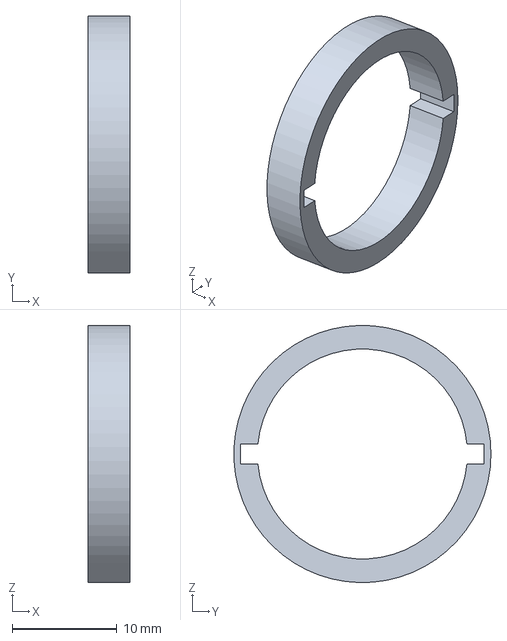
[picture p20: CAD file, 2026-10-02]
manufacturing/jlc/jlc3d/HMT500-M-106_Support_ring.step
4.00 x 24.5 x 24.5 mm

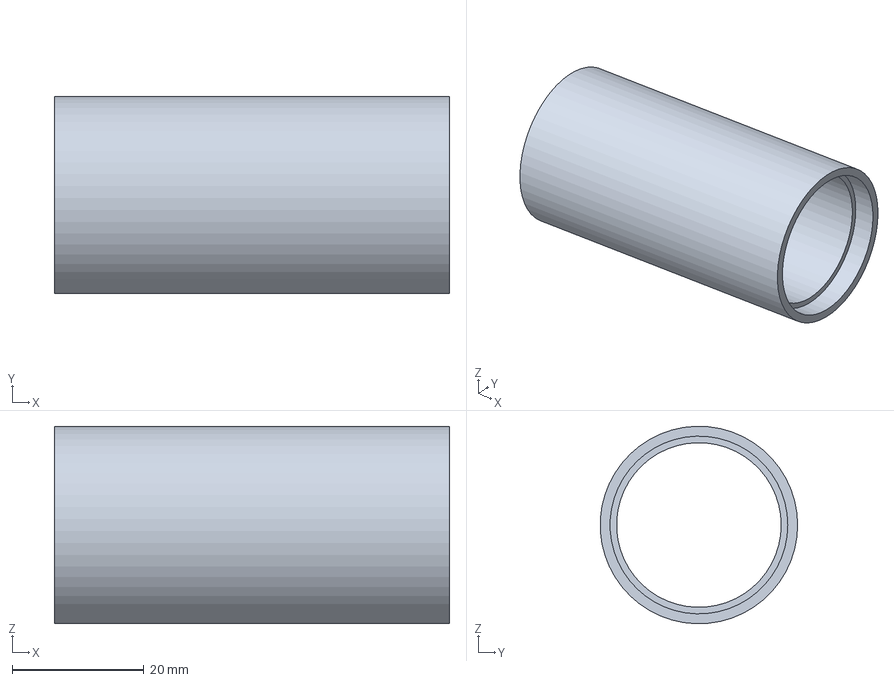
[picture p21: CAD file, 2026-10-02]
manufacturing/jlc/jlccnc/HMT500-M-103_housing_SUS304.step
60.0 x 30.0 x 30.0 mm

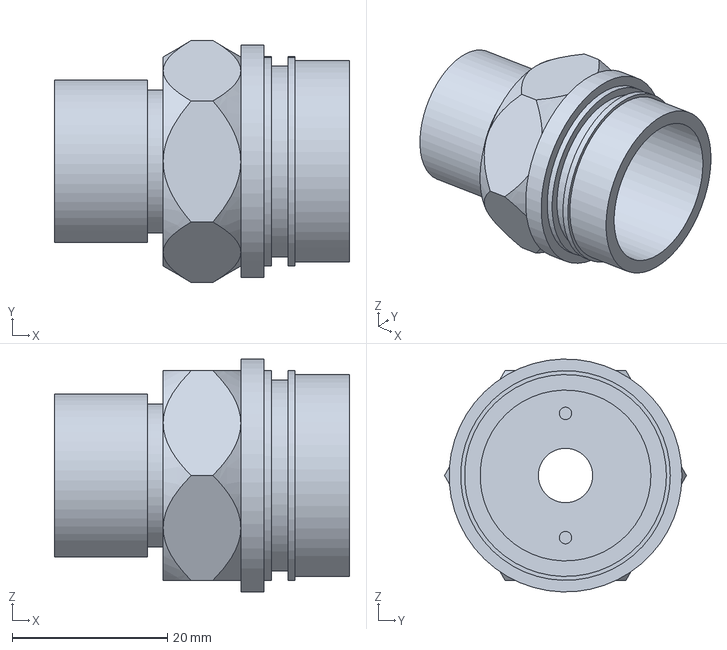
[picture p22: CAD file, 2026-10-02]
hardware/mech/out/HMT500-M-101_body.step
38.0 x 31.2 x 30.0 mm

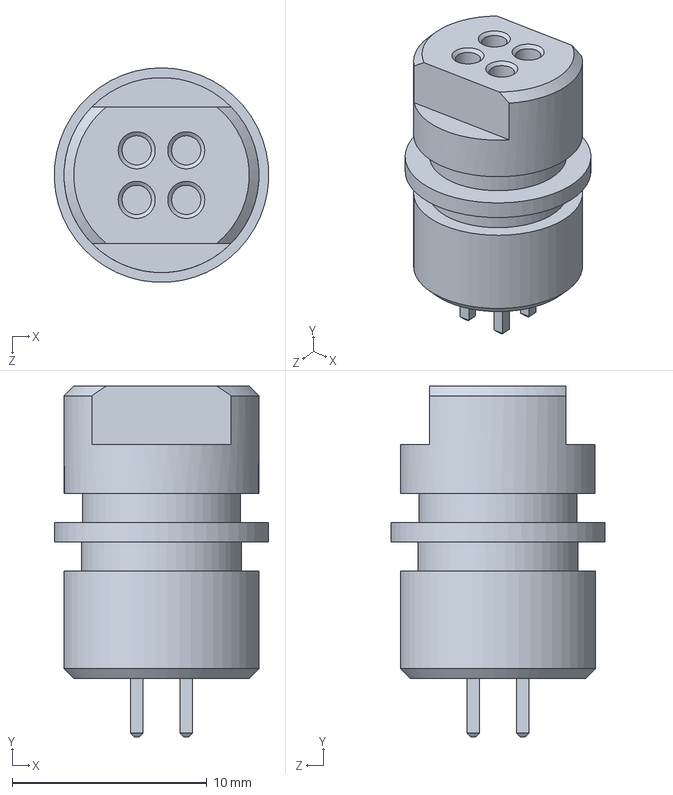
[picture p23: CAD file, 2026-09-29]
hardware/mech/ref/HTX99R_Sensor_Probe_Sensor_Connector.STEP
11.0 x 18.0 x 11.0 mm

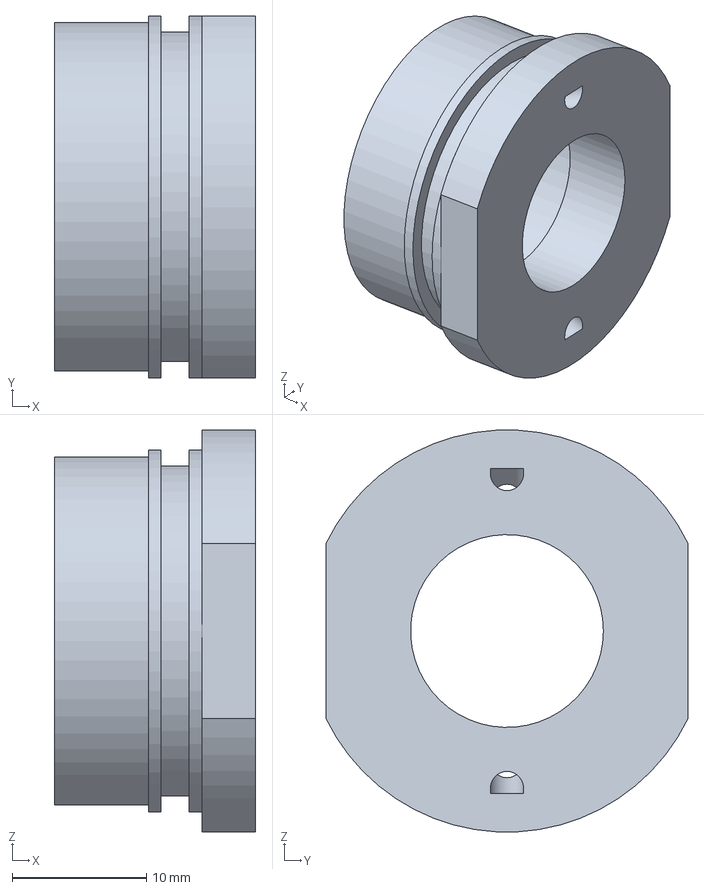
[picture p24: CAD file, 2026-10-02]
manufacturing/jlc/jlccnc/HMT500-M-104_endcap_SUS304.step
15.0 x 27.0 x 30.0 mm

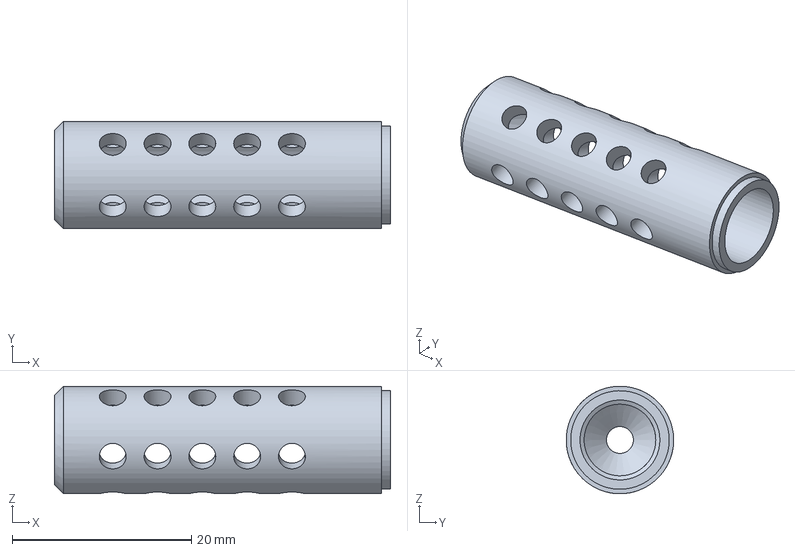
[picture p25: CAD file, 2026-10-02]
manufacturing/jlc/jlccnc/HMT500-M-102_cap_SUS304.step
37.5 x 12.0 x 12.0 mm

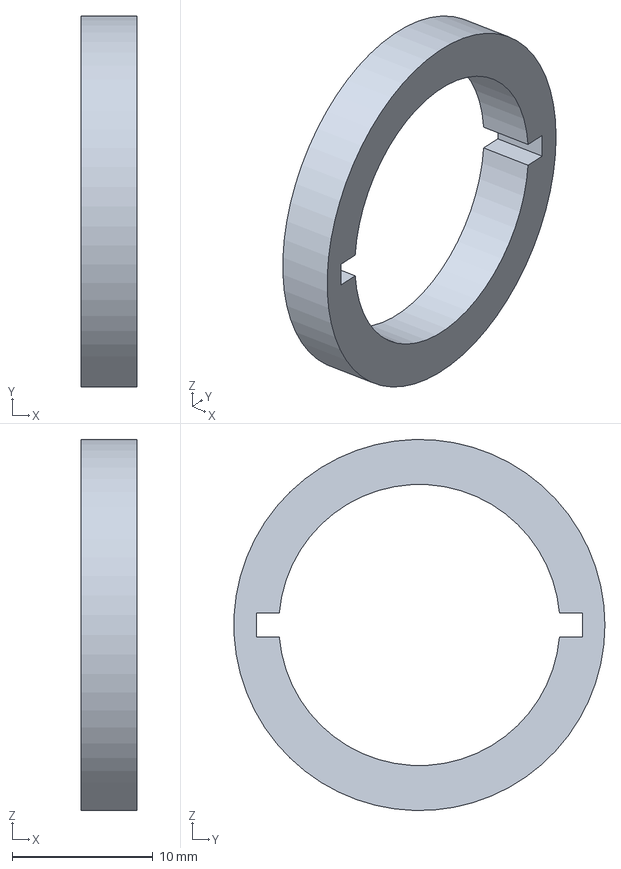
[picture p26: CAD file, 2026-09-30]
manufacturing/jlc/jlccnc/HMT500-M-106_ring_PEEK.step
4.00 x 26.4 x 26.4 mm

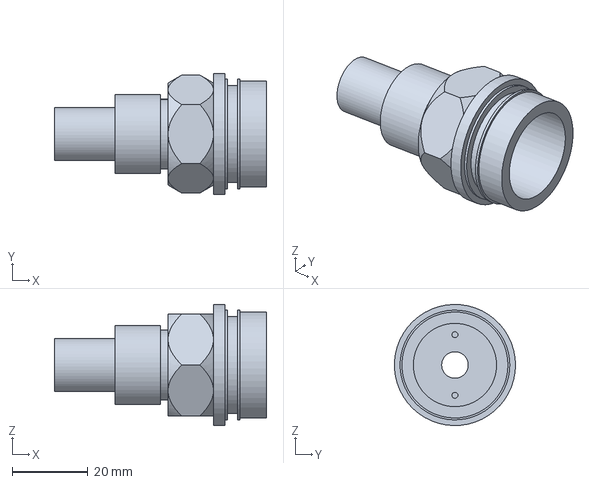
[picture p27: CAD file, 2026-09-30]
manufacturing/jlc/jlccnc/HMT500-M-101_body_SUS316L.step
56.0 x 32.0 x 32.0 mm

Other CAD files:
hardware/mech/ref/SUS_PROBE_Oil_Filter_20200608.dwg
manufacturing/jlc/jlc3d/HMT500-M-105_PCB_holder.step
hardware/mech/out/HMT500-M-103_housing.step
hardware/mech/out/HMT500-T-001_push_tool.step
manufacturing/jlc/jlccnc/HMT500-M-101_body_SUS304.step
hardware/mech/out/HMT500-M-106_ring.step
hardware/mech/out/HMT500-M-104_endcap.step
hardware/mech/out/HMT500-M-102_cap.step
manufacturing/jlc/jlc3d/HMT500-M-105_PCB_holder.stl
manufacturing/jlc/jlc3d/HMT500-M-106_Support_ring.stl
manufacturing/jlc/jlc3d/HMT500-T-001_W-2_plug_push_bar_assembly_tool.stl
manufacturing/jlc/jlccnc/HMT500-M-103_housing_SUS316L.step
manufacturing/jlc/jlccnc/HMT500-M-104_endcap_SUS316L.step
manufacturing/jlc/jlccnc/HMT500-M-105_holder_PEEK.step

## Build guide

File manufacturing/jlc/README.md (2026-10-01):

# HMT500(260313) JLC 주문 패키지

작성 2026-09-30 · 기구 Rev H · 회로·PCB HMT500(260313A)

| 서비스 | 대상 | 폴더 | 상태 |
|---|---|---|---|
| **JLCPCB** (PCB + PCBA) | PCB 1종(4층, 57 × 23)과 양면 부품 조립. 측정·MCU·전원·출력이 모두 한 보드 | `jlcpcb/` | BOM·CPL 준비 완료. LCSC 58/60줄 (LCSC 번호 확인 필요 2줄 — 2.2 µF 50 V 0805, 22.1k 0402, 결정 #39). **배선 전**이라 거버 없음 |
| **JLCCNC** (CNC 가공) | 바디 M-101, 센서 보호캡 M-102(두텍 390000-001100과 같은 형상), 하우징 M-103, 엔드캡 M-104 (SUS316L, 시제품 SUS304); 홀더 M-105, 지지링 M-106 (PEEK) | `jlccnc/` | STEP + 도면 PDF + 주문표 준비 완료 |
| **JLC3D** (3D 프린트) | 조립 공구 T-001 밀대. 선택: 홀더·링 끼움 확인용 시제품 | `jlc3d/` | STL/STEP + 주문표 준비 완료 |
| **JLCMC** (표준 기계 부품) | M2 나사 3종, M3 무두나사, O링 2종, 본디드 씰 | `jlcmc/` | 사양·수량 준비 완료. JLCMC 품번은 검색 후 기입 |
| LCSC (JLC 계열 부품몰) | 하네스 W-1·W-2 JST 하우징·콘택트, PTFE 선, 샤시 선 링 단자 | `lcsc/` | JST 하우징·콘택트 LCSC 번호 기입 완료. PTFE 선·링 단자는 조회 후 기입 |

JLC 계열로 주문하지 않는 것은 다음과 같습니다.
- 두텍 사내품: HTX99R 센서 커넥터, M12 커넥터 P-204, 센서 프로브(MK33 + Pt1000).
- 에폭시(선정 미결), 나사 고정제·실런트.

수량은 시제품 **5세트**로 가정했습니다. 바꾸려면 `make_mech_package.py`의 `SETS` 값을 고칩니다.

## JLCPCB (PCB + 조립)

| 파일 | 내용 |
|---|---|
| `HMT500(260313A)_CPL_JLC.csv` | 부품 위치: Designator, Mid X/Y (mm), Layer, Rotation. KiCad 배치 그대로이고 거버와 같은 좌표계. 82개 |
| `HMT500(260313A)_BOM_JLC.csv` | Comment, Designator, Footprint, LCSC Part #. 50줄 |
| `jlc_parts_map.csv` | 값·풋프린트 → LCSC 번호·JLC 구분(Basic/Extended)·회전 보정. **여기만 채우면** BOM이 다시 생성됨 |

- 생성: `python3 manufacturing/jlc/make_jlcpcb_files.py`
- J2(Tag-Connect 패드)와 J5(샤시 선 구멍)는 부품이 없어서 BOM·CPL에서 뺐습니다.
- 주문 조건: 4층, 1.6 mm, ENIG, 최소 간격·선폭 0.15, 최소 드릴 0.2(TPS2660 방열 비아), **양면 조립**(Standard PCBA).
- 거버는 배선을 마친 뒤 `sh hardware/kicad/export_gerbers.sh`로 뽑습니다(`HMT500(260313A).zip`).
- 회전: JLC 미리보기에서 부품 방향을 확인합니다. 어긋난 패키지는 `jlc_parts_map.csv`의 `rot_offset`에 적습니다.

## JLCCNC (가공품)

`order_jlccnc.csv`에 부품별 재질, 대체 재질, 후처리, 나사, 공차가 있고, 부품마다 STEP과 도면 PDF가 한 쌍입니다. 주문할 때 아래를 **주문 메모에 꼭 적습니다.**

1. **왼나사:** 하우징 뒤 M26×1-LH 암나사, 엔드캡 M26×1-LH 수나사(턴버클). 앞쪽은 오른나사입니다.
2. **가는 나사·관용 나사:** 바디 G1/2-A(ISO 228-1), M26×1, M10×1.0 암나사(나사 길이 5.5), 엔드캡 M16×1.5 암나사. JLCCNC 표준 나사 목록에 없으면 도면 지시로 요청합니다.
3. **O링 자리:** Ø27 f7(바디·엔드캡) / Ø27 H8(하우징 양 끝), 표면 Ra 0.8.
4. **재질:** SUS316L이 없으면 316. 하우징·엔드캡은 304도 가능합니다(오일에 닿지 않음). PEEK가 없으면 시제품만 POM으로 하고, 양산은 PEEK로 합니다.
5. **후처리:** 스테인리스는 부동태화. 하우징 외면 레이저 마킹은 JLCCNC 옵션을 확인하고, 없으면 사내에서 합니다.

## JLC3D (3D 프린트)

- **T-001 밀대:** W-2 플러그를 하우징 안 19.5 mm 깊이의 J1에 밀어 넣는 공구입니다. SLA 레진 또는 MJF PA12로 2개.
- 홀더·링 끼움 확인용(선택): SLA 고정밀 레진. PEEK 가공품을 받기 전에 PCB, 플러그, 창 크기를 확인합니다.

## JLCMC · LCSC

- `jlcmc/order_jlcmc.csv`: 나사 A4-70(ISO 14580), O링 FKM 75, 본디드 씰. 품번 칸은 JLCMC에서 검색해 채웁니다.
- `lcsc/order_lcsc_harness.csv`: JST SH·GH 하우징·콘택트, PTFE 선, M2 링 단자. 하네스는 사내에서 만듭니다(압착 공구: JST 정품 또는 동등품).

## 부품 번호(LCSC) 매핑 — 결정 #34 (2026-09-30)

LCSC 품번은 `hardware/kicad/make_parts_list.py`의 `LCSC` 표가 기준입니다(웹 검색 결과의 LCSC 주소·제목으로 대조). 부품리스트 xlsx/csv의 "LCSC"·"JLC 구분" 열과 이 폴더 BOM에 같이 들어갑니다. 62줄 중 54줄에 LCSC 번호가 있습니다 (결정 #37 반영). 2.2 µF 50 V 0805, 422k/22.1k 0402는 JLC 화면에서 같은 값 선택.

- **글로벌 소싱 5줄 (LCSC 번호 빈칸):** U4 STM32G0B1CCT3 (125 °C 등급 — LCSC엔 85 °C CCT6뿐), U2 LMR36006BRNXR, R19 PLTT0603Z4021 (0.02 %·5 ppm), R1·R30·R40 Vishay CRCW-HP 펄스 내성형. JLC 부품 매칭 화면에서 Global Sourcing으로 같은 품번을 고르거나 사급합니다.
- **LCSC에 맞춰 바꾼 풋프린트:** C6·C10 22 µF 25 V 1206 → 1210, C16·C17 220 nF 100 V 0603 → 0805, R1 MELF → 2512, L2 XAL4030 → XAL4040 (높이 4.0). C3는 Y2 1812 대신 2 kV X7R 1812 (DC 기기라 Y2 불필요).
- **주문 전 확인:** L1 Bourns SRF0905-102Y는 WE-SL2 풋프린트를 그대로 씀 — 랜드·권선 핀 배정을 Bourns 데이터시트로 대조 (이 작업 환경에서 bourns.com 접속 불가). TVS3301(약 88개)·SRF0905(약 810개) 재고가 적음. Basic 여부와 재고는 JLC 화면이 최종.

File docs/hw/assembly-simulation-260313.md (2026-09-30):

# HMT500(260313) 조립 시뮬레이션 — 결과와 개선 제안

작성 2026-09-30 · 기준: 기구 Rev F (`hardware/mech/hmt500_params.py`) + PCB 배치 rev 2 (`placement.json`)
실행: `python hardware/mech/assembly_sim.py` → `hardware/mech/out/assembly_sim/` (report.json, 그림 3장)

**상태: 개선안 A–F 전부 반영 (2026-09-30, 결정 #27) → 재시뮬레이션 23항목 NG 0.** 아래 1차 결과는 기록용.

## 방법

조립도 주기 5의 순서를 한 단계씩 실제 형상으로 따라갔다. 기구는 CAD 형상 그대로, PCB 부품은 실제 배치의 외형 × 높이를 썼다. 나사산은 골지름 원통, 플러그와 공구는 외형 상자·원통으로 단순화했다.
움직이는 부품과 공구(플러그, 지지링, 하우징, 엔드캡, 드라이버, 핀셋)를 경로를 따라 여러 위치에 놓고, 정지 부품과의 겹침 부피와 최소 거리를 계산했다.

가정 치수(데이터시트 확인 전): JST SH 플러그 5.0 × 2.8 × 4.25, GH 플러그 11.8 × 3.5 × 4, M2 드라이버 날 Ø3.

## 1차 결과 (개선 전) — 25항목: NG 6, 주의 3

| # | 단계 | 결과 | 내용 |
|---|---|---|---|
| ① | PCB 가로 나사 M2 (x 16.25, z 방향) | **NG** | 홀더가 바디 안에 있으면 드라이버가 카운터보어 벽(z 9.8)에 막힌다. 나사가 입구(x 26)에서 9.75 mm 안쪽이라 수직 공구가 들어갈 수 없다 |
| ② | 대안: 홀더+PCB를 먼저 조립 | **NG** | PCB가 Ø6 구멍 가운데를 가로막아, 구멍 위 높이가 0.9 mm밖에 안 된다(플러그 2.8). 결국 **현재 순서로는 조립할 수 없다** (①과 ②가 서로 막음) |
| ③ | 턴버클 끝 | **NG** | 엔드캡 앞면(x 64, r 11–14)이 PCB 폭 23 구간 끝(x 64)과 **틈 0**. 공차에 따라 엔드캡이 PCB를 앞으로 민다 |
| ④ | 지지링 끼움 | 주의 | 링(안지름 Ø20)이 x 71 → 59로 지나가므로 엔드캡 구역 부품도 Ø20 안에 들어야 한다. 배치 규칙은 Ø22로 검사했다. GDT1은 외형 상자 기준 여유 0.16 mm(실제 원통 기준 약 1 mm) |
| ⑤ | J5 샤시 스프링 접점 | **NG** | 하우징 내면까지 10.8 mm인데 접점 높이는 7.25 mm라 3.6 mm 모자란다. 닿게 만들어도 턴버클 7바퀴 동안 하우징이 접점 위에서 돌면서 14 mm 이동한다 |
| ⑥ | W-2 길이 60 mm | 주의 | 체결 후 필요한 직선 거리는 10.8 mm라 **약 49 mm가 엔드캡 안에서 접힌다** (턴버클로 엔드캡이 14 mm 다가옴) |
| ⑦ | W-1 길이 60 mm | 주의 | 14 mm가 남아 PCB 앞 윗면(x 18–26.5)에 고리로 남는다. 창에 꿰려면 통로 끝에서 24 mm가 필요하므로 길이는 유지 |
| ⑧ | 홀더 Ø6 구멍 (PCB 없이) | 주의 | 플러그 대각선 대비 여유가 반경 0.13 mm로 빡빡함 |

**확인된 정상 항목**
- W-1 플러그가 Ø7 통로를 지나감: 반경 여유 0.63 mm, 어느 각도로 돌아도 통과한다. 커넥터를 체결할 때 플러그가 따라 돌아서 꼬이지 않는다.
- 홀더 축 방향 나사 M2를 뒤에서 조임: PCB를 장착한 상태에서도 드라이버 경로(z ±8)가 부품과 1.45 mm(윗면), 0.70 mm(아랫면 L1) 떨어져 있다.
- W-1 플러그를 J3에 꽂음: 4 mm 밀어 넣는 경로에 간섭이 없다. 핀셋 공간은 7.4 mm.
- 지지링 형상 교차, 하우징 씌움: 부품 최대 반경 12.63 mm, 최소 반경 13.46 mm. 링 바깥지름과 하우징 사이는 반경 0.26 mm.
- W-2 플러그를 하우징 뒤로 넣어 J1에 꽂음: 19.5 mm 깊이이고, 링 안쪽 Ø20을 간섭 없이 지나간다.
- 턴버클 진행 중(엔드캡 14 → 0.5 mm): 간섭이 없다. 체결 후 하우징과 부품 사이는 0.30 mm.

그림: `hardware/mech/out/assembly_sim/assembly_issues.png` (개선 전 ①–⑥), `assembly_fixes.png` (개선 후), `assembled_top.png` / `assembled_bottom.png` (조립 상태 3D 절단, 개선 후).

## 개선 제안 → 전부 반영

| 제안 | 대상 | 내용 | 해결 |
|---|---|---|---|
| **A** | 홀더 M-105 | Ø6 구멍 위에 **창 5.6 × 3.2**(y ±2.8, z 0.85–4.05)을 낸다. 홀더+PCB를 벤치에서 가로 나사로 먼저 조립하고, 플러그를 창으로 꿴 뒤 바디에 넣고 축 나사를 뒤에서 조인다. 창 위 끝(z 4.05)과 축 나사 자리(z 6.0 이상) 사이는 1.95 mm | ①②⑧ |
| **B** | PCB 외곽 | 폭 23 구간을 x 64 → **63.4**에서 끝낸다(엔드캡과의 틈 0.6 mm). C3 등 뒤쪽 배치를 다시 확인 | ③ |
| **C** | 배치 규칙 | 링 뒤(x ≥ 59) 부품 높이 한계를 **Ø20 기준**으로 바꾼다 | ④ |
| **D** | 샤시 접지 | **J5를 없애고** 홀더 축 나사 M2 하나(금속 바디 탭) 머리 밑에 **링 단자 + 짧은 선(약 20 mm)** → PCB 앞쪽 CHASSIS 패드에 연결한다. C3·GDT1·R2를 그 옆(앞쪽)으로 옮긴다. 아랫면 약 70 mm²가 비고 회전 마찰도 없다 | ⑤ |
| **E** | W-2 하네스 | 60 → **40 mm**(꽂을 때 필요한 약 35 mm + 여유). 남는 약 29 mm는 엔드캡 안에서 한 번 접는다. 윗면 x 64.5–71 통로는 "높이 1 mm 이하 허용" 대신 **부품 금지**로 되돌린다(현재 그 자리에 부품 없음) | ⑥ |
| F | 조립 공구 | W-2 플러그용 밀대(끝이 플러그 뒤를 감싸는 막대, 하우징 안 20 mm 도달) | ⑥ |

D를 채택하면 서지 전류가 GND 평면을 따라 앞쪽 접지점까지 흐른다(보드 길이 약 50 mm). 뒤쪽 끝에서 엔드캡에 직접 닿는 스프링 핑거도 검토했지만, 턴버클 때 14 mm를 축 방향으로 끌리고 부품 데이터시트도 확인할 수 없어 추천하지 않는다.

## 개선 후 조립 순서 (A·D·E 반영안)

1. W-1을 HTX99R 뒤 핀에 납땜 → O링 → 플러그를 바디 앞에서 Ø7 통로로 넣어 뒤로 뺀다 → HTX99R를 바디에 체결한다(플러그가 따라 돌아 꼬임 없음).
2. 1차 몰딩: 프로브를 아래로 두고 뒤에서 주입한 뒤 경화한다 → 본디드 씰.
3. **벤치:** PCB를 홀더 홈에 끼우고 가로 나사 M2×12 2개를 조인다. 샤시 선(링 단자)을 PCB에 납땜한다. SWD 기록과 기능 검사를 한다.
4. W-1 플러그를 홀더 창으로 꿰고 홀더+PCB를 카운터보어에 넣는다 → 축 나사 M2×6 2개를 뒤에서 조인다(하나는 링 단자와 함께).
5. W-1 플러그를 J3에 꽂는다(카운터보어 입구에서 핀셋으로). 남는 선은 PCB 앞 윗면에 고리로 둔다.
6. 지지링을 PCB 뒤에서 끼운다.
7. W-2를 M12 핀에 납땜하고 M12를 엔드캡에 체결한다(플러그가 자유로워 꼬임 없음).
8. 하우징을 PCB 위로 씌워 턴버클 시작 위치(7 mm 뒤)에 둔다 → 엔드캡을 옆으로 비켜 들고 밀대로 W-2 플러그를 J1에 꽂는다.
9. 바디(AF27)와 엔드캡(AF28)을 잡고 하우징만 7바퀴 돌린다. 엔드캡이 14 mm 다가오며 W-2가 엔드캡 안에서 접힌다.
10. 2차 몰딩(M12를 위로, M3 구멍으로 진공 주입) → 무두나사로 막는다 → 센서 프로브와 필터를 장착한다.

## 재시뮬레이션 (A–F 반영 후) — 23항목: NG 0, 주의 0

| 단계 | 결과 |
|---|---|
| [벤치] PCB 가로 나사 M2×12 | 홀더가 바디 밖이라 드라이버 막힘 없음 |
| W-1 플러그 → 홀더 창 (PCB 장착 상태) | 최소 거리 0.20 mm (폭 여유 0.30, 높이 여유 0.20) |
| 홀더+PCB → 카운터보어 | 앞쪽 부품 최대 반경 8.60 (L2) < 11 |
| 홀더 축 나사 (뒤에서) | 드라이버와 부품·샤시 선 0.38 mm(위), 0.70 mm(아래) |
| 샤시 선 | 필요 12.5 mm < 25 mm, 부품과 겹침 없음 |
| 지지링 끼움 | 뒤쪽 부품 최대 반경 8.44 (R1) < 10 |
| 하우징 씌움 | 부품 최대 반경 11.19 (U11) < 13.46 |
| 밀대 T-001로 W-2 → J1 | 링·하우징·부품과 겹침 없음 |
| W-2 40 mm | 꽂을 때 필요 34 mm, 체결 후 남는 선 29 mm |
| 턴버클 끝 | 엔드캡–PCB 0.60 mm, 하우징–링 0.30 mm |

배치 변경: J5(납땜 구멍)를 윗면 앞쪽(홀더 위 축 나사 바로 뒤)에 두고 C3·R2를 그 옆으로 옮겼다. GDT1은 앞쪽에 자리가 없어 아랫면 가운데(J5에서 약 25 mm)에 있다. 배선 때 CHASSIS를 넓은 선(내층 권장)으로 잇는다. 아랫면 부품 면적은 821 → 685 mm²로 줄었다.

## Rev H 재시뮬레이션 (2026-09-30)

외형을 EE364와 같게 바꾼 뒤(하우징 Ø30/Ø25, M26×1, 육각 10, 안쪽 x −2) 다시 돌린 결과 **23항목 NG 0**. 달라진 값: 하우징을 씌울 때 가장 좁은 곳은 나사 골 Ø24.92 (부품 최대 반경 11.19, U11 → 여유 1.27), 지지링 Ø24.5는 나사 골을 반경 0.21 여유로 지나감, 턴버클 끝 엔드캡–PCB 0.60 mm (그대로), 하우징–부품 0.25 mm. 이 순서로 조립 시방서 HMT500-A-001을 만들었다 (`hardware/mech/assembly_procedure.py`).

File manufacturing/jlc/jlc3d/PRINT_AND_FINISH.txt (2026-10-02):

Rev J / one prototype set. M-105 and M-106: MJF PA12-HP Nylon, one each. T-001 tool: one.
Printed dimensions are nominal. JLC published as-printed tolerance +/-0.3 mm does NOT meet all drawing fits.
M-105/106: inspect and finish OD and PCB slots to drawing final dimensions before assembly.
M-105: two nominal dia1.6 pilot holes for M2x0.4. Check actual pilot size before tapping; oversized holes require reprint.
No printed thread helix. Do not assume thread strength or fit is validated. Do not overtighten.
Remove loose powder and burrs. If supplier does not offer finishing, receiver must finish and inspect.
Reject/reprint undersize external fits or oversized holes/slots that cannot be corrected. No unconditional drop-in fit claim.
Temperature, creep, epoxy compatibility and finished assembly require prototype tests. HDT is not continuous service temperature.
Source: https://jlc3dp.com/help/article/pa12-hp-nylon

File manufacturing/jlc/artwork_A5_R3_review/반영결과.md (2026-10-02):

# HMT500(ED260313A) A5-R3 — 정식 명칭·전체 로고

## 바뀐 것

사용자가 중간 번호 0313을 확인하여 PCB 정식 명칭을 **HMT500(ED260313A)**로 통일했다. 현재 프로젝트 폴더, `.kicad_pro/.kicad_pcb/.kicad_sch`, 하위 시트, 회로도 표제, PCB 실크와 신규 Gerber/BOM/CPL 파일명을 변경했다. 이전 릴리스는 과거 기록으로 보존하며, 심볼/풋프린트 라이브러리 별칭 `HMT500_260313A`는 기존 연결 호환성을 위해 유지한다.

탑면에 **DOTECH + SENSING & CONTROL 전체 로고**를 원본 비율로 배치했다. 폭 11.5 mm, 높이 3.203 mm. PCB 명칭과 A5-R3 표시는 그 아래에 둔다.

## KiCad에서 편집

- 레퍼런스: 각 부품의 실제 `Reference` 필드이다. KiCad에서 위치·크기·방향·표시 여부를 편집할 수 있다.
- PCB 명칭: 실제 F.SilkS `PCB_TEXT`이다. 이미지나 PDF 덧글이 아니다.
- 로고: 실제 F.SilkS 채움 다각형 21개를 `DOTECH full logo` 그룹으로 묶었다. 그룹으로 이동하거나 그룹 해제 후 개별 도형을 편집할 수 있다. PNG를 기판에 삽입한 것이 아니다.
- 편집용 묶음은 프로젝트와 전용 라이브러리를 함께 포함한다. 압축 해제 후 `HMT500(ED260313A)/HMT500(ED260313A).kicad_pro`를 연다.

## 검사

전체 재생성 및 테스트 33개 통과. 넷리스트 81/81 일치, DRC 오류 0, 미연결 0. 이전 PCB와 배선·비아·패드 형상/넷 및 부품 위치/면/회전은 동일하다. 저장된 보드를 다시 읽어 네이티브 레퍼런스 110개, 전체 로고 그룹 1개/다각형 21개, 정식 명칭 텍스트 1개를 확인했다.

## 남은 위험

실크 레퍼런스 92개 표시, 18개 미표시 상태를 유지한다. 높이 0.6 mm를 적용한 22개는 인쇄성 확인이 필요하다. DRC 경고는 작은 문자 22개와 기존 라이브러리 차이 2개이며 오류가 아니다. 로고 부제의 작은 세부 형상도 제조사 실크 인쇄성 검토 대상이다. 기존 제조 DFM·온도·몰딩·EMC 조건은 유지한다.

미표시: D51, U13, U15, U2, C28, C4, C44, C45, C48, C50, C55, FB1, R14, R19, R31, R51, R52, R9.

이번 변경은 명칭/실크 수정이며 발주 승인이 아니다.

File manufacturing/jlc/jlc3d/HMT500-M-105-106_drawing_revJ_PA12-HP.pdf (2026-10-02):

2×Ø2.2, 간격 10 (홀더 가로 나사 M2)

## HMT500-E-301 PCB 외곽 — 기구 인터페이스 (2.5:1)

6층 FR-4 t1.6, 모서리 R1. 빗금 = 부품·동박 금지 (양면): 홀더 홈 물림, 지지링 홈. 기준 = 앞 끝(피드스루 쪽)

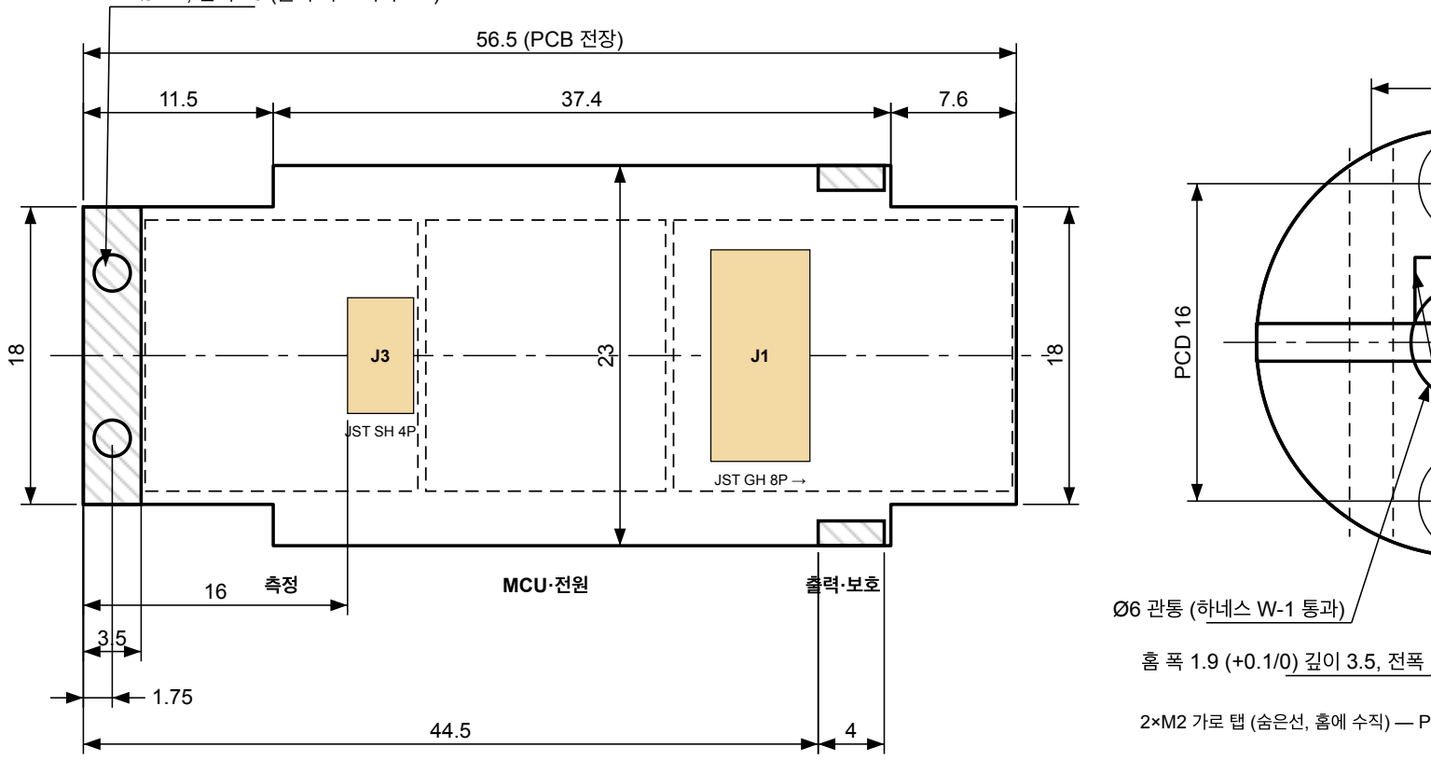
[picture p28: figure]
MCU·전원; JST SH 4P; JST GH 8P →; 56.5 (PCB 전장); Ø6 관통 (하네스 W-1 통과)

구간 (앞 끝 기준) | 폭 | 둘러싼 보어 | 부품 높이 한계 (한 면, 여유 0.5 포함)
0 ~ 11.5 | 18 | Ø22 (바디 카운터보어) | 가장자리 5.0 / 중심 9.7 mm
11.5 ~ 48.9 | 23 | Ø24.92 (하우징) | 가장자리 3.5 / 중심 11.2 mm
48.9 ~ 56.5 | 18 | Ø22 (엔드캡 카운터보어) | 가장자리 5.0 / 중심 9.7 mm

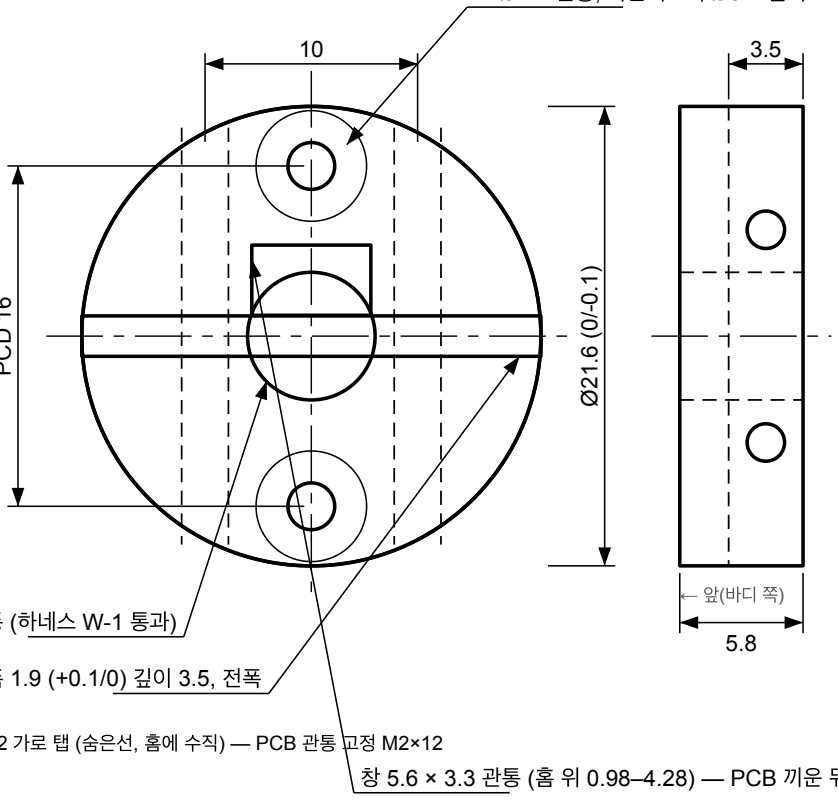
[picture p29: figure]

창 5.6 × 3.3 관통 (홈 위 0.98–4.28) — PCB 끼운 뒤 W-1 플러그 통과

2×Ø2.2 관통, 카운터보어 Ø5.2 깊이 2.2 (M2 → 바디, 위쪽은 링 단자 함께)

2×M2 가로 탭 (숨은선, 홈에 수직) — PCB 관통 고정 M2×12

## HMT500-M-105 PCB 홀더 (3:1)

왼쪽: 뒤(PCB 쪽)에서 본 끝면 / 오른쪽: 측면

## HMT500-M-106 PCB 지지링 (2:1), 두께 4

하우징 안에서 PCB 뒤쪽을 받침. 엔드캡과 연결 안 함 (체결 회전 전달 없음)

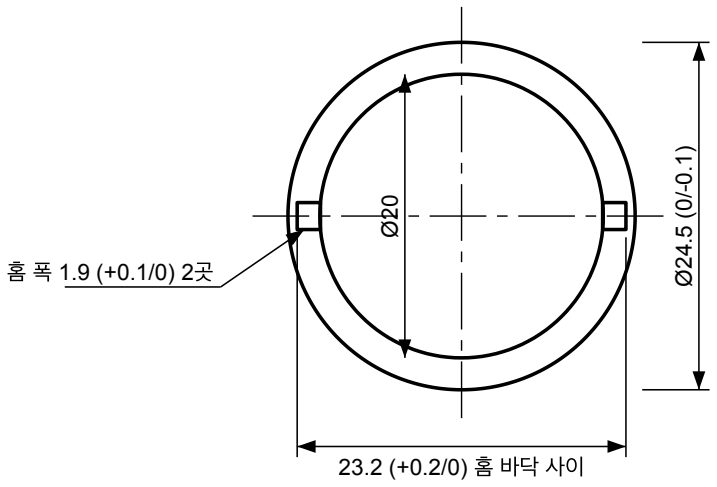
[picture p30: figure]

### 주기 (NOTES)

1. M-105/106: MJF PA12-HP, 시제품 각 1개. 지정 공차는 출력 후 최종 검사 치수.

1a. 출력 공차 ±0.3 mm: 홈/외경 다듬기, M2 탭 후가공. 부족 치수는 재출력. 고온 성능 미확정.

2. PCB는 ⑫ 홀더에만 고정. ⑬ 링은 흔들림 방지(축 방향 자유) — 열팽창 흡수.
3. J3 = JST SM04B-SRSS-TB (SH 1.0 mm 4P, side entry, SMD), 높이 2.95, 홀더 뒤 12.5 (꽂을 공간). W-1(40 mm)로 HTX99R와 연결. 조립 후 하우징 안 전체 몰딩.
4. J1 = JST SM08B-GHS-TB (GH 1.25 mm 8P, side entry, SMD), 입구 뒤쪽(+x). 하네스 W-2(40 mm)로 M12 8P. J5 = 샤시 선 납땜 구멍 (→ 홀더 위 축 나사 링 단자).

PCB 폭 23 구간은 x 61.4에서 끝 (턴버클 끝 엔드캡 앞면 x 62와 틈 0.6). 링 뒤(x ≥ 57) 부품은 Ø20 안 (링을 뒤에서 끼움).

5. PCB 외곽·구역은 KiCad hardware/kicad/HMT500(ED260313A)/HMT500(ED260313A).kicad_pcb 와 같음.
1 | 2 | 3 | 4 | 5 | 6 | 7 | 8

A

B

C

D

E

F

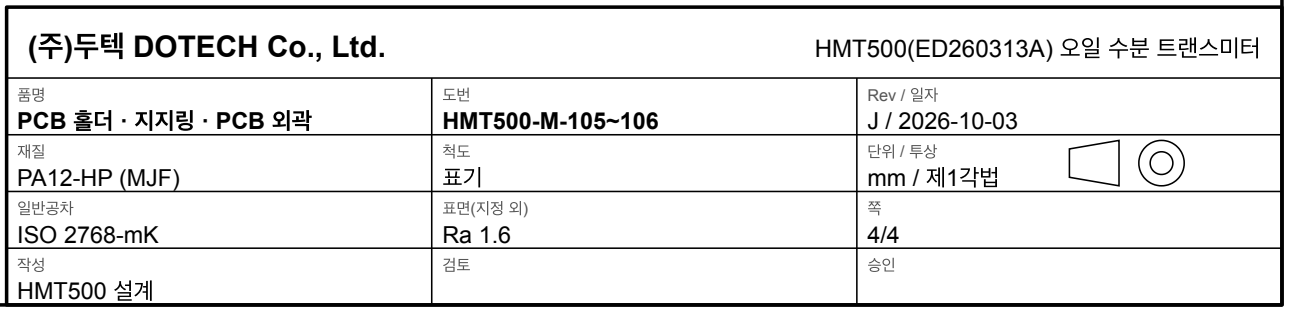
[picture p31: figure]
품명 PCB 홀더 · 지지링 · PCB 외곽; 도번 HMT500-M-105~106; Rev / 일자 J / 2026-10-03; 재질 PA12-HP (MJF); 일반공차 ISO 2768-mK; 작성 HMT500 설계

(주)두텍 DOTECH Co., Ltd. | HMT500(ED260313A) 오일 수분 트랜스미터

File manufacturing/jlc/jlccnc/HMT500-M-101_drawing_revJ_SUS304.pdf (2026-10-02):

캡 칼라 Ø12.3 (+0.1/0) 깊이 3.5 — 보호캡 뿌리를 감쌈 (HTX99R 굽힘 보호)

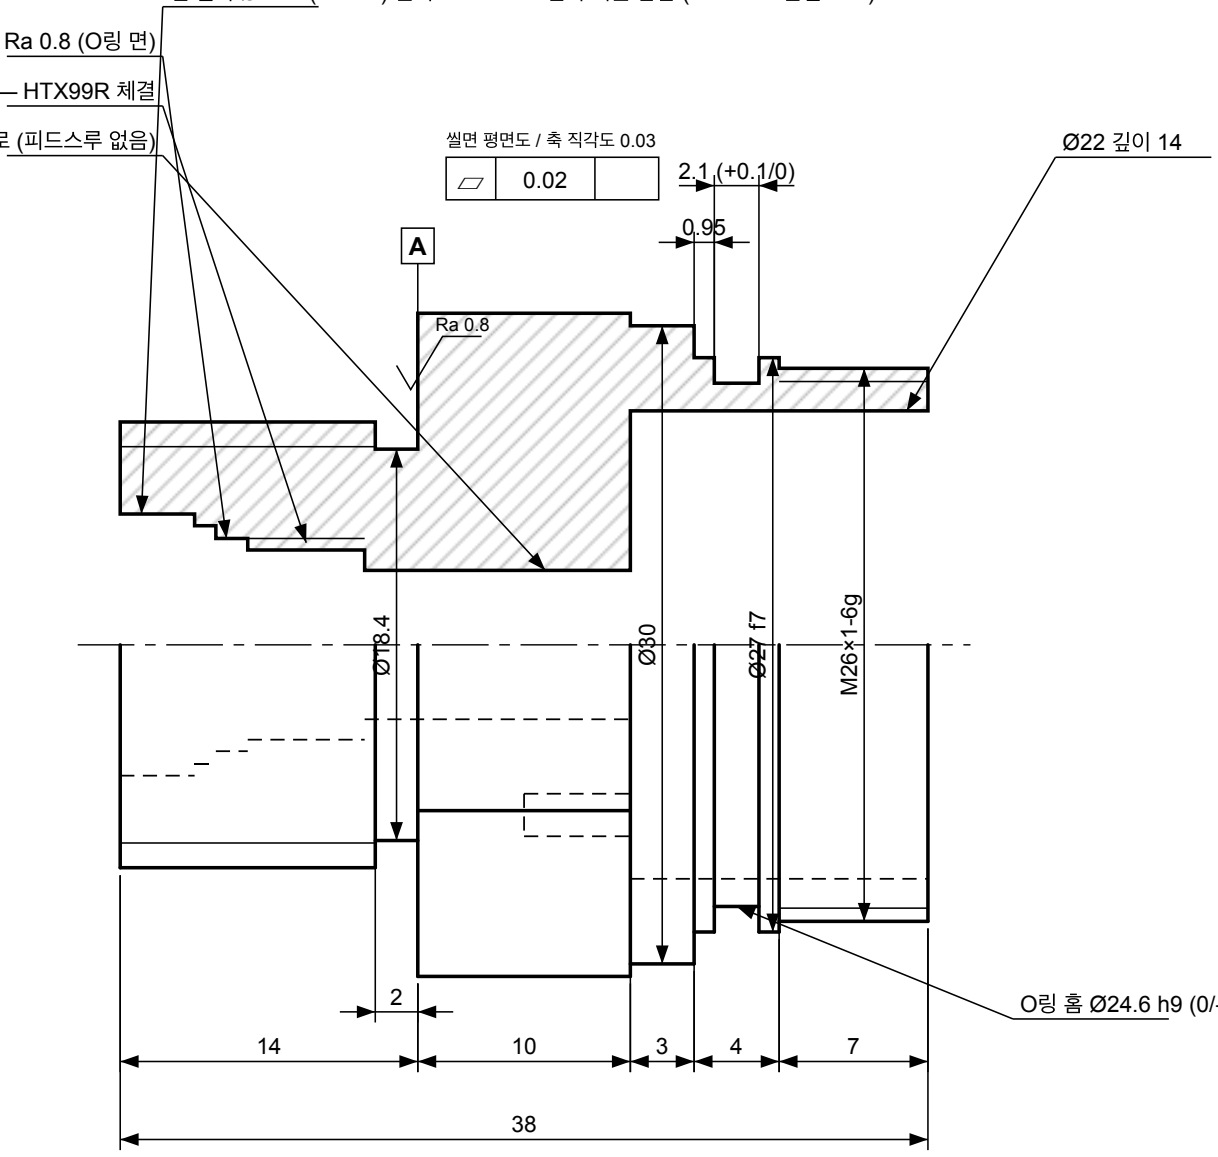
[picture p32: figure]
씰면 평면도 / 축 직각도 0.03

Ø11.2 깊이 1 / Ø10 H8 (+0.022/0) 깊이 1.5, Ra 0.8 (O링 면)

M10×1.0-6H 나사 길이 5.5 (커넥터 자리 면에서 8) — HTX99R 체결

Ø7 관통 12.5 — 센서 하네스 W-1 통로 (피드스루 없음)

O링 홈 Ø24.6 h9 (0/-0.052), R0.2 — O링 24×1.5

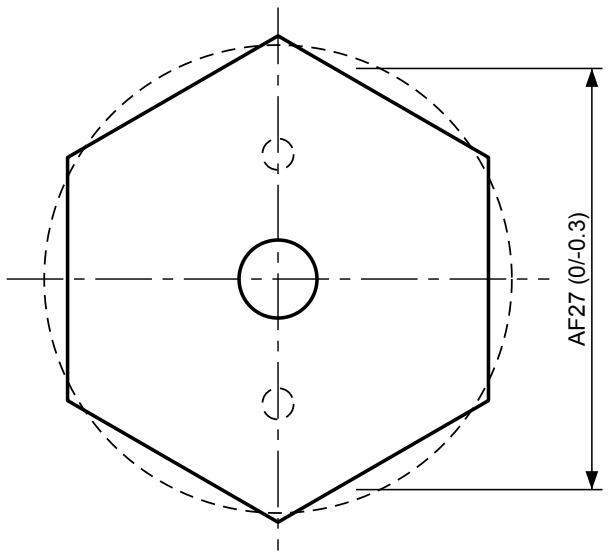
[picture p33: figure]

화살표 방향에서 본 육각 끝면 (2.2:1)

모따기 30° 양쪽 / 숨은선 = 칼라 Ø30
숨은선 원 2개: 2×M2-6H 깊이 5, PCD 16 (Ø22 카운터보어 바닥, PCB 홀더 M-105 고정)

주기 (NOTES)

1. 재질 SUS304 (prototype), 봉재 선삭. 재질성적서 EN 10204 3.1.
2. 지정 없는 모서리 C0.3, 날카로운 모서리 제거. 지정 외 표면 Ra 1.6.
3. 씰면(기준면 A) Ra 0.8, 평면도 0.02, 공구 자국 반경 방향 금지 (씰 누설 방지).
4. Ø7 관통 통로 양끝 C0.3·버 완전 제거 (하네스 피복 보호). Ø10 H8 Ra 0.8 (O링 밀봉면), 입구 C0.3.
5. 나사 G1/2-A: ISO 228-1, 불완전 나사부는 언더컷(2)에 포함.
6. M26×1-6g 끝 C0.5×30° (O링 도입부), Ø27 f7 (-0.020/-0.041) 밀봉면 Ra 0.8, 홈 바닥·측면 Ra 1.6, 버 금지.

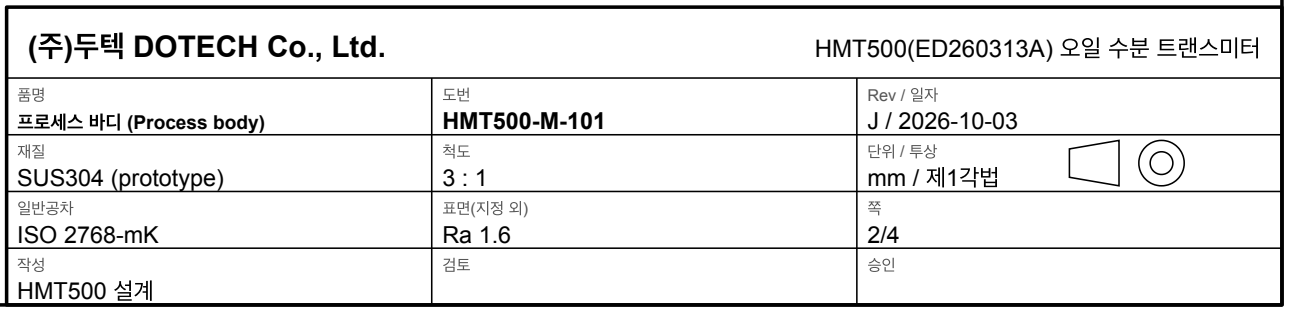
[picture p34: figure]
(주)두텍 DOTECH Co., Ltd.; HMT500(ED260313A) 오일 수분 트랜스미터; 품명 프로세스 바디 (Process body); 도번 HMT500-M-101; Rev / 일자 J / 2026-10-03; 재질 SUS304 (prototype); 일반공차 ISO 2768-mK; 작성 HMT500 설계

7. 전해 연마 또는 부동태 처리 (ASTM A967). 내압 설계 정격 50 bar (200 bar형 별도 검토).

## HMT500-M-101 프로세스 바디 — 반단면 (3:1)

1 | 2 | 3 | 4 | 5 | 6 | 7 | 8

A

B

C

D

E

F

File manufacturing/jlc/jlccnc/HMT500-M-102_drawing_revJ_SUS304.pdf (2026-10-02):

## HMT500-M-102 센서 보호캡 (3.5:1) — 두텍 390000-001100 기반

Rev H: 원 도면(2020-06-08, 소재 Ø12×32)에서 끝 쪽 5.5 연장 + 옆 구멍 1줄 추가. 재질 SUS304, 소재 Ø12×37.5

## HMT500-M-104 엔드캡 (2.5:1)

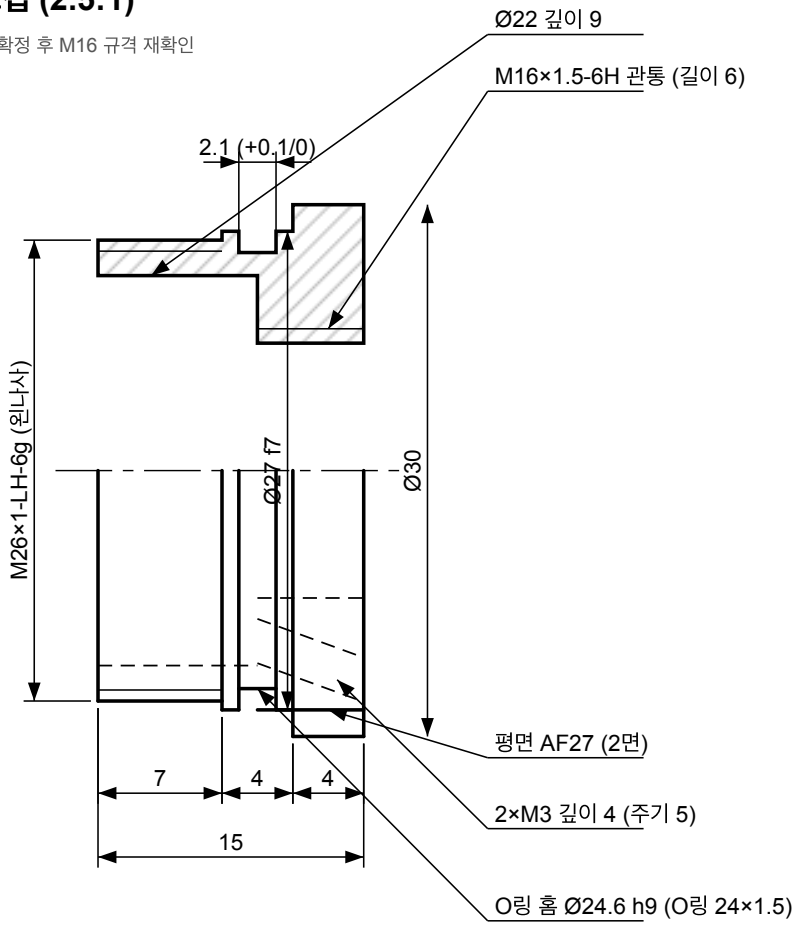
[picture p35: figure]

커넥터 O링 면 Ra 0.8 / 커넥터 P/N 확정 후 M16 규격 재확인

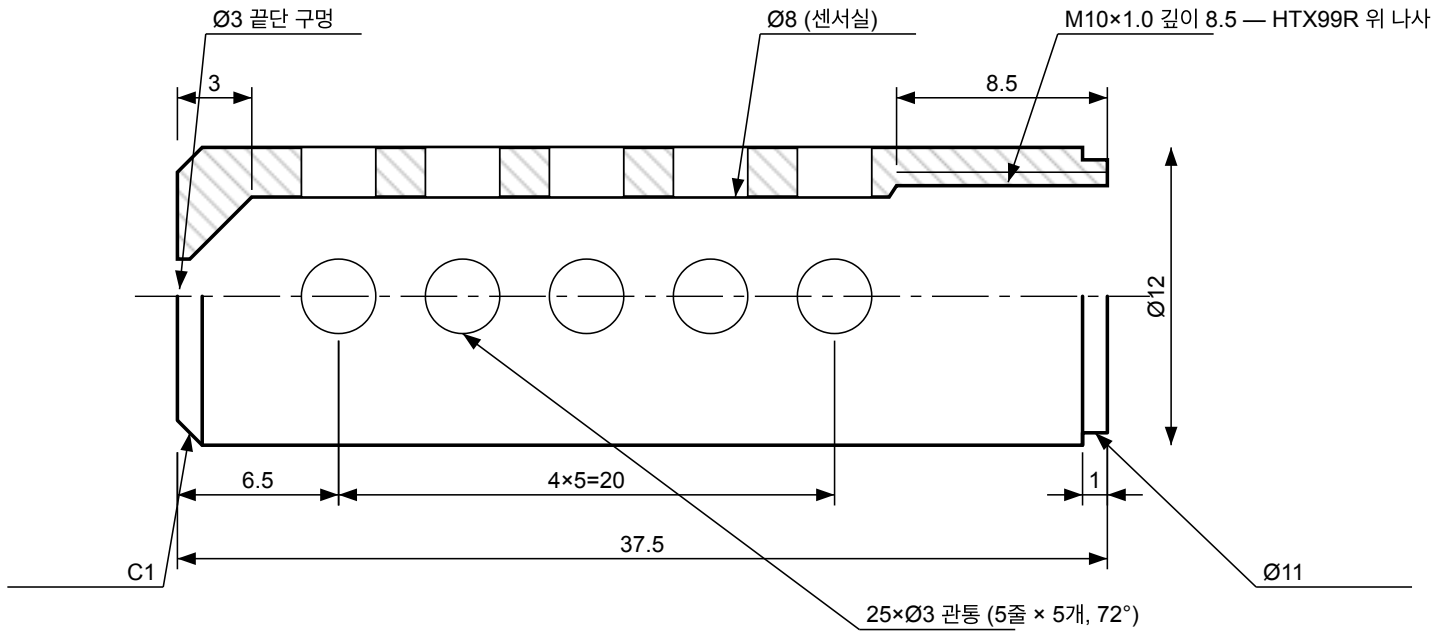
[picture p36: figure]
Ø8 (센서실); M10×1.0 깊이 8.5 — HTX99R 위 나사

## HMT500-M-103 하우징 (1.5:1)

양 끝 C0.5×15° (O링 도입부) / 외면 Ra 0.8 헤어라인 또는 비드 / 레이저 마킹 영역 45×20

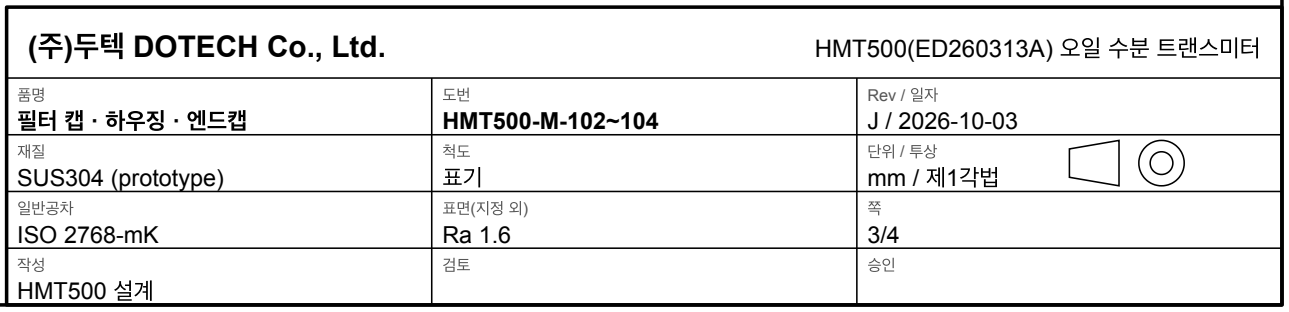
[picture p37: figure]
(주)두텍 DOTECH Co., Ltd.; HMT500(ED260313A) 오일 수분 트랜스미터; 품명 필터 캡 · 하우징 · 엔드캡; 도번 HMT500-M-102~104; Rev / 일자 J / 2026-10-03; 재질 SUS304 (prototype); 일반공차 ISO 2768-mK; 작성 HMT500 설계

### 주기 (NOTES)

1. 재질 SUS304 (prototype), 재질성적서 EN 10204 3.1, 부동태 처리 (ASTM A967).
2. 지정 없는 모서리 C0.3, 버 제거. 지정 외 표면 Ra 1.6. 일반공차 ISO 2768-mK.
3. ③–① M26×1 오른나사, ③–④ M26×1 왼나사 (턴버클: ③만 돌림) + O링 24×1.5 FKM, Ø27 H8/f7. 왼나사 끝에 'LH' 각인.
4. ③ 나사·밀봉 보어는 한 번 척킹으로 가공 (동축도 Ø0.05). ② 보호캡은 SUS304 (두텍 필터 기반) — 접액부 316L 통일 여부 검토.

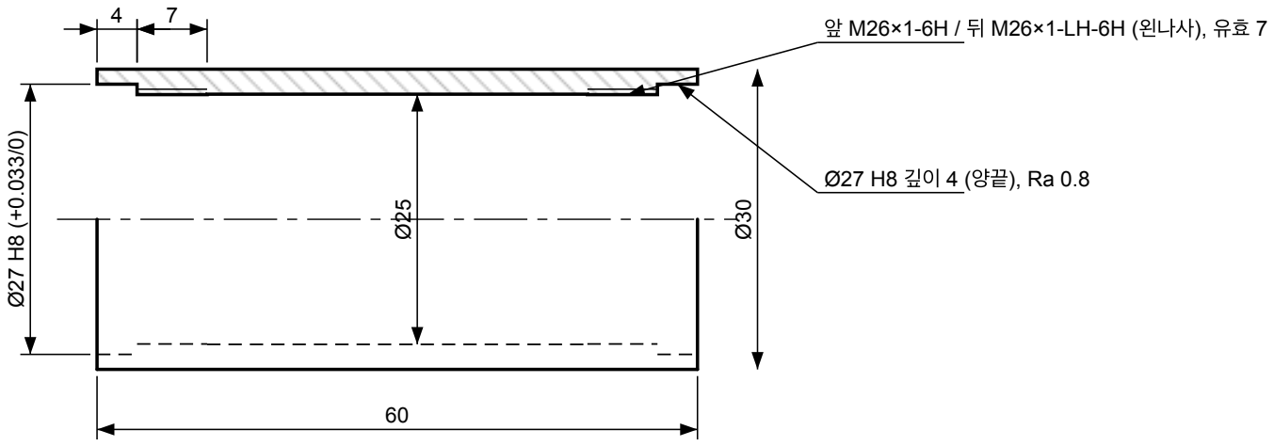
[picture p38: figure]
앞 M26×1-6H / 뒤 M26×1-LH-6H (왼나사), 유효 7

5. ④ M3 구멍 2개 (r11.8, 90°·270°, 축에서 안쪽 20°, Ø2.5 관통): 하우징 안 몰딩 주입·공기 빠짐. 경화 후 M3×3 무두나사 + 실런트로 막음.
1 | 2 | 3 | 4 | 5 | 6 | 7 | 8

A

B

C

D

E

F

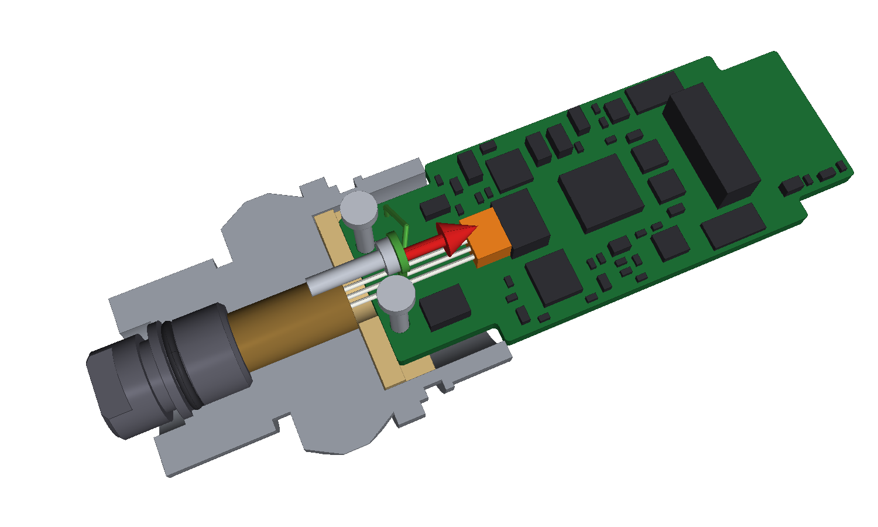
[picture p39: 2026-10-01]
hardware/mech/out/assembly_procedure/step_10.png

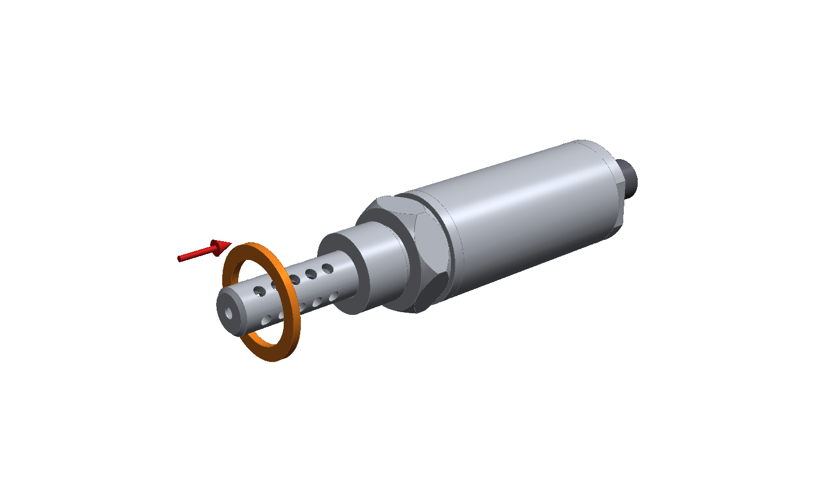
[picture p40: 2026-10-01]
hardware/mech/out/assembly_procedure/step_19.png

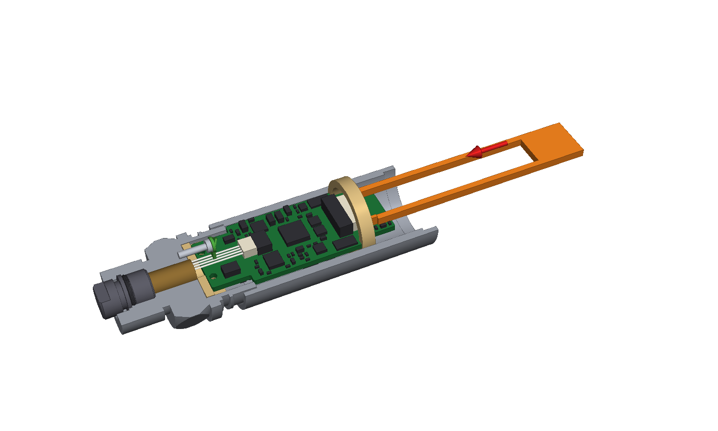
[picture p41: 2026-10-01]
hardware/mech/out/assembly_procedure/step_15.png

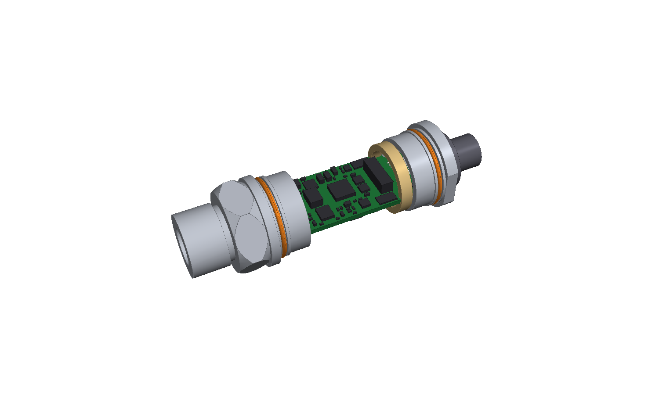
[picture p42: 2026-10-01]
hardware/mech/out/assembly_procedure/step_13.png

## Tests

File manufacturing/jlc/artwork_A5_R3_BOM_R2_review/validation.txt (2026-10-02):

회로v0.11 / PCB A5-R3 / BOM R2
넷리스트81/81 오류0
DRC 오류0, 미연결0, 기존경고24
33 tests OK
배선/비아 형상, 부품위치/방향/층, 패드형상/넷 불변
전 저항18행/30개 JLC 공개 주문 가능 수량>0 확인

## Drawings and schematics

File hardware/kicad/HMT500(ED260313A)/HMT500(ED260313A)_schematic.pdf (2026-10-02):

1 | 2 | 3 | 4 | 5 | 6 | 7 | 8

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
Size: A3 | Rev: 0.10 | F Date: 2026-10-01
KiCad E.D.A. 10.0.6 | Id: 1/8

# Title: HMT500(ED260313A) Top

### File: HMT500(ED260313A).kicad_sch

### Sheet: /

DOTECH Co., Ltd.

### Project No. HMT500(ED260313A) - HMT500(ED260313A) oil moisture transmitter

### Design notes: docs/hw/circuit-design.md

### Pinouts checked vs manufacturer datasheets 2026-09-30 (STM32: KiCad lib)

## 3. MCU

파일: HMT500(ED260313A)_mcu.kicad_sch

6. RS-485

파일: HMT500(ED260313A)_rs485.kicad_sch

## 1. Connector & input protection

파일: HMT500(ED260313A)_connector.kicad_sch

## 2. Power

파일: HMT500(ED260313A)_power.kicad_sch

## 7. Aux

파일: HMT500(ED260313A)_aux.kicad_sch

## 5. Analog outputs

파일: HMT500(ED260313A)_analog_out.kicad_sch

## 4. Measurement

파일: HMT500(ED260313A)_measurement.kicad_sch eFuse (reverse/OV/UV), 60V buck to 5V,

글자 겹침: 생성기가 부품 몸체·핀·선·라벨·메모와 겹치지 않는 자리에 자동 배치하고, 겹치면 생성 실패로 처리

2x DAC8760 V/I output with TPS26611 | Capacitive humidity sensor (PCAP04) LDO 3.3V | and Pt1000 2-wire (ADS1220)
STM32G0B1CCT6, SWD, reset, internal temperature sensor AO supply VAO 16.1 V (buck), supply monitor

isolation

TVS surge protection, chassis Field connector, 2-stage bidirectional | THVD2410 +/-70V fault-protected

transceiver DOTECH HMT500(ED260313A) - Oil Moisture Transmitter - Schematic v0.9 - Project No. HMT500(ED260313A)

Signal flow: J1 field connector -> protection -> eFuse -> 5 V buck -> 3.3 V LDO; sensor head J3 -> PCAP04 / ADS1220 -> MCU -> DAC8760 x2 / THVD2410 -> J1

v0.9: 3-pass review (docs/hw/final-review-260313A.md): OVP 32.6 V (R5 36.5k); AO supply VAO 16.1 V buck U15 (DAC AVDD, TPS26611 +Vs; dec. #37, IVS320 AO); D3 series Schottky; RS-485 TVS D60/D61; D2 -> TVS3301; eFuse IN C2; buck CIN;

RS485_DE 10k pull-down (in-house bootloader, dec. #31); THVD2410; X7R only; R2 HV 1206; SGOOD -> PA0/PA4; CS_CDC -> PA15; VIN_SENSE PB0;

LATCH/CS pull-ups; OPA197 V+ = DAC AVDD; R31/R41 100k; SWD no-connect flags removed; sheet Aux: +Vs clamp, VIN monitor (DAC boost / HSE / sensor ESD: no room, dec. #32). File names (schematic, PCB, Gerber) = HMT500(ED260313A).* PCB silkscreen marking = HMT500(ED260313A)

Outputs: RS-485 Modbus RTU + 2x analog (4-20 mA / 0-20 mA / 0-10 V / 0-5 V selectable). Supply 12-28 V DC. v0.10: AO D30/D40 TVS1401 +/-14 V. AO +/-28/30 V continuous miswiring is NOT guaranteed (#41). Power symbols: GND, +3V3, +3V3A (analog 3.3 V), +5V, VIN_P (protected input), CHASSIS. Inter-sheet signals: global labels. History v0.3-v0.8 (MCU G0B1, JST harness, DAC8760/TPS26611 datasheet pinouts, RTN isolation, gated DAC SCLK ...): docs/decision-log.md #9-#26.

Footprints: KiCad 7.0.11 library + project library HMT500_260313A (GDT Bourns 2035-xx-SM, TVS3301 pad floating).

라벨 모양 = 신호 방향: 뾰족한 쪽이 밖 = 이 시트에서 내보냄(출력), 안 = 받음(입력), 양쪽 = 양방향, 네모 = 아날로그·수동

표기 규칙: 부품번호 = 굵은 글자 (R1, U4) / 부품값 = 보통 글자 (10k, DAC8760) / 전원 네트 = 기울인 글자 (+3V3, VIN_P)

신호 네트 = 테두리 있는 라벨 (SPI_SCK, OUT1_EXT) - 네트 이름은 부품번호·부품명과 겹치지 않게 지음

miswiring protection

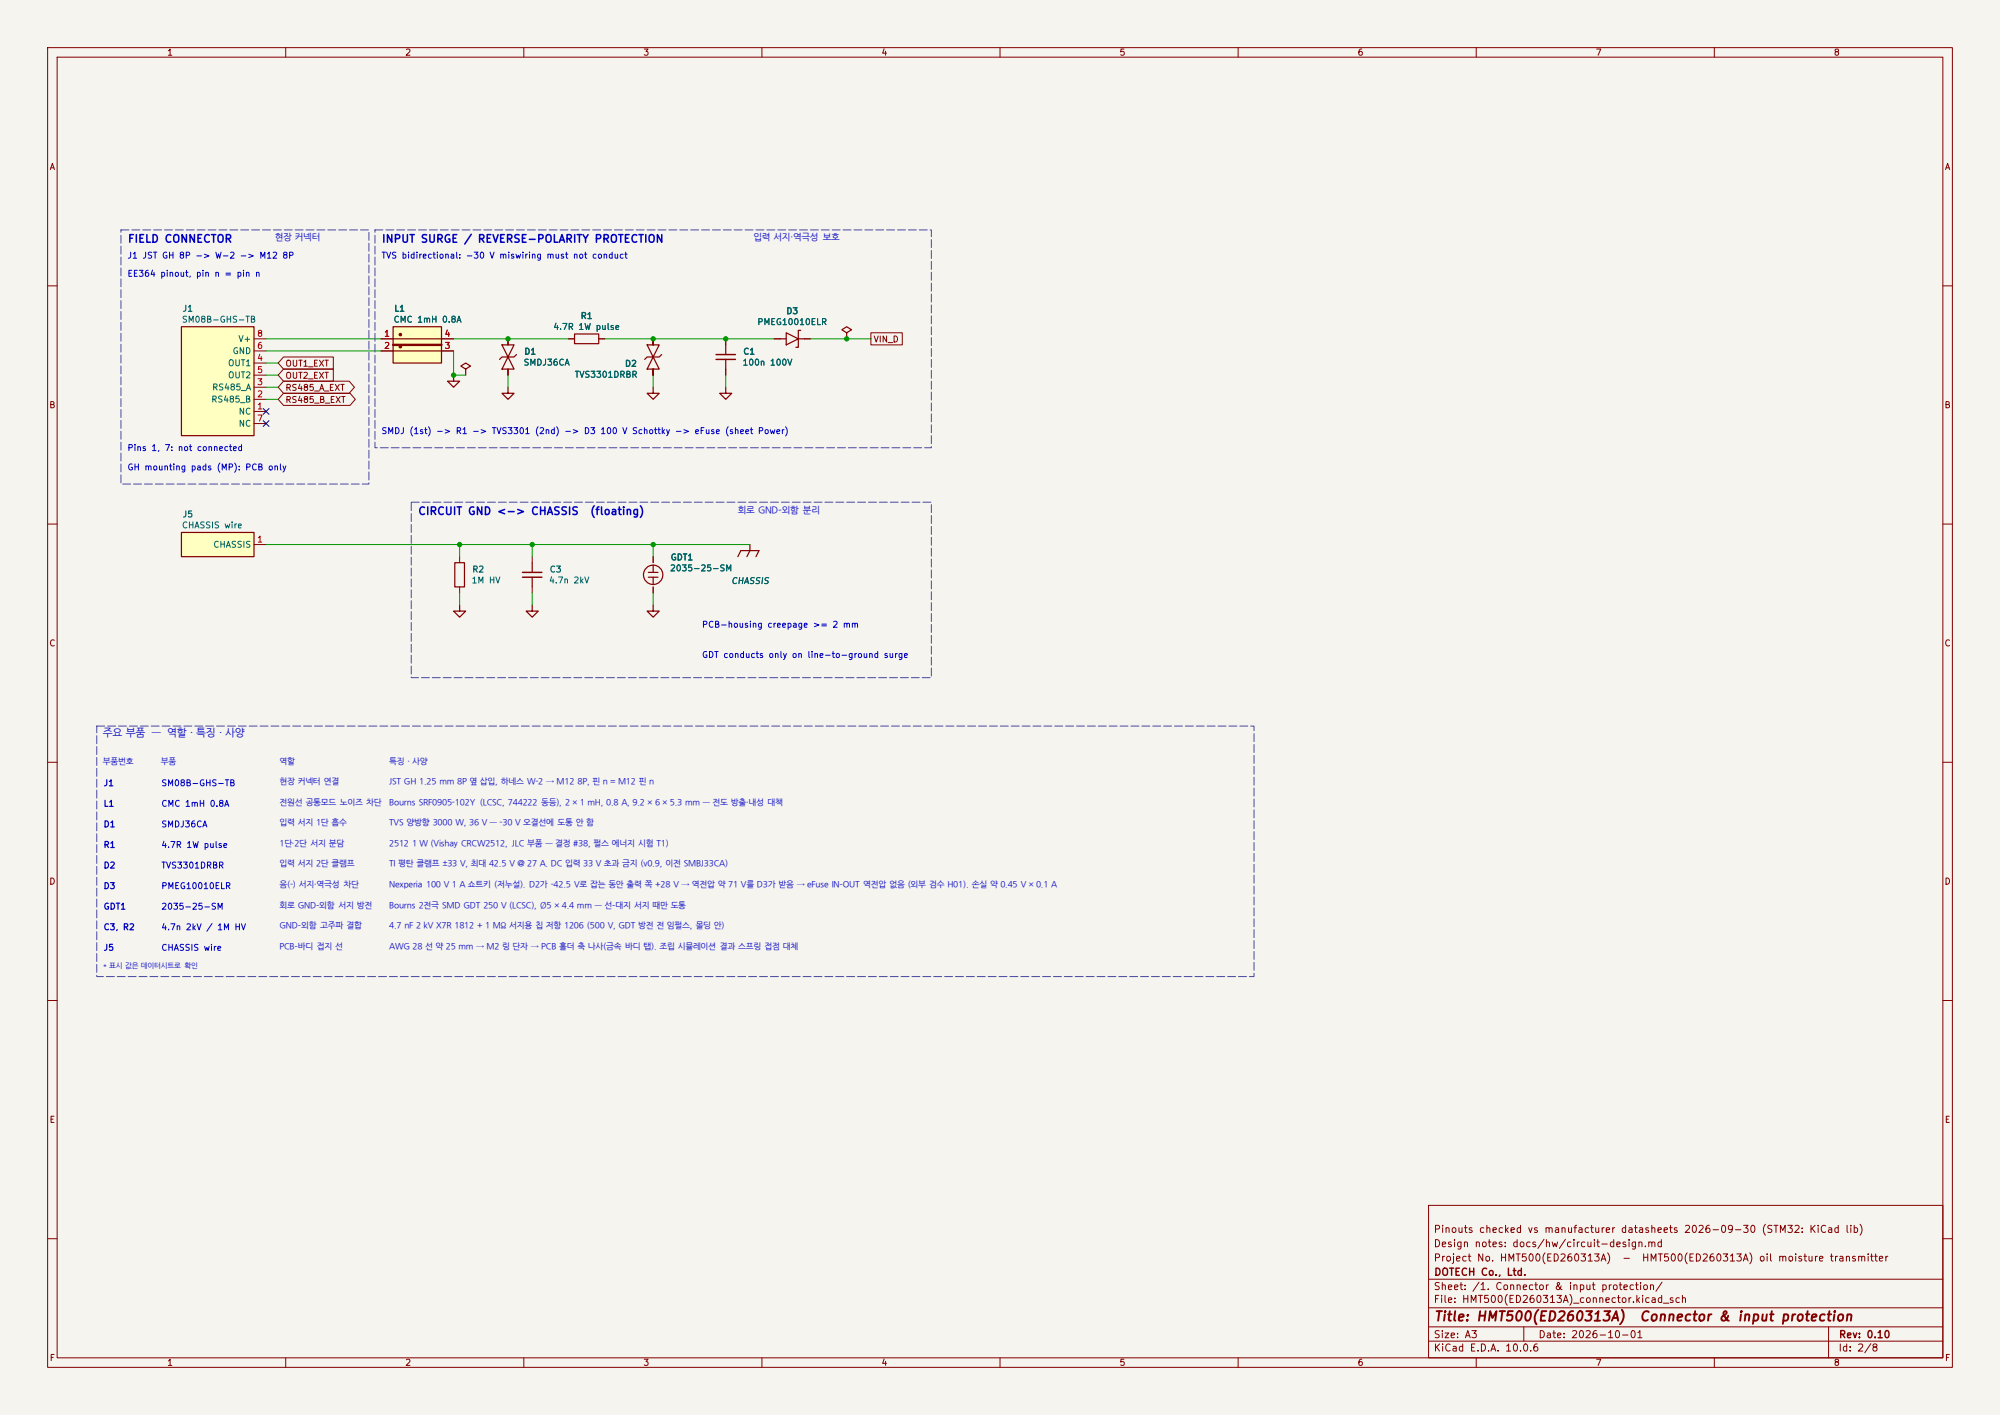
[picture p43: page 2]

INPUT SURGE / REVERSE-POLARITY PROTECTION

입력 서지·역극성 보호

TVS bidirectional: -30 V miswiring must not conduct 부품번호

Pins 1, 7: not connected GH mounting pads (MP): PCB only EE364 pinout, pin n = pin n

SMDJ (1st) -> R1 -> TVS3301 (2nd) -> D3 100 V Schottky -> eFuse (sheet Power)

CIRCUIT GND <-> CHASSIS (floating)

GDT conducts only on line-to-ground surge PCB-housing creepage >= 2 mm

* 표시 값은 데이터시트로 확인 주요 부품 — 역할 · 특징 · 사양

JST GH 1.25 mm 8P 옆 삽입, 하네스 W-2 → M12 8P, 핀 n = M12 핀 n

전원선 공통모드 노이즈 차단

Bourns SRF0905-102Y (LCSC, 744222 동등), 2 × 1 mH, 0.8 A, 9.2 × 6 × 5.3 mm — 전도 방출·내성 대책

TVS 양방향 3000 W, 36 V — -30 V 오결선에 도통 안 함

2512 1 W (Vishay CRCW2512, JLC 부품 — 결정 #38, 펄스 에너지 시험 T1)

Nexperia 100 V 1 A 쇼트키 (저누설). D2가 -42.5 V로 잡는 동안 출력 쪽 +28 V → 역전압 약 71 V를 D3가 받음 → eFuse IN–OUT 역전압 없음 (외부 검수 H01). 손실 약 0.45 V × 0.1 A

회로 GND–외함 서지 방전

Bourns 2전극 SMD GDT 250 V (LCSC), Ø5 × 4.4 mm — 선–대지 서지 때만 도통

GND–외함 고주파 결합

4.7 nF 2 kV X7R 1812 + 1 MΩ 서지용 칩 저항 1206 (500 V, GDT 방전 전 임펄스, 몰딩 안)

Pinouts checked vs manufacturer datasheets 2026-09-30 (STM32: KiCad lib)
Design notes: docs/hw/circuit-design.md
Project No. HMT500(ED260313A) - HMT500(ED260313A) oil moisture transmitter
DOTECH Co., Ltd.
Sheet: /1. Connector & input protection/
File: HMT500(ED260313A)_connector.kicad_sch
Title: HMT500(ED260313A) Connector & input protection

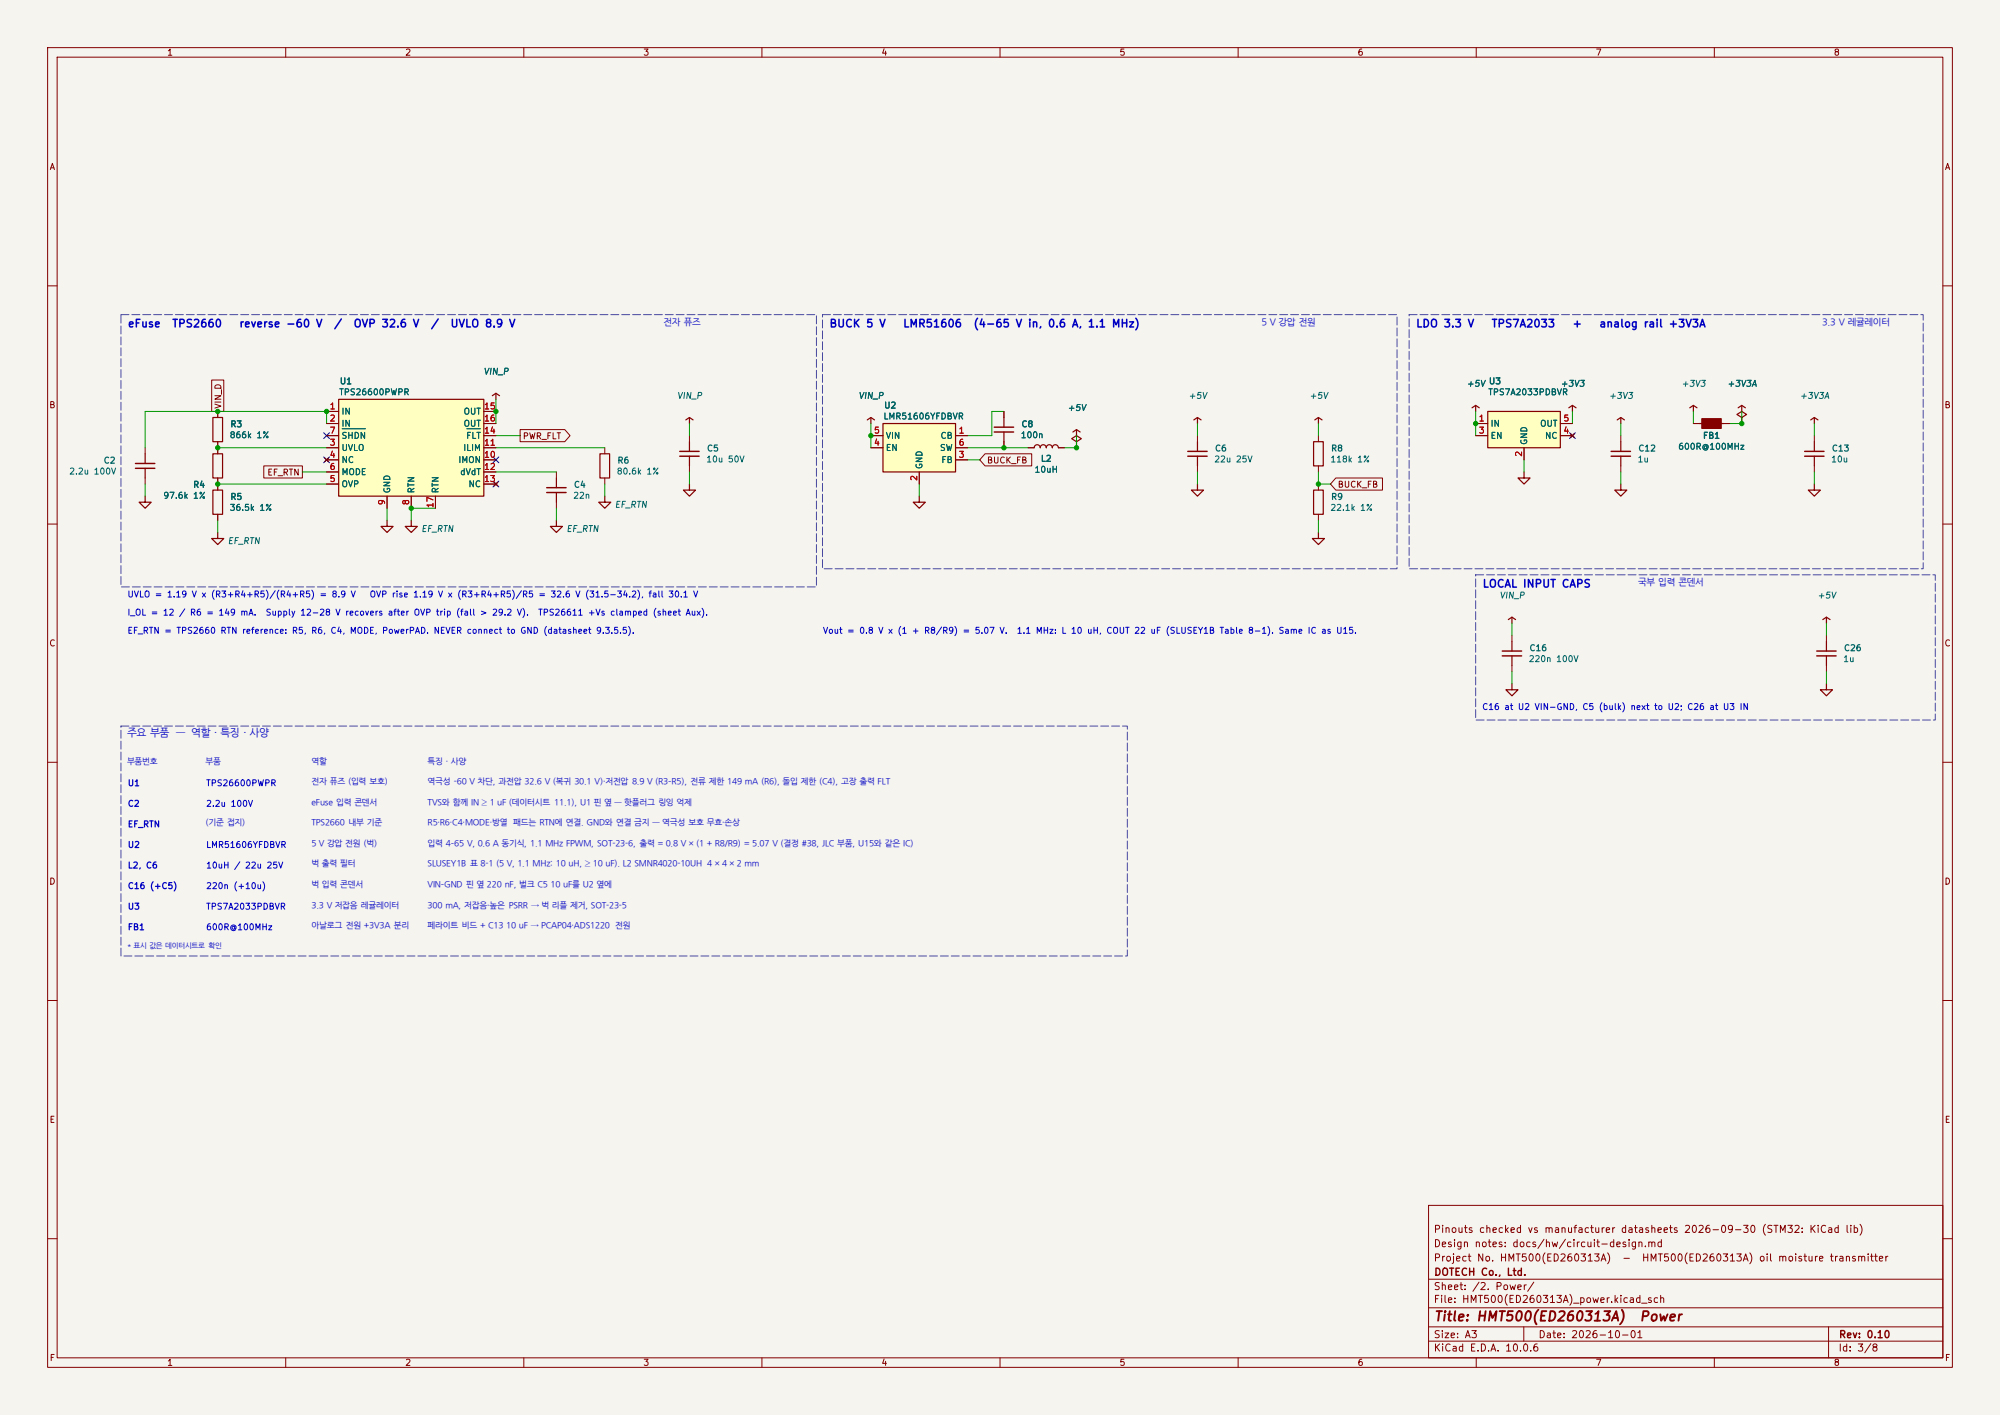
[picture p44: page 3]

FLT 14 OUT 15 OUT 16 RTN 17
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

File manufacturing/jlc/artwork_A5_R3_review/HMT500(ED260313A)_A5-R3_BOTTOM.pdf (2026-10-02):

## HMT500(ED260313A) A5-R3 / BOTTOM / ACTUAL PCB SILKSCREEN

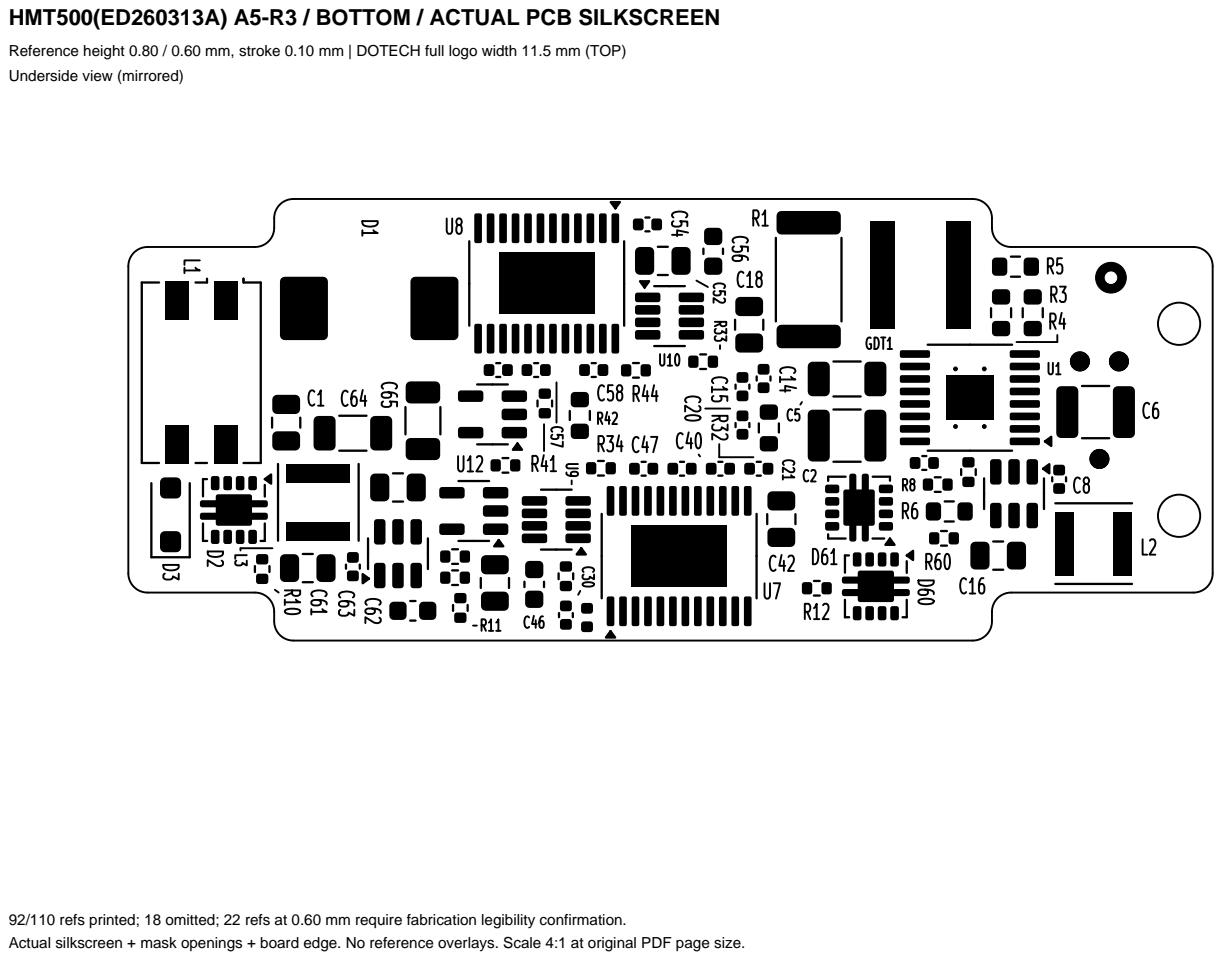
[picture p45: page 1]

Reference height 0.80 / 0.60 mm, stroke 0.10 mm | DOTECH full logo width 11.5 mm (TOP)
Underside view (mirrored)

92/110 refs printed; 18 omitted; 22 refs at 0.60 mm require fabrication legibility confirmation.
Actual silkscreen + mask openings + board edge. No reference overlays. Scale 4:1 at original PDF page size.

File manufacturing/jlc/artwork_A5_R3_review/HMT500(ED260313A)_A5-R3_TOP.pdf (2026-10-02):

## HMT500(ED260313A) A5-R3 / TOP / ACTUAL PCB SILKSCREEN

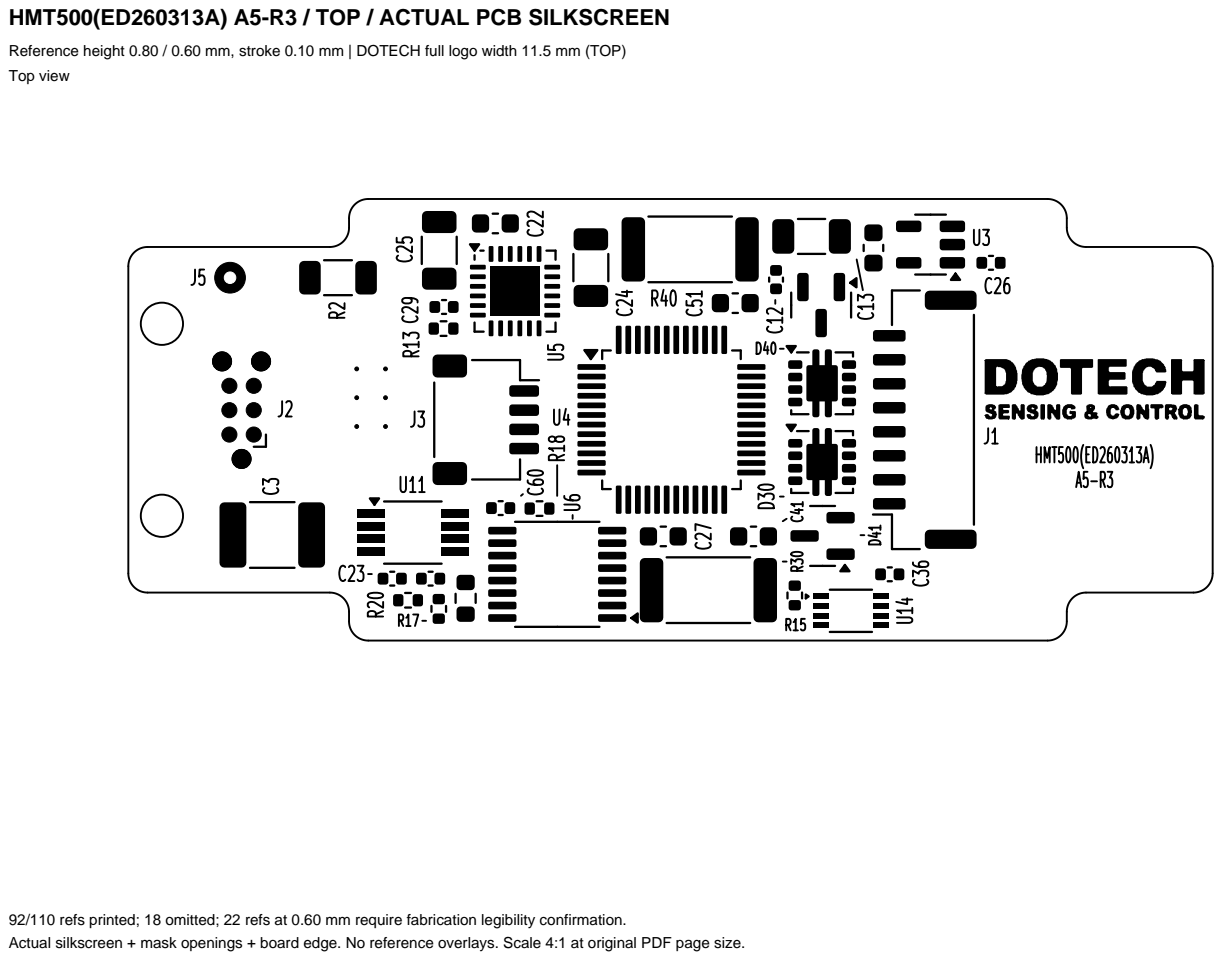
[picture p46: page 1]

Reference height 0.80 / 0.60 mm, stroke 0.10 mm | DOTECH full logo width 11.5 mm (TOP)
Top view

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

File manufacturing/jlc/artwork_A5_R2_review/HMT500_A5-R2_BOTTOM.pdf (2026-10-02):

## HMT500 A5-R2 / BOTTOM / ACTUAL PCB SILKSCREEN

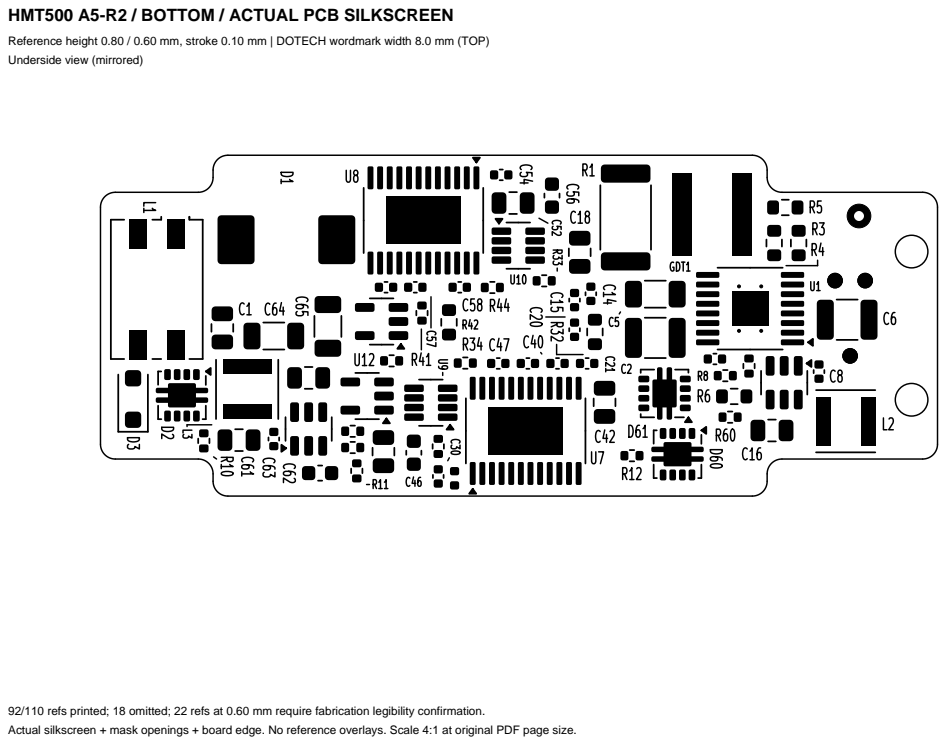
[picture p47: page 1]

Reference height 0.80 / 0.60 mm, stroke 0.10 mm | DOTECH wordmark width 8.0 mm (TOP)
Underside view (mirrored)

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

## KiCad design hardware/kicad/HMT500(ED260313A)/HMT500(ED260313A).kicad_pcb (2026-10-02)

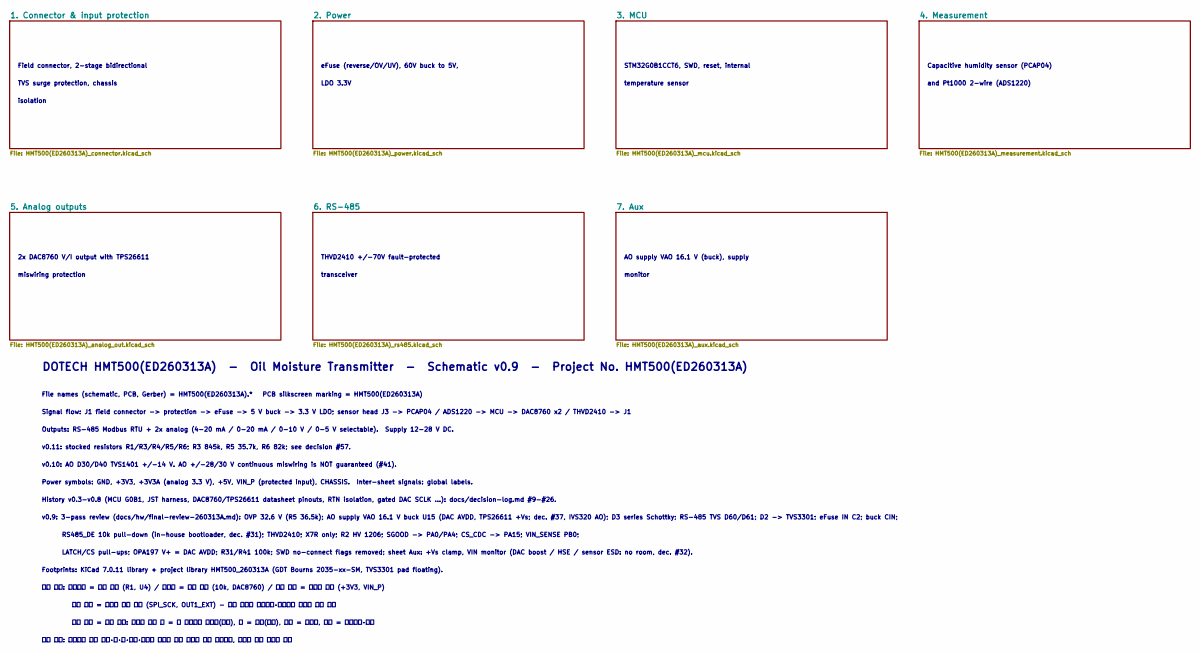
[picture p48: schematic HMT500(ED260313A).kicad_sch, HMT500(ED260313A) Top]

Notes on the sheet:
Field connector, 2-stage bidirectional
TVS surge protection, chassis
isolation
eFuse (reverse/OV/UV), 60V buck to 5V,
LDO 3.3V
STM32G0B1CCT6, SWD, reset, internal
temperature sensor
Capacitive humidity sensor (PCAP04)
and Pt1000 2-wire (ADS1220)
2x DAC8760 V/I output with TPS26611
miswiring protection
THVD2410 +/-70V fault-protected
transceiver
AO supply VAO 16.1 V (buck), supply
monitor
DOTECH HMT500(ED260313A) - Oil Moisture Transmitter - Schematic v0.9 - Project No. HMT500(ED260313A)
File names (schematic, PCB, Gerber) = HMT500(ED260313A).* PCB silkscreen marking = HMT500(ED260313A)
Signal flow: J1 field connector -> protection -> eFuse -> 5 V buck -> 3.3 V LDO; sensor head J3 -> PCAP04 / ADS1220 -> MCU -> DAC8760 x2 / THVD2410 -> J1
Outputs: RS-485 Modbus RTU + 2x analog (4-20 mA / 0-20 mA / 0-10 V / 0-5 V selectable). Supply 12-28 V DC.
v0.11: stocked resistors R1/R3/R4/R5/R6; R3 845k, R5 35.7k, R6 82k; see decision #57.
v0.10: AO D30/D40 TVS1401 +/-14 V. AO +/-28/30 V continuous miswiring is NOT guaranteed (#41).
Power symbols: GND, +3V3, +3V3A (analog 3.3 V), +5V, VIN_P (protected input), CHASSIS. Inter-sheet signals: global labels.
History v0.3-v0.8 (MCU G0B1, JST harness, DAC8760/TPS26611 datasheet pinouts, RTN isolation, gated DAC SCLK ...): docs/decision-log.md #9-#26.
v0.9: 3-pass review (docs/hw/final-review-260313A.md): OVP 32.6 V (R5 36.5k); AO supply VAO 16.1 V buck U15 (DAC AVDD, TPS26611 +Vs; dec. #37, IVS320 AO); D3 series Schottky; RS-485 TVS D60/D61; D2 -> TVS3301; eFuse IN C2; buck CIN;
RS485_DE 10k pull-down (in-house bootloader, dec. #31); THVD2410; X7R only; R2 HV 1206; SGOOD -> PA0/PA4; CS_CDC -> PA15; VIN_SENSE PB0;
LATCH/CS pull-ups; OPA197 V+ = DAC AVDD; R31/R41 100k; SWD no-connect flags removed; sheet Aux: +Vs clamp, VIN monitor (DAC boost / HSE / sensor ESD: no room, dec. #32).
Footprints: KiCad 7.0.11 library + project library HMT500_260313A (GDT Bourns 2035-xx-SM, TVS3301 pad floating).
표기 규칙: 부품번호 = 굵은 글자 (R1, U4) / 부품값 = 보통 글자 (10k, DAC8760) / 전원 네트 = 기울인 글자 (+3V3, VIN_P)
신호 네트 = 테두리 있는 라벨 (SPI_SCK, OUT1_EXT) - 네트 이름은 부품번호·부품명과 겹치지 않게 지음
라벨 모양 = 신호 방향: 뾰족한 쪽이 밖 = 이 시트에서 내보냄(출력), 안 = 받음(입력), 양쪽 = 양방향, 네모 = 아날로그·수동
글자 겹침: 생성기가 부품 몸체·핀·선·라벨·메모와 겹치지 않는 자리에 자동 배치하고, 겹치면 생성 실패로 처리

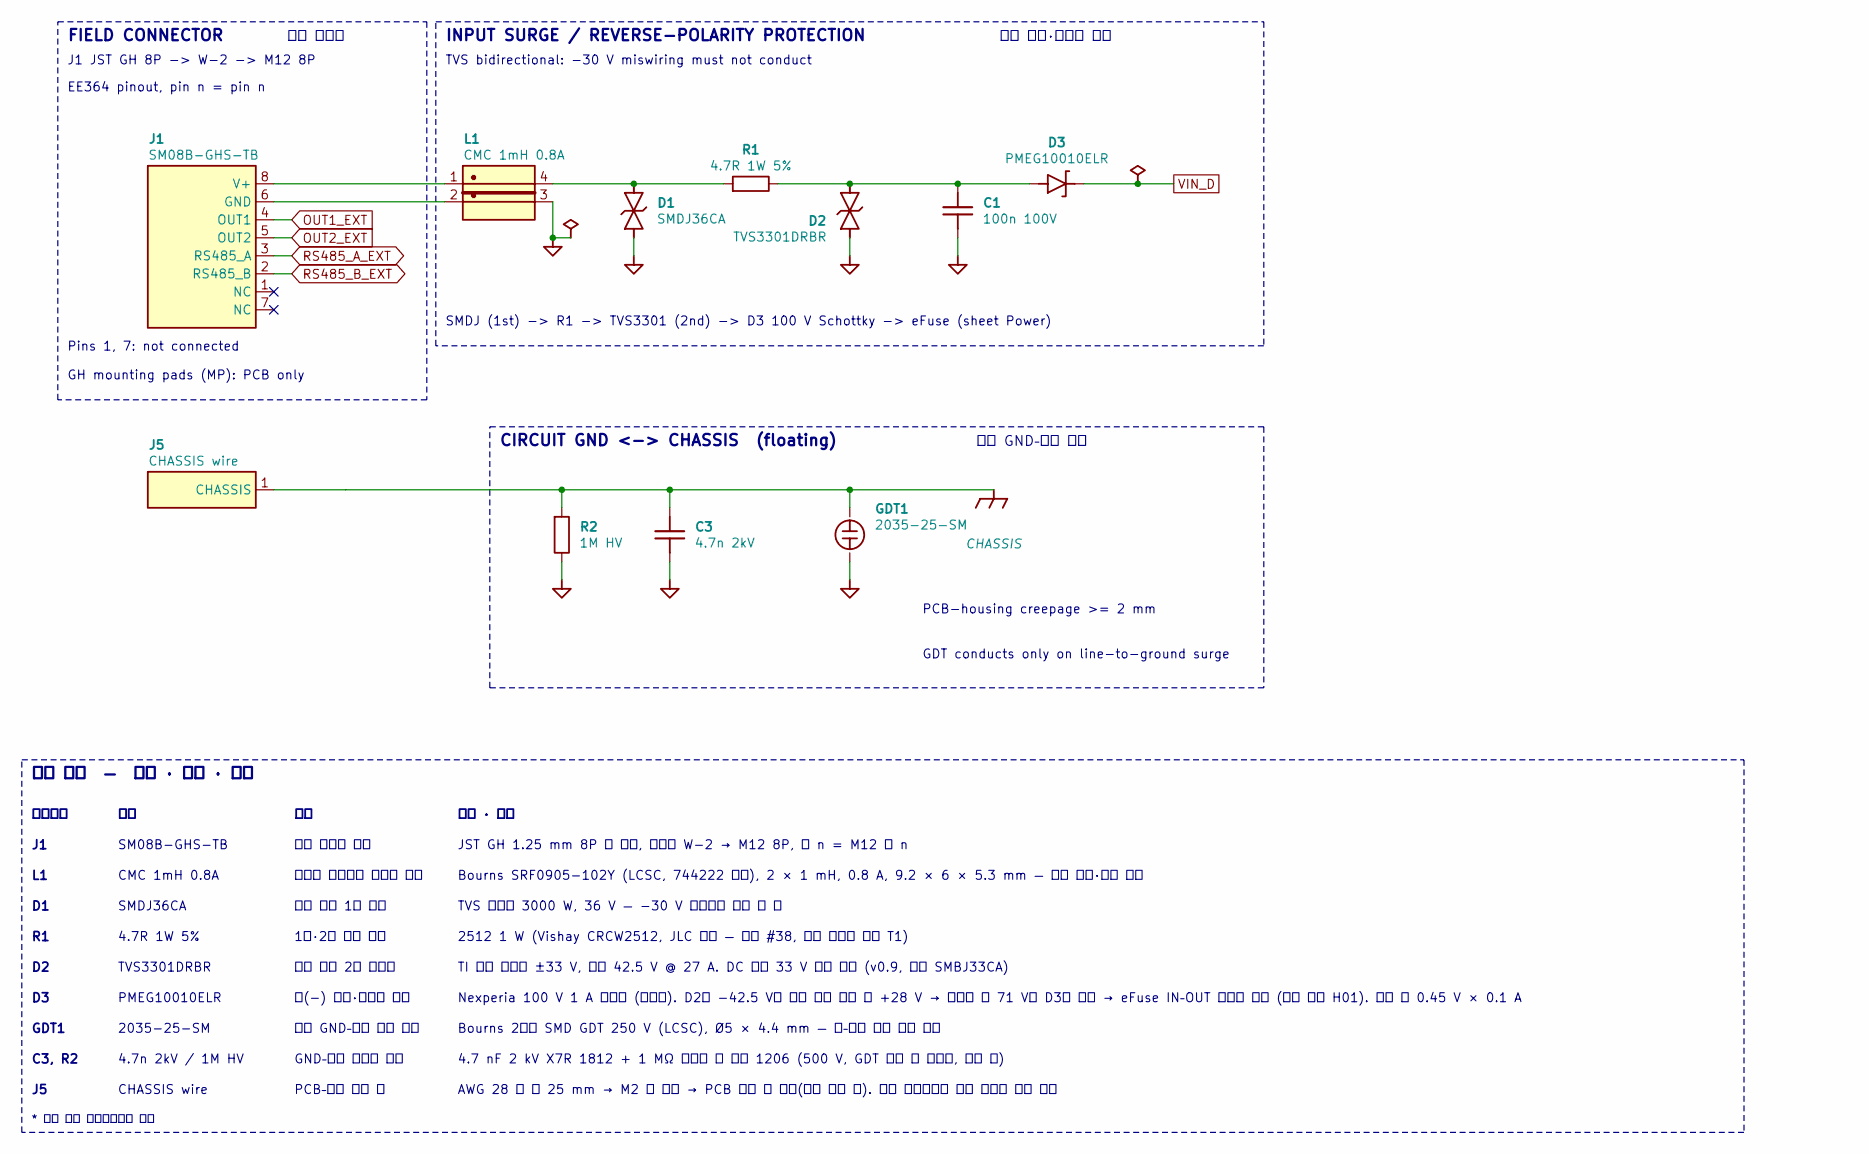
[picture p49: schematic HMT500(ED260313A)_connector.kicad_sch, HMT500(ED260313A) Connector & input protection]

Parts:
C1: 100n 100V; C_0805_2012Metric
C3: 4.7n 2kV; C_1812_4532Metric
D1: SMDJ36CA; D_SMC
D2: TVS3301DRBR; Texas_DRB0008A_PadFloat
D3: PMEG10010ELR; D_SOD-123F
GDT1: 2035-25-SM; GDT_Bourns_2035-xx-SM
J1: SM08B-GHS-TB; JST_GH_SM08B-GHS-TB_1x08-1MP_P1.25mm_Horizontal
J5: CHASSIS wire; SolderWire_Chassis_D0.6mm
L1: CMC 1mH 0.8A; L_CommonMode_Wuerth_WE-SL2
R1: 4.7R 1W 5%; R_2512_6332Metric
R2: 1M HV; R_1206_3216Metric

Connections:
CHASSIS: C3.1, GDT1.1, J5.1, R2.1
GND: C1.2, C3.2, D1.2, D2.5, D2.6, D2.7, D2.8, GDT1.2, L1.3, R2.2; also elsewhere on the board
GND_IN: J1.6 (GND), L1.2
OUT1_EXT: J1.4 (OUT1); also elsewhere on the board
OUT2_EXT: J1.5 (OUT2); also elsewhere on the board
RS485_A_EXT: J1.3 (RS485_A); also elsewhere on the board
RS485_B_EXT: J1.2 (RS485_B); also elsewhere on the board
VIN_D: D3.1; also elsewhere on the board
VIN_EXT: J1.8 (V+), L1.1
VIN_F: C1.1, D2.1, D2.2, D2.3, D2.4, D3.2, R1.2
VIN_L: D1.1, L1.4, R1.1

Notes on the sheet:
FIELD CONNECTOR
현장 커넥터
J1 JST GH 8P -> W-2 -> M12 8P
EE364 pinout, pin n = pin n
GH mounting pads (MP): PCB only
Pins 1, 7: not connected
INPUT SURGE / REVERSE-POLARITY PROTECTION
입력 서지·역극성 보호
TVS bidirectional: -30 V miswiring must not conduct
SMDJ (1st) -> R1 -> TVS3301 (2nd) -> D3 100 V Schottky -> eFuse (sheet Power)
CIRCUIT GND <-> CHASSIS (floating)
회로 GND–외함 분리
GDT conducts only on line-to-ground surge
PCB-housing creepage >= 2 mm
부품번호
특징 · 사양
SM08B-GHS-TB
현장 커넥터 연결
JST GH 1.25 mm 8P 옆 삽입, 하네스 W-2 → M12 8P, 핀 n = M12 핀 n
CMC 1mH 0.8A
전원선 공통모드 노이즈 차단
Bourns SRF0905-102Y (LCSC, 744222 동등), 2 × 1 mH, 0.8 A, 9.2 × 6 × 5.3 mm — 전도 방출·내성 대책
SMDJ36CA
입력 서지 1단 흡수
TVS 양방향 3000 W, 36 V — -30 V 오결선에 도통 안 함
4.7R 1W 5%
1단·2단 서지 분담
2512 1 W (Vishay CRCW2512, JLC 부품 — 결정 #38, 펄스 에너지 시험 T1)
TVS3301DRBR
입력 서지 2단 클램프
TI 평탄 클램프 ±33 V, 최대 42.5 V @ 27 A. DC 입력 33 V 초과 금지 (v0.9, 이전 SMBJ33CA)
PMEG10010ELR
음(-) 서지·역극성 차단
Nexperia 100 V 1 A 쇼트키 (저누설). D2가 -42.5 V로 잡는 동안 출력 쪽 +28 V → 역전압 약 71 V를 D3가 받음 → eFuse IN–OUT 역전압 없음 (외부 검수 H01). 손실 약 0.45 V × 0.1 A
GDT1
2035-25-SM
회로 GND–외함 서지 방전
Bourns 2전극 SMD GDT 250 V (LCSC), Ø5 × 4.4 mm — 선–대지 서지 때만 도통
C3, R2
4.7n 2kV / 1M HV

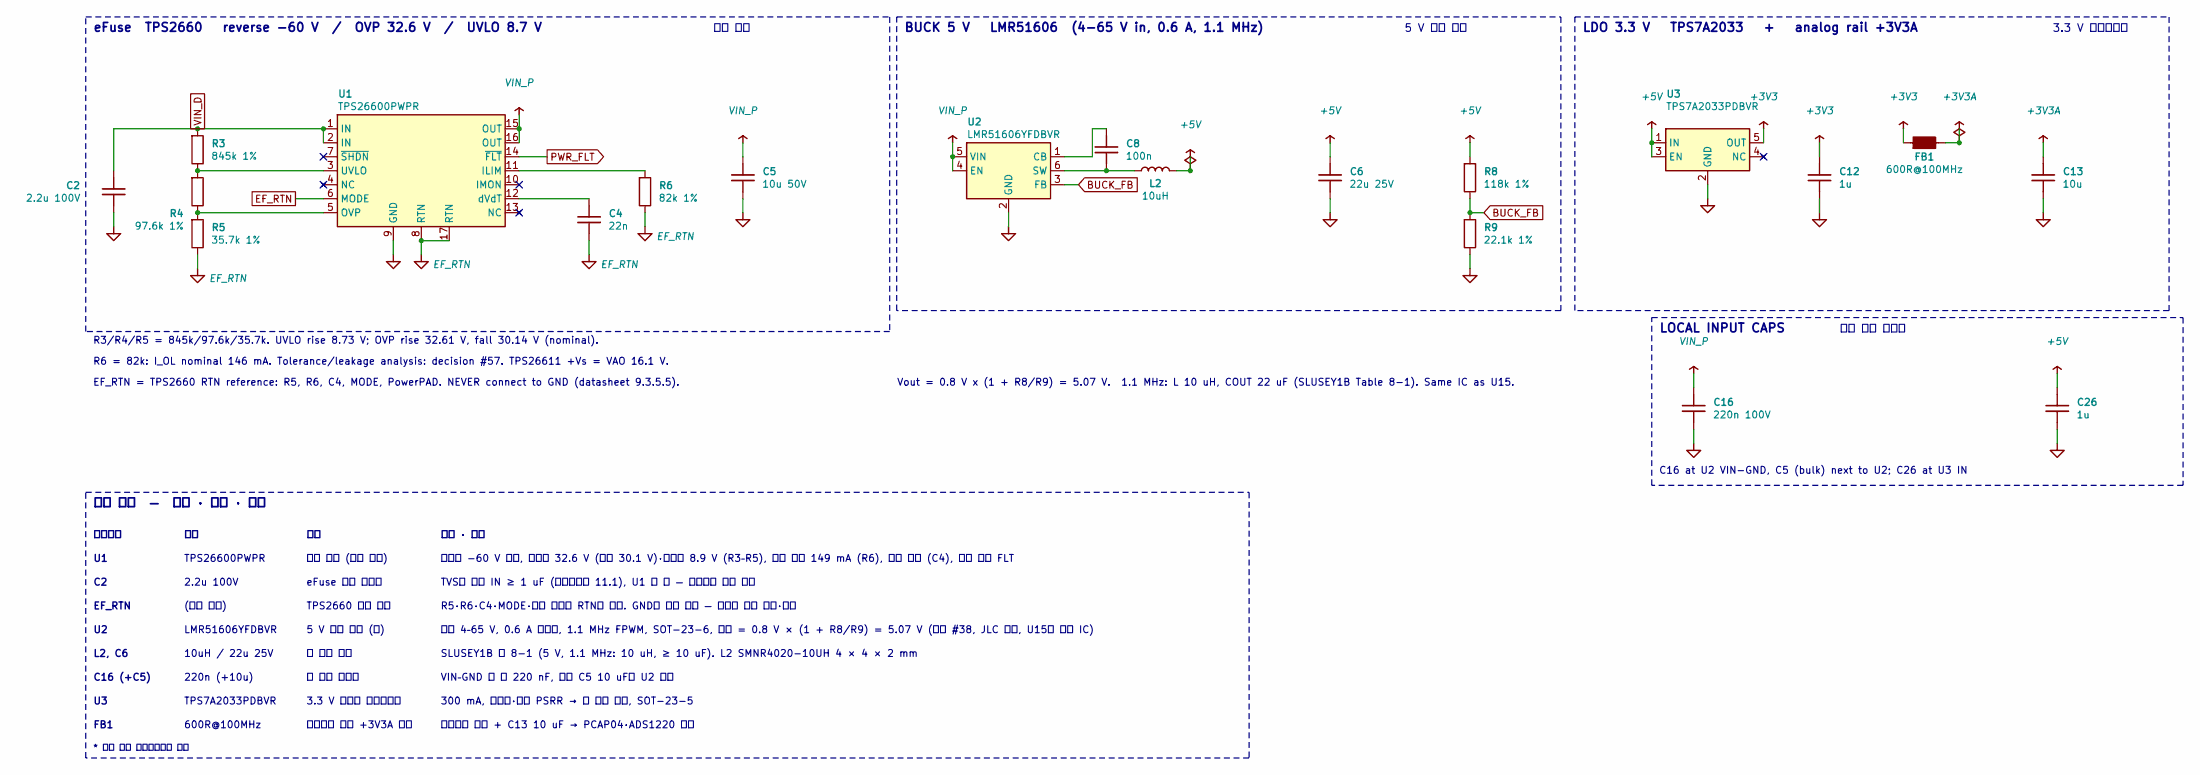
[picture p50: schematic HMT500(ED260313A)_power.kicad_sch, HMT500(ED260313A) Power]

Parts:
C2: 2.2u 100V; C_1210_3225Metric
C4: 22n; C_0402_1005Metric
C5: 10u 50V; C_1206_3216Metric
C6: 22u 25V; C_1210_3225Metric
C8: 100n; C_0402_1005Metric
C12, C26: 1u; C_0402_1005Metric
C13: 10u; C_1206_3216Metric
C16: 220n 100V; C_0805_2012Metric
FB1: 600R@100MHz; L_0603_1608Metric
L2: 10uH; L_SXN_SMNR4020
R3: 845k 1%; R_0603_1608Metric
R4: 97.6k 1%; R_0603_1608Metric
R5: 35.7k 1%; R_0603_1608Metric
R6: 82k 1%; R_0603_1608Metric
R8: 118k 1%; R_0402_1005Metric
R9: 22.1k 1%; R_0402_1005Metric
U1: TPS26600PWPR; HTSSOP-16-1EP_4.4x5mm_P0.65mm_EP3.4x5mm_Mask2.46x2.31mm_The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
U2: LMR51606YFDBVR; SOT-23-6
U3: TPS7A2033PDBVR; SOT-23-5

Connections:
+3V3: C12.1, FB1.1, U3.5 (OUT); also elsewhere on the board
+3V3A: C13.1, FB1.2; also elsewhere on the board
+5V: C6.1, C26.1, L2.2, R8.1, U3.1 (IN), U3.3 (EN)
BUCK_BOOT: C8.1, U2.1 (CB)
BUCK_FB: R8.2, R9.1, U2.3 (FB)
BUCK_SW: C8.2, L2.1, U2.6 (SW)
EF_DVDT: C4.1, U1.12 (dVdT)
EF_ILIM: R6.1, U1.11 (ILIM)
EF_RTN: C4.2, R5.2, R6.2, U1.6 (MODE), U1.8 (RTN), U1.17 (RTN)
GND: C2.2, C5.2, C6.2, C12.2, C13.2, C16.2, C26.2, R9.2, U1.9 (GND), U2.2 (GND), U3.2 (GND); also elsewhere on the board
OV_DIV: R4.2, R5.1, U1.5 (OVP)
PWR_FLT: U1.14 (~FLT); also elsewhere on the board
UV_DIV: R3.2, R4.1, U1.3 (UVLO)
VIN_D: C2.1, R3.1, U1.1 (IN), U1.2 (IN); also elsewhere on the board
VIN_P: C5.1, C16.1, U1.15 (OUT), U1.16 (OUT), U2.4 (EN), U2.5 (VIN); also elsewhere on the board

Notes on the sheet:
eFuse TPS2660 reverse -60 V / OVP 32.6 V / UVLO 8.7 V
전자 퓨즈
R3/R4/R5 = 845k/97.6k/35.7k. UVLO rise 8.73 V; OVP rise 32.61 V, fall 30.14 V (nominal).
R6 = 82k: I_OL nominal 146 mA. Tolerance/leakage analysis: decision #57. TPS26611 +Vs = VAO 16.1 V.
EF_RTN = TPS2660 RTN reference: R5, R6, C4, MODE, PowerPAD. NEVER connect to GND (datasheet 9.3.5.5).
BUCK 5 V LMR51606 (4-65 V in, 0.6 A, 1.1 MHz)
5 V 강압 전원
Vout = 0.8 V x (1 + R8/R9) = 5.07 V. 1.1 MHz: L 10 uH, COUT 22 uF (SLUSEY1B Table 8-1). Same IC as U15.
LDO 3.3 V TPS7A2033 + analog rail +3V3A
3.3 V 레귤레이터
LOCAL INPUT CAPS
국부 입력 콘덴서
C16 at U2 VIN-GND, C5 (bulk) next to U2; C26 at U3 IN
부품번호
특징 · 사양
TPS26600PWPR
전자 퓨즈 (입력 보호)
역극성 -60 V 차단, 과전압 32.6 V (복귀 30.1 V)·저전압 8.9 V (R3–R5), 전류 제한 149 mA (R6), 돌입 제한 (C4), 고장 출력 FLT
2.2u 100V
eFuse 입력 콘덴서
TVS와 함께 IN ≥ 1 uF (데이터시트 11.1), U1 핀 옆 — 핫플러그 링잉 억제
EF_RTN
(기준 접지)
TPS2660 내부 기준
R5·R6·C4·MODE·방열 패드는 RTN에 연결. GND와 연결 금지 — 역극성 보호 무효·손상
LMR51606YFDBVR
5 V 강압 전원 (벅)
입력 4–65 V, 0.6 A 동기식, 1.1 MHz FPWM, SOT-23-6, 출력 = 0.8 V × (1 + R8/R9) = 5.07 V (결정 #38, JLC 부품, U15와 같은 IC)
L2, C6
10uH / 22u 25V
벅 출력 필터
SLUSEY1B 표 8-1 (5 V, 1.1 MHz: 10 uH, ≥ 10 uF). L2 SMNR4020-10UH 4 × 4 × 2 mm
C16 (+C5)
220n (+10u)
벅 입력 콘덴서
VIN–GND 핀 옆 220 nF, 벌크 C5 10 uF를 U2 옆에
TPS7A2033PDBVR
3.3 V 저잡음 레귤레이터
300 mA, 저잡음·높은 PSRR → 벅 리플 제거, SOT-23-5
FB1

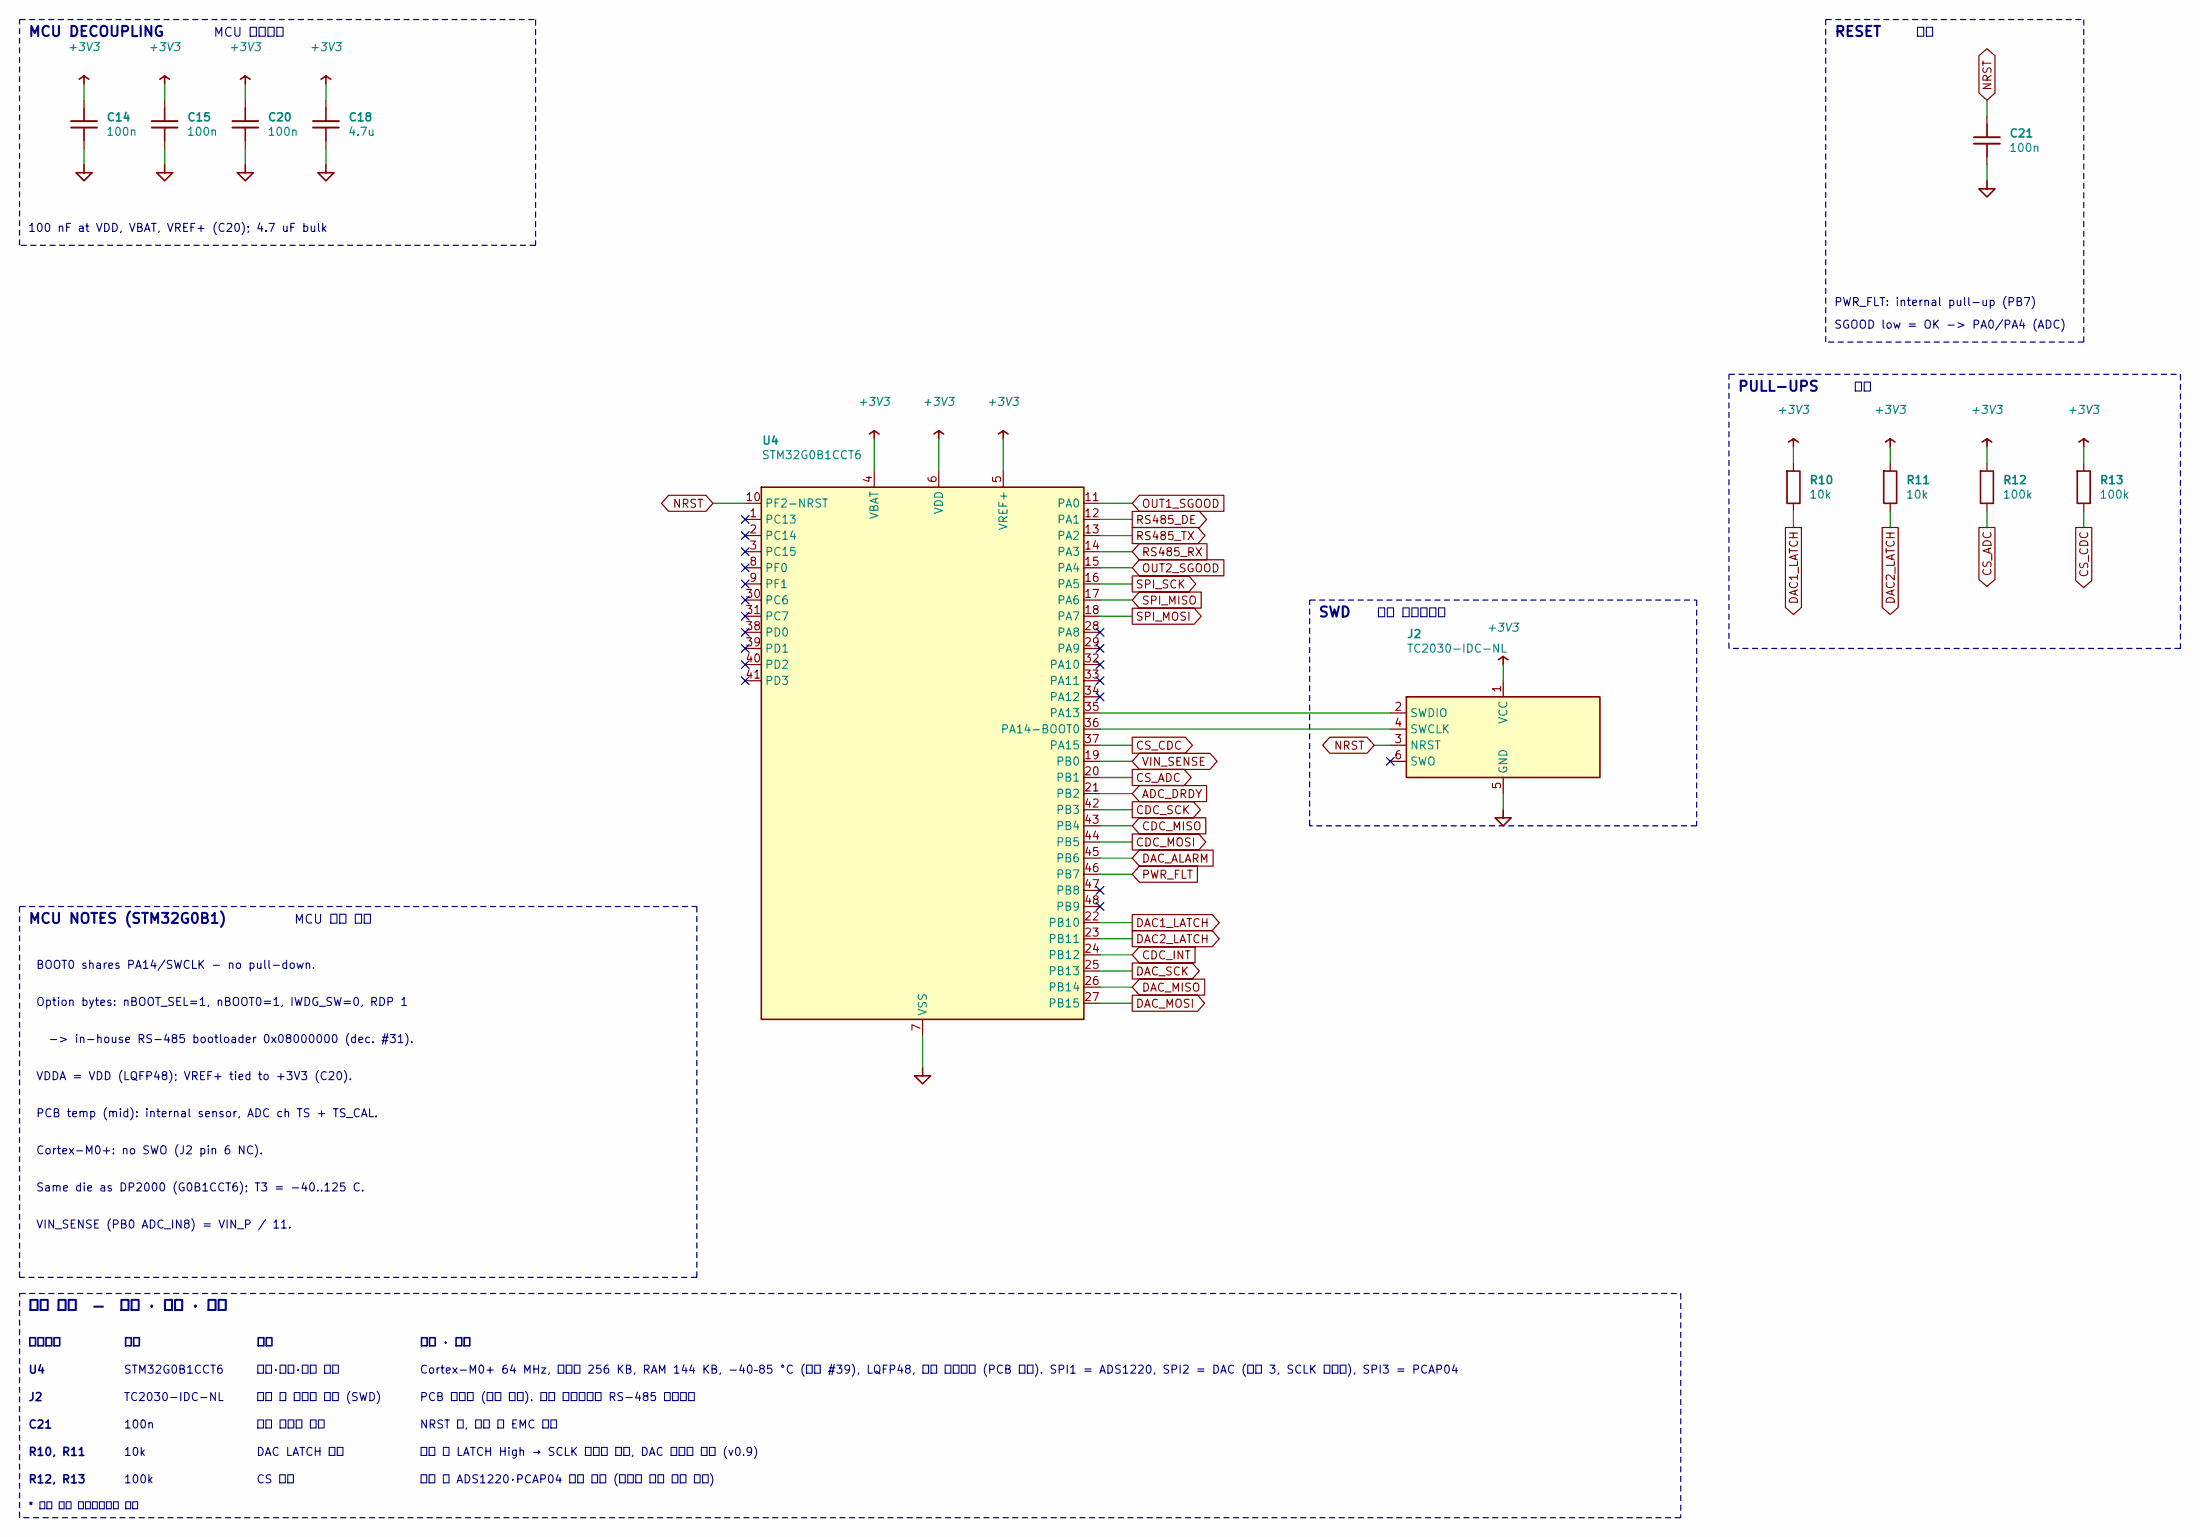
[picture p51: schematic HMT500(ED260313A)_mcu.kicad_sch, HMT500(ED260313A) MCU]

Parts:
C14, C15, C20, C21: 100n; C_0402_1005Metric
C18: 4.7u; C_0805_2012Metric
J2: TC2030-IDC-NL; Tag-Connect_TC2030-IDC-NL_2x03_P1.27mm_Vertical
R10, R11: 10k; R_0402_1005Metric
R12, R13: 100k; R_0402_1005Metric
U4: STM32G0B1CCT6; LQFP-48_7x7mm_P0.5mm

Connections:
+3V3: C14.1, C15.1, C18.1, C20.1, J2.1 (VCC), R10.1, R11.1, R12.1, R13.1, U4.4 (VBAT), U4.5 (VREF+), U4.6 (VDD); also elsewhere on the board
ADC_DRDY: U4.21 (PB2); also elsewhere on the board
CDC_INT: U4.24 (PB12); also elsewhere on the board
CDC_MISO: U4.43 (PB4); also elsewhere on the board
CDC_MOSI: U4.44 (PB5); also elsewhere on the board
CDC_SCK: U4.42 (PB3); also elsewhere on the board
CS_ADC: R12.2, U4.20 (PB1); also elsewhere on the board
CS_CDC: R13.2, U4.37 (PA15); also elsewhere on the board
DAC1_LATCH: R10.2, U4.22 (PB10); also elsewhere on the board
DAC2_LATCH: R11.2, U4.23 (PB11); also elsewhere on the board
DAC_ALARM: U4.45 (PB6); also elsewhere on the board
DAC_MISO: U4.26 (PB14); also elsewhere on the board
DAC_MOSI: U4.27 (PB15); also elsewhere on the board
DAC_SCK: U4.25 (PB13); also elsewhere on the board
GND: C14.2, C15.2, C18.2, C20.2, C21.2, J2.5 (GND), U4.7 (VSS); also elsewhere on the board
NRST: C21.1, J2.3 (NRST), U4.10 (PF2-NRST)
OUT1_SGOOD: U4.11 (PA0); also elsewhere on the board
OUT2_SGOOD: U4.15 (PA4); also elsewhere on the board
PWR_FLT: U4.46 (PB7); also elsewhere on the board
RS485_DE: U4.12 (PA1); also elsewhere on the board
RS485_RX: U4.14 (PA3); also elsewhere on the board
RS485_TX: U4.13 (PA2); also elsewhere on the board
SPI_MISO: U4.17 (PA6); also elsewhere on the board
SPI_MOSI: U4.18 (PA7); also elsewhere on the board
SPI_SCK: U4.16 (PA5); also elsewhere on the board
SWCLK: J2.4 (SWCLK), U4.36 (PA14-BOOT0)
SWDIO: J2.2 (SWDIO), U4.35 (PA13)
VIN_SENSE: U4.19 (PB0); also elsewhere on the board

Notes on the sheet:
MCU DECOUPLING
MCU 바이패스
100 nF at VDD, VBAT, VREF+ (C20); 4.7 uF bulk
RESET
PWR_FLT: internal pull-up (PB7)
SGOOD low = OK -> PA0/PA4 (ADC)
PULL-UPS
SWD
생산 프로그래밍
MCU NOTES (STM32G0B1)
MCU 설정 메모
BOOT0 shares PA14/SWCLK - no pull-down.
Option bytes: nBOOT_SEL=1, nBOOT0=1, IWDG_SW=0, RDP 1
-> in-house RS-485 bootloader 0x08000000 (dec. #31).
VDDA = VDD (LQFP48); VREF+ tied to +3V3 (C20).
PCB temp (mid): internal sensor, ADC ch TS + TS_CAL.
Cortex-M0+: no SWO (J2 pin 6 NC).
Same die as DP2000 (G0B1CCT6); T3 = -40..125 C.
VIN_SENSE (PB0 ADC_IN8) = VIN_P / 11.
부품번호
특징 · 사양
STM32G0B1CCT6
제어·통신·보정 연산
Cortex-M0+ 64 MHz, 플래시 256 KB, RAM 144 KB, -40–85 °C (샘플 #39), LQFP48, 내부 온도센서 (PCB 온도). SPI1 = ADS1220, SPI2 = DAC (모드 3, SCLK 게이트), SPI3 = PCAP04
TC2030-IDC-NL
생산 때 펌웨어 기록 (SWD)
PCB 패드만 (부품 없음). 이후 업데이트는 RS-485 부트로더
C21
100n
리셋 노이즈 필터
NRST 핀, 몰딩 후 EMC 여유
R10, R11
10k
DAC LATCH 풀업
리셋 중 LATCH High → SCLK 게이트 닫힘, DAC 오입력 방지 (v0.9)
R12, R13
100k
CS 풀업
리셋 중 ADS1220·PCAP04 선택 해제 (디지털 입력 부동 금지)
주요 부품 — 역할 · 특징 · 사양

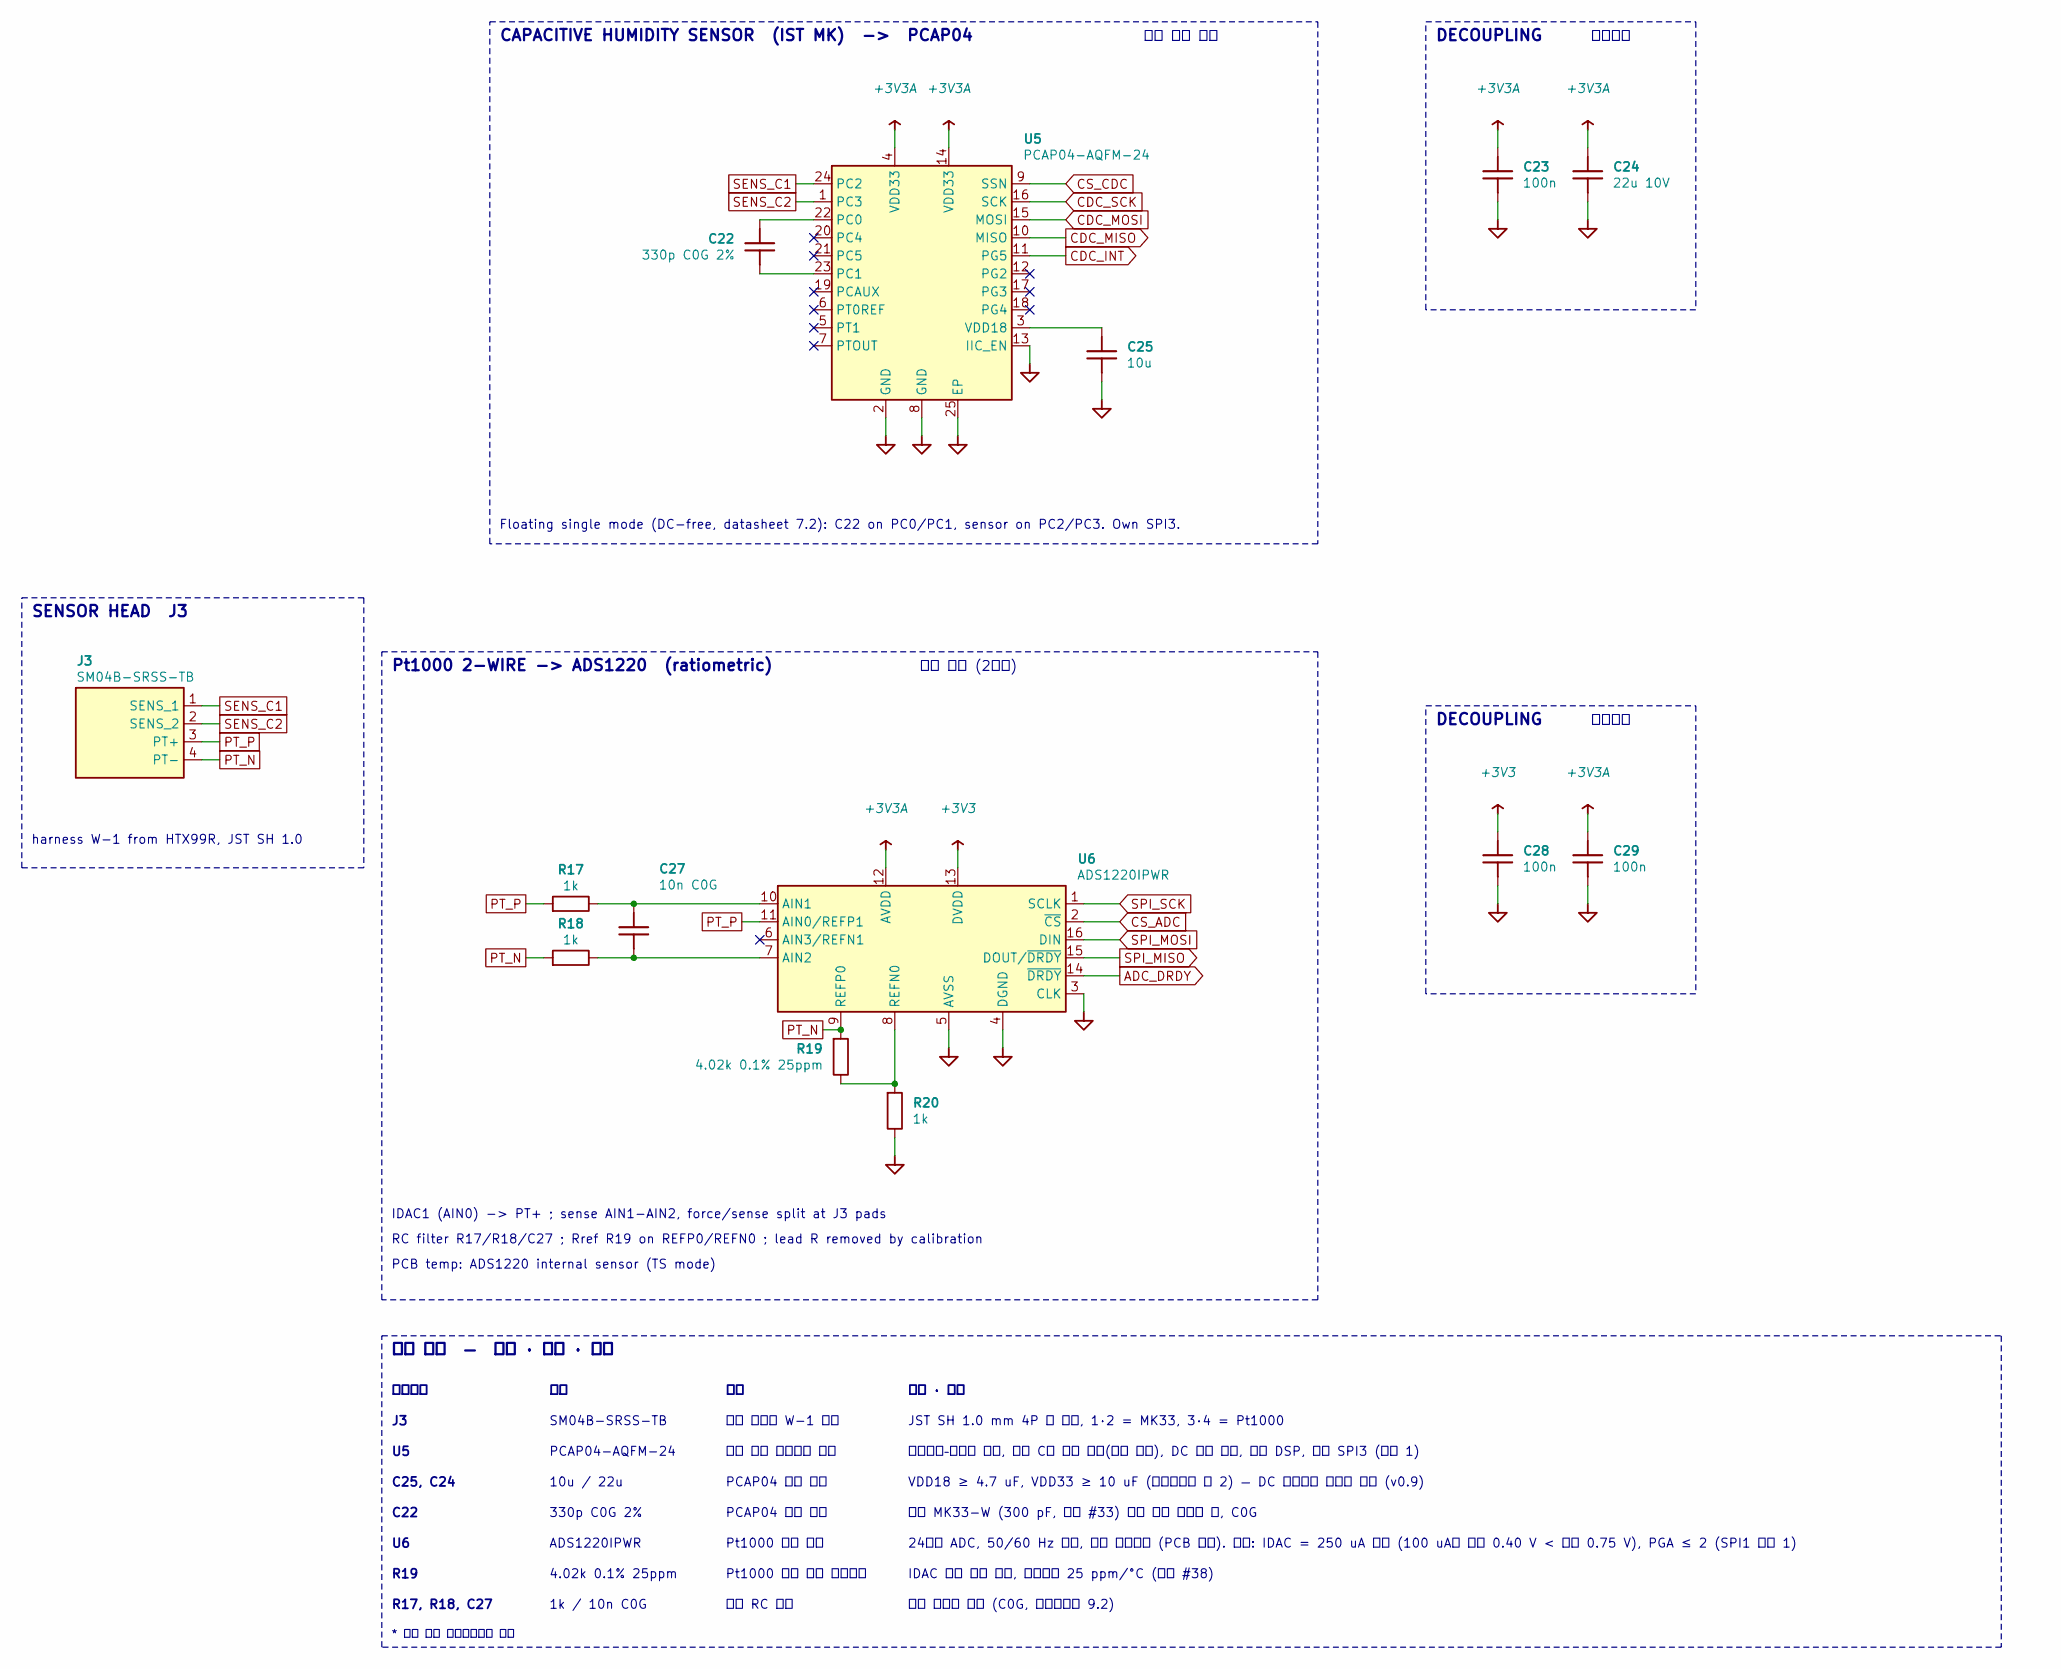
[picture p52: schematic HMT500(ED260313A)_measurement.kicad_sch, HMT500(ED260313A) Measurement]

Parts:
C22: 330p C0G 2%; C_0603_1608Metric
C23, C28, C29: 100n; C_0402_1005Metric
C24: 22u 10V; C_1206_3216Metric
C25: 10u; C_1206_3216Metric
C27: 10n C0G; C_0603_1608Metric
J3: SM04B-SRSS-TB; JST_SH_SM04B-SRSS-TB_1x04-1MP_P1.00mm_Horizontal
R17, R18, R20: 1k; R_0402_1005Metric
R19: 4.02k 0.1% 25ppm; R_0603_1608Metric
U5: PCAP04-AQFM-24; QFN-24-1EP_4x4mm_P0.5mm_EP2.6x2.6mm
U6: ADS1220IPWR; TSSOP-16_4.4x5mm_P0.65mm

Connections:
+3V3: C28.1, U6.13 (DVDD); also elsewhere on the board
+3V3A: C23.1, C24.1, C29.1, U5.4 (VDD33), U5.14 (VDD33), U6.12 (AVDD); also elsewhere on the board
ADC_DRDY: U6.14 (~DRDY); also elsewhere on the board
CDC_INT: U5.11 (PG5); also elsewhere on the board
CDC_MISO: U5.10 (MISO); also elsewhere on the board
CDC_MOSI: U5.15 (MOSI); also elsewhere on the board
CDC_SCK: U5.16 (SCK); also elsewhere on the board
CDC_V18: C25.1, U5.3 (VDD18)
CREF_A: C22.1, U5.22 (PC0)
CREF_B: C22.2, U5.23 (PC1)
CS_ADC: U6.2 (~CS); also elsewhere on the board
CS_CDC: U5.9 (SSN); also elsewhere on the board
GND: C23.2, C24.2, C25.2, C28.2, C29.2, R20.2, U5.2 (GND), U5.8 (GND), U5.13 (IIC_EN), U5.25 (EP), U6.3 (CLK), U6.4 (DGND), U6.5 (AVSS); also elsewhere on the board
PT_N: J3.4 (PT-), R18.1, R19.1, U6.9 (REFP0)
PT_P: J3.3 (PT+), R17.1, U6.11 (AIN0/REFP1)
PT_SN_F: C27.2, R18.2, U6.7 (AIN2)
PT_SP_F: C27.1, R17.2, U6.10 (AIN1)
REF_N: R19.2, R20.1, U6.8 (REFN0)
SENS_C1: J3.1 (SENS_1), U5.24 (PC2)
SENS_C2: J3.2 (SENS_2), U5.1 (PC3)
SPI_MISO: U6.15 (DOUT/~DRDY); also elsewhere on the board
SPI_MOSI: U6.16 (DIN); also elsewhere on the board
SPI_SCK: U6.1 (SCLK); also elsewhere on the board

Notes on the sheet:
SENSOR HEAD J3
harness W-1 from HTX99R, JST SH 1.0
CAPACITIVE HUMIDITY SENSOR (IST MK) -> PCAP04
습도 센서 측정
Floating single mode (DC-free, datasheet 7.2): C22 on PC0/PC1, sensor on PC2/PC3. Own SPI3.
Pt1000 2-WIRE -> ADS1220 (ratiometric)
온도 측정 (2선식)
IDAC1 (AIN0) -> PT+ ; sense AIN1-AIN2, force/sense split at J3 pads
RC filter R17/R18/C27 ; Rref R19 on REFP0/REFN0 ; lead R removed by calibration
PCB temp: ADS1220 internal sensor (TS mode)
DECOUPLING
바이패스
부품번호
특징 · 사양
SM04B-SRSS-TB
센서 하네스 W-1 연결
JST SH 1.0 mm 4P 옆 삽입, 1·2 = MK33, 3·4 = Pt1000
PCAP04-AQFM-24
습도 센서 정전용량 측정
정전용량–디지털 변환, 기준 C와 비율 측정(방전 시간), DC 없는 구동, 내부 DSP, 전용 SPI3 (모드 1)
C25, C24
10u / 22u
PCAP04 전원 버퍼
VDD18 ≥ 4.7 uF, VDD33 ≥ 10 uF (데이터시트 표 2) — DC 바이어스 후에도 충족 (v0.9)
C22
330p C0G 2%
PCAP04 기준 용량
센서 MK33-W (300 pF, 결정 #33) 측정 범위 가운데 값, C0G
ADS1220IPWR
Pt1000 온도 측정
24비트 ADC, 50/60 Hz 제거, 내부 온도센서 (PCB 온도). 설정: IDAC = 250 uA 고정 (100 uA면 기준 0.40 V < 권장 0.75 V), PGA ≤ 2 (SPI1 모드 1)
R19
4.02k 0.1% 25ppm
Pt1000 비율 측정 기준저항
IDAC 전류 오차 상쇄, 온도계수 25 ppm/°C (결정 #38)
R17, R18, C27
1k / 10n C0G
입력 RC 필터
차동 노이즈 제거 (C0G, 데이터시트 9.2)
주요 부품 — 역할 · 특징 · 사양

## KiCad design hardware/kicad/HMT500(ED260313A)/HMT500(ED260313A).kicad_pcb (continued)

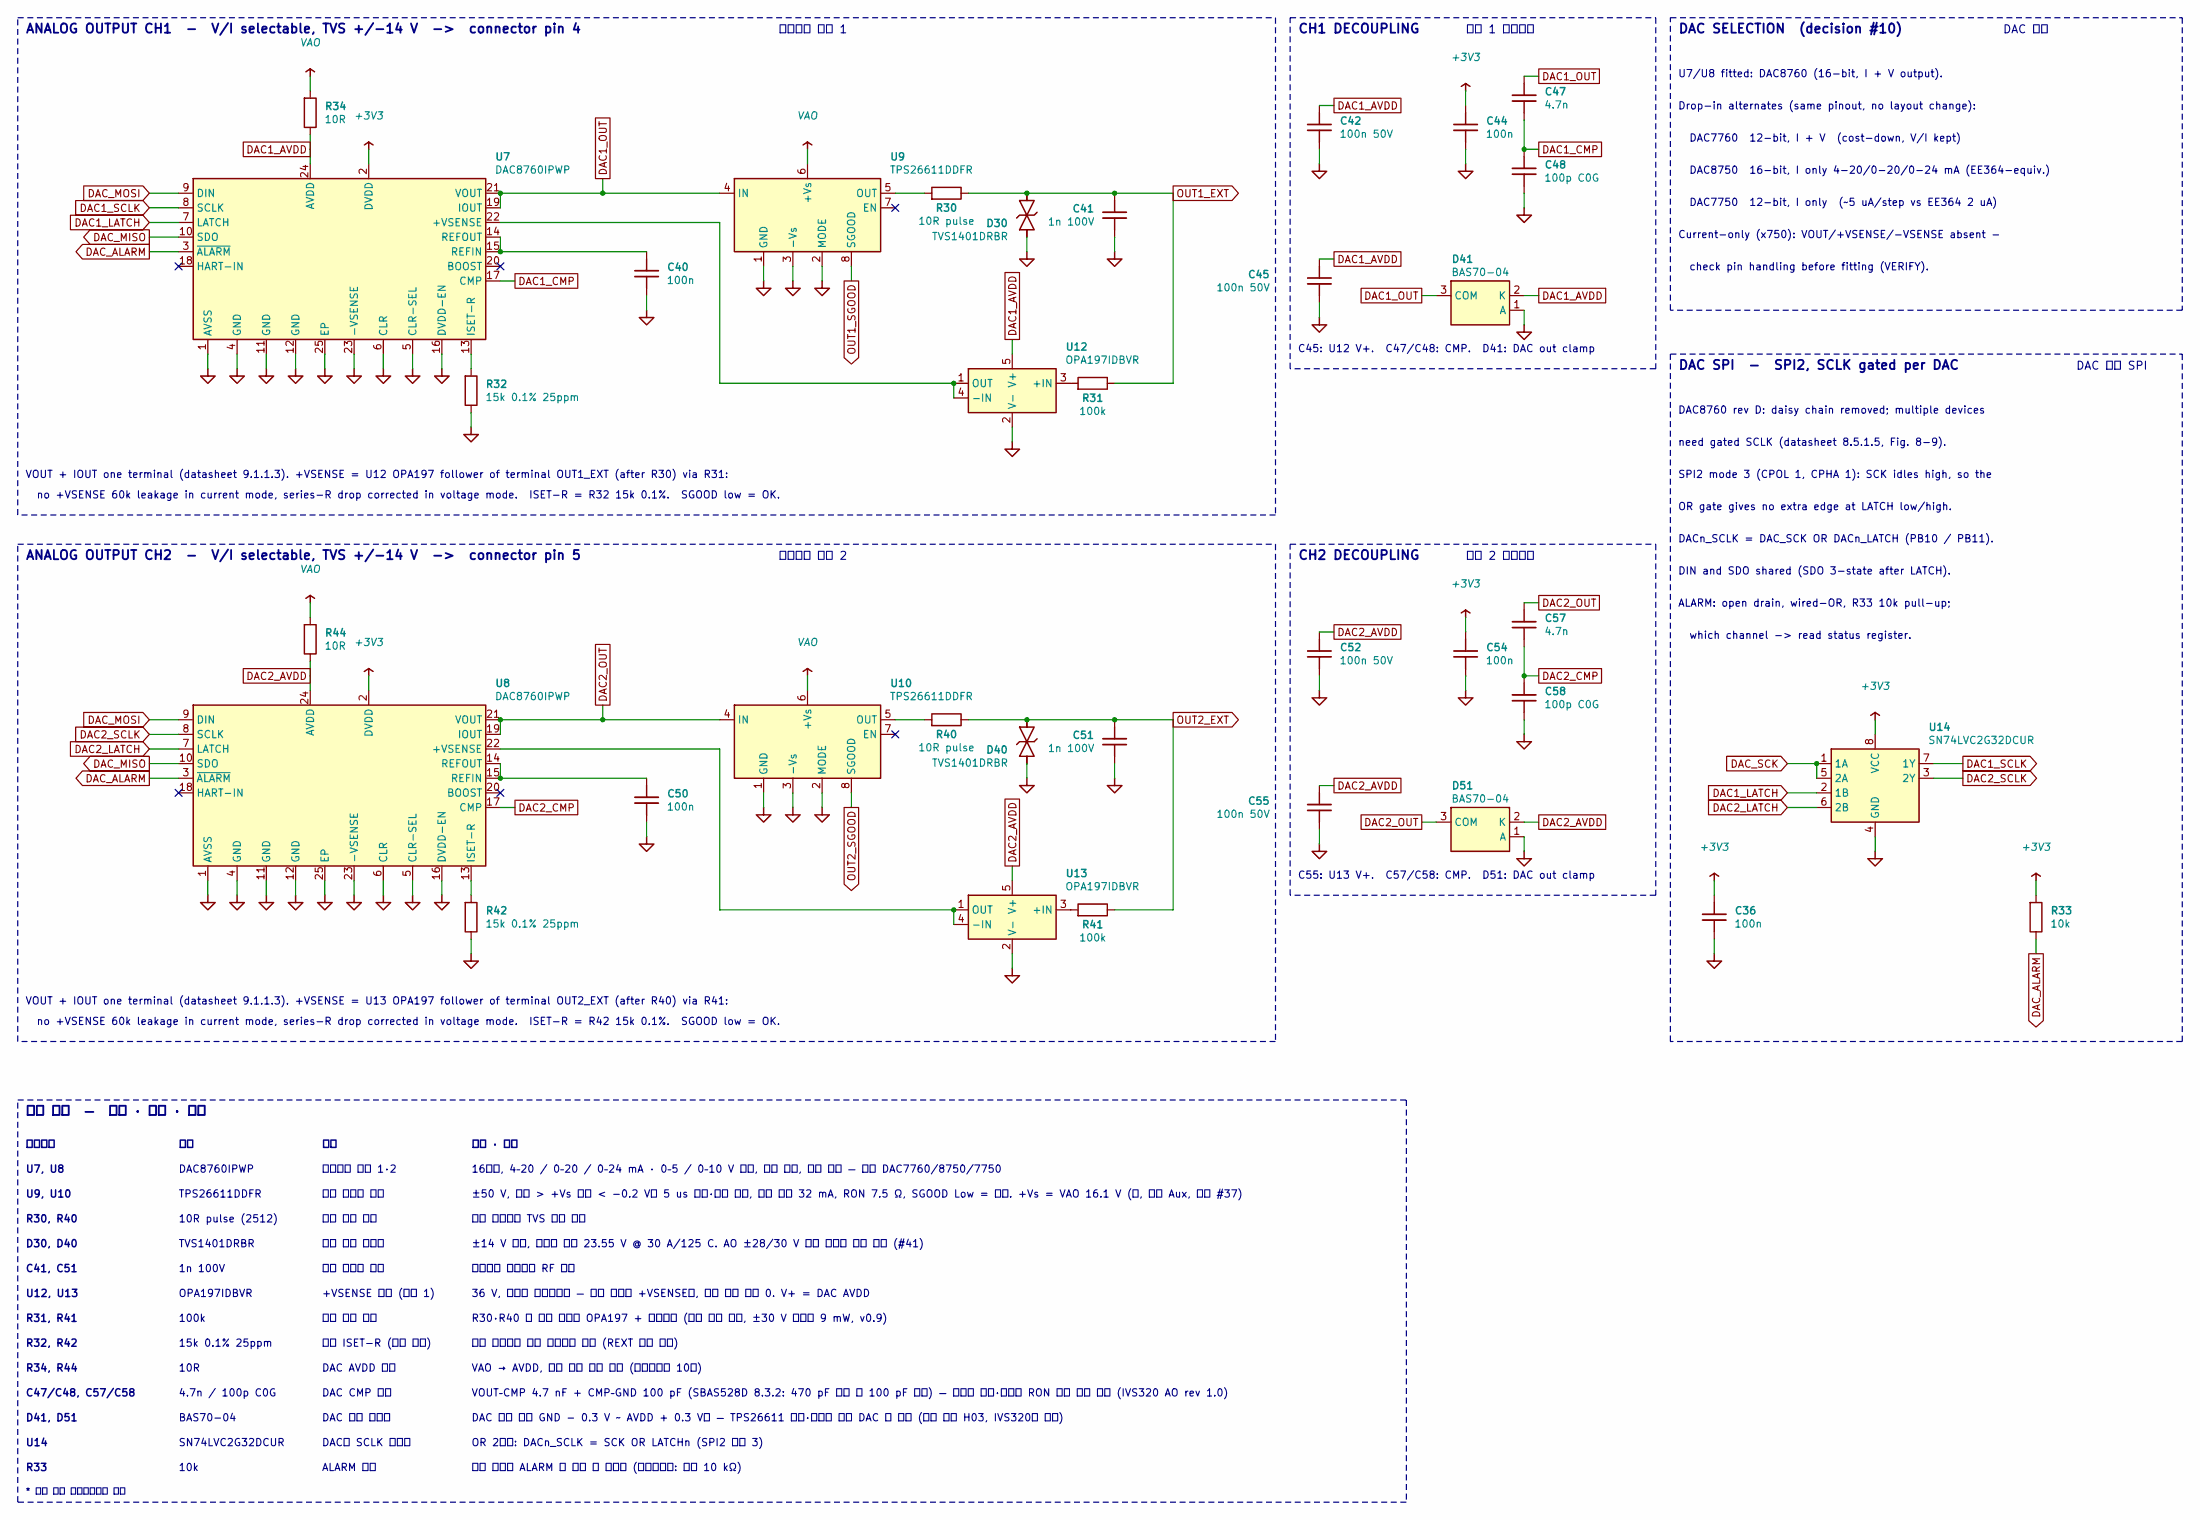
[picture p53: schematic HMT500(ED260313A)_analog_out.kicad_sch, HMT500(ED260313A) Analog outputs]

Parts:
C36, C40, C44, C50, C54: 100n; C_0402_1005Metric
C41, C51: 1n 100V; C_0603_1608Metric
C42, C45, C52, C55: 100n 50V; C_0805_2012Metric
C47, C57: 4.7n; C_0402_1005Metric
C48, C58: 100p C0G; C_0402_1005Metric
D30, D40: TVS1401DRBR; Texas_DRB0008A_PadFloat
D41, D51: BAS70-04; SOT-23
R30, R40: 10R pulse; R_2512_6332Metric
R31, R41: 100k; R_0402_1005Metric
R32, R42: 15k 0.1% 25ppm; R_0603_1608Metric
R33: 10k; R_0402_1005Metric
R34, R44: 10R; R_0402_1005Metric
U7, U8: DAC8760IPWP; HTSSOP-24-1EP_4.4x7.8mm_P0.65mm_EP3.2x5mm
U9, U10: TPS26611DDFR; SOT-23-8
U12, U13: OPA197IDBVR; SOT-23-5
U14: SN74LVC2G32DCUR; VSSOP-8_2.3x2mm_P0.5mm

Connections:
+3V3: C36.1, C44.1, C54.1, R33.1, U7.2 (DVDD), U8.2 (DVDD), U14.8 (VCC); also elsewhere on the board
DAC1_AVDD: C42.1, C45.1, D41.2 (K), R34.2, U7.24 (AVDD), U12.5 (V+)
DAC1_CMP: C47.2, C48.1, U7.17 (CMP)
DAC1_ISET: R32.1, U7.13 (ISET-R)
DAC1_LATCH: U7.7 (LATCH), U14.2 (1B); also elsewhere on the board
DAC1_OUT: C47.1, D41.3 (COM), U7.19 (IOUT), U7.21 (VOUT), U9.4 (IN)
DAC1_REF: C40.1, U7.14 (REFOUT), U7.15 (REFIN)
DAC1_SCLK: U7.8 (SCLK), U14.7 (1Y)
DAC1_SENSE: U7.22 (+VSENSE), U12.1 (OUT), U12.4 (-IN)
DAC2_AVDD: C52.1, C55.1, D51.2 (K), R44.2, U8.24 (AVDD), U13.5 (V+)
DAC2_CMP: C57.2, C58.1, U8.17 (CMP)
DAC2_ISET: R42.1, U8.13 (ISET-R)
DAC2_LATCH: U8.7 (LATCH), U14.6 (2B); also elsewhere on the board
DAC2_OUT: C57.1, D51.3 (COM), U8.19 (IOUT), U8.21 (VOUT), U10.4 (IN)
DAC2_REF: C50.1, U8.14 (REFOUT), U8.15 (REFIN)
DAC2_SCLK: U8.8 (SCLK), U14.3 (2Y)
DAC2_SENSE: U8.22 (+VSENSE), U13.1 (OUT), U13.4 (-IN)
DAC_ALARM: R33.2, U7.3 (~ALARM), U8.3 (~ALARM); also elsewhere on the board
DAC_MISO: U7.10 (SDO), U8.10 (SDO); also elsewhere on the board
DAC_MOSI: U7.9 (DIN), U8.9 (DIN); also elsewhere on the board
DAC_SCK: U14.1 (1A), U14.5 (2A); also elsewhere on the board
GND: C36.2, C40.2, C41.2, C42.2, C44.2, C45.2, C48.2, C50.2, C51.2, C52.2, C54.2, C55.2, C58.2, D30.5, D30.6, D30.7, D30.8, D40.5, D40.6, D40.7, D40.8, D41.1 (A), D51.1 (A), R32.2, R42.2, U7.1 (AVSS), U7.4 (GND), U7.5 (CLR-SEL), U7.6 (CLR), U7.11 (GND), U7.12 (GND), U7.16 (DVDD-EN), U7.23 (-VSENSE), U7.25 (EP), U8.1 (AVSS), U8.4 (GND), U8.5 (CLR-SEL), U8.6 (CLR), U8.11 (GND), U8.12 (GND), U8.16 (DVDD-EN), U8.23 (-VSENSE), U8.25 (EP), U9.1 (GND), U9.2 (MODE), U9.3 (-Vs), U10.1 (GND), U10.2 (MODE), U10.3 (-Vs), U12.2 (V-), U13.2 (V-), U14.4 (GND); also elsewhere on the board
OUT1_EXT: C41.1, D30.1, D30.2, D30.3, D30.4, R30.2, R31.2; also elsewhere on the board
OUT1_P: R30.1, U9.5 (OUT)
OUT1_SGOOD: U9.8 (SGOOD); also elsewhere on the board
OUT1_SNS: R31.1, U12.3 (+IN)
OUT2_EXT: C51.1, D40.1, D40.2, D40.3, D40.4, R40.2, R41.2; also elsewhere on the board
OUT2_P: R40.1, U10.5 (OUT)
OUT2_SGOOD: U10.8 (SGOOD); also elsewhere on the board
OUT2_SNS: R41.1, U13.3 (+IN)
VAO: R34.1, R44.1, U9.6 (+Vs), U10.6 (+Vs); also elsewhere on the board

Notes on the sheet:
ANALOG OUTPUT CH1 - V/I selectable, TVS +/-14 V -> connector pin 4
아날로그 출력 1
VOUT + IOUT one terminal (datasheet 9.1.1.3). +VSENSE = U12 OPA197 follower of terminal OUT1_EXT (after R30) via R31:
no +VSENSE 60k leakage in current mode, series-R drop corrected in voltage mode. ISET-R = R32 15k 0.1%. SGOOD low = OK.
CH1 DECOUPLING
채널 1 바이패스
C45: U12 V+. C47/C48: CMP. D41: DAC out clamp
ANALOG OUTPUT CH2 - V/I selectable, TVS +/-14 V -> connector pin 5
아날로그 출력 2
VOUT + IOUT one terminal (datasheet 9.1.1.3). +VSENSE = U13 OPA197 follower of terminal OUT2_EXT (after R40) via R41:
no +VSENSE 60k leakage in current mode, series-R drop corrected in voltage mode. ISET-R = R42 15k 0.1%. SGOOD low = OK.
CH2 DECOUPLING
채널 2 바이패스
C55: U13 V+. C57/C58: CMP. D51: DAC out clamp
DAC SELECTION (decision #10)
DAC 선정
U7/U8 fitted: DAC8760 (16-bit, I + V output).
Drop-in alternates (same pinout, no layout change):
DAC7760 12-bit, I + V (cost-down, V/I kept)
DAC8750 16-bit, I only 4-20/0-20/0-24 mA (EE364-equiv.)
DAC7750 12-bit, I only (~5 uA/step vs EE364 2 uA)
Current-only (x750): VOUT/+VSENSE/-VSENSE absent -
check pin handling before fitting (VERIFY).
DAC SPI - SPI2, SCLK gated per DAC
DAC 전용 SPI
DAC8760 rev D: daisy chain removed; multiple devices
need gated SCLK (datasheet 8.5.1.5, Fig. 8-9).
SPI2 mode 3 (CPOL 1, CPHA 1): SCK idles high, so the
OR gate gives no extra edge at LATCH low/high.
DACn_SCLK = DAC_SCK OR DACn_LATCH (PB10 / PB11).
DIN and SDO shared (SDO 3-state after LATCH).
ALARM: open drain, wired-OR, R33 10k pull-up;
which channel -> read status register.
부품번호
특징 · 사양
U7, U8
DAC8760IPWP
아날로그 출력 1·2
16비트, 4–20 / 0–20 / 0–24 mA · 0–5 / 0–10 V 선택, 내부 기준, 고장 알람 — 대체 DAC7760/8750/7750
U9, U10

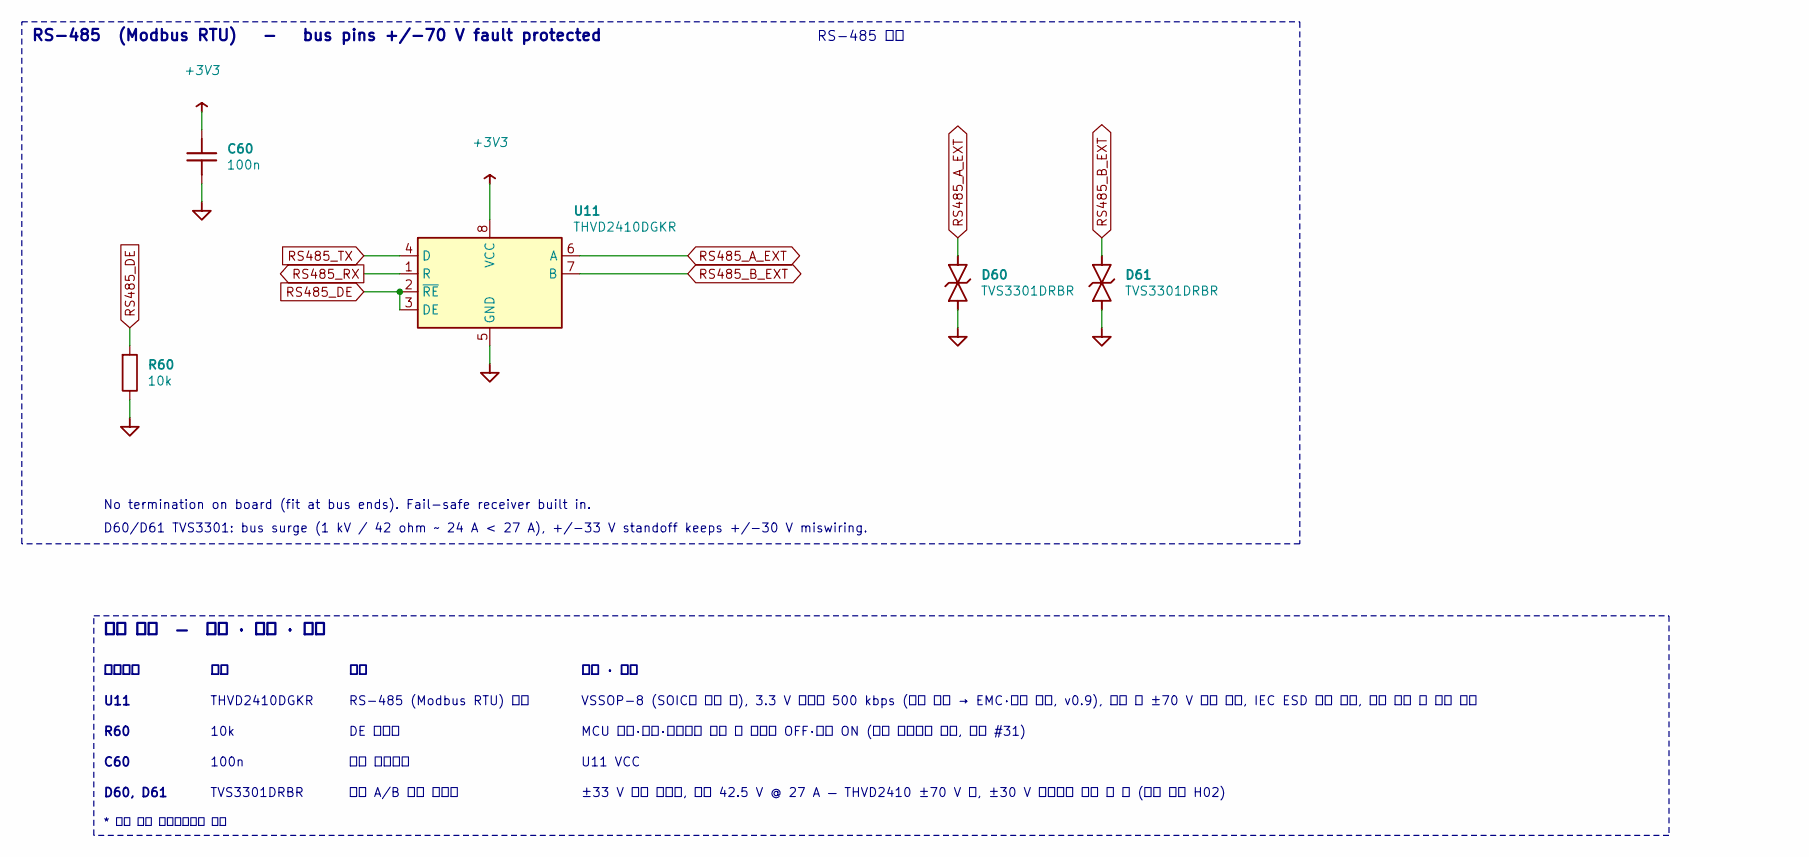
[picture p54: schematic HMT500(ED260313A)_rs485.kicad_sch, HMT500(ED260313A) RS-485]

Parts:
C60: 100n; C_0402_1005Metric
D60, D61: TVS3301DRBR; Texas_DRB0008A_PadFloat
R60: 10k; R_0402_1005Metric
U11: THVD2410DGKR; VSSOP-8_3.0x3.0mm_P0.65mm

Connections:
+3V3: C60.1, U11.8 (VCC); also elsewhere on the board
GND: C60.2, D60.5, D60.6, D60.7, D60.8, D61.5, D61.6, D61.7, D61.8, R60.2, U11.5 (GND); also elsewhere on the board
RS485_A_EXT: D60.1, D60.2, D60.3, D60.4, U11.6 (A); also elsewhere on the board
RS485_B_EXT: D61.1, D61.2, D61.3, D61.4, U11.7 (B); also elsewhere on the board
RS485_DE: R60.1, U11.2 (~RE), U11.3 (DE); also elsewhere on the board
RS485_RX: U11.1 (R); also elsewhere on the board
RS485_TX: U11.4 (D); also elsewhere on the board

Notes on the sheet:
RS-485 (Modbus RTU) - bus pins +/-70 V fault protected
RS-485 통신
No termination on board (fit at bus ends). Fail-safe receiver built in.
D60/D61 TVS3301: bus surge (1 kV / 42 ohm ~ 24 A < 27 A), +/-33 V standoff keeps +/-30 V miswiring.
부품번호
특징 · 사양
U11
THVD2410DGKR
RS-485 (Modbus RTU) 통신
VSSOP-8 (SOIC와 같은 핀), 3.3 V 반이중 500 kbps (느린 에지 → EMC·반사 유리, v0.9), 버스 핀 ±70 V 고장 보호, IEC ESD 보호 내장, 버스 개방 시 안전 수신
R60
10k
DE 풀다운
MCU 리셋·부팅·부트로더 점프 중 송신기 OFF·수신 ON (자체 부트로더 필수, 결정 #31)
C60
100n
전원 바이패스
U11 VCC
D60, D61
TVS3301DRBR
버스 A/B 서지 클램프
±33 V 평탄 클램프, 최대 42.5 V @ 27 A — THVD2410 ±70 V 안, ±30 V 오결선에 도통 안 함 (외부 검수 H02)
주요 부품 — 역할 · 특징 · 사양
* 표시 값은 데이터시트로 확인

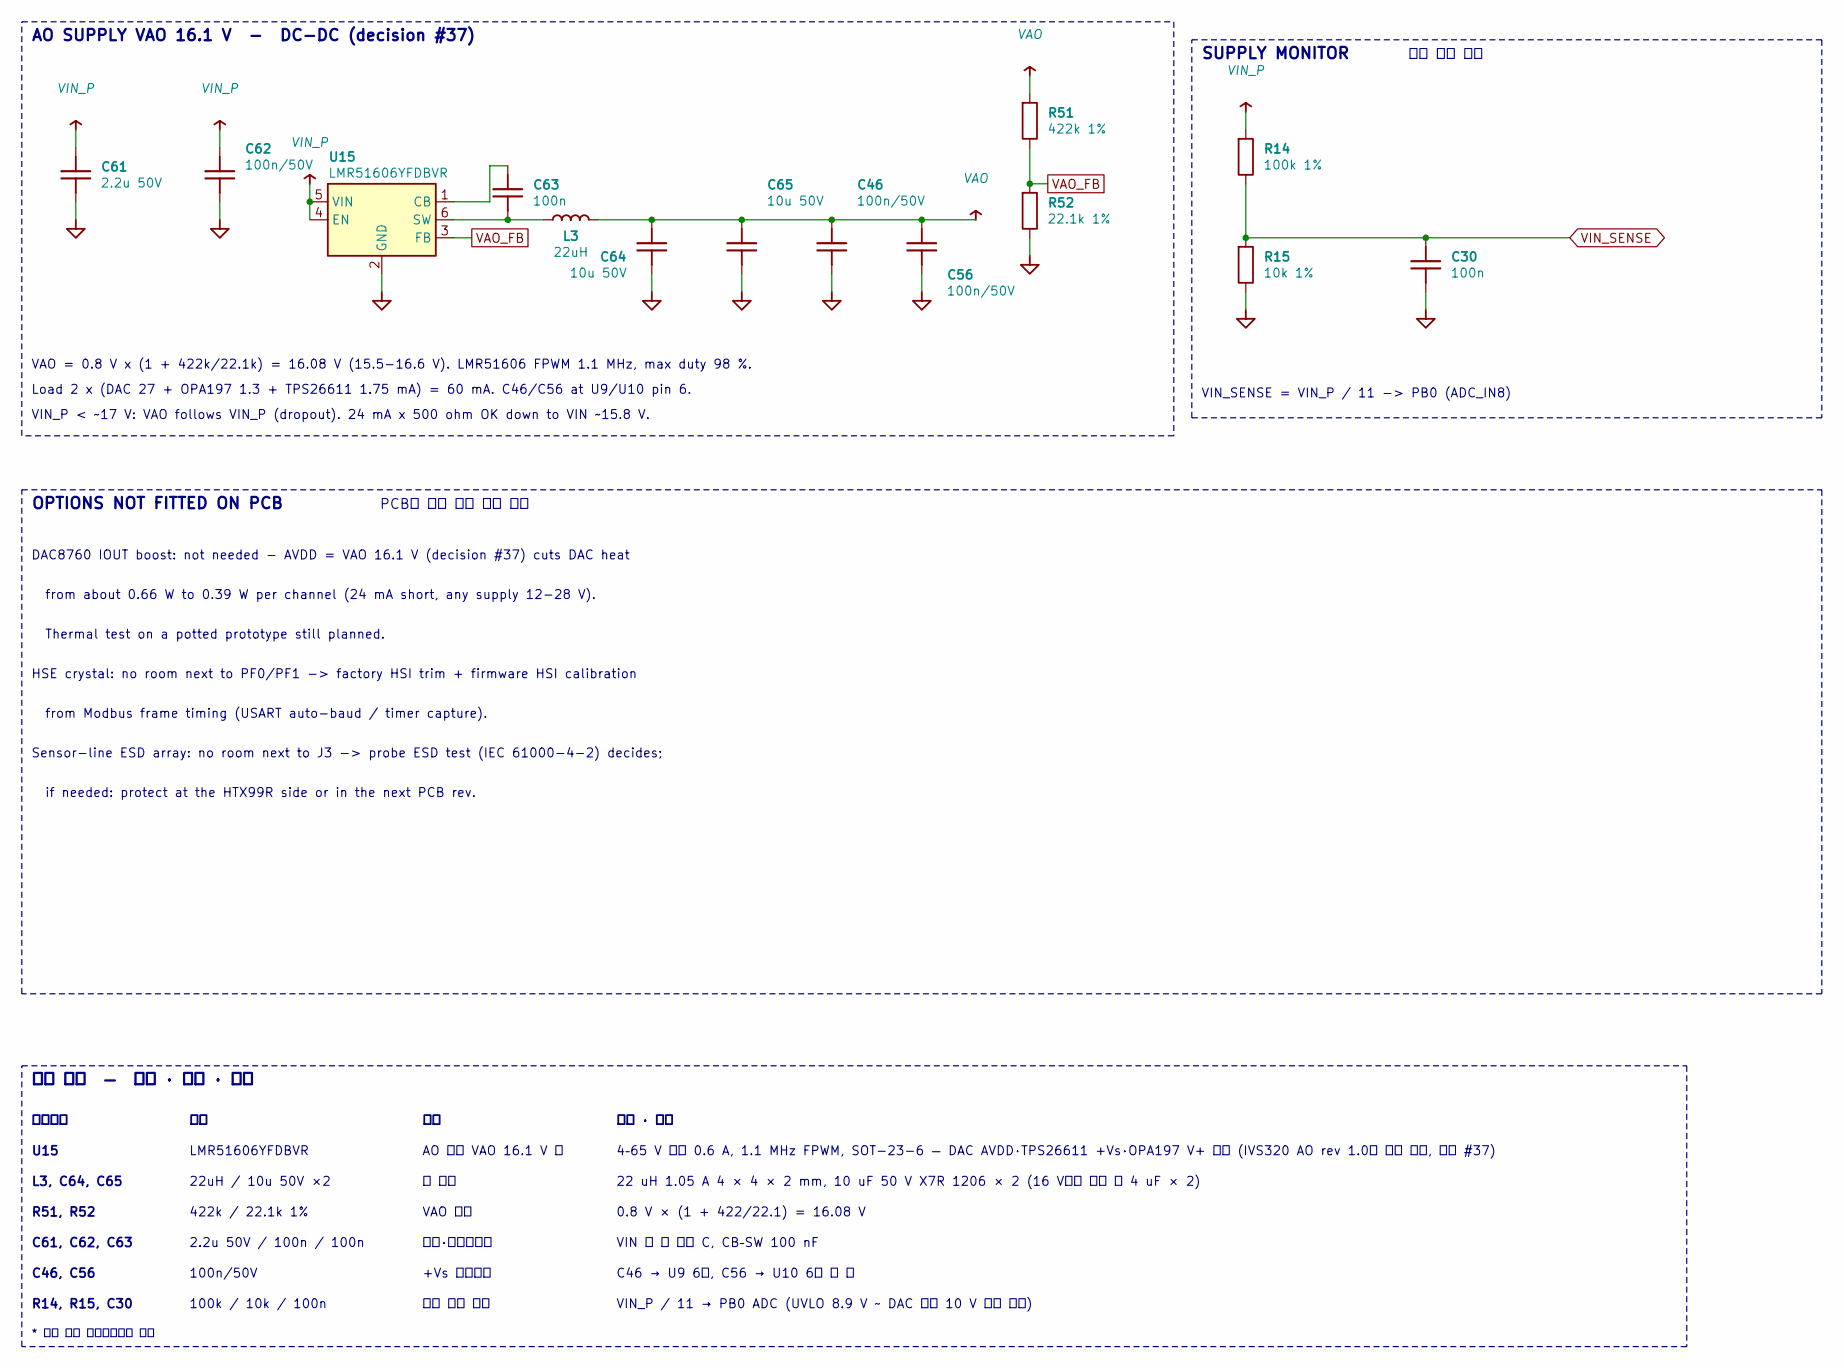
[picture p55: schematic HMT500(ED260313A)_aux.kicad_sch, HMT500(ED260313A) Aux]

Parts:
C30, C63: 100n; C_0402_1005Metric
C46, C56, C62: 100n/50V; C_0603_1608Metric
C61: 2.2u 50V; C_0805_2012Metric
C64, C65: 10u 50V; C_1206_3216Metric
L3: 22uH; L_SXN_SMNR4020
R14: 100k 1%; R_0402_1005Metric
R15: 10k 1%; R_0402_1005Metric
R51: 422k 1%; R_0402_1005Metric
R52: 22.1k 1%; R_0402_1005Metric
U15: LMR51606YFDBVR; SOT-23-6

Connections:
GND: C30.2, C46.2, C56.2, C61.2, C62.2, C64.2, C65.2, R15.2, R52.2, U15.2 (GND); also elsewhere on the board
VAO: C46.1, C56.1, C64.1, C65.1, L3.2, R51.1; also elsewhere on the board
VAO_CB: C63.1, U15.1 (CB)
VAO_FB: R51.2, R52.1, U15.3 (FB)
VAO_SW: C63.2, L3.1, U15.6 (SW)
VIN_P: C61.1, C62.1, R14.1, U15.4 (EN), U15.5 (VIN); also elsewhere on the board
VIN_SENSE: C30.1, R14.2, R15.1; also elsewhere on the board

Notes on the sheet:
AO SUPPLY VAO 16.1 V - DC-DC (decision #37)
VAO = 0.8 V x (1 + 422k/22.1k) = 16.08 V (15.5-16.6 V). LMR51606 FPWM 1.1 MHz, max duty 98 %.
Load 2 x (DAC 27 + OPA197 1.3 + TPS26611 1.75 mA) = 60 mA. C46/C56 at U9/U10 pin 6.
VIN_P < ~17 V: VAO follows VIN_P (dropout). 24 mA x 500 ohm OK down to VIN ~15.8 V.
SUPPLY MONITOR
전원 전압 감시
VIN_SENSE = VIN_P / 11 -> PB0 (ADC_IN8)
OPTIONS NOT FITTED ON PCB
PCB에 넣지 않은 선택 사항
DAC8760 IOUT boost: not needed - AVDD = VAO 16.1 V (decision #37) cuts DAC heat
from about 0.66 W to 0.39 W per channel (24 mA short, any supply 12-28 V).
Thermal test on a potted prototype still planned.
HSE crystal: no room next to PF0/PF1 -> factory HSI trim + firmware HSI calibration
from Modbus frame timing (USART auto-baud / timer capture).
Sensor-line ESD array: no room next to J3 -> probe ESD test (IEC 61000-4-2) decides;
if needed: protect at the HTX99R side or in the next PCB rev.
부품번호
특징 · 사양
U15
LMR51606YFDBVR
AO 전원 VAO 16.1 V 벅
4–65 V 입력 0.6 A, 1.1 MHz FPWM, SOT-23-6 — DAC AVDD·TPS26611 +Vs·OPA197 V+ 공용 (IVS320 AO rev 1.0과 같은 회로, 결정 #37)
L3, C64, C65
22uH / 10u 50V ×2
벅 출력
22 uH 1.05 A 4 × 4 × 2 mm, 10 uF 50 V X7R 1206 × 2 (16 V에서 실효 약 4 uF × 2)
R51, R52
422k / 22.1k 1%
VAO 설정
0.8 V × (1 + 422/22.1) = 16.08 V
C61, C62, C63
2.2u 50V / 100n / 100n
입력·부트스트랩
VIN 핀 옆 입력 C, CB–SW 100 nF
C46, C56
100n/50V
+Vs 바이패스
C46 → U9 6번, C56 → U10 6번 핀 옆
R14, R15, C30
100k / 10k / 100n

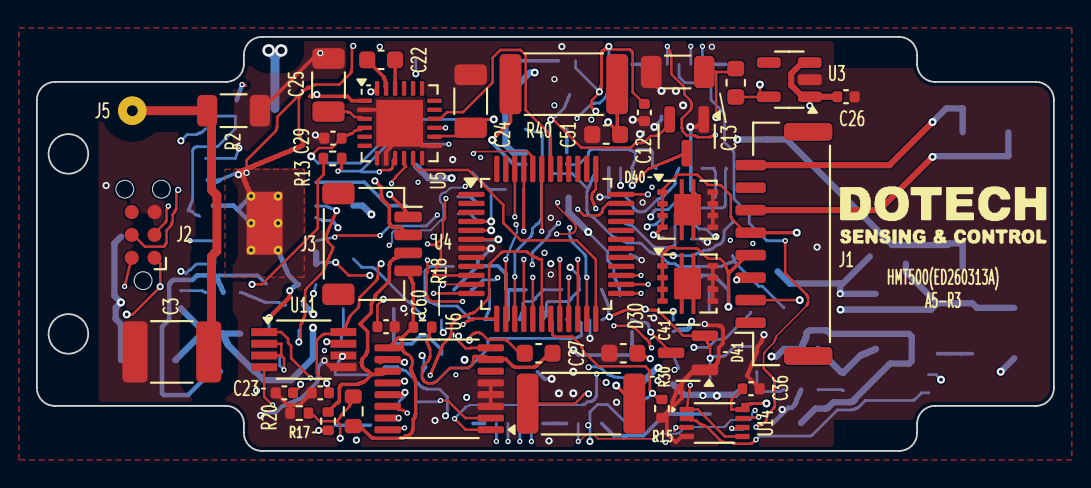
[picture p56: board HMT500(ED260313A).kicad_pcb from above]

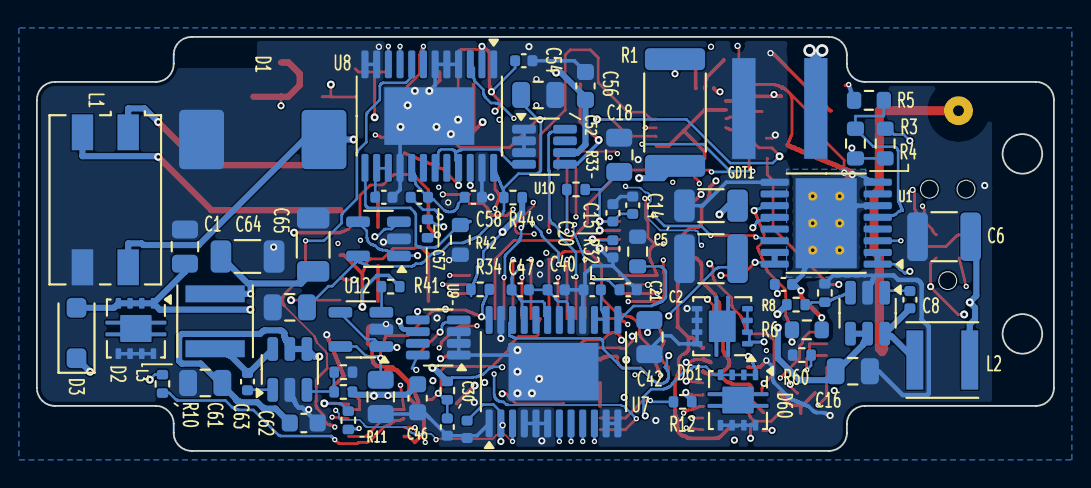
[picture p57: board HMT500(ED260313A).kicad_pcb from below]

Board: 6 copper layers, 56.5 x 23.0 mm, 110 parts (71 on the bottom side), 81 nets.

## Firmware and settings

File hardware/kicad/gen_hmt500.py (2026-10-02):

"""DOTECH HMT500(260313) KiCad 회로도 생성기 (파일명·프로젝트 번호 HMT500(ED260313A)) v0.3 — 배치·배선된 정식 회로도.

python3 hardware/kicad/gen_hmt500.py  →  hardware/kicad/HMT500(ED260313A)/

- 좌표 단위 u = 2.54 mm(100 mil). 모든 핀·선은 1.27 mm 격자 위.
- 신호는 왼쪽→오른쪽, 전원은 위(전원 심볼), GND는 아래(GND 심볼).
- 시트 사이 신호만 전역 라벨, 전원은 전원 심볼(GND, +3V3, +3V3A, +5V, VIN_P, VDDA, CHASSIS).
- 각 부품의 nets=... 는 설계 의도(정답)이며, 그린 배선이 이와 같은지 check_netlist.py로 검증한다.
- 그리기 규칙 위반(선 중간에 걸친 핀, 연결 안 된 핀)은 생성 단계에서 오류로 멈춘다.
"""

import csv
import json
import os
import uuid

PROJECT = "HMT500(ED260313A)"      # 회로·PCB·거버 파일명 = 프로젝트 번호
PRODUCT = "HMT500(ED260313A)"       # 제품(프로젝트) 이름
LIB = "HMT500_260313A"           # 심볼 라이브러리 별칭 (lib_id에 괄호를 넣지 않음)
OUT = os.path.join(os.path.dirname(os.path.abspath(__file__)), PROJECT)
NS = uuid.UUID("6f1c0a52-8d7e-4c1a-9a53-4d2f0b7e1a10")
U = 2.54


def uid(*k):
    return str(uuid.uuid5(NS, "/".join(map(str, k))))


def q(s):
    return '"' + str(s).replace("\\", "\\\\").replace('"', '\\"') + '"'


def mm(v):
    return f"{round(v * U, 4):g}"


def fnum(v):
    return f"{round(v, 4):g}"


REF_SZ, VAL_SZ = 1.27, 1.27
HANGUL_FACE = "NanumGothic"          # KiCad 기본(스트로크) 글꼴에는 한글이 없어 한글 글자는 트루타입으로


def has_hangul(t):
    return any("가" <= ch <= "힣" or "ㄱ" <= ch <= "ㆎ" for ch in str(t))


KO_SAFE = {"\u2212": "-", "\u00b5": "u"}      # NanumGothic에 없는 글자 → 대체


def ko_safe(t):
    return "".join(KO_SAFE.get(ch, ch) for ch in t) if has_hangul(t) else t


def text_w(t, size, bold=False):
    w = sum((1.0 if has_hangul(ch) else 1.05) for ch in str(t)) * size / U
    return w * (1.08 if bold else 1.0)


FONT = "(effects (font (size 1.27 1.27)))"
HIDE = "(effects (font (size 1.27 1.27)) hide)"
ST = "(stroke (width 0.254) (type default))"

# ════════════════════════════ 심볼 정의 ════════════════════════════
SYM = {}


def ic(name, left=(), right=(), top=(), bottom=(), w=8, prefix="U", verify=False, desc="", ts=2, toff=0, bs=2, rows=1):
    SYM[name] = dict(kind="ic", left=list(left), right=list(right), top=list(top), bottom=list(bottom),
                     w=w, prefix=prefix, verify=verify, desc=desc, ts=ts, toff=toff, bs=bs, rows=rows)


def two(name, prefix, draw, desc, pnum=("1", "2"), stack=None):
    """2단자 심볼. pnum = (위/왼쪽, 아래/오른쪽) 핀 번호, stack = {핀: [같은 자리에 겹친 핀들]} (다핀 패키지용)."""
    SYM[name] = dict(kind="two", prefix=prefix, draw=draw, desc=desc, pnum=pnum, stack=stack or {})


def pwr(name, style, desc):
    SYM[name] = dict(kind="pwr", prefix="#PWR", style=style, desc=desc)


two("R", "R", "rect", "Resistor")
two("C", "C", "cap", "Capacitor")
two("L", "L", "ind", "Inductor")
two("FB", "FB", "ferrite", "Ferrite bead")
two("TVS_BI", "D", "tvs", "Bidirectional TVS diode")
two("GDT", "GDT", "gdt", "Gas discharge tube")
two("TVS3301", "D", "tvs", "TI TVS3301 33 V bidirectional flat-clamp TVS, SON-8 DRB (IN = 1-4, GND = 5-8, pad floating)",
    pnum=("1", "5"), stack={"1": ["2", "3", "4"], "5": ["6", "7", "8"]})
two("TVS1401", "D", "tvs", "TI TVS1401 14 V bidirectional flat-clamp TVS, SON-8 DRB (IN = 1-4, GND = 5-8, pad floating)",
    pnum=("1", "5"), stack={"1": ["2", "3", "4"], "5": ["6", "7", "8"]})
two("LED", "D", "led", "LED (pin1 = K, pin2 = A)")
two("ZENER", "D", "zener", "Zener diode SOT-23 (pin 3 = K, pin 1 = A, pin 2 NC)", pnum=("3", "1"))
two("SCHOTTKY", "D", "schottky", "Schottky diode SOD-123F/W (pin 1 = K, pin 2 = A)", pnum=("2", "1"))
SYM["PWR_FLAG"] = dict(kind="flag", prefix="#FLG", desc="Power flag")
for n in ("+3V3", "+3V3A", "+5V", "VIN_P", "VDDA", "VAO"):
    pwr(n, "up", f"Power symbol {n}")
pwr("GND", "gnd", "Ground")
pwr("EF_RTN", "rtn", "TPS2660 RTN reference (local, NOT connected to GND)")
pwr("CHASSIS", "chassis", "Chassis / housing (earth via process pipe)")

B, I, O, P, PI, PO, OC, T, NC = ("bidirectional", "input", "output", "passive", "power_in", "power_out",
                                 "open_collector", "tri_state", "no_connect")

ic("CONN_GH8", right=[("8", "V+", P), ("6", "GND", P), ("4", "OUT1", P), ("5", "OUT2", P), ("3", "RS485_A", P),
                      ("2", "RS485_B", P), ("1", "NC", P), ("7", "NC", P)],
   w=6, prefix="J", desc="JST GH 1.25 mm 8-pin side-entry header. Harness W-2 to M12 8P field connector (pin n = M12 pin n)")
ic("CONN_CH", right=[("1", "CHASSIS", P)], w=6, prefix="J",
   desc="Chassis wire solder hole: AWG 28 wire to an M2 ring terminal under a PCB-holder screw (metal body)")
ic("CMC", left=[("1", "", P), ("2", "", P)], right=[("4", "", P), ("3", "", P)], w=4, prefix="L",
   desc="2-line common mode choke")
ic("TPS2660", left=[("1", "IN", PI), ("2", "IN", P), ("7", "~{SHDN}", I), ("3", "UVLO", I), ("4", "NC", NC),
                   ("6", "MODE", I), ("5", "OVP", I)],
   right=[("15", "OUT", PO), ("16", "OUT", P), ("14", "~{FLT}", OC), ("11", "ILIM", P), ("10", "IMON", P),
          ("12", "dVdT", P), ("13", "NC", NC)],
   bottom=[("9", "GND", PI), ("8", "RTN", P), ("17", "RTN", P)], w=12,
   desc="TI TPS26600PWP 60V eFuse, HTSSOP-16 (datasheet SLVSDG2G). RTN = device reference, never tied to GND (reverse-polarity block between RTN and GND); PowerPAD = RTN")
ic("LMR36006", left=[("2", "VIN", PI), ("10", "VIN", P), ("9", "EN", I), ("8", "PG", OC)], top=[("4", "BOOT", P)],
   right=[("12", "SW", PO), ("7", "FB", I), ("5", "VCC", P), ("3", "NC(SW)", P)],
   bottom=[("6", "AGND", PI), ("1", "PGND", PI), ("11", "PGND", P)],
   w=8, rows=6, desc="TI LMR36006 60V 0.6A sync buck, VQFN-HR-12 RNX 2x3 mm (datasheet SNVSB48C). VFB = 1.0 V")
ic("LMR51606", left=[("5", "VIN", PI), ("4", "EN", I)], right=[("1", "CB", P), ("6", "SW", PO), ("3", "FB", I)],
   bottom=[("2", "GND", PI)], w=6, desc="TI LMR51606YFDBVR 4-65 V 0.6 A buck, 1.1 MHz FPWM, SOT-23-6 (SLUSEY1B: 1 CB, 2 GND, 3 FB, 4 EN, 5 VIN, 6 SW)")
ic("BAS70-04", left=[("3", "COM", P)], right=[("2", "K", P), ("1", "A", P)], w=4, prefix="D",
   desc="Dual series Schottky 70 V SOT-23 (1 = A of D1, 2 = K of D2, 3 = common)")
ic("NPN_SOT23", left=[("1", "B", I)], top=[("3", "C", P)], bottom=[("2", "E", P)], w=4, prefix="Q",
   desc="NPN transistor SOT-23 (1 = B, 2 = E, 3 = C)")
ic("TPS7A2033", left=[("1", "IN", PI), ("3", "EN", I)], right=[("5", "OUT", PO), ("4", "NC", NC)],
   bottom=[("2", "GND", PI)], w=6, desc="TI TPS7A2033 3.3V LDO, SOT-23-5")
ic("STM32G0B1CxTx",
   left=[("10", "PF2-NRST", B), ("1", "PC13", B), ("2", "PC14", B), ("3", "PC15", B), ("8", "PF0", B), ("9", "PF1", B),
         ("30", "PC6", B), ("31", "PC7", B), ("38", "PD0", B), ("39", "PD1", B), ("40", "PD2", B), ("41", "PD3", B)],
   right=[(n, nm, B) for n, nm in (("11", "PA0"), ("12", "PA1"), ("13", "PA2"), ("14", "PA3"), ("15", "PA4"),
                                   ("16", "PA5"), ("17", "PA6"), ("18", "PA7"), ("28", "PA8"), ("29", "PA9"),
                                   ("32", "PA10"), ("33", "PA11"), ("34", "PA12"), ("35", "PA13"),
                                   ("36", "PA14-BOOT0"), ("37", "PA15"))] +
         [(n, f"PB{i}", B) for i, n in enumerate(["19", "20", "21", "42", "43", "44", "45", "46", "47", "48", "22",
                                                  "23", "24", "25", "26", "27"])],
   top=[("4", "VBAT", PI), ("6", "VDD", PI), ("5", "VREF+", PI)],
   bottom=[("7", "VSS", PI)], ts=4,
   w=20, toff=1, desc="STM32G0B1CCT3 LQFP48, -40..125C (pinout from KiCad library STM32G0B1C_B-C-E_Tx)")
ic("CONN_SWD", left=[("2", "SWDIO", P), ("4", "SWCLK", P), ("3", "NRST", P), ("6", "SWO", P)],
   top=[("1", "VCC", P)], bottom=[("5", "GND", P)], w=12, prefix="J", desc="Tag-Connect TC2030 SWD")
ic("CONN_SH4", right=[("1", "SENS_1", P), ("2", "SENS_2", P), ("3", "PT+", P), ("4", "PT-", P)], w=6, prefix="J",
   desc="JST SH 1.0 mm 4-pin side-entry (right angle) header. Sensor harness W-1 direct from HTX99R connector (MK sensor + Pt1000 2-wire)")
ic("PCAP04", left=[("24", "PC2", P), ("1", "PC3", P), ("22", "PC0", P), ("20", "PC4", P), ("21", "PC5", P),
                   ("23", "PC1", P), ("19", "PCAUX", P), ("6", "PT0REF", P), ("5", "PT1", P), ("7", "PTOUT", P)],
   right=[("9", "SSN", I), ("16", "SCK", I), ("15", "MOSI", I), ("10", "MISO", T), ("11", "PG5", O),
          ("12", "PG2", B), ("17", "PG3", B), ("18", "PG4", B), ("3", "VDD18", P), ("13", "IIC_EN", I)],
   top=[("4", "VDD33", PI), ("14", "VDD33", PI)], ts=3, bottom=[("2", "GND", PI), ("8", "GND", PI), ("25", "EP", P)],
   w=10, rows=12, desc="ScioSense PCAP04 capacitance-to-digital, QFN24 4x4 (datasheet SC-001050-DS-6). VDD18 >= 4.7 uF, VDD33 >= 10 uF; INTN on PG5")
ic("ADS1220", left=[("10", "AIN1", P), ("11", "AIN0/REFP1", P), ("6", "AIN3/REFN1", P), ("7", "AIN2", P)],
   right=[("1", "SCLK", I), ("2", "~{CS}", I), ("16", "DIN", I), ("15", "DOUT/~{DRDY}", T), ("14", "~{DRDY}", O),
          ("3", "CLK", I)],
   top=[("12", "AVDD", PI), ("13", "DVDD", PI)], ts=4, bs=3,
   bottom=[("9", "REFP0", P), ("8", "REFN0", P), ("5", "AVSS", PI), ("4", "DGND", PI)],
   w=16, desc="TI ADS1220 24-bit ADC, TSSOP-16")
ic("DAC8760", left=[("9", "DIN", I), ("8", "SCLK", I), ("7", "LATCH", I), ("10", "SDO", O), ("3", "~{ALARM}", OC),
                    ("18", "HART-IN", I)],
   right=[("21", "VOUT", P), ("19", "IOUT", P), ("22", "+VSENSE", I), ("14", "REFOUT", O), ("15", "REFIN", I),
          ("20", "BOOST", O), ("17", "CMP", P)],
   top=[("24", "AVDD", PI), ("2", "DVDD", PI)], ts=4,
   bottom=[("1", "AVSS", PI), ("4", "GND", PI), ("11", "GND", PI), ("12", "GND", PI), ("25", "EP", PI),
           ("23", "-VSENSE", I), ("6", "CLR", I), ("5", "CLR-SEL", I), ("16", "DVDD-EN", I), ("13", "ISET-R", P)],
   w=20, rows=10, desc="TI DAC8760 16-bit V/I output DAC, HTSSOP-24 PWP (pinout: datasheet SBAS528D, as VibrationSensor IVS320)")
ic("OPA197", left=[("1", "OUT", O), ("4", "-IN", I)], right=[("3", "+IN", I)], top=[("5", "V+", PI)],
   bottom=[("2", "V-", PI)], w=6,
   desc="TI OPA197 36 V rail-to-rail op amp, SOT-23-5 DBV (1 OUT, 2 V-, 3 +IN, 4 -IN, 5 V+). +VSENSE unity-gain buffer")
ic("TPS26611", left=[("4", "IN", P)], right=[("5", "OUT", P), ("7", "EN", I)],
   top=[("6", "+Vs", PI)], bottom=[("1", "GND", PI), ("3", "-Vs", PI), ("2", "MODE", I), ("8", "SGOOD", O)],
   w=10, rows=4, desc="TI TPS26611 +/-50 V current-loop / analog output protector, SOT-23-8 DDF (datasheet SLVSFE3C). +Vs <= 30 V")
ic("74LVC2G32", left=[("1", "1A", I), ("5", "2A", I), ("2", "1B", I), ("6", "2B", I)], right=[("7", "1Y", O), ("3", "2Y", O)],
   top=[("8", "VCC", PI)], bottom=[("4", "GND", PI)], w=6, desc="Dual 2-input OR gate (SCLK gating per DAC8760 datasheet 8.5.1.5)")
ic("THVD2450", left=[("4", "D", I), ("1", "R", O), ("2", "~{RE}", I), ("3", "DE", I)],
   right=[("6", "A", B), ("7", "B", B)], top=[("8", "VCC", PI)], bottom=[("5", "GND", PI)], w=8,
   desc="TI THVD2450 +/-70V fault-protected RS-485, SOIC-8")


# ── 심볼 기하 (라이브러리 좌표, u 단위, y 위쪽 +) ──
def ic_geom(s):
    n = max(len(s["left"]), len(s["right"]), s.get("rows", 1))
    tr = (n - 1) // 2
    hw = s["w"] / 2
    pins = []
    for i, (num, nm, t) in enumerate(s["left"]):
        pins.append((num, nm, t, -hw - 1, tr - i, 0))
    for i, (num, nm, t) in enumerate(s["right"]):
        pins.append((num, nm, t, hw + 1, tr - i, 180))
    btop, bbot = tr + 1, tr - (n - 1) - 1
    for side, lst, y, ang in (("t", s["top"], btop + 1, 270), ("b", s["bottom"], bbot - 1, 90)):
        k = len(lst)
        for i, (num, nm, t) in enumerate(lst):
            pins.append((num, nm, t, (s.get("ts", 2) if side == "t" else s.get("bs", 2)) * (i - (k - 1) / 2) + (s.get("toff", 0) if side == "t" else 0), y, ang))
    return pins, (-hw, btop, hw, bbot)


def pins_of(name):
    s = SYM[name]
    if s["kind"] == "ic":
        return ic_geom(s)[0]
    if s["kind"] in ("pwr", "flag"):
        return [("1", name if s["kind"] == "pwr" else "pwr", "power_in" if s["kind"] == "pwr" else "power_out", 0, 0,
                 90 if s.get("style") == "up" or s["kind"] == "flag" else 270)]
    a, b = s.get("pnum", ("1", "2"))
    out = [(a, "~", P, 0, 1.5, 270), (b, "~", P, 0, -1.5, 90)]
    for base, extra in s.get("stack", {}).items():
        bx = [o for o in out if o[0] == base][0]
        out += [(n, "~", P, bx[3], bx[4], bx[5]) for n in extra]
    return out


def graphics(name):
    s = SYM[name]
    k = s["kind"]
    if k == "ic":
        x1, y1, x2, y2 = ic_geom(s)[1]
        g = [f"(rectangle (start {mm(x1)} {mm(y1)}) (end {mm(x2)} {mm(y2)}) {ST} (fill (type background)))"]
        if name == "CMC":
            for yy in (0, -1):
                g.append(f"(polyline (pts (xy {mm(x1)} {mm(yy)}) (xy {mm(x2)} {mm(yy)})) {ST} (fill (type none)))")
                g.append(f"(circle (center {mm(x1 + 0.6)} {mm(yy + 0.35)}) (radius 0.25) {ST} (fill (type outline)))")
            g.append(f"(polyline (pts (xy {mm(x1)} {mm(-0.5)}) (xy {mm(x2)} {mm(-0.5)})) (stroke (width 0.508) (type default)) (fill (type none)))")
        return g
    if k == "flag":
        return [f"(polyline (pts (xy 0 0) (xy 0 1.27) (xy -1.016 1.905) (xy 0 2.54) (xy 1.016 1.905) (xy 0 1.27)) {ST} (fill (type none)))"]
    if k == "pwr":
        if s["style"] == "up":
            return [f"(polyline (pts (xy 0 0) (xy 0 1.27)) {ST} (fill (type none)))",
                    f"(polyline (pts (xy -0.762 0.762) (xy 0 1.27) (xy 0.762 0.762)) {ST} (fill (type none)))"]
        if s["style"] in ("gnd", "rtn"):
            return [f"(polyline (pts (xy 0 0) (xy 0 -1.27) (xy 1.27 -1.27) (xy 0 -2.54) (xy -1.27 -1.27) (xy 0 -1.27)) {ST} (fill (type none)))"]
        return [f"(polyline (pts (xy 0 0) (xy 0 -1.27)) {ST} (fill (type none)))",
                f"(polyline (pts (xy -1.905 -1.27) (xy 1.905 -1.27)) {ST} (fill (type none)))",
                f"(polyline (pts (xy -1.905 -1.27) (xy -2.54 -2.54)) {ST} (fill (type none)))",
                f"(polyline (pts (xy 0 -1.27) (xy -0.635 -2.54)) {ST} (fill (type none)))",
                f"(polyline (pts (xy 1.905 -1.27) (xy 1.27 -2.54)) {ST} (fill (type none)))"]
    d = s["draw"]
    if d == "rect":
        return [f"(rectangle (start -1.016 2.54) (end 1.016 -2.54) {ST} (fill (type none)))"]
    if d == "cap":
        return [f"(polyline (pts (xy -2.032 0.508) (xy 2.032 0.508)) (stroke (width 0.3048) (type default)) (fill (type none)))",
                f"(polyline (pts (xy -2.032 -0.508) (xy 2.032 -0.508)) (stroke (width 0.3048) (type default)) (fill (type none)))",
                f"(polyline (pts (xy 0 2.54) (xy 0 0.508)) {ST} (fill (type none)))",
                f"(polyline (pts (xy 0 -2.54) (xy 0 -0.508)) {ST} (fill (type none)))"]
    if d == "ind":
        arcs = []
        for c in (1.905, 0.635, -0.635, -1.905):
            arcs.append(f"(arc (start 0 {fnum(c + 0.635)}) (mid 0.635 {fnum(c)}) (end 0 {fnum(c - 0.635)}) {ST} (fill (type none)))")
        return arcs
    if d == "ferrite":
        return [f"(rectangle (start -1.016 2.032) (end 1.016 -2.032) {ST} (fill (type outline)))",
                f"(polyline (pts (xy 0 2.54) (xy 0 2.032)) {ST} (fill (type none)))",
                f"(polyline (pts (xy 0 -2.54) (xy 0 -2.032)) {ST} (fill (type none)))"]
    if d == "tvs":
        return [f"(polyline (pts (xy -1.27 2.54) (xy 1.27 2.54) (xy 0 0) (xy -1.27 2.54)) {ST} (fill (type none)))",
                f"(polyline (pts (xy -1.27 -2.54) (xy 1.27 -2.54) (xy 0 0) (xy -1.27 -2.54)) {ST} (fill (type none)))",
                f"(polyline (pts (xy -1.778 -0.508) (xy -1.27 0) (xy 1.27 0) (xy 1.778 0.508)) {ST} (fill (type none)))",
                f"(polyline (pts (xy 0 3.81) (xy 0 2.54)) {ST} (fill (type none)))",
                f"(polyline (pts (xy 0 -3.81) (xy 0 -2.54)) {ST} (fill (type none)))"]
    if d == "gdt":
        return [f"(circle (center 0 0) (radius 2.032) {ST} (fill (type none)))",
                f"(polyline (pts (xy -1.016 0.508) (xy 1.016 0.508)) {ST} (fill (type none)))",
                f"(polyline (pts (xy -1.016 -0.508) (xy 1.016 -0.508)) {ST} (fill (type none)))",
                f"(polyline (pts (xy 0 2.032) (xy 0 0.508)) {ST} (fill (type none)))",
                f"(polyline (pts (xy 0 -2.032) (xy 0 -0.508)) {ST} (fill (type none)))"]
    if d == "zener":
        return [f"(polyline (pts (xy -1.27 -1.27) (xy 1.27 -1.27) (xy 0 1.27) (xy -1.27 -1.27)) {ST} (fill (type none)))",
                f"(polyline (pts (xy -1.778 1.778) (xy -1.27 1.27) (xy 1.27 1.27) (xy 1.778 0.762)) {ST} (fill (type none)))",
                f"(polyline (pts (xy 0 2.54) (xy 0 1.27)) {ST} (fill (type none)))",
                f"(polyline (pts (xy 0 -2.54) (xy 0 -1.27)) {ST} (fill (type none)))"]
    if d == "schottky":                  # 위 = A, 아래 = K (가로 배치 시 왼쪽 A → 오른쪽 K)
        return [f"(polyline (pts (xy -1.27 1.27) (xy 1.27 1.27) (xy 0 -1.27) (xy -1.27 1.27)) {ST} (fill (type none)))",
                f"(polyline (pts (xy -1.778 -0.762) (xy -1.778 -1.27) (xy 1.778 -1.27) (xy 1.778 -1.778)) {ST} (fill (type none)))",
                f"(polyline (pts (xy 0 2.54) (xy 0 1.27)) {ST} (fill (type none)))",
                f"(polyline (pts (xy 0 -2.54) (xy 0 -1.27)) {ST} (fill (type none)))"]
    if d == "led":
        return [f"(polyline (pts (xy -1.27 -1.27) (xy 1.27 -1.27) (xy 0 1.27) (xy -1.27 -1.27)) {ST} (fill (type none)))",
                f"(polyline (pts (xy -1.27 1.27) (xy 1.27 1.27)) {ST} (fill (type none)))",
                f"(polyline (pts (xy 1.524 0) (xy 2.54 1.016)) {ST} (fill (type none)))",
                f"(polyline (pts (xy 1.524 -1.016) (xy 2.54 0)) {ST} (fill (type none)))"]
    raise ValueError(d)


def lib_symbol(name, prefixed):
    s = SYM[name]
    k = s["kind"]
    full = f"{LIB}:{name}" if prefixed else name
    power = " (power)" if k in ("pwr", "flag") else ""
    pn = " (pin_numbers hide)" if k != "ic" else ""
    pnames = " (pin_names (offset 0) hide)" if k != "ic" else " (pin_names (offset 0.508))"
    bom = "no" if k in ("pwr", "flag") else "yes"
    o = [f"(symbol {q(full)}{power}{pn}{pnames} (in_bom {bom}) (on_board {bom})"]
    o.append(f'(property "Reference" {q(s["prefix"])} (at 0 0 0) {HIDE if k in ("pwr", "flag") else FONT})')
    o.append(f'(property "Value" {q(name)} (at 0 0 0) {FONT})')
    o.append(f'(property "Footprint" "" (at 0 0 0) {HIDE})')
    o.append(f'(property "Datasheet" "~" (at 0 0 0) {HIDE})')
    o.append(f'(property "ki_description" {q(s.get("desc", ""))} (at 0 0 0) {HIDE})')
    if s.get("verify"):
        o.append(f'(property "VERIFY" "YES - pin numbers are placeholders" (at 0 0 0) {HIDE})')
    o.append(f"(symbol {q(name + '_0_1')} " + " ".join(graphics(name)) + ")")
    ps = []
    for num, nm, t, x, y, ang in pins_of(name):
        ln = 2.54 if k == "ic" else (0 if k in ("pwr", "flag") else 1.27)
        hide = " hide" if k in ("pwr", "flag") else ""
        ps.append(f"(pin {t} line (at {mm(x)} {mm(y)} {ang}) (length {fnum(ln)}){hide} (name {q(nm)} {FONT}) (number {q(num)} {FONT}))")
    o.append(f"(symbol {q(name + '_1_1')} " + " ".join(ps) + ")")
    o.append(")")
    return " ".join(o)


def rot(px, py, r):
    return {0: (px, py), 90: (-py, px), 180: (-px, -py), 270: (py, -px)}[r]


# ════════════════════════════ 시트 편집기 ════════════════════════════
PWR_COUNT = [0]


def two_nets(sym, n1, n2):
    """2단자 부품의 핀→넷 (핀 번호·겹친 핀 포함)."""
    s = SYM[sym]
    a, b = s.get("pnum", ("1", "2"))
    m = {a: n1, b: n2}
    for base, extra in s.get("stack", {}).items():
        m.update({n: m[base] for n in extra})
    return m
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

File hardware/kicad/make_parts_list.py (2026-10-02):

"""HMT500(ED260313A) 구매용 부품리스트 생성 (회로도 BOM + 제조사 품번·단가 가정).

  python3 hardware/kicad/gen_hmt500.py        # 먼저 회로도·HMT500(ED260313A)_BOM.csv 생성
  python3 hardware/kicad/make_parts_list.py   # → HMT500(ED260313A)/HMT500(ED260313A)_parts_list.xlsx, .csv

- 회로도 부품(참조번호·수량·값·풋프린트)은 HMT500(ED260313A)_BOM.csv 에서 그대로 읽는다. 여기서는 품번과 단가만 붙인다.
- 수동소자 품번은 "제안" (동등품 대체 가능). 단가는 1k 기준 추정값이며 견적으로 확정한다.
- 회로도에 없지만 1대분에 필요한 전자 부품(PCB, 센서, 커넥터 등)은 EXTRA 로 덧붙인다.
"""

import csv
import os

HERE = os.path.dirname(os.path.abspath(__file__))
PROJECT = "HMT500(ED260313A)"   # 파일명 = 프로젝트 번호
OUTD = os.path.join(HERE, PROJECT)
FX = 1400  # 원/달러 가정

# (심볼, 값) → (분류, 제조사, 품번, 설명, 단가 USD 하한, 상한, 상태)
# 상태: 확정 / 제안(동등품 가능) / 확인 필요 / TBD
MAP = {
    ("C", "100n 100V"): ("수동", "Murata", "GRM21BR72A104KA35L", "MLCC 100 nF 100 V X7R 0805", 0.02, 0.05, "제안"),
    ("C", "10u 50V"): ("수동", "Samsung", "CL31B106KBHNNNE", "MLCC 10 uF 50 V X7R 1206 (벅 입력 C5, VAO 출력 C64·C65)", 0.10, 0.25, "LCSC"),
    ("C", "4.7n 2kV"): ("보호", "YAGEO", "CC1812KKX7RDBB472", "MLCC 4.7 nF 2 kV X7R 1812 (GND–외함. LCSC에 Y2 1812 없음 — DC 기기라 Y2 불필요)", 0.10, 0.20, "LCSC"),
    ("C", "22n"): ("수동", "Samsung", "CL05B223KO5NNNC", "MLCC 22 nF 16 V X7R 0402 (eFuse dV/dt, RTN 기준 저전압)", 0.002, 0.005, "LCSC"),
    ("C", "2.2u 100V"): ("수동", "Murata", "GRM32ER72A225KA35L", "MLCC 2.2 uF 100 V X7R 1210", 0.15, 0.35, "제안"),
    ("C", "100n"): ("수동", "Samsung", "CL05B104KO5NNNC", "MLCC 100 nF 16 V X7R 0402 (3.3·5 V 디커플링 — 결정 #35 0402로 자리 확보)", 0.002, 0.005, "LCSC"),
    ("C", "100n/50V"): ("출력", "YAGEO", "CC0603KRX7R9BB104", "MLCC 100 nF 50 V X7R 0603 (VS_CLAMP 약 24 V)", 0.004, 0.01, "LCSC"),
    ("C", "1u"): ("수동", "Murata", "GRM155Z71A105KE01D", "MLCC 1 uF 10 V X7R 0402 (5 V 이하 넷: 벅 VCC, LDO 입·출력. LCSC 표기 X7R — 데이터시트 확인)", 0.006, 0.02, "LCSC"),
    ("C", "22u 25V"): ("전원", "Murata", "GRM32ER71E226ME15L", "MLCC 22 uF 25 V X7R 1210 (벅 출력 2개, LMR36006 X7R 요구. LCSC에 1206 X7R 없음 → 1210)", 0.15, 0.40, "LCSC"),
    ("C", "20p C0G"): ("전원", "Samsung", "CL05C200JB5NNNC", "MLCC 20 pF 50 V C0G 0402 (벅 CFF)", 0.002, 0.005, "LCSC"),
    ("C", "10u"): ("수동", "Murata", "GRM31CR71E106KA12L", "MLCC 10 uF 25 V X7R 1206 (v0.9: 0805 X5R → 1206 X7R, DC 바이어스 여유)", 0.05, 0.12, "제안"),
    ("C", "4.7u"): ("수동", "Murata", "GRM21BR71E475KA73L", "MLCC 4.7 uF 25 V X7R 0805 (품번 확인 필요)", 0.03, 0.08, "확인 필요"),
    ("C", "22u 10V"): ("측정", "Murata", "GRM31CR71A226KE15L", "MLCC 22 uF 10 V X7R 1206 (PCAP04 VDD33 ≥ 10 µF 실효, 품번 확인 필요)", 0.08, 0.20, "확인 필요"),
    ("C", "220n 100V"): ("전원", "Samsung", "CL21B224KCFSFNE", "MLCC 220 nF 100 V X7R 0805 (LMR36006 VIN–PGND 핀마다. LCSC에 0603 없음 → 0805)", 0.02, 0.06, "LCSC"),
    ("C", "10n C0G"): ("측정", "Murata", "GRM1885C1H103JA01D", "MLCC 10 nF 50 V C0G 0603 (ADS1220 차동 필터)", 0.01, 0.03, "제안"),
    ("NPN_SOT23", "MMBTA06"): ("출력", "onsemi / Nexperia", "MMBTA06LT1G", "NPN 80 V 0.5 A SOT-23 — TPS26611 +Vs 이미터 폴로워 (1 B, 2 E, 3 C)", 0.02, 0.05, "제안"),
    ("ZENER", "BZX84C24"): ("출력", "onsemi", "BZX84C24LT1G", "제너 24 V (22.8–25.6) SOT-23 — +Vs 이미터 폴로워 기준 (1 A, 2 NC, 3 K). 외부 검수 H04: 27 → 24 V (+Vs 권장 30 V 여유)", 0.01, 0.03, "LCSC"),
    ("LMR51606", "LMR51606YFDBVR"): ("전원", "TI", "LMR51606YFDBVR", "벅 4–65 V 0.6 A 1.1 MHz FPWM SOT-23-6 — U2 5 V (결정 #38), U15 VAO 16.1 V (결정 #37)", 0.60, 1.20, "LCSC"),
    ("L", "10uH"): ("전원", "SXN", "SMNR4020-10UH", "파워 인덕터 10 µH ±20 %, 원문 정격 DC 1.60 A, DCR 0.165 Ω ±30 %, 4 × 4 × 2.2 mm max (전용 랜드; 포화 기준 확인 필요) — 5 V 벅 (부하 약 60 mA)", 0.05, 0.12, "확인 필요"),
    ("R", "118k 1%"): ("전원", "YAGEO", "AC0402FR-07118KL", "저항 118 kΩ 1% 0402 (5 V 벅 FB 상단)", 0.001, 0.003, "LCSC"),
    ("BAS70-04", "BAS70-04"): ("출력", "Nexperia", "BAS70-04,215", "쇼트키 2개 직렬 70 V SOT-23 — DAC 출력 클램프 (1 A, 2 K, 3 공통)", 0.02, 0.05, "LCSC"),
    ("L", "22uH"): ("출력", "SXN", "SMNR4020-22UH", "파워 인덕터 22 µH ±20 %, 원문 정격 DC 1.05 A, DCR 0.350 Ω ±30 %, 4 × 4 × 2.2 mm max (전용 랜드; 포화 기준 확인 필요) — VAO 벅", 0.05, 0.15, "확인 필요"),
    ("C", "2.2u 50V"): ("출력", "YAGEO", "CC0805KKX7R9BB225", "MLCC 2.2 uF 50 V X7R ±10% 0805, 최대 높이 1.45 mm (VAO 벅 입력)", 0.02, 0.15, "LCSC"),
    ("C", "4.7n"): ("출력", "Samsung", "CL05B472KB5NNNC", "MLCC 4.7 nF 50 V X7R 0402 (DAC VOUT–CMP 보상)", 0.002, 0.005, "LCSC"),
    ("C", "100p C0G"): ("출력", "Samsung", "CL05C101JB5NNNC", "MLCC 100 pF 50 V C0G 0402 (DAC CMP–GND)", 0.002, 0.005, "LCSC"),
    ("R", "422k 1%"): ("출력", "YAGEO", "RC0402FR-07422KL", "저항 422 kΩ 1% 0402 (VAO 분압 상단)", 0.001, 0.003, "LCSC"),
    ("R", "22.1k 1%"): ("출력", "UNI-ROYAL", "0402WGF2212TCE", "저항 22.1 kΩ 1% 0402 (VAO 분압 하단)", 0.001, 0.003, "확인 필요"),
    ("SCHOTTKY", "PMEG10010ELR"): ("보호", "Nexperia", "PMEG10010ELR-QX", "쇼트키 100 V 1 A 저누설 SOD-123W (SOD-123F 풋프린트) — eFuse 앞 직렬, 음(−) 서지·역극성 차단 (외부 검수 H01)", 0.05, 0.12, "LCSC"),
    ("C", "330p C0G 2%"): ("측정", "Vishay", "VJ0603A331GXACW1BC", "MLCC 330 pF 50 V C0G ±2% 0603 (결정 #34, PCAP04 기준 C)", 0.01, 0.04, "제안"),
    ("C", "10n"): ("수동", "Murata", "GRM188R71H103KA01D", "MLCC 10 nF 50 V X7R 0603", 0.003, 0.01, "제안"),
    ("C", "1n 100V"): ("보호", "Samsung", "CL10B102KC8NNNC", "MLCC 1 nF 100 V X7R 0603", 0.004, 0.01, "제안"),
    ("C", "100n 50V"): ("수동", "Murata", "GRM21BR71H104KA01L", "MLCC 100 nF 50 V X7R 0805", 0.01, 0.03, "제안"),
    ("C", "4.7u 50V"): ("수동", "Murata", "GRM32ER71H475KA88L", "MLCC 4.7 uF 50 V X7R 1210 (소프트 터미네이션 권장 — 에폭시 응력)", 0.10, 0.25, "제안"),
    ("TVS_BI", "SMDJ36CA"): ("보호", "Littelfuse", "5.0SMDJ36CA", "TVS 5000 W 36 V 양방향 SMC (입력 1단. LCSC — 같은 36 V·SMC, 3 kW → 5 kW)", 0.30, 0.70, "LCSC"),
    ("TVS_BI", "SMBJ33CA"): ("보호", "Littelfuse", "SMBJ33CA", "TVS 600 W 33 V 양방향 SMB (입력 2단)", 0.08, 0.20, "제안"),
    ("TVS3301", "TVS3301DRBR"): ("보호", "TI", "TVS3301DRBR", "평탄 클램프 TVS 33 V 양방향, 40 V @ 27 A, SON-8 3×3 (아날로그 출력, TPS2661 데이터시트 권장)", 0.35, 0.60, "제안"),
    ("TVS1401", "TVS1401DRBR"): ("보호", "TI", "TVS1401DRBR", "평탄 클램프 TVS 14 V 양방향, 최대 23.55 V @ 30 A/125 C, SON-8 3×3 (AO 전용, 지속 ±28/30 V 오결선 보장 제외)", 0.35, 0.60, "제안"),
    ("TVS_BI", "SMAJ40CA (opt.)"): ("보호", "Littelfuse", "SMAJ40CA", "TVS 400 W 40 V 양방향 SMA (RS-485, 옵션)", 0.06, 0.15, "제안"),
    ("LED", "green"): ("표시", "Würth", "150060GS75000", "LED 녹색 0603", 0.03, 0.08, "제안"),
    ("FB", "600R@100MHz"): ("수동", "Murata", "BLM18KG601SN1D", "페라이트 비드 600 Ω@100 MHz 0603", 0.01, 0.03, "제안"),
    ("GDT", "2035-25-SM"): ("보호", "Bourns", "2035-25-SM-RPLF", "2전극 SMD GDT 250 V, Ø5 × 4.4 mm (회로 GND–외함. LCSC — 230 V형은 LCSC에 없음)", 0.40, 1.00, "LCSC"),
    ("CONN_GH8", "SM08B-GHS-TB"): ("커넥터", "JST", "SM08B-GHS-TB", "GH 1.25 mm 8핀 헤더, 옆 삽입(직각) SMD (M12 하네스 W-2, 정격 −25~+85 °C)", 0.35, 0.80, "제안"),
    ("CONN_CH", "CHASSIS wire"): ("커넥터", "-", "PCB 납땜 구멍 (부품 없음)", "샤시 선 AWG 28 PTFE 약 25 mm + M2 링 단자 → 홀더 축 나사. 선·단자는 기구 부품표(JLCMC)", 0.0, 0.0, "확정"),
    ("CONN_SWD", "TC2030-IDC-NL"): ("생산", "Tag-Connect", "(PCB 패드만)", "SWD 기록용 패드 — 부품 실장 없음", 0.0, 0.0, "확정"),
    ("CONN_SH4", "SM04B-SRSS-TB"): ("커넥터", "JST", "SM04B-SRSS-TB", "SH 1.0 mm 4핀 헤더, 옆 삽입(직각) SMD (센서 하네스 W-1, 정격 −25~+85 °C)", 0.30, 0.60, "제안"),
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

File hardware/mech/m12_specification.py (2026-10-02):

"""HMT500 P-204 M12 선정 사양서. 공통 기구 치수로 검토 외형도 작성."""
import argparse,sys,json
from pathlib import Path
from reportlab.pdfgen import canvas
from reportlab.pdfbase import pdfmetrics
from reportlab.pdfbase.ttfonts import TTFont
from reportlab.lib.units import mm
from reportlab.lib.colors import HexColor
sys.path.insert(0,str(Path(__file__).resolve().parent))
import hmt500_params as P
ROOT=Path(__file__).resolve().parents[2]
p=argparse.ArgumentParser();p.add_argument('--output',type=Path,default=ROOT/'hardware/mech/out/m12');p.add_argument('--font-dir',type=Path,default=Path.home()/'Library/Fonts');args=p.parse_args();args.output.mkdir(parents=True,exist_ok=True)
for n,f in [('KR','NanumGothic-Regular.ttf'),('KRB','NanumGothic-Bold.ttf')]:pdfmetrics.registerFont(TTFont(n,str(args.font_dir/f)))
out=args.output/'HMT500_M12_외형도포함_선정사양서_RevA.pdf';c=canvas.Canvas(str(out),pagesize=(420*mm,297*mm));c.setTitle('HMT500 M12 외형도 포함 선정 사양서 Rev A')
def t(x,y,s,z=10,b=False,color='#183247'):
 c.setFillColor(HexColor(color));c.setFont('KRB' if b else 'KR',z);c.drawString(x*mm,y*mm,s)
def line(x,y,xx,yy,color='#294557'):
 c.setStrokeColor(HexColor(color));c.setLineWidth(.25*mm);c.line(x*mm,y*mm,xx*mm,yy*mm)
def rect(x,y,w,h,color='#edf3f6'):
 c.setFillColor(HexColor(color));c.setStrokeColor(HexColor('#294557'));c.rect(x*mm,y*mm,w*mm,h*mm,fill=1,stroke=1)
def dim(x1,x2,y,label):
 line(x1,y,x2,y)
 for x in [x1,x2]:line(x-1,y-1,x+1,y+1)
 t((x1+x2)/2-pdfmetrics.stringWidth(label,'KR',9)/mm/2,y+2,label,9)
def page(n,title):
 c.setStrokeColor(HexColor('#294557'));c.rect(10*mm,10*mm,400*mm,277*mm)
 t(18,274,title,19,True);t(18,263,'HMT500-P-204  |  Rev A  |  2026-10-02  |  기구 Rev I / PCB A5-R1',10)
 line(10,26,410,26);t(18,16,'선정·견적 검토용 / 구매품 품번 미확정 / 단위 mm / 축척 없음 (NTS)',9);t(371,16,f'{n} / 2',10)
page(1,'M12 8핀 커넥터 — 외형·장착 조건')
t(18,251,'접속부 M12×1과 장착부 M16×1.5는 서로 다른 나사입니다.',12,True)
# Dimensioned project envelope, x=77 mounting face at drawing X=160.
s=6;face=160;cy=191
X=lambda v:face+(v-77)*s
rect(X(71),cy-8*s,6*s,16*s,'#e5edf1')
rect(X(77),cy-10*s,4*s,20*s,'#d7e6ee')
rect(X(81),cy-6*s,11*s,12*s,'#e5edf1')
# Diagram is positioned below title (top at 251); upper labels go beside it.
for xx in [72,73,74,75,76]:line(X(xx),cy-8*s,X(xx),cy+8*s,'#b1bec7')
for xx in range(82,92):line(X(xx),cy-6*s,X(xx),cy+6*s,'#b1bec7')
c.setDash(2*mm,1*mm);line(85,cy,248,cy);line(face,124,face,254);c.setDash()
t(26,224,'장치 내부',12,True);t(254,224,'장치 외부 / 상대 케이블 접속',12,True)
t(22,210,'장착 수나사: M16×1.5',10,True);line(95,208,X(73),202)
t(257,207,'접속 수나사: M12×1',11,True);line(250,205,X(86),200)
t(257,191,'형식: A-coded / 8핀 / Male',11,True)
t(257,176,'어깨 외경: Ø20 이하',11,True);line(249,176,X(79),cy-50)
t(257,164,'표현된 외형은 현 기구 모델입니다.',9)
t(257,156,'표준이 커넥터 몸체 전체 치수를',9);t(257,150,'정하는 것은 아닙니다.',9)
dim(X(71),X(77),121,'6 이하');dim(X(77),X(81),121,'4*');dim(X(81),X(92),121,'11*')
dim(X(77),X(92),109,'외부 돌출 15*')
t(21,133,'기준면 A: 엔드캡 뒤 끝면 x=77',9);line(104,135,face,145)
t(21,101,'* 4 / 11 / 15는 현재 모델 치수이며 선정품 실측값·표준 치수가 아닙니다.',10,True,'#ad491c')
line(18,94,402,94)
for i,(a,b) in enumerate([('장착 암나사','엔드캡 M16×1.5-6H, 모델 x71–77 (길이 6). 구매품 체결·씰 형상 대조 필요.'),('내부 여유','PCB 뒤끝 x69 → 모델 커넥터 안쪽 끝 x71: 축 방향 2 mm. 납땜 핀·수축튜브 돌출은 별도.'),('공구 공간','어깨 Ø20 조건에서 M3 경사 주입 공구 여유 0.625 mm. 어깨 확대 시 재검사.'),('밀봉·고정','O링/가스켓 형상, 장착 토크, 회전 방지, 체결 유효 길이: 선정품 도면으로 확인 필요.'),('선정 자료','공급사 2D 치수도·STEP·단자 방향도 요청. 안쪽 단자 전체 형상과 외부 돌출 길이를 포함할 것.')]):
 t(20,84-i*11,a,10,True);t(63,84-i*11,b,10)
c.showPage()
page(2,'M12 8핀 커넥터 — 전기·하네스·구매 사양')
t(18,249,'HMT500 핀 배정 (표준 공통 기능 배정이 아닌 본 제품 배정)',12,True)
pins=[('1','예비 / PCB NC'),('2','RS485_B_EXT'),('3','RS485_A_EXT'),('4','OUT1_EXT'),('5','OUT2_EXT'),('6','GND_IN / 전원 −'),('7','예비 / PCB NC'),('8','VIN_EXT / 전원 +')]
pl=json.loads((ROOT/'hardware/kicad/HMT500(ED260313A)/placement.json').read_text());j=next(q for q in pl['parts'] if q['ref']=='J1');nets={p['n']:p['net'] for p in j['pads']}
for k,v in [('2','RS485_B_EXT'),('3','RS485_A_EXT'),('4','OUT1_EXT'),('5','OUT2_EXT'),('6','GND_IN'),('8','VIN_EXT')]:assert nets[k]==v
for i,(num,net) in enumerate(pins):
 y=237-i*10;t(22,y,num,10,True);t(38,y,net,10);t(125,y,'→ J1.'+num,10);line(20,y-3,167,y-3,'#ced9df')
t(181,249,'선정 조건 및 현재 상태',12,True)
rows=[('접속 형식','M12 A-coded, 8핀 수형, 직선, 전면 장착'),('장착 나사','M16×1.5 (PG9·M16×1 등과 혼용 불가)'),('제품 사용 전압','12–28 V DC / 최대 28 V'),('커넥터 정격','30 V DC 이상 적용 여부 확인; 아래 참고품은 30 V'),('허용 전류','선정품·접점별·배선 규격으로 확인 필요'),('방수·온도','제품 요구와 체결 조건 확정 후 검증; 현재 보증 등급 미확정'),('하네스 W-2',f"8심 AWG28 PTFE, 현재 {P.HARNESS2['length']:g}±2 mm, JST GHR-08V-S"),('단자·배선','납땜형 또는 지정 리드선형. 실제 길이·피복·핀별 선색 확인'),('공통 주의','1·7번은 8심에 포함, PCB NC. 샤시는 별도 W-3 연결')]
for i,(a,b) in enumerate(rows):t(181,237-i*9,a,9,True);t(220,237-i*9,b,9)
t(20,142,'핀 배열의 정면/배선면 방향·키 위치는 선정품 제조사 도면을 따릅니다. 본 표를 물리적 핀 위치도로 사용하지 마십시오.',10,True,'#ad491c')
line(18,134,402,134);t(18,124,'제조사 공식 참고품 — 채택품 또는 무수정 호환품으로 승인한 것은 아닙니다.',12,True)
t(20,112,'[1] Phoenix Contact 1436424 · SACC-E-M12MS-8CON-M16/0,5 P',11,True)
t(20,103,'8핀 Male / A-coded / M16×1.5 전면 장착 / 30 V AC·DC / 2 A / 0.25 mm² 리드선 0.5 m.',10)
t(20,94,'현재 W-2의 AWG28·40 mm와 다릅니다. 외형·씰·내부 돌출·JST 압착 적합성을 별도로 확인해야 합니다.',10)
u1='https://www.phoenixcontact.com/en-fr/products/device-connector-front-mounting-sacc-e-m12ms-8con-m16-05-p-1436424'
t(20,85,'제조사 제품 페이지 및 외형도 열기 [1]',9,color='#1665a4');c.linkURL(u1,(20*mm,83*mm,170*mm,90*mm),relative=0)
t(20,72,'[2] binder 76 0831 0011 00008-0200 · M12-A series 763',11,True)
t(20,63,'8핀 Male / M16×1.5 / 30 V / 2 A (UL 1.5 A) / 리드선 AWG24·0.2 m. 현재 W-2와 배선 규격이 다름.',10)
u2='https://www.binder-usa.com/us-en/products/automation-technology/m12-a/76-0831-0011-00008-0200-m12-a-male-panel-mount-connector-8-unshielded-single-wires-ip68-ul-m16x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'
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

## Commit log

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2026-09-26 Add electronics BOM cost estimate (1k qty) with price sources
    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
    [bom.csv]
2026-09-26 BOM csv: fix total
    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
    [bom.csv]
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2026-09-26 Circuit design v0.1 with surge and miswiring protection; update block diagram, pinout, BOM
    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
    [bom.csv]
2026-09-26 Add KiCad schematic v0.1 for HMT500 (generator, symbol lib, 6 sheets, BOM, PDF, netlist check)
    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
    [HMT500.kicad_sch, HMT500_BOM.csv, analog_out.kicad_sch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]
2026-09-26 KiCad schematic v0.2: hand-laid-out, wired, readable sheets with power symbols and functional blocks
    Replaces the label-only v0.1. Drawing rules are validated at generation and
    the drawn netlist is checked against design intent (71 nets, 0 errors).
    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
    [HMT500.kicad_sch, HMT500_BOM.csv, analog_out.kicad_sch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]
2026-09-26 Mechanical design Rev A: parametric CadQuery model, STEP files, A3 manufacturing drawings, renders
    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
    [HMT500-M-101_body.step, HMT500-M-102_cap.step, HMT500-M-103_housing.step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]
2026-09-26 HMT500 mech Rev B: threaded M28x1 + O-ring joints, Ø32 housing
    - Body–housing and housing–endcap joints change from laser welding to
    M28x1 threads with radial O-rings (25x2 FKM, Ø29 H8/f7, 15 % squeeze).
    The feedthrough is now the only welded joint, so the unit can be
    taken apart and repaired.
    - Housing grows from Ø30 to Ø32 so the thread and O-ring seats keep
    enough wall. Overall length is now 144 mm; seal face to endcap end is
    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
    [HMT500-M-101_body.step, HMT500-M-102_cap.step, HMT500-M-103_housing.step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]
2026-09-26 HMT500 mech Rev C: single axial PCB with holder and support ring
    - Replace the two round Ø26 PCBs with one axial 57 x 23 mm 4-layer
    board (E-301). It sits in the plane through the axis: 18 wide inside
    the Ø22 body/endcap counterbores, 23 wide inside the Ø27 housing.
    - New PEEK/PA66-GF30 parts: the PCB holder (M-105) is screwed to the
    body counterbore floor (new 2x M2 taps) and clamps the board front
    edge with 2x M2 cross screws. The rear support ring (M-106) is not
    tied to the end cap, so threading the housing and end cap does not
    rotate the board.
    - Feedthrough pins end inside the holder bore and connect to the
    board's front pads with short wires. The connector sits at the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
    [HMT500-M-101_body.step, HMT500-M-102_cap.step, HMT500-M-103_housing.step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]
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2026-09-26 Switch MCU to STM32G0B1CCT3 (in-house part, 125 C grade)
    DOTECH already uses the STM32G0B1CCT6 in DP2000. Use the -40..125 C
    grade of the same chip so tooling, drivers and production fixtures
    can be shared.
    - Schematic: new LQFP48 symbol with pin numbers from the official
    KiCad STM32G0B1C_B-C-E_Tx symbol. NRST is on PF2. BOOT0 shares
    PA14/SWCLK, so the pull-down is removed and the option bytes select
    flash boot. SWO is gone (Cortex-M0+), so J2 pin 6 is NC. VREF+ is
    fed from the FB2 filter. Faults and alarms move to PB13-15. The
    netlist check passes: 69 nets, 0 errors.
    - Pin table, block design, BOM and cost updated. The bootloader doc
    now covers G0B1 dual-bank page erase, the pr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
    [HMT500-M-101_body.step, HMT500-M-102_cap.step, HMT500-M-103_housing.step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]
2026-09-26 Schematic v0.3, purchase parts list, studio product renders
    - Schematic v0.3: TPS26600PWPR now uses the official KiCad pinout
    (HTSSOP-16: dual IN/OUT, UVLO, OVP, SHDN, MODE, RTN, EP). RTN is
    split onto its own net EF_RTN with a 0R link R22, flagged for
    datasheet confirmation, because tying RTN to GND disables the
    reverse-polarity protection. The ADS1220 pinout matches the official
    symbol. Netlist check passes: 70 nets, 0 errors. Rev bumped and cover
    notes updated.
    - make_parts_list.py: purchase parts list (xlsx + csv) built from the
    KiCad BOM. It adds manufacturer, MPN, 1k price estimates and status,
    plus a per-category summary sheet with an FX input.
    - render_studio.py: stud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
    [HMT500.kicad_sch, HMT500_BOM.csv, HMT500_parts_list.csv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]
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2026-09-26 Record DAC decision: keep DAC8760, list drop-in alternates
    Keep DAC8760 fitted on U7/U8 for now. Once the output spec is fixed,
    fit a pin-compatible alternate from the same family: DAC7760 (12-bit
    V/I), DAC8750 (16-bit current only) or DAC7750 (12-bit current only).
    A "DAC SELECTION" note on the analog output sheet records this, and
    the parts list U7/U8 description mentions the alternates. The title
    block verify note is shortened.
    Add docs/decision-log.md, a dated log of decisions made so far (comms,
    connector, pinout, protection, mech Rev B/C, in-house parts policy,
    MCU, DAC) and open items.
    Claude-Session: https://claude.ai/code/ses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
    [HMT500.kicad_sch, HMT500_parts_list.csv, HMT500_parts_list.xlsx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]
2026-09-29 Add 2D drawing of HTX99R sensor connector from STEP
    Store DOTECH's SolidWorks STEP of the HTX99R sensor probe connector
    under hardware/mech/ref. htx99r_connector_drawing.py projects it with
    hidden-line removal and writes an A3 5:1 drawing (SVG + PDF) with
    front view, section A-A through the pin centres, top (socket) view,
    bottom (PCB pin) view, isometric view, dimensions and notes. The
    dimensions are feature values read from the model; the script checks
    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
    [HTX99R_Sensor_Probe_Sensor_Connector.STEP]
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2026-09-29 Select temperature sensor: IST MiniSens Pt1000 class F0.1
    Compare IST miniature Pt1000 RTDs: MiniSens F0.1 and F0.15, SMD 0805,
    232, the 516 Ag-wire part and BondSens. Pick the MiniSens Pt1000 F0.1.
    At 1.6 x 1.2 mm with 10 mm leads it fits the carrier next to the MK33-W
    mini and follows the humidity sensor temperature quickly. F0.15 of the
    same size is the cost-down option. With the HTX99R 4-pin connector the
    Pt1000 becomes 2-wire. Lead error is about 0.026 C per 0.1 ohm and
    calibration removes it. Note the resulting ADS1220 2-wire change.
    Log the decision (#13) and its open items.
    Claude-Session: https://claude.ai/code/session_01JA2o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
2026-09-29 HMT500 mech Rev D: HTX99R sensor connector + plug-in sensor probe
    Use DOTECH's HTX99R sensor connector (4-pin, STEP in ref/) as the
    sensor interface. A replaceable sensor probe carries the MK33-W mini
    and the Pt1000 MiniSens and plugs into its sockets.
    - The connector sits in a Ø10 H8 body bore, sealed by an 8 x 1.2 FKM
    O-ring in its Ø8.2 groove (25 % squeeze). The Ø11 flange rests on a
    Ø11.2 x 1 step that takes the oil pressure. A Ø10.2 lip in the
    protective cap retains the flange.
    - The connector pins reach a Ø9 x 6 solder/potting cavity and are
    wired to the GTMS feedthrough (Ø8 H7), which stays the pressure
    barrier.
    - The exposed probe and cap grow from Ø12 to Ø16 to fi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
    [HMT500-M-101_body.step, HMT500-M-102_cap.step, HMT500-M-103_housing.step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]
2026-09-29 HMT500 mech Rev E: HTX99R connector threads M10x0.75
    DOTECH confirmed that both Ø10 sections of the HTX99R connector are
    M10x0.75 threads. The lower one screws into the housing, the upper one
    takes the protective cap.
    - Body: the connector screws into an M10x0.75-6H port. The 8x1.2
    O-ring seals on a 1.5 mm Ø10 H8 land between thread and flange, and
    the flange sits in a Ø11.2 x 1 seat. The body tube is Ø14.
    - The protective cap now screws onto the connector's upper thread and
    is back to Ø12 (same as EE364). A Ø10.2 relief clears the thread
    undercut.
    - To avoid twisting the wiring: solder four leads to the connector
    first and screw it in while the lead ends are free. Then pull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
    [HMT500-M-101_body.step, HMT500-M-102_cap.step, HMT500-M-103_housing.step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]
2026-09-29 Rev E renders: section, exterior and studio shots
    Replace the interim images with renders of the Rev E geometry:
    HTX99R connector screwed into the body, Ø12 cap on the connector's
    upper thread, Ø14 body tube, plug-in sensor probe, Ø7 wiring channel
    and the rear-welded feedthrough.
    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
2026-09-29 Sensor harness W-1: JST SH 1.0 mm 4P between feedthrough and PCB J3
    - Schematic v0.4: J3 = BM04B-SRSS-TB (top entry). Pins 1-2 MK33, 3-4 Pt1000
    2-wire with force/sense split at the J3 pads (68 nets, netlist check 0 errors)
    - Parts list: J3 header, SHR-04V-S housing, SSH-003T-P0.2-H contacts, PTFE AWG30 wire
    - Mech: J3 and harness in params/CAD/drawings (item 17, notes 5 and 9), PCAP04
    moved directly behind J3, PCB outline and KiCad board zone updated
    - Test for harness clearance, J3 height and pin mapping
    - Decision log #16; JST SH -25..+85 C rating added to open items
    Claude-Session: https://claude.ai/code/session_01JA2o8uJsqp9Vzs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
    [HMT500-M-101_body.step, HMT500-M-102_cap.step, HMT500-M-103_housing.step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]
2026-09-29 HMT500 mech Rev F: DOTECH oil filter cap, no feedthrough
    - Cap replaced by DOTECH SUS probe oil filter 390000-001100 (from the
    2020-06-08 DWG): SUS304, 12 x 32, M10x1.0 x 8.5, 20 side holes 3 mm, tip 3 mm.
    Exposed probe 48, overall 158. Probe plug 8.5 -> 7.6 to fit the 8 mm bore
    - Feedthrough removed: 7 mm channel runs through to the rear counterbore and
    carries only harness W-1 (HTX99R rear pins -> J3, 60 mm). Rear pins potted (item 5)
    - Drawings, CAD, renders, HTX99R-SC notes, RFQ, docs and tests updated
    - Decision log #17; open items: HTX99R thread pitch (1.0 vs 0.75), HTX99R as
    pressure barrier, SUS304 filter material
    - Filter DWG added to hardware/mech/ref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
    [HMT500-M-101_body.step, HMT500-M-102_cap.step, HMT500-M-103_housing.step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]
2026-09-29 Rev F: 7 mm channel left empty (pass-through, cable only)
    - Potting removed from the connector rear; pin joints get heat-shrink sleeves (item 5)
    - Pressure barrier is the HTX99R connector alone (molded pins + O-ring)
    - CAD, drawings, renders, parts list, RFQ, decision log and tests updated
    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
    [HMT500-M-101_body.step, HMT500-M-102_cap.step, HMT500-M-103_housing.step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]
2026-09-29 M12 field harness W-2 with JST GH 8P, epoxy-molded pass-through
    - Schematic v0.5: J1 = JST GH 1.25 mm 8P side entry (SM08B-GHS-TB), pin n =
    M12 pin n; J5 chassis spring contact replaces the M12 shell pin (68 nets, 0 errors)
    - Mech: J1 at PCB x 52.5-58.5 facing the connector, harness W-2 (PTFE AWG28, 60 mm)
    and plug in CAD/drawings (item 18, note 10); output-zone parts rearranged
    - 7 mm pass-through filled with epoxy over its full length after the cable is in
    (item 5, primary barrier)
    - Parts list, KiCad board zones, RFQ, docs, decision log #18 and tests updated
    Claude-Session: https://claude.ai/code/session_01JA2o8uJsqp9Vzsg4b665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
    [HMT500-M-101_body.step, HMT500-M-102_cap.step, HMT500-M-103_housing.step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]
2026-09-29 J3 sensor header to right-angle JST SH SM04B-SRSS-TB
    - Side entry facing the sensor (-x) at PCB x 22.5-26.5, height 2.95; W-1 plugs
    in straight from the holder hole with no bend
    - PCAP04 / ADS1220 / Cref moved behind J3
    - Schematic footprint, parts list, board zone label, CAD, drawings, renders,
    docs, decision log #19 and tests updated
    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
    [HMT500-M-101_body.step, HMT500-M-102_cap.step, HMT500-M-103_housing.step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]
2026-09-29 Schematic drawing rules: no overlapping text, Korean font, distinct net names
    - Generator places reference/value text automatically, clear of symbol bodies,
    pins, wires, labels, notes and box edges; validation fails on any overlap
    (also note text vs wires/power names and bodies vs box edges)
    - Fix 180-degree parts (LED) whose justification KiCad mirrors
    - Styles: reference bold, value normal, power nets italic, signal nets boxed labels
    - Korean box subtitles and legend in NanumGothic TrueType (stroke font has no Hangul)
    - Nets renamed where they matched part or pin names: LED -> STAT_LED, EF_ILIM/IMON/DVDT
    - J1 GH mounting pads removed from the symbol (PCB only); connector sheet re-space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
    [HMT500.kicad_sch, HMT500_parts_list.xlsx, analog_out.kicad_sch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]
2026-09-29 Full interior potting (single RT-cure epoxy) and turnbuckle rear joint
    - Housing interior incl. endcap cavity potted with the same RT-cure epoxy as the
    7 mm channel (about 25 cm3); endcap gets 2x M3 fill/vent ports, plugged after cure
    - Endcap thread M28x1 left-hand: turning only the housing draws body and endcap
    together, so PCB, M12 and both harnesses never rotate (no W-1/W-2 twist)
    - J3 moved 12.5 mm behind the holder (x 30.5-34.5) for plug access; PCAP04 and
    ADS1220 re-placed
    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
    [HMT500-M-101_body.step, HMT500-M-102_cap.step, HMT500-M-103_housing.step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]
2026-09-29 Schematic v0.6: parts cleanup (91 -> 75) and PCB temperature sensing
    - Removed: fault pull-ups R11-R15 (MCU internal pull-ups), status LED D3/R16
    (not visible after potting), RS-485 R60/R61/D60/D61 (THVD2450 built-in
    protection), VREF+ filter FB2/C19 (MCU ADC only for diagnostics), C11/C2/C6
    (duplicated by adjacent capacitors); VREF+ tied to +3V3 with C20
    - PCB temperature with no added parts: ADS1220 internal sensor at the measurement
    front, STM32G0 internal sensor mid-board; compensation plan in circuit-design 5B
    - 63 nets, netlist check 0 errors; parts list regenerated; decision log #22/#23
    Claude-Session: https://claude.ai/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
    [HMT500.kicad_sch, HMT500_BOM.csv, HMT500_parts_list.csv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]
2026-09-29 Schematic redraw: aligned parts, straight wires, fewer junctions
    - Bends 54 -> 1, junctions 51 -> 31 (remaining are real 3-way nodes: divider taps,
    protection taps, tied pin pairs, power flags)
    - Power pins get their own power symbols instead of rails with T-branches; signals
    between distant parts use labels; two-pin parts sit on the pin row they connect to
    - Symbol pin order rearranged for straight runs (pin numbers unchanged): TPS2660,
    LMR36006 (BOOT on top), PCAP04 (Cref pins 3 rows apart, VDD18 on right), ADS1220
    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
    [HMT500_parts_list.xlsx, analog_out.kicad_sch, connector.kicad_sch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]
2026-09-29 Schematic: key-parts table (role, features, specs) on every sheet
    - Aligned 4-column table per sheet: reference, part, role, features/specs;
    values still to confirm against datasheets marked with *
    - Connector and RS-485 sheets moved to A3 for room
    - New checks: text and boxes stay inside the page and out of the title block;
    every character of Hangul text must exist in NanumGothic (minus sign and micro
    sign substituted)
    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
    [HMT500_parts_list.xlsx, analog_out.kicad_sch, connector.kicad_sch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]
2026-09-29 Schematic v0.7: DAC8760 real pinout, OPA197 +VSENSE buffer, ISET-R, SPI2 daisy chain
    - DAC8760 symbol from datasheet SBAS528D (HTSSOP-24 PWP + EP), same as
    VibrationSensor IVS320; placeholder pins removed, VERIFY flag dropped
    - +VSENSE via OPA197 unity-gain follower (U12/U13) of the terminal voltage;
    R31/R41 10k kept as buffer input protection; C45/C55 V+ bypass
    - External ISET-R 15k 0.1% 25 ppm (R32/R42)
    - DACs on dedicated SPI2 (PB13/14/15) daisy chain with common DAC_LATCH
    (PB10); R33 100k pull-down on DAC_DAISY; ALARM -> PB11/PB3, PWR_FLT -> PB4
    - Output protection unification (TPS26611 vs passive) left on hold
    - Parts list, circuit-design doc, decision log #24 updated; netlist 70/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
    [HMT500.kicad_sch, HMT500_BOM.csv, HMT500_parts_list.csv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]
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2026-09-30 Schematic: fix L1 GND stub drawn through D1; add wire-through-body check
    - L1 pin 4 GND now drops straight down with PWR_FLAG on a short side
    wire; D1/R1/D2/C1 shifted right so nothing crosses a part body
    - Generator check: any wire crossing a part body, or a power/flag
    symbol overlapping a part body, now fails generation
    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
    [HMT500(260313A)_connector.kicad_sch]
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2026-09-30 PCB placement: all 84 parts placed and netted (before routing)
    - place_pcb.py: fixed J3/J1/U4, hand slots for large parts, nearest-free
    search for passives; checks board edge and fillets, holder/ring keepouts,
    harness plug paths on top, height vs bore, courtyard overlap, holes
    - plot_placement.py + placement.png/json (mech coords) for review and the
    assembly simulation
    - Board rules for 4-layer: clearance/track 0.15, via 0.45/0.2, edge 0.3;
    .kicad_pro now merged (schematic sheet list kept)
    - Custom footprints: fix local pad/line coordinates (pads were at 0,0);
    TVS3301 floating pad keeps number 9 (no symbol pin, no net)
    - Placement tests; docs/hw/pcb-placement-260313A.md (J5 reach i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
    [HMT500(260313A).kicad_pcb]
2026-09-30 PCB placement rev 2: relax harness paths, use the freed top area
    - Top harness paths: only plug body + insertion/grip space kept empty;
    under W-1 wires (z 2.2) and W-2 wires parts up to 1.0 mm allowed;
    last 2 mm before the M12 end kept empty (wires drop over the edge)
    - J2 Tag-Connect (flat) moved under the W-1 wires; LDO U3, FB1, C12, C13
    moved to the freed top front area (+3V3A right at the measurement)
    - eFuse U1 under the J3 plug path (its thermal-via top pad needs a
    part-free top); buck loop U2-L2-C10/C6 tightened; U14 next to MCU
    - Bands stored in placement.json; plot and tests read them
    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
    [HMT500(260313A).kicad_pcb]
2026-09-30 Mechanical assembly simulation (step by step, real PCB placement)
    - assembly_sim.py: follows assembly note 5 with CAD solids + placed parts;
    moves plugs, ring, housing, endcap and tools along their paths and
    reports overlap volume / min distance per step (report.json)
    - assembly_sim_plots.py: section/plan views of the issues; 3D cutaways of
    the assembled state (top/bottom)
    - Findings (6 NG, 3 WARN): PCB cross screws not drivable with the holder
    in the body and W-1 plug cannot pass the Ø6 hole once the PCB is in the
    slot; endcap face meets the PCB wide section at x 64 (gap 0); J5 short
    of the housing by 3.6 mm; ring passes rear parts (Ø20 rule); W-2 slack
    ~49 mm. Proposals A-F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
2026-09-30 Apply assembly-simulation fixes A-F; re-simulation NG 0
    - A: holder M-105 window 5.6 x 3.2 above the PCB slot (W-1 plug passes
    with the PCB already fitted); bench sub-assembly for the cross screws
    - B: PCB wide section ends at x 63.4 (0.6 mm to the endcap face)
    - C: placement height rule behind the ring (x >= 59) uses Ø20
    - D: J5 spring contact removed; J5 = solder hole for a chassis wire to an
    M2 ring terminal under the holder top screw (M2x8, cbore Ø5.2 x 2.2);
    C3/R2 moved next to J5 (GDT1 mid-board, route CHASSIS wide)
    - E: W-2 harness 60 -> 40 mm; top area behind J1 kept part-free
    - F: assembly tool T-001 push bar (STEP for 3D printing)
    - CAD reads the real PCB placement; drawing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
    [HMT500(260313A).kicad_pcb, HMT500(260313A)_BOM.csv, HMT500(260313A)_connector.kicad_sch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]
2026-09-30 JLC order package: JLCCNC / JLC3D / JLCMC / LCSC files, JLCPCB CPL + BOM generator
    - make_mech_package.py: STEP + drawing page per CNC part with material,
    finish, threads (LH turnbuckle threads flagged), tolerances, qty;
    STL/STEP for JLC3D (T-001 push bar, optional fit-check holder/ring);
    JLCMC hardware list; LCSC harness parts list
    - make_jlcpcb_files.py: JLC CPL from the KiCad placement (82 parts, both
    sides), JLC BOM and an LCSC mapping table (numbers pending lookup)
    - README with ordering notes
    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
    [HMT500(260313A)_BOM_JLC.csv, HMT500-M-101_body.step, HMT500-M-103_housing.step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]
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2026-09-30 JLCCNC: STEP with mid-tolerance fit diameters for the +/-0.05 online option; SUS304/POM for the prototype lot
    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
    [HMT500-M-101_body_SUS304.step, HMT500-M-103_housing_SUS304.step, HMT500-M-104_endcap_SUS304.step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]
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2026-09-30 Mech Rev G: recess protection cap root 3.5 mm into G1/2 face, drop dia-14 tube
    - Front assembly (connector, cap, probe) shifted 19.5 mm rearward; body now
    starts with the G1/2 thread and has a dia 12.3 x 3.5 cap sleeve so the cap
    cannot be bent sideways and break the HTX99R plastic connector
    - Channel dia 7 x 14.5, W-1 40 mm; overall length 158 -> 138.5, exposed probe 48 -> 28.5
    - Drawings, STEP, renders, assembly sim, JLCCNC package, comparison docs, decision #29
    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
    [HMT500-M-101_body.step, HMT500-M-101_body_SUS304.step, HMT500-M-102_cap.step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]
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2026-09-30 Schematic v0.9 + placement rev 4: apply triple-review A/B items, re-review fixes
    - Power: OVP 32.6 V (R5 36.5k), D2 TVS3301, C2 2.2u 100V, buck input 220n x2,
    U2 pin 3 = SW; TPS26611 +Vs emitter-follower clamp (Q1 MMBTA06, R50, D50 27V)
    - RS-485: THVD2410, DE 10k pull-down (R60) for in-house bootloader
    - MCU: SGOOD on PA0/PA4, CS_CDC PA15, VIN_SENSE PB0, LATCH/CS pull-ups,
    SWD no-connect removed, netlist checker flags no-connect on used pins
    - Analog: OPA197 V+ = DAC AVDD, R31/R41 100k, local caps; X7R throughout
    - New aux sheet; SOT-23 and R1206 footprints; parts list and JLC files
    - Placement: pin-targeted hints, MCU decaps under U4, chassis parts grouped
    in front, J5 keep-out 3.3 mm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
    [HMT500(260313A).kicad_pcb, HMT500(260313A).kicad_sch, HMT500(260313A)_BOM.csv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]
2026-09-30 Schematic v0.9 PDF: root sheet 4x2 layout, rev 0.9 in title blocks
    Seven sheet boxes no longer overlap the notes, notes stay on the page
    (v0.3-v0.8 history moved to one line pointing to the decision log).
    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
    [HMT500(260313A).kicad_sch, HMT500(260313A)_analog_out.kicad_sch, HMT500(260313A)_aux.kicad_sch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]
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2026-09-30 Apply agreed external review items (decision #35)
    - H01: series 100 V Schottky D3 (PMEG10010ELR) between D2 and eFuse IN
    (new net VIN_D) so negative surges no longer stress U1 IN-OUT
    - H02: RS-485 bus TVS D60/D61 (TVS3301); U11 -> THVD2410DGKR (VSSOP-8)
    - H04: +Vs clamp zener 27 V -> 24 V (BZX84C24LT1G)
    - H08: ADS1220 IDAC fixed at 250 uA
    - Room for new parts: C7 removed, 37 low-voltage R/C moved to 0402
    (LCSC basic where available); chassis parts keep CH_GAP between each other
    - Placement 104/104, netlist 78/78, pcbnew DRC: no clearance errors,
    assembly sim 23 OK; parts list / JLC BOM updated
    - docs/hw/external-review-response-260930.md: item responses, output load
    table, current bu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
    [HMT500(260313A).kicad_pcb, HMT500(260313A).kicad_sch, HMT500(260313A)_BOM.csv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]
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2026-10-01 Decision #37: fix the DAC section with the IVS320 AO rev 1.0 scheme
    - AO supply VAO 16.1 V: LMR51606YFDBVR buck (U15) + 22 uH + 2x10 uF,
    feeding DAC AVDD (via 10 ohm), TPS26611 +Vs and OPA197 V+
    - Remove +Vs zener follower (Q1, R50, D50, C53) and C43
    - DAC CMP compensation 4.7 nF VOUT-CMP + 100 pF CMP-GND (SBAS528D 8.3.2)
    - DAC output clamp BAS70-04 (D41/D51) for protector switching transients
    - Output TVS3301 and SGOOD -> MCU ADC kept (+-30 V miswiring requirement)
    - 114/114 parts placed, netlist 82/82, DRC no clearance errors,
    assembly sim 23 OK; parts list, JLC BOM, review docs updated
    Claude-Session: https://claude.ai/code/sess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
    [HMT500(260313A).kicad_pcb, HMT500(260313A).kicad_sch, HMT500(260313A)_BOM.csv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]
2026-10-01 Decision #38: prefer JLCPCB parts - U2 LMR51606, R19 0.1 %, std 2512
    - 5 V buck U2: LMR36006BRNXR -> LMR51606YFDBVR (same IC as VAO buck),
    L2 10 uH, C6 22 uF, R8/R9 118k/22.1k -> 5.07 V; C9, C10, C11, C17 removed
    - R19 -> ERA-3AEB4021V (0.1 %, 25 ppm); R1/R30/R40 -> CRCW2512 standard
    - LCSC numbers for 422k and 118k; 57 of 60 BOM lines have LCSC numbers
    - 110/110 placed, netlist 81/81, DRC no clearance errors, assembly sim OK
    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
    [HMT500(260313A).kicad_pcb, HMT500(260313A).kicad_sch, HMT500(260313A)_BOM.csv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]
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2026-10-01 Add HMT500 A1 routing draft and correct SMNR4020 land patterns
    [HMT500(260313A).kicad_pcb, HMT500(260313A)_BOM.csv, HMT500(260313A)_BOM_JLC.csv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]
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2026-10-02 Match HMT500 BOM to LCSC catalog and correct procurement specifications
    [HMT500(260313A).kicad_pcb, HMT500(260313A)_BOM.csv, HMT500(260313A)_BOM_JLC.csv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]
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
